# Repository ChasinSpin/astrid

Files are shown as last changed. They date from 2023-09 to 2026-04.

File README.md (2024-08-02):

# Astrid (ASTro Imaging Device)

## Introduction

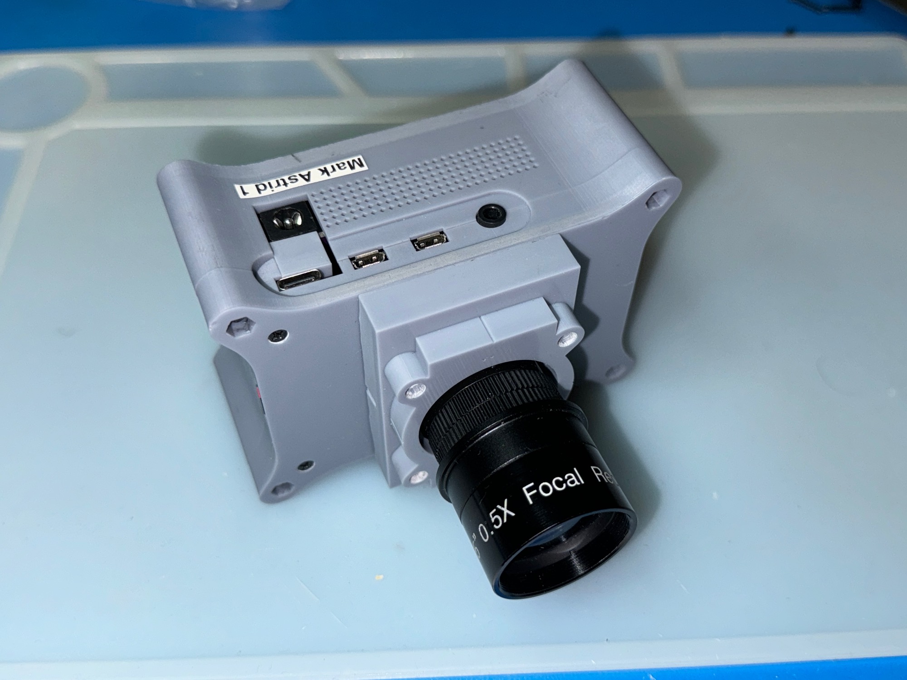
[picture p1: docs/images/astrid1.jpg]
Astrid Front View


Astrid is a device, software and hardware to record astronomical Occultations, Transits, Eclipses (OTE), and Astrophotography.  Occultations are rare, and having equipment for rare events means that the equipment is unused at other times.  The concept of Astrid is that the device can be used as a general astrophotography camera when occultation work is not being done.  

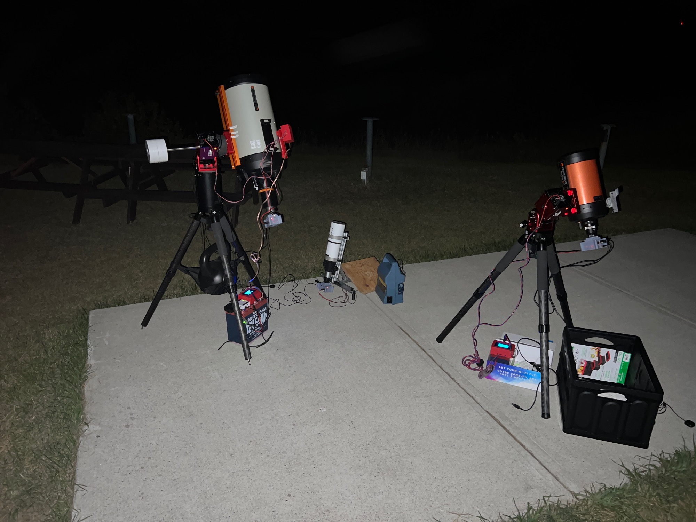
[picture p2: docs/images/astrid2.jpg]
Astrid Front View


Astrid compromises of:

* Raspberry Pi 4 Model B - 8GB (4GB untested)[](https://www.inno-maker.com/product/cam-mipi296raw-trigger/)
* IMX296 Mono Camera [CAM-MIPI296RAW-Trigger](https://www.inno-maker.com/product/cam-mipi296raw-trigger/)
* [OTEStamper](OTEStamper) Timing board
* Software and Firmware

Astrid has the following features:

* Highly accurate frame timestamping for occultations using GPS
* Global Shutter (Sony IMX296 Sensor Mono)
* Controlled over VNC from Tablet/Computer/Phone (one can control many Astrids)
* Can be paired with a telescope or camera lens
* Audit trail for video
* GPS Position/Altitude
* Plate Solving
* Mount support: [IndiLib](https://indilib.org)
* Focuser support: [IndiLib](https://indilib.org) - Coming Soon
* Goto
* Star Detection
* Stretch
* Uncompressed raw data/video
* .fits file (photos)
* [Raw Astro Video Format (RAVF)](https://github.com/ChasinSpin/ravf) files for video (occultations)
* [PyMovie Support](https://github.com/ChasinSpin/pymovie)
* Dithering
* Multiple Subs
* Occelmnt support
* Occultation metrics
* Unattended Pre-Pointing

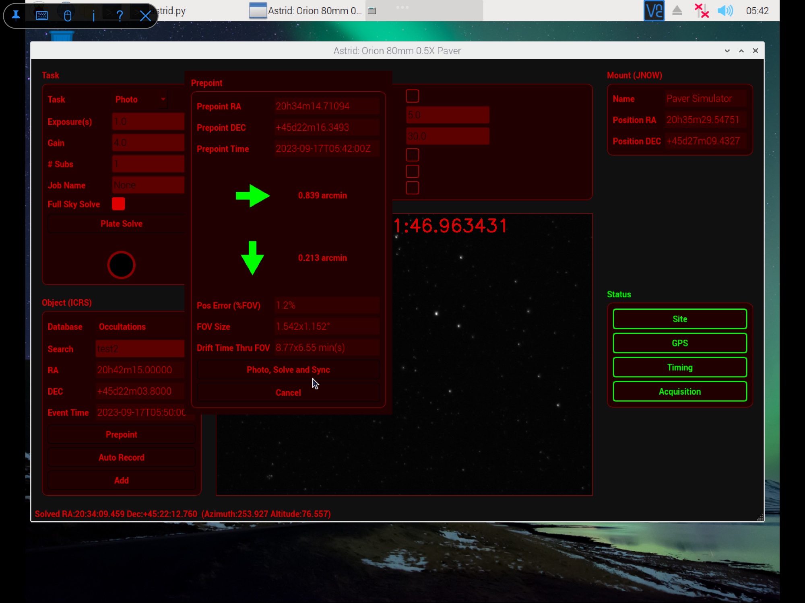
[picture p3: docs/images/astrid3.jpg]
Astrid Front View


## PyMovie

Astrid [Raw Astro Video Format (RAVF)](https://github.com/ChasinSpin/ravf) can be loaded in PyMovie for analysis, using [RAVF PyMovie](https://github.com/ChasinSpin/pymovie).

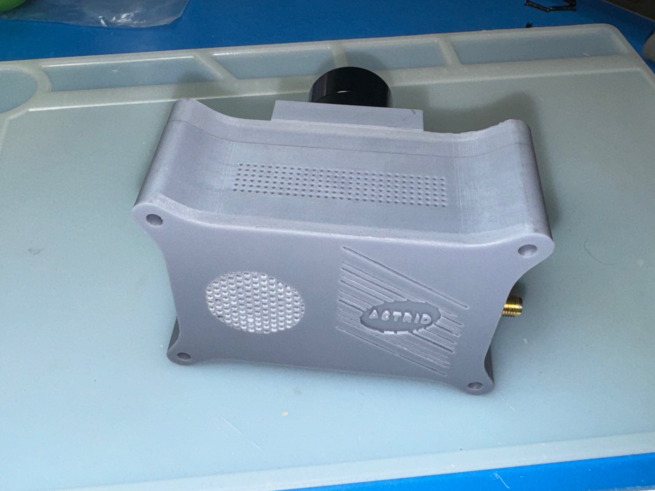
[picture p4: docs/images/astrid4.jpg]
Astrid Front View


## Documentation

[Documentation](docs/README.md)

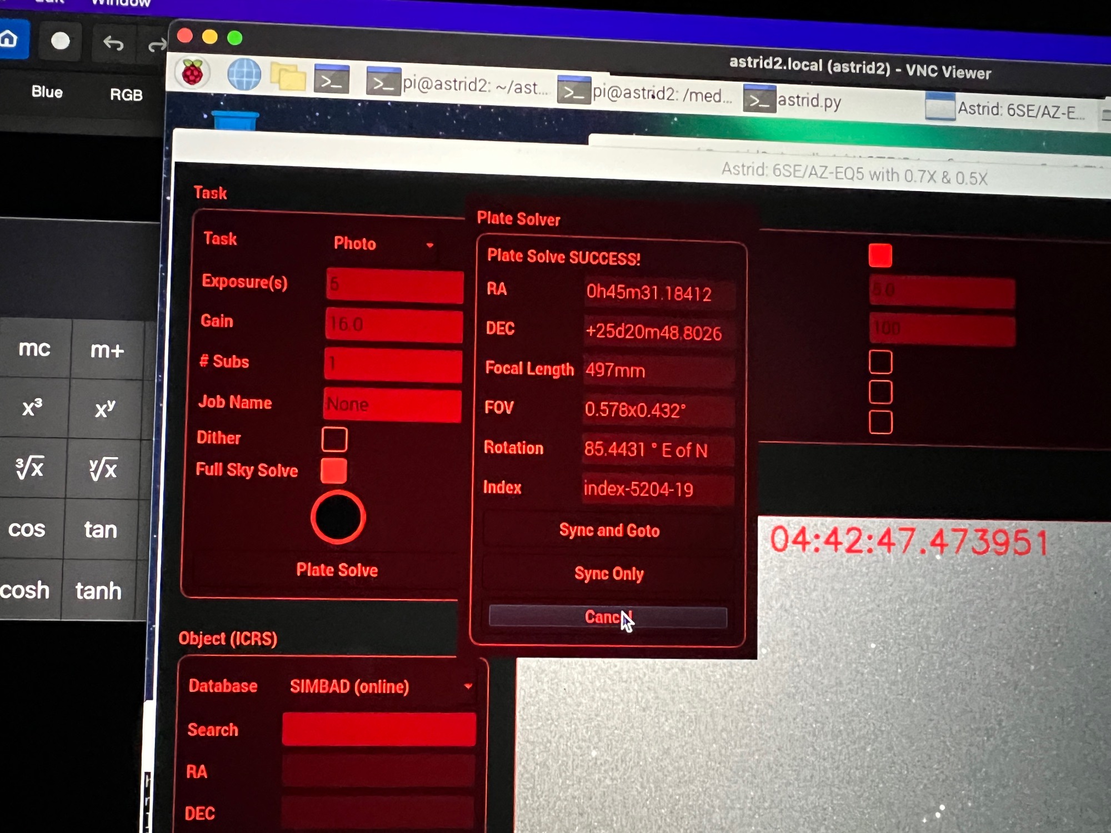
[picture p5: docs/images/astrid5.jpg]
Astrid Front View


## Obtaining Astrid

Astrid is now being supplied fully built and ready to go from IOTA.  Please see:
[https://occultations.org/astrid-details-and-ordering-page/
](https://occultations.org/astrid-details-and-ordering-page/)

Please note that although Open Source software is free, it is also generally considered good practice to support the time / resources that are donated by authors by purchasing through approved channels like IOTA where available.  That way the software/hardware can continue to be developed. Limited support is also available if one of the approved boards is purchased. 

If you build the board yourself, or it was obtained from another, we are unable to provide support. There has been instances of people making boards, selling them to others for profit and then expecting assistance for free.  We do not have the resources to support these types of ventures.

## Credits

* Steve Preston of IOTA for his invaluable assistance
* Bill Yeung for testing
* Bob Anderson for PyMovie
* Dave Herald - Star Catalogs and Occelmnt
* Hristo Pavlov for OWCloud

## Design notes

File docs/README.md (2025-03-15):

# Astrid Documentation

## Video Series

Often, it's easier just to see it being done. There maybe minor differences between the video and the latest version of Astrid however.

Please remember to Thumbs Up and Subscribe.

* [Introduction to Astrid](https://youtu.be/g-tgf88GhiY)
* [Adding Occultations to Astrid](https://www.youtube.com/watch?v=qj_bfFR_L3A)
* [3 Minute Prepoint with Astrid](https://www.youtube.com/watch?v=myGppMeeMI0)
* [Astrid Assembly Guide](https://www.youtube.com/watch?v=mhg2wGE4-7w)
* [Polar Alignment in Astrid](https://www.youtube.com/watch?v=wpIIMchew8s)
* [OTEStamper Pick and Place](https://www.youtube.com/watch?v=rZjZhLjhxiA)
* [Autofill IOTA North American Occultation Report Form](https://www.youtube.com/watch?v=3y9rYOpHG34)
* [Astrid Sync With OWCloud](https://www.youtube.com/watch?v=qNmyeQEwPEQ)
* [Exposure Analysis in Astrid](https://www.youtube.com/watch?v=ftPvObwbZk0)
* [Astrid Player](https://www.youtube.com/watch?v=zWZk-ul2I8g)
* [Events Search](https://www.youtube.com/watch?v=RSV0QjDoSMw)
* [Build SD Card, USB Drive, VNC and First Light](https://www.youtube.com/watch?v=FWFcrbeaBLk)
* [Astrid Customer Camera Sensor Assembly Preparation](https://www.youtube.com/watch?v=KGnb8kZ5_lM&t=92s)

Ted Blank has also created an excellent video demonstrating using Astrid to Prepoint and Record an Occultation:

* [Ted Blank - Using Astrid to Prepoint and Record An Occultation](https://www.youtube.com/watch?v=A8jkwf8NDow)

## Getting Started

1. [Usage Guide](UsageGuide.md)
2. [Power Supply](PowerSupply.md)
3. [Astrid Mini Display](MiniDisplay.md)
4. [Troubleshooting](Troubleshooting.md)
5. [Wi-Fi](Wi-Fi.md)
6. [FAQ](FAQ.md)
7. [USB Drive Requirements](USBDriveRequirements.md)
8. [USB Flash Drive Layout](FlashDriveLayout.md)
9. [Plate Solver](Platesolver.md)
10. [Mounts](Mounts.md)
11. [Focusers](Focusers.md)

## Other
* [Install From Astrid Image](InstallImage.md)
* [Camera Specifications](Camera.md)
* [Raspberry Pi Complete Installation Instructions](InstallComplete.md)
* [Configuration](Configuration.md)
* [OTEStamper Timing Board](OTEStamper.md)
* [Assembly Guide](AssemblyGuide.md)
* [Prime Focus Case](AstridPrimeFocus.md)
* [TODO](TODO.md)

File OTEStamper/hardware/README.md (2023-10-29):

## Version 0.9b
	
* Initial

## Version 0.9c

* No electrical changes.
* Moved label for D1 below diode and clarified orientation for the Buck Regulator to make it less likely to assemble wrong way round.

## Version 1.0.0
	
* Added HOT label around buck convertor and back protection FET
* Removed 4 pin flat flex to camera board
* Moved JP2 right to allow clearance of U2
* Moved buzzer to bottom of the board and rotated 45 to make room for 150uF capacitor
* Added 150uF capacitor to limit surge current to regulator
* Moved Fan header so header pins easily clear GPS
* Added JST 2 Pin Connector For Different 12V Source
* Changed Q1/Q2 to MMBT2222A-TP for increased fan current upto 500mA

## Version 1.0.0 (no board revision)

Extended monostable duration from 1.2us to 1ms to account for
different versions of the camera module with varying XVS pulse lengths, which
can cause multiple pulses for each XVS signal:

 * Changed R18 from 1K to 10K
 * Changes C12 from 1nF to 0.1uF

## Future Ideas

1. Maybe look at switching out back protection FET to one with lower RDS as the voltage drop across is large at high currents (buck can keep up fine).

## PSU Characterisation

1. Voltage range is 7.5 - 18V, specified range to the user is 12V-15V @ 4A

2. Voltage dropout occurs at 7.5V

3. Buck starts to current limit (switch the PSU on and off) at 4.1A

4. Max temperature ofr the bucks convert (4A @ 18V) is 130C

5. Damage to the buck convertor will occur at 20V

6. Fuse never gets triggered during normal use.  Would only get trigger if there was failure on the board itself.

| PSU Output | Supply Input | Temperature |
| --- | --- | --- |
| 0.2A @ 5.04V | 0.062A @ 18V | Room |
| 1A @ 5.02V | 0.304A @ 18V | 42C |
| 2A @ 4.97V | 0.604A @ 18V | 57C |
| 3A @ 4.89V | 0.920A @ 18V | 85C |
| 4A @ 4.79V | 1.243A @ 18V | 125C |

## Testing

1. Power at 12V at current limit 40mA, power usage should be approx 25-30mA, GPS LED should be on
2. Test voltage TP1 = Just above 5V
3. Test voltage TP2 = 5V
4. Test in Software with Raspberry Pi and Camera Connected:

	a) Install firmware
	
		make reset
		make writefuses
		make install

	b) Test Buzzer and Fan:
 	
		cd ~/astrid/OTEStamper/test
		./spitest.py
		
	c) Test GPS (and check voltage monitoring)
	
		./spitest_gps.py
	
	d) Record video and check all status buttons are green and video is recorded

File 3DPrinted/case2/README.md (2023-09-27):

# AstridCase
3D printed case for the Astrid project.

## Filament Color

Black filaments in particular often contain considerable carbon black which can interfere with Radio Frequency (RF) reception/transmission.  This may attenuate or even block Wifi, GPS, or Bluetooth.  Testing is advised when using filaments containing carbon black.

## Requirements

The following modules are required and are provided in this project.  The original projects can be found here:

* polyround.scad from [Round-Anything](https://github.com/Irev-Dev/Round-Anything) (MIT License)
* [Font: JuneGull - 1001freefonts.com](https://www.1001freefonts.com/junegull.font)
* [Font: Poetsen One - 1001freefonts.com](https://www.1001freefonts.com/poetsen-one.font)

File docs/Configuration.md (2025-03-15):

# Configuration

##### Note: It's strongly recommended to use the "Settings" button when Astrid is launched to change settings.  This remains for reference and documentation for the effect of each setting.

## Introduction

Config files are stored in /media/pi/ASTRID/configs and organized as follows:
	
	* /media/pi/ASTRID/configs/observer.json
	* /media/pi/ASTRID/configs/occultations.json
	* /media/pi/ASTRID/configs/objects.json
	* /media/pi/ASTRID/configs/configs.json
	* /media/pi/ASTRID/configs/config1/
		* camera.json
		* focus.json
		* mount.json
		* platesolver.json
		* site.json	[Optional] 
		* ...
	* /media/pi/ASTRID/configs/config2/
		* camera.json
		* mount.json
		* platesolver.json
		* site.json	[Optional] 
		* ...

File formats:

* [configs.json](#configs)
* [astrometry.cfg](#astrometry)
* [camera.json](#camera)
* [general.json](#general)
* [focus.json](#focus)
* [mount.json](#mount)
* [objects.json](#objects)
* [observer.json](#observer)
* [occultations.json](#occultations)
* [platesolver.json](#platesolver)
* [site.json](#site)
* [telescope.json](#telescope)

Note: You may find it easier to validate any JSON with an online validator in case of errors in entry.

## configs

This config.json file is used to present the selection of configs when Astrid is launched.

	{
    	"configs": [
        	{
            	"configFolder": "nexstar_6se_0.7X_eq5",
            	"summary": "6SE/AZ-EQ5 with 0.7X",
            	"mount": "Sky-Watcher AZ-EQ5",
            	"telescope": "Celestron NexStar 6SE",
            	"focalreducers": "Celestron 0.7X"
        	},
        	{
            	"configFolder": "edgehd_0.7X_0.5X_am5",
            	"summary": "EdgeHD/AM5 with 0.7X Celestron and 0.5X IOTA",
            	"mount": "ZWO AM5",
            	"telescope": "Celestron EdgeHD 9.25\"",
            	"focalreducers": "0.7X Celestron and IOTA 0.5X"
        	},
        	{
            	"configFolder": "simulator",
            	"summary": "Simulator",
            	"mount": "Simulator",
            	"telescope": "Simulator",
	            "focalreducers": "None"
        	}
    	],
    	"selectedIndex": 1
    }

| Variable | Description |
| --- | --- |
| configFolder | Sub folder of the configs folder.  This must match exactly the folder name the rest of the settings are stored wihin. |
| summary | Short unique summary describing the scope to the user to enable a config to be selected. |	
| mount |	Longer description of the mount. |
| telescope | 	Longer description of the telescope. |
| focalreducers | Longer description of the focal reducer(s). |
| selectedIndex | Index of the currently selected configuration. 0 based (first config entry is index 0, next is 1 etc.) |

## camera

The camera.json file stores configuration related to the camera:

	{
		"mode_selected": 1,
		"hflip": false,
		"vflip": false,
		"gain": 4.0,
		"accelerated_preview": false,
		"photo_format": "fit",
		"radec_format": "hmsdms",
		"polar_align_test": false,
		"polar_align_rotation": 90.0,
		"default_photo_exposure": 5.0,
		"prompt_dark_after_acquisition2": false,
		"dither_ra": 0.0010,
		"dither_dec": 0.0100,
		"photosFolder": "/media/pi/ASTRID/Photo",
		"videoFolder": "/media/pi/ASTRID/OTEVideo",
		"buzzer_enable": true
	}
	
| Variable | Description |
| --- | --- |
| mode_selected | Cameras have multiple modes with different attributes (size, binning etc.). Suggested modes: IMX296 Mono/Pi GSC: 1, Pi HQ: 3 |
| hflip | Set to true to horizontally flip the image, otherwise false. |
| vflip | Set to true to vertically flip the image, otherwise false. |
| gain | Gain should be optimized to the sensor for read noise as some cameras have dual gain circuits.  Suggested: IMX296 Mono/Pi GSC: 4.0, Pi HQ: 16.0 |
| accelerated_preview | Set to true to use the graphics chip to accelerate the preview image in Astrid, otherwise false. It is suggested to set to false to avoid issues with VNC viewers. |
| photo_format | Unused, must be set to "fit" |
| radec_format | This is the format for the way RA/DEC are presented visually to the user. "hmsdms" = Hours Minutes Seconds(RA) and Degrees Minutes Seconds (DEC). "hour" = 24 Hour RA and "deg" = 360 degree RA |
| polar\_align\_test | If set to "true", test files for the Polar Alignment routine are used from so that it can be tested during daylight hours. Ordinarily set to false unless testing.|
| polar\_align\_rotation | The number of degrees to rotate the scope during polar alignment.  This should be no more than 90.0 degrees and should not be less than 60.0 degrees. 90.0 degrees is the suggested value for accurate polar alignment. |
| default\_photo\_exposure | This is the default exposure in seconds provided in the exposure box in Astrid.  It suggested that this should be set to the exposure that is needed to get a consistant plate solve, e.g. 1.0 - 5.0 seconds. |
| prompt\_dark\_after\_acquisition2 | If set to true, a message box prompts the use to record 100 frames of dark video after an acquisition |
| dither_ra / dither_dec) | When the box is checked and "# Subs" is greater than 1, this value is used to randomly dither in RA/DEC to prevent walking noise when stacking.  The values are in degrees and represent the maximum the position can be dithered |
| photosFolder | Location to store fits files taken in Task = Photo Mode, set to "/media/pi/ASTRID/Photo" |
| videoFolder | Location to store RAVF files (video files) taken in Task = OTE Video "/media/pi/ASTRID/OTEVideo" |
| buzzer_enable | Buzzer beeps in the prior 6 seconds to auto record if true |

## general

The general.json file stores configuration related general settings:

	{
		"fan_mode": "on",
		"center_marker": "small cross",    
		"voltage_warning": 11.5,
    	"voltage_shutdown": 0.0,
    	"location_in_fits": true,
    	"fuzz_gps": false,
    	"annotation_mag": 14.0
	}
	
| Variable | Description |
| --- | --- |
| fan_mode | on = fan always on; idle = fan on when not recording; off = fan off. If you're experiencing vibration effects with long focal lengths, or you are imaging in extreme cold and want to retain heat, this setting can be used.  Note: Although the Raspberry Pi should reduce speed if it gets too hot, there's a slim possibility of damage.  If you live in a hot climate, or it's inside, you probably want the fan on all the time. It is suggested that if considering switching the fan off, then the Raspberry Pi should have the heat sinks installed. |
| center_marker | When "Center Marker" is checked the displayed marked can be one of: crosshairs; rectangle or "small cross" |
| voltage_warning | Specifies the voltage at which a popup warning is issued for Low Voltage. Set to 0 to disable. The warning (if enabled) only occurs once per session. |
| voltage_shutdown | Specifies the voltage at which a auto shutdown occurs for Low Voltage. Set to 0 to disable. Note: Astrid will still consume 250mA @ 12V and more at lower voltages when it is shutdown as the Raspberry Pi is still on, i.e. it will still drain your battery but not as fast, however it does protect the SD Card and USB Drive from damage due to low voltage. If shutdown is cancelled. The shutdown (if enabled) only occurs once per session, if it cancelled it won't auto shutdown again until the next session. |
| location\_in\_fits | When true, the latitude and longitude from the GPS (current site) are written to the fits file as tags SITELAT and SITELONG. |
| fuzz_gps | When true, a random amount of 5 degrees is added/subtracted from the GPS Latitude/Longitude and 500m from altitude.  This is used primarily for demo purposes to prevent personal information being leaked. On no account should this be enabled when real data for occultations is being acquired. |
| annotation_mag | When annotating magnitudes of stars on photos, and when analyzing for exposure, stars dimmer than this magnitude are excluded. |

## focus

The focus.json file stores configuration related to the electronic focuser:

	{
    	"indi_module": "indi_simulator_focuser",
    	"indi_focuser_device_id": "Focuser Simulator",
   	 	"indi_custom_properties": "ASI EAF.FOCUS_REVERSE_MOTION.INDI_ENABLED=On"
    	"coarse_step": 150,
    	"fine_step": 10,
    	"has_temperature": true,
	    "debug": false,
	}

| Variable | Description |
| --- | --- |
| indi_module | The IndiLib dirver executable needed for the mount. The required executable can be determined with [IndiLib Focusers](https://indilib.org/devices/focusers.html) under "Listing Details" and "Driver Executable". Most focusers have been added to Astrid, and the presence of a driver executable can be found by looking in /usr/bin.  e.g. "indi_asi_focuser". |
| indi\_focuser\_device\_id | This is the device is that shown when indi\_getprop is run.  For example for an indi_getprop output of: "ASI EAF.CONNECTION.CONNECT=Off", then this should be set to "ASI EAF" |
| indi\_custom\_properties | List of custom properties (semicolon separated) that are sent as indi_setprop commands after the driver is started, e.g. ASI EAF.FOCUS\_REVERSE\_MOTION.INDI\_ENABLED=On |
| coarse\_step | The number of steps when up/down are pressed when Coarse Speed is selected |
| fine\_step | The number of steps when up/down are pressed when Fine Speed is selected |
| has\_temperature | Set to true if the focuser has a temperature sensor, otherwise false |
| debug | If set to true, debugging information (commands sent to the mount, and information received from the mount) is output which can be useful when setting up new mounts. Ordinarily, this should be set to false. |

## mount

The mount.json file stores configuration related to the mount:

	{
		"name": "ZWO AM5",
		"indi_module": "indi_lx200am5",
		"indi_telescope_device_id": "ZWO AM5",
		"indi_custom_properties": "",
		"indi_usb_tty": "/dev/ttyACM0",
		"baud": 9600,
		"align_axis": "eq",
		"goto_capable": true,
		"tracking_capable": true,
		"mount_is_j2000": false,
		"set_site": true,
		"set_time": true,
		"local_offset": "0.00",
		"parkmethod": "home",
		"debug": false
	}
	
| Variable | Description |
| --- | --- |
| name | How the mount appears in the Mount Panel in Astrid under "Name".  Choose something short so that the name doesn't wrap in the panel. e.g. "ZWO AM5" |
| indi_module | The IndiLib dirver executable needed for the mount. The required executable can be determined with [IndiLib Telescopes](https://www.indilib.org/devices/telescopes.html) under "Listing Details" and "Driver Executable". Most mounts have been added to Astrid, and the presence of a driver executable can be found by looking in /usr/bin.  e.g. "indi_lx200am5". |
| indi\_telescope\_device\_id | This is the device is that shown when indi\_getprop is run.  For example for an indi_getprop output of: "ZWO AM5.CONNECTION.CONNECT=Off", then this should be set to "ZWO AM5" |
| indi\_custom\_properties | List of custom properties (semicolon separated) that are sent as indi_setprop commands after the driver is started, e.g. Skywatcher Alt-Az.USEJOYSTICK.ENABLE=On |
| indi\_connection\_method | "serial" or "ip address"; configures the connection method to the mount |
| baud | The baud rate the USB (serial port) communicates at.  Common values are 9600 and 115200. |
| ip\_addr | The ip address of the device |
| ip\_port | The port of the device |
| align\_axis | "eq" for Equatorially mounted telescopes and "altaz" for Alt-Azimuth mounted telescopes. |
| goto\_capable | true if the mount is capable of goto in 2 axis, or false if not. |
| tracking\_capable | true if the mount is capable of following a target with the earth's location|
| mount\_is\_j2000 | Set to true if this mount expects j2000 coordinates for syncs and gotos.  Ordinally most mounts are JNOW, and this should be set to false. |
| set\_time | Set to true to automatically set the time from the GPS.  It is not advised to disable this setting |
| set\_site | Set to true to automatically set the site from the GPS. It is not advised to disable this setting |
| local\_offset | This is the timezone offset between UTC and local time (negative numbers are West of Greenwich, London, UK).  It is recommended to set this value to "0.00" for most mounts and is just provided as a convenience if your mount is broken in its implementation and requires the offset to be specified too. The symptom of a broken mount would be if the RA on goto's was off by the number of hours for your local timezone. Ordinarily, Sidereal time is calculated based on your Longitude (Site information), not timezone offset. |
| parkmethod | "park" or "home". The method used to park the scope. Most mounts use the telescope property "TELESCOPE\_PARK" in IndiLib (which can be verified with indi\_getprop) and this setting should be set to "park". An exception would be something like the "ZWO AM5" which uses "GO_HOME" and this should be set to  "home". |
| debug | If set to true, debugging information (commands sent to the mount, and information received from the mount) is output which can be useful when setting up new mounts. Ordinarily, this should be set to false. |

## objects

The objects.json file stores custom objects (targets). These objects can also be used when not connected to the internet. It is strongly suggested that these are not manually entered in this json and are entered via Astrid's Object (ICRS) panel.  All RA/DECs are in 360 degree ICRS/J2000:

	{
    	"custom_objects": [
        	{
            	"name": "Vega",
            	"ra": 279.234734787,
            	"dec": 38.783688956
        	},
        	{
            	"name": "Arcturus",
            	"ra": 213.915300295,
            	"dec": 19.182409162
        	}
    	]
	}
	
| Variable | Description |
| --- | --- |
| name | The name of the object |
| ra | The 360 deg RA of the object|
| dec | The DEC of the object |

## observer

The observer.json file stores information about the observer, this information is used to provide observer information in the RAVF (video files):

	{
		"observer_name": "John Doe",
		"observer_id": "johndoe@example.com",
		"owcloud_login": "johndoe@example.com",
		"owcloud_password": "password",
		"owcloud_sitefilter": "",
		"station_number": 0,
		"create_na_report": true
	}
	
| Variable | Description |
| --- | --- |
| observer\_name | Set to the name of the observer (generally you). |
| observer\_id | Set to the observer id. This could be email address, a number etc. |
| owcloud\_login | Set to the owcloud login, usually email address |
| owcloud\_password | Set to the owcloud password |
| owcloud\_sitefilter | Applies a filter to all site names specified in OWCloud which starts at the beginning of the site name and is case sensitive.  I.E. \"Astrid 5\" will match the site name \"Astrid 5 - ChasinSpin\". Leave empty (no characters at all) if you wish to download all sites you've registered in OWCloud |
| station_number | Station number of the astrid, e.g. hostname: astrid1 would be station number 1.  Note the station number is stored on the USB Flash Drive, so will move around with the USB Flash Drive.  Range 1..10000 |
| create\_na\_report | If true, creates a filled in North American Occultation Report Form after the video has finished recording for occultations |  

## occultations

The occultations.json file stores occultations (targets). These objects can also be used when not connected to the internet. It is strongly suggested that these are not manually entered in this json and are entered via Astrid's Object (ICRS) panel.  All RA/DECs are in 360 degree ICRS/J2000.  Occelmnt data is also stored when provided:

	{
    	"occultations": [
        	{
            	"name": "Petrina",
            	"ra": 334.3794887916667,
            	"dec": 0.6233059000000001,
            	"event_time": "2023-08-16T08:42:24",
            	"occelmnt": {
                	"Occultations": {
                    	"Event": {
                        	"Elements": "JPL#81:2023-07-30@2023-08-16[OWC],3.90,2023,8,16,8.706836,-0.330947,0.439776,-5.300154,-3.988511,-0.000865,-0.001414,0.000001,0.000000",
                        	"Earth": "-120.4068,0.7422,50.50,13.77,False",
                        	"Star": "TYC 559-01642-1,22.29196592,0.6233059,11.73,11.47,11.05,0.0,0,,22.31233020,0.7421805,1.82,1.80,0,0,0",
                        	"Object": "482,Petrina,13.07,45.8,1.8647,0,0,-1.667,-18.81,,2.4,0",
                        	"Orbit": "0,53.9673,2023,8,16,87.9178,179.3705,14.4736,0.09643,2.99829,2.70917,8.97,5.0,0.15",
                        	"Errors": "1.152,0.0107,0.0003,82,0.0052,Known errors,0.85,0,-1,-1",
                        	"ID": "20230816_1642-1,60157.39"
                    	}
                	}
            	}
        	}
    	]
	}

| Variable | Description |
| --- | --- |
| name | Name of the event (this is the name that can be searched for in Astrid's Object (ICRS) panel. |
| ra | 360 degree RA of the target |
| dec | DEC of the target |
| event\_time | Event time.  This can be center time of the event, or the time the event will happen locally. |
| occelmnt | This is the occelmnt data for the event and is best entered via Astrid / Object (ICRS)/ Database: Occultations / Add to populate.  The Occelmnt data input via that method, can be cut and poasted from "OW Cloud", "Steve Prestons Predictions", or any other method that can output occelmnt data. |

## platesolver

The platesolver.json file stores configuration related to platesolving:

	{
		"focal_length": 732.0,
		"search_radius_deg": 5.0,
		"limit_objs": 1000,
		"downsample": 2,
		"source_extractor": true,
		"scale_low_factor": 0.1,
		"scale_high_factor": 1.25,
		"direction_indicator_polar_align": 2,
		"direction_indicator_platesolve": 1
	}
	
| Variable | Description |
| --- | --- |
| focal\_length | The focal length of the telescope with all the focal reducers and optics in millimeters (floating point number).  When first setting up a scope, this can be estimated provided the actual scope focal length falls between scale\_low\_factor x focal\_length and scale\_high\_factor x focal\_length. Once a platesolve has been achieved, the actual focal length will be reported and this value should be updated to match the platesolve focal length for faster solves. Plate solves outside this focal length range will never solve.|
| search\_radius\_deg | The search radius in degrees for plate solves from the position the scope thinks it is currently at, or the RA/DEC stored in a fits file loaded. This setting is only used when "Full Sky Solve" is not checked.  This allows for faster solves when the scope knows it's position.  A suggested value is 5.0 |
| limit\_objs | The --objs number provided to [solve-field](https://manpages.debian.org/testing/astrometry.net/solve-field.1.en.html) and cuts the source list down to at least this many source. Suggested value is 1000. |
| downsample | Images can be downsampled by a factor to speed up platesolving and increase signal to noise. See [Downsample](https://manpages.debian.org/testing/astrometry.net/solve-field.1.en.html). No downsampling: 1, 2X downsampling: 2. Suggested value is 2 |
| source\_extractor | If set to true, it uses Source Extractor rather than image2xy to detect stars. Set to false otherwise. Source Extractor is slower, but seems to perform better. See [Extractor](https://manpages.debian.org/testing/astrometry.net/solve-field.1.en.html).  Suggested value is true. |
| scale\_low\_factor | This value multiplied by the focal length is the lowest focal length to consider when platesolving.  Suggested value is 0.1 |
| scale\_high\_factor | This value multiplied by the focal length is the highest focal length to consider when platesolving.  Suggested value is 1.25 |
| direction\_indicator\_polar\_align | During polar alignment, arrows can be displayed to indicate the direction to adjust the mount. "None", "1 Arrow", "2 Arrows" |
| direction\_indicator\_platesolve | When the "Plate Solve" button is hit, and an Object is selected, arrows can be displayed to indicate the direction to adjust the pointing of the scope to reach the target.  This is particularly useful when using a scope without goto. "None", "1 Arrow", "2 Arrows" |

## site

The site.json file stores information related to the current site. This file is optional, and is updated when the "Site" and "Update Site and Mount" buttons are pressed.  If this JSON file does not exist, Astrid will default it to a 0.0, 0.0 location and the "Site" button will be Red until the user selects "Update Site and Mount".  This file can be safely deleted for privacy when backing up or transferring config files:

	{
    	"name": "Local",
    	"latitude": 58.3489123,
    	"longitude": -82.3829384,
    	"altitude": 1102.1
	}
	
| Variable | Description |
| --- | --- |
| name | The name of the site.  This is for future use and currently should be set to "Local". |
| latitude | Latitude of the site. |
| longitude | Longitude of the site. (negative numbers are west of Greenwich, London, UK).|
| altitude | Altitude of the site in meters (floating point number). |

## telescope

The telescope.json file stores information related to the telescope and is used to provide information for the North American Occultation Report Form:

	{
    	"aperture": 0,
    	"optical_type": "Refractor"
	}
	
| Variable | Description |
| --- | --- |
| aperture | The aperture of the telescope in millimeters. Range 0..10000 |
| optical_type | The optical type of the telescope. "SCT including Cass and Mak", "Newtonian", "Refractor" or "Dobsonian" |

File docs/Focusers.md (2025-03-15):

# Focusers (Electronic)

* [Introduction](#introduction)
* [Focusers and Connections Supported](#focusers-and-connections-supported)
* [Support](#support)
* [Focuser Settings](#focsuer-settings)
* [Focuser Testing And Verification](#focuser-testing-and-verification)

## Introduction

Connecting your Focuser to Astrid may take some effort, especially if no one has set up the same or similar focuser before. Many different focuser manufacturers and focuser models exist, and they lack consistency in operation, features, and requirements between them.

Astrid also does not require a Focuser and works perfectly fine with a manual Focuser. Astrid defaults to a simulated focuser unless you change it.

## Focuser and Connections Supported

Astrid includes [IndiLib](indilib.org) for focuser support, and any focuser that is supported by [IndiLib](indilib.org) will also likely work with Astrid when configured correctly. The focsuer must support a USB connection to work with Astrid.  Wifi/Bluetooth connections to focusers are not supported with Astrid.

Check the list below and use it as a starting point for focuser configuration.  The list contains focusers that have been tested by others and are known to work.  

**If you've got your focuser working and it's not listed below, please send the settings/configuration that you found to work so it can be added to the list and others can benefit.**

You should make sure that your focuser firmware is updated to the latest version.  Before configuring any new focuser, it is advisable to ascertain the exact make and model of the focuser and find out specific information about cables or configuration details you may need from [IndiLib - Telescopes](https://indilib.org/devices/focusers.html). Clicking on on the image for the mount will take you to a page with further details.  Information you will need, for example, are the Driver Executable, Connectivity, and Issues.

The focuser functionality can be tested during daylight.

## Support

Limited support is available over Zoom if you have purchased an Astrid through approved channels, such as IOTA (North America), IOTA/ES, or directly from the Author.

Any requests for support need to have the exact make, model of the focuser and a link to the operation manual.

Prior to requesting support, please ensure:

1. You have checked the list below for your focuser, the documentation here, and tried setting it up
2. On your desktop computer you have:
	
	* Zoom Installed
	* RealVNC installed and talking to Astrid
	* Mount connected to Astrid with the correct cable and powered on
3. It's then possible to setup a zoom session with screen sharing to assist you.

## Focuser Settings

Settings for focusers can be accessed via Astrid's settings "Focus" panel.  

| Focuser/Model | Tested | Indi Module | Indi Telescope Id | Indi Custom Properties | Cable | Notes |
| --- | --- | --- | --- | --- | ----- | ----- |
| Simulated Focuser | Yes | indi\_simulator\_focuser | <code>Focuser Simulator</code> | | <code>This is a simulated focuser and the default.</code> |
| ZWO EAF | Yes | indi\_asi\_focuser | <code>ASI EAF</code> | <code>ASI EAF.FOCUS\_REVERSE\_MOTION.INDI\_DISABLED=On or ASI EAF.FOCUS\_REVERSE\_MOTION.INDI\_ENABLED=On</code>

*Author only: OPTION-SPACE for non-breaking space above*

### Reversing The Direction Of the Focuser

Try adding the following in "Indi Custom Properties":

> ASI EAF.FOCUS\_REVERSE\_MOTION.INDI\_DISABLED=On

OR

> ASI EAF.FOCUS\_REVERSE\_MOTION.INDI\_DISABLED=Off

Where ASI EAF is the Indi Focuser Device Id.

## Focuser Testing and Verification

Focusers that haven't been encountered before with Astrid (i.e., there are no settings listed above) need to be verified to work on Astrid.  This process details how to do that:

* Indi Module must be set to the correct module.  A list of modules can be determined from the command line by <code>ls /usr/bin/indi*</code>  Also use [IndiLib - Telescopes](https://indilib.org/devices/focusers.html) to determine the correct module for your focuser.  Save settings, quit astrid and restart Astrid
* Type <code>indi\_getprop</code> in the command line to determine the value for <code>DRIVER\_INFO.DRIVER_NAME</code> and enter that into "Indi Focuser Device Id" and restart Astrid. Note if you see "connect: Connection refused", then you didn't start Astrid and didn't click on "Start Astrid"
* If you have connection issues, use indi\_getprop to check that CONNECTION.CONNECT is On and indi\_setprop to set it, you may need to change some of the settings to get a connection.
* Does Set Position work?
* Does Set Current Position Work?
* Do the Up/Down arrows work
* Does Stop Movement Work

**If you've got your focuser working and it's not listed below, please send the settings/configuration that you found to work so it can be added to the list and others can benefit.**

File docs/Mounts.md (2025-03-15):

# Mounts

* [Introduction](#introduction)
* [Mounts and Connections Supported](#mounts-and-connections-supported)
* [Support](#support)
* [Mount Settings](#mount-settings)
* [Mount Testing And Verification](#mount-testing-and-verification)

## Introduction

Connecting your Goto Mount to Astrid may take some effort, especially if no one has set up the same or similar mount before. Many different mount manufacturers and mount models exist, and they lack consistency in operation, features, and requirements between them.

Astrid also does not require a Goto Mount and works perfectly fine with a manual mount that does not have Goto, or even with a Goto Mount where you have other means to move the mount (e.g. handset, manual slewing).  If you have a mount that isn't listed below or are just starting with Astrid, it may be best to get familiar with Astrid slewing your mount manually prior to setting up Goto.

Manual mounts in Astrid use a simulated mount to maintain the internal pointing model for Astrid.  Astrid installed example simulated mounts when it was built and a few other common mounts.

## Mounts and Connections Supported

Astrid includes [IndiLib](indilib.org) for mount support, and any mount that is supported by [IndiLib](indilib.org) will also likely work with Astrid when configured correctly. The mount must support a Serial connection over USB to work with Astrid.  Wifi/Bluetooth connections to mounts are not supported with Astrid due to the Wifi already being used for Astrid's Hotspot and connection to your Home network and then the general unreliability of connections to mounts over Wifi and Bluetooth.

Often, there are multiple methods for connecting to a mount from USB to serial, and which is the best depends on your mount.  Generally, a direct serial connection is simpler and often doesn't require star alignment on a handset prior to use (as Astrid can tell the mount where it is in the sky).  A mount that has a handset (e.g. Synscan) often has the ability for a direct-to-mount connection (Synscan removed), and also a connection via a handset (pass-thru) and also a connection via a handset (synscan protocol).

Often, you may need to purchase a cable for the serial connection. Information on which cable you need can often be found from the manufacturer (maybe in your mount manual), [Cloudy Nights](https://www.cloudynights.com) or the [IndiLib Forum](https://indilib.org/forum.html) typically.

Check the list below and use it as a starting point for mount configuration.  The list contains mounts that have been tested by others and are known to work.  

**If you've got your mount working and it's not listed below, please send the settings/configuration that you found to work so it can be added to the list and others can benefit.**

If you have a common commercial mount, it's more likely to be supported than a unique or rare large observatory mount or a boutique expensive mount that few others have.  However, occasionally, you can be lucky and have unique mounts that support, say, the LX200 protocol or EQMOD/EQDIR and are likely to work.

Most commercial mounts work in JNOW coordinates, and Astrid should be configured as such. Occasionally, though, a mount may be J2000.

Alt-Az mounts, in particular, contain an internal pointing model that must be set up on mount startup. Often, handsets have a 1, 2, or 3-star alignment process to do this and require the time, date, and location to be entered before they will talk over serial. If you can connect directly to the mount without the handset, you can often skip this lengthy process, and Astrid will set up the mount alignment for you.

You should make sure that your mount (and handset's) firmware is updated to the latest version.  Before configuring any new mount, it is advisable to ascertain the exact make and model of the mount and find out specific information about cables or configuration details you may need from [IndiLib - Telescopes](https://indilib.org/devices/mounts.html). Clicking on on the image for the mount will take you to a page with further details.  Information you will need, for example, are the Driver Executable, Connectivity, and Issues.

Some mounts (and handsets) will look like they are working when they are powered over USB. Always make sure the main power is connected to the mount.

Most mounts should have their Time and Site set and Set Time and Set Site should be checked, however some mounts may not work well in some instances, in which case you can disable and set manually. If you disable this setting, it's critical that you set the site and time manually for your location for Astrid to work correctly.  ONLY DISABLE IF YOU ARE SURE WHAT YOU ARE DOING.

Most of the mount functionality can be tested during daylight if you line up the mount with North and treat alignment stars as they would be in their correct locations for the time of day.  A final test can then be left till a clear night.

## Support

Limited support is available over Zoom if you have purchased an Astrid through approved channels, such as IOTA (North America), IOTA/ES, or directly from the Author.

Any requests for support need to have the exact make, model and configuration (Alt/Az or Eq) of the mount and a link to the operation manual.

Prior to requesting support, please ensure:

1. You have checked the list below for your mount, the documentation here, and tried setting it up
2. On your desktop computer you have:
	
	* Zoom Installed
	* RealVNC installed and talking to Astrid
	* Mount connected to Astrid with the correct cable and powered on
3. 

	It's then possible to setup a zoom session with screen sharing to assist you.

## Mount Settings

Settings for mounts can be accessed via Astrid's settings "Mount" panel.  Display Name can be anything, but please keep it short so it fits on the display.  Local Timezone Offset should always be 0.00.

| Mount/Model | Tested | Indi Module | Indi Telescope Id | Indi Custom Properties | Indi USB tty | Baud Rate | Mount Alignment Type | Goto Capability | Tracking Capability | Mount is J2000 | Parking Method | Cable | Notes |
| --- | --- | --- | --- | --- | --- | --- | --- | --- | --- | --- | --- | ----- | ----- |
Fixed Manual Mounts or Incompatible Goto Mounts (uses Astrid Prepoint) | Yes | indi\_simulator\_telescope | <code>Telescope Simulator</code> | | /dev/ttyUSB0 | 9600 | altaz | unchecked | unchecked | unchecked | park | None | <code>This is a simulated mount and the default for prepoint, manual mounts, scopes without Goto or Goto mounts where communication isn't supported.</code> |
| Celestron Nexstar 6SE/8SE | Yes | indi\_celestron\_aux | <code>Celestron AUX</code> | <code>Celestron AUX.PORT_TYPE.PORT\_HC\_USB=On;Celestron AUX.CORDWRAP.INDI\_ENABLED=On</code> | /dev/ttyUSB0 | 19200 | altaz | checked | checked | unchecked | park | | <code>IMPORTANT: Power to the mount must be on.  The handset will show text even when not powered as it can get power via the USB, but the mount won't connect. LCD will have red backlight when power to the mount is on.  Mount must be powered on horizontal pointing North. Occasionally when started, mount may need "Try Again" on startup. Nexstar tracking is terrible, it's suggested to use the SE6/SE8 for prepoint goto.  Do not do any star alignment prior to (or after) connecting the mount, it's not required as this bypasses the regular mount firmware.</code> |
| EQMod Mounts (Other) | No | indi\_eqmod\_telescope | <code>EQMod Mount</code> | | /dev/ttyUSB0 | 115200 | eq | checked | checked | unchecked | park | USB Cable | <code>Unplug Synscan</code> |
| Losmandy Gemini 2 | Yes | indi\_lx200gemini | <code>Losmady Gemini</code> | | /dev/ttyACM0 | 9600 | eq | checked | checked | unchecked | park | | Regular A/B USB  <code>See Steve Preston</code> |
| LX200 Classic | Yes | indi\_lx200classic | <code>LX200 Classic</code> | | /dev/ttyUSB0 | 9600 | altaz (should work in eq too) | checked | checked | unchecked | park | [Clearline](https://www.clearline-tech.com/repair-parts/lx200/lx200-usb-adapter.html) | <code>Tracking is permanently on with this mount.</code> |
| OnstepX | Yes | indi\_lx200\_OnStep | <code>LX200 OnStep</code> | | /dev/ttyACM0 | 9600 | eq | checked | checked | unchecked | park | USB Cable | <code>MaxPCB4 Tested, should work with others</code> |
| Skywatcher AZ EQ5, Skywatcher AZ EQM-35 Pro| Yes | indi\_eqmod\_telescope | <code>EQMod Mount</code> | | /dev/ttyUSB0 | 115200 | eq | checked | checked | unchecked | park | USB Cable | <code>Unplug Synscan</code> |
| Skywatcher AZ (example: Skywatcher Virtuoso GTI 150p (tested), FlexTube 200P(tested), FlexTube 300P(tested), FlexTube 350p, FlexTube 400P) | Yes | indi\_skywatcherAltAzMount | <code>Skywatcher Alt–Az</code> | Skywatcher Alt-Az.USEJOYSTICK.ENABLE=On | /dev/ttyUSB0 | 9600 | altaz | checked | checked | unchecked | park | <code>[RJ12 Control Cable for Skywatcher Az-GTI and AZ-GTE](https://www.amazon.com/gp/product/B08DG7KKNV) / [Sky-Watcher/SynScan USB Adapter for Computer Telescope Control](https://www.amazon.com/Sky-Watcher-S30107-SynScan-USB-Adapter/dp/B09PQR5BHY) - see next column</code> | <code>Power mount on with tube horizontal and pointing north (the park position).  Use EqMod Cable. The EqMod cable must be plugged into the same place the handset plugs into (i.e. instead of the handset) on the mount.  On startup, Astrid will likely say "Failed to connect to mount", just click "Try Again" (this is due to a bug Skywatcher have in their firmware where it won't connect on the first try). These mounts are notoriously inaccurate with the smaller mounts being worse than the larger one, it's recommended to turn the "Tracking" checkbox off in the Mount settings in Astrid, you can still use Goto and Prepoint, but tracking won't be enabled when auto recording starts, preventing the mount from hunting for the first 30 seconds of the recording, or being pushed out of frame.  You may still need to manually enable Tracking (Tracking button in Astrid), to get a plate solve.  Ted says that the RJ12 connection suggested didn't work for him (points to wrong location and doesn't stop slewing) and to use Sky-Watcher SynScan USB Adadpter instead, however Bill and Mark find the Washington RJ12 to work fine, if you have problems, with one, try the other.</code> |
| Vixen Starbook Ten | Yes | indi\_starbook\_ten | <code>Starbook Ten</code> | | /dev/null | 9600 | eq | checked | checked | unchecked | park | ethernet | <code>Connect to ethernet port on Pi. Point Dec West at startup (home position), accept warning about sun, then connect Astrid. Note Park on Starbook Ten often means RA is rotated, it is okay to start a polar alignment from this position.</code> |
| ZWO AM5 (likely AM3/AM5N too) | Yes | indi\_lx200am5 | <code>ZWO AM5</code> | | /dev/tty/ACM0 | 9600 | eq | checked | checked | unchecked | home | Regular A/B USB | |

*Author only: OPTION-SPACE for non-breaking space above*

### Mount SLEW Joystick Not Working In Astrid

Try adding the following in "Indi Custom Properties":

> Skywatcher Alt-Az.USEJOYSTICK.ENABLE=On

## Mount Testing and Verification

Mounts that haven't been encountered before with Astrid (i.e., there are no settings listed above) need to be verified to work on Astrid.  This process details how to do that:

* Indi Module must be set to the correct module.  A list of modules can be determined from the command line by <code>ls /usr/bin/indi*</code>  Also use [IndiLib - Telescopes](https://indilib.org/devices/mounts.html) to determine the correct module for your mount.  Save settings, quit astrid and restart Astrid
* Type <code>indi\_getprop</code> in the command line to determine the value for <code>DRIVER\_INFO.DRIVER_NAME</code> and enter that into "Indi Telescope Id" and restart Astrid. Note if you see "connect: Connection refused", then you didn't start Astrid and didn't click on "Start Astrid"
* If you have connection issues, use indi\_getprop to check that CONNECTION.CONNECT is On and indi\_setprop to set it, you may need to change some of the settings to get a connection.
* Check UTC is set correctly on the mount (using indi\_getprop) to the time you started Astrid (note it generally doesn't update whilst it's running)
* Check Latitude and Longitude for the site are correct (using indi\_getprop) after Update Site has been clicked in Astrid
* Does Goto work?
* Does Home/Park work?
* Does Tracking stop and start when the Tracking button is toggled?
* Does Tracking come back on automatically after a Goto?
* Does the mount update it's position correctly after a Sync is done after a plate solve?
* Does the STOP button (in the mount panel), stop the mount motion during Park/Homing and a Goto?
* Does the Tracking Rate (sidereal, lunar etc.) remain after Gotos?
* Do the Slew Joystick buttons and slew rate work?
* Does Meridian Flip work? (find star close to meridian (South), goto, wait for Meridian timing to drop to -1m, goto again and check mount flips.
* Does the Polar Align routine work (test this at night and german equatorial mounts only).

**If you've got your mount working and it's not listed below, please send the settings/configuration that you found to work so it can be added to the list and others can benefit.**

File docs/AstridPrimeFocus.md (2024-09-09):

# Astrid - Prime Focus

## Introduction

The Astrid - Prime Focus case is a version of Astrid that separates the camera from the processing unit to reduce the footprint for prime focus setups.  A prime focus setup is where the camera is located at the front of the telescope instead of the rear.  i.e. HyperStar SCTs, Suitcase Mounts (Broughton), Rasa, Prime Focus Newtonians, etc.  It can also be used for smaller Dobsonians, which are typically intolerant of extra wait at the eyepiece.

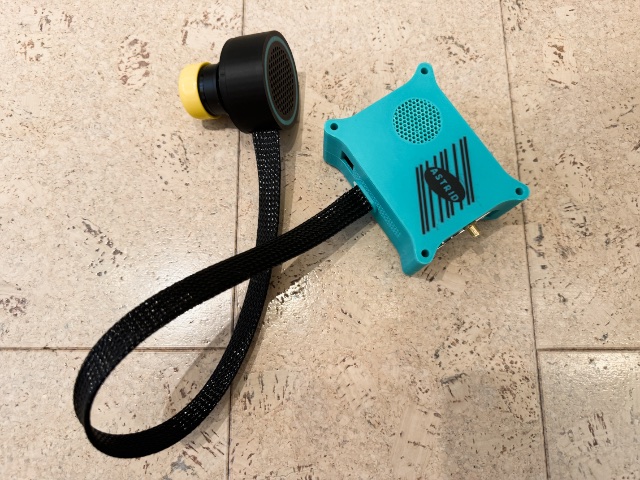
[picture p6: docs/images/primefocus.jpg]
Prime Focus Astrid Case


Astrid—Refractor (the all-in-one unit) is still the recommended solution for SCTs that are not Hyperstars, Newtonians that still have their eyepiece holders and Refractors.

Astrid - Prime Focus Case consists of 2 parts joined by a cable:

* Camera
* Astrid

The cable between these 2 parts is 19 inches +/—1 inch. As the camera will be mounted in the middle, it can accommodate scopes up to 30 inches in diameter.  If you have a larger telescope than this, please contact us for a longer custom cable.

This camera case is 3D printed in black (with a turquoise highlight on the nonvisible side), has no lights, and has the Flat Flex cable and a single thin wire coming out of the vertical slot. If you have a spider vane, the cables can be taped to that, with or without the wire sleeve.

The remainder of Astrid is a separate unit you can place somewhere outside of the mirror capture area e.g. on the side of the scope. Adhesive Velcro is the suggested way to do this.

This approach has a few advantages:

* The obstruction of this camera is only 59mm (the diameter of the case):
	* This is smaller than ZWO’s smallest cameras for example (62mm).
	* For HyperStar, this means that for 8” scopes and up, it’s smaller than the secondary mirror obstruction and, therefore, doesn’t block light, and for 6” (56mm obstruction) scopes, it only overspills by 3mm.
	* For RASA, the central obstruction is 93mm and far larger than the Astrid camera
* Maximizes photons coming in by not creating a big obstruction
* Only 2 thin cables to route (flat flex (1mm x 16mm) and a 1mm single wire), i.e. no large thick power cables
* Heat generation in front of the mirror is limited to the small heat generation of the camera
* No fans to disturb airflow in front of the mirror
* No LEDs to worry about
* These cables can be routed over your existing support structure (for Hyperstar / Rasa it can be anchored at the side using a radius curve)
* This approach won’t create any noticeable diffraction spikes if a radius curve is maintained (if your support structure or other items generate spikes, those will remain the same of course)

If you’re rough with equipment, the cable assembly is considered a consumable, and you can replace it easily.  **DO NOT FOLD THE FLAT FLEX**

## BOM (Bill Of Materials)

*(For IOTA Construction or User Repair Only)*

| Quantity | Part | Description | Manufacturer | Supplier | Supplier Part # |
| --- | ---- | --- | --- | --- | --- |
|1|Raspberry Pi Camera Cable 610mm|Adafruit 15-pin 610mm 1731|Adafruit|DigiKey|1528-1791-ND|
|2|Crimp|0.1" Connector 28awg Crimp Gold|Harwin Inc.|DigiKey|M20-1160042|
|51cm|PET Expandable Sleeving 5/8"|Expandable Sleeving 5/8" X 100' Black PTN0.63BK100|Techflex|DigiKey|1030-PTN0.63BK100-ND|
|70cm|Silicone Wire|28awg Silicone Wire multistranded|Anjukee Store|Amazon|[Amazon Link](https://www.amazon.com/dp/B0D6V75XDW)|
|18mm|Heatshrink Tubing|Heatshrink Tubing 3:1 shrinkage, 3mm internal diameter|Any|Digikey|2786-B2(3X)3/1BLACKSPL-DS-ND (untested, but should fit)|

## Assembly Instructions

*(For IOTA Construction or User Repair Only)*

* Cut 51cm long piece of PET Expandable Sleeving
* Cut 70cm long piece of silicone wire
* Weld ends with clamps, allowing about 1cm overflow of the sleeving at each end
* After construction, clamp to clamp should measure approximately 48cm.
* Insert cables, ensure camera end had 6.5cm of Flat Flex past the clamp and 10cm of the silicone wire.

See [YouTube Video](https://youtu.be/KbivtE_ajuM)

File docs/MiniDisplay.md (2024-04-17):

# Astrid Mini Display

## Introduction

The Astrid Mini Display is a small device with a display that displays Astrid's current network settings.

It connects over USB (USB2 or USB3), and its buttons can be used to switch between Hotspot and WiFi router mode.

In the future, it will be used to provide additional functionality.

Only 1 Astrid Mini Display is required for all your Astrids, it doesn't have to be connected for Astrid to start, and can be removed and plugged into another Astrid whilst both are running.

## Requirements

USB-B to USB-C cable with both power **AND DATA** is required.

Astrid Mini Display can use either:
	
* [Adafruit ESP32-S2 Reverse TFT Feather](https://www.adafruit.com/product/5345)
* [Adafruit ESP32-S3 Reverse TFT Feather](https://www.adafruit.com/product/5691)

## Initial Installation / Upgrading

Plug in the Astrid Mini Display to Astrid, and in "Astrid Tools", double click/tap on "Install Mini Display" and follow the instructions.

## Usage

The Mini Display contains 4 buttons: 3 user buttons and 1 reset button (which resets the Mini Display only).

Currently, to switch between Astrid Hotspot and Regular Wifi modes, you press anyone of the group of 3 buttons.  The press has to be deliberate, a fast tap will be ignored to avoid accidental triggering.

When switching modes, you should press the button and wait; soon, a gray message will be displayed indicating that it is switching; please wait as it switches.  Switching networks is quite involved and takes time; be patient; Astrid will update you as it makes connections to the network. First, it will connect to the Wi-Fi network, and then it will be allocated an IP address. You can connect after you see the IP address allocated, if you try to make a connection with VNC before that, the connection will fail.  If the Wifi is not connected to or an IP address is not allocated then there is a problem with the WiFi router you are using that you should investigate.

If you fail to connect to your WiFi network (for example, wrong password), then you can always press the button again to return to Astrid Hotspot mode to fix it.

## Troubleshooting

Q. Display lights, but you can't install the software

A. Be sure that the USB cable you are using provides both power AND DATA (try another cable)

## Bitmap (Developer only)

* Export to png and open in Photoshop
* Resize to 240x135
* Image / Mode / Indexed Color
	* Palette: Local (Selective)
	* Colors: 256
	* Forced: None
* File / Save As Copy / BMP
	* Windows
	* 8 bit
	* (nothing checked)

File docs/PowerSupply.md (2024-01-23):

# Power Supply

Astrid with the OTEStamper board should be powered via the 12-15 Volt 2.1x5.5mm DC Input Jack on the OTEStamper board, which is common on astronomy equipment. This input jack is "center positive" and has a self-resettable 2A polyfuse.  Power to the input jack is reverse polarity protected. 

Supply voltages outside of this range will likely damage the board and the Raspberry Pi and may corrupt the SD Card.  We recommend against using 12V Cigarette lighter-type connectors, as they often disconnect easily and can lead to SD Card corruption when that happens.

5.1-5.2VDC is generated internally by the OTEStamper board for the Raspberry Pi to run.  Please make sure that any wiring and the connector you use to supply Astrid can handle at least 2A. For reasonable run length, this means 16AWG or thicker for the wire, and likely 14AWG if you're supplying a larger mount too.  18AWG is really the least that should be considered and only for short runs and for only powering Astrid.

# Power Banks / Power Packs

__Power Banks / Power Packs are NOT Batteries__

__IMPORTANT:__ It's strongly suggested to avoid Power Banks or Power Packs for powering Astrid.  Power Banks / Power Packs (e.g. TalentCell) are most often made from cheap batteries with substandard electronics that are incapable of supplying regulated power to Astrid. This also applies to powering Astronomy Equipment in general (Mini PCs, Astro Cameras, Mounts, etc.).

Common problems with Power Banks/Power Packs are:

* Misrepresented Battery Capacity (specified at 3.7V not 12V)
* Power outputs auto switch off with low power drain, removing power from Astrid
* Low and/or varying voltage due to current limiting, poor boost conversion
* Fire risk/explosion risk
* Insufficient size

__Any Power Bank/Power Pack that contains Lithium Ion or Lithium Polymer batteries can also cause fires and can explode.  Lithium fires often can't be put out with water or chemical fire extinguishers.__

Examples:

* [https://www.youtube.com/watch?v=8nz5ijXcckI
](https://www.youtube.com/watch?v=8nz5ijXcckI)
* [https://m.youtube.com/watch?v=jq_0X1lStbo](https://m.youtube.com/watch?v=2hGfCwPwCPQ)
* [https://m.youtube.com/watch?v=2hGfCwPwCPQ](https://m.youtube.com/watch?v=2hGfCwPwCPQ)

There is no support/assistance available for Astrid setups using Power Banks / Power Banks if the problem is suggestive of being related to power issues.

Also, any larger power bank/power packs that have a 120V inverter are often square wave and not the correct sine wave output.  This can permanently damage any device plugged into it (such as a laptop power supply, or 12V DC power adapter).

Using LiFePO4 (Lithium Phosphate) 12V batteries instead is safer, significantly cheaper, and works (see below).

_There is one exception to this recommendation, and that is the Celestron Lithium and Lithium Pro LiFePO4 power banks(only), which are designed for astronomy applications.  However, as of now, only the Lithium Pro has been tested with Astrid and they are significantly more expensive than an equivalent battery._

# Household Power

Astrid can be powered at home with a 4A or greater 12V DC regulated center positive good quality power supply, for example:

* [https://agenaastro.com/zwo-12v-dc-adapter-for-cooled-camera-us.html](https://agenaastro.com/zwo-12v-dc-adapter-for-cooled-camera-us.html)
* [https://www.amazon.com/ALITOVE-Adapter-Converter-100-240V-5-5x2-1mm/dp/B01GEA8PQA](https://www.amazon.com/ALITOVE-Adapter-Converter-100-240V-5-5x2-1mm/dp/B01GEA8PQA)

# Batteries

Field deployments will typically need a battery, here are our suggestions. We use a 10Ah Dakota LiFePO4 12V battery.

Be sure to use the correct charger for the battery recommended by the manufacturer to avoid damage and fuse with a 5A fuse.  Ensure the wiring used is large enough to handle the current required to avoid overheating, insulation melting, and voltage drops.  The fuse is a safety measure and is to prevent the situation where the output jack may touch the positive terminal accidentally and short the battery.

LiFePO4 (Lithium Phosphate) battery chemistry is recommended for safety, cold weather performance, and battery longevity.  You should also verify that the battery has a BMC (Battery Management Controller) on board.  Lithium Ion and Lithium Polymer batteries should be avoided due to safety concerns, fire risk/explosion.

We particularly like the batteries made by Dakota, and we own a few due to their exceptional cold-weather performance and warranty. The same batteries that are ideal for Astrid are also used for Fish Finders/Sonars and can be found in Outdoors Stores and on Amazon.

If traveling by air with lithium batteries, be aware that there are regulations depending on the size of the battery, and you should verify with your airline before traveling.

For example, the [TSA guidelines](https://www.tsa.gov/travel/security-screening/whatcanibring/all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,in%20carry%2Don%20baggage%20only)

Do not attempt to use Alkaline batteries (or Zinc-Carbon/Zinc-Chloride) to run Astrid, the internal resistance of these batteries (AA's for example), mean that they are unable to supply the peak current required.  It may be possible to run good quality NiMH AA batteries like the Eneloop Pro, but only for around 2 hrs when configured as 10 batteries in series in a battery holder with solder lugs and 16 gauge wiring... at which point an LiFePO4 is cheaper anyway, runs longer and is less prone to problems.

**Runtimes are approximate.  "Runtime" means Astrid alone (typically tripod mount).  "Runtime with Mount" assumes a mid-sized mount (EQ5/AM5) with a current draw of ~1Amp.**

| Battery | Capacity | Tested | Runtime (hrs) | Runtime With Mount (hrs) | Meets FAA Carry On Regulations | Comments |
| --- | --- | --- | --- | --- | --- | --- |
| [Dakota 12V 7Ah](https://dakotalithium.com/product/dakota-lithium-12v-7ah-battery-69/) | 84Wh | No | 12-14 | 3.5-4.5 | Yes | |
| [Dakota 12V 10Ah](https://dakotalithium.com/product/dakota-lithium-12v-10ah-battery/) | 120Wh | Yes | 17-20 | 5-6.5 | Yes | |
| [Dakota 12V 18Ah](https://dakotalithium.com/product/dakota-lithium-12v-12ah-18-amp-hour-lifepo4-iron-phosphate-battery/) | 216Wh | Yes | 32-36 | 10-12 | No | |
| [Dakota 12V 54Ah](https://dakotalithium.com/product/dakota-lithium-12v-12ah-18-amp-hour-lifepo4-iron-phosphate-battery/) | 691Wh | Yes |90-100 | 30-34 | No | Expensive |
| Sealed Lead Acid Gel Battery | 120Wh | No | 14-17 | 4.5-5.5 | No | Heavy |
| [Celestron PowerTank Lithium (18771)](https://www.celestron.com/products/powertank-lithium) | 84Wh | No | 12-14 | 3.5-4.5 | Yes | Expensive (untested) |
| [Celestron PowerTank Lithium Pro (18768)](https://www.celestron.com/products/powertank-lithium-pro) | 158Wh | Yes | 23-26 | 7-8.5 | Yes | Expensive.  Tested by Steve Conard and Brian Heimes.  The telescope port requires 250mA draw minimum to stay on and the cigarette lighter port requires 420mA minimum. Suggest powering Astrid from the telescope port.  If the power tank is cutting power to Astrid, then a dew heater can be added to increase current.  Also the 5.5 x 2.1mm connector does not have enough length for proper engagement, you should add an extension chord with a longer jack.  Capacity indicators on the Celestron Power Tank are not accurate, otherwise runs fine.  |
| [8 Energizer L91 Lithium AA](https://data.energizer.com/pdfs/l91.pdf) | 36Wh | No | 5-6 | Not feasable | Yes | Buy  at destination. Good to -15C, lower with less runtime. Batteries are expensive and require a solder lug battery holder as most battery holders have small gauge wiring. A small lithium battery you can carry on a plane (e.g., the 10Ah Dakota listed above) is often the most cost-effective option if used more than once. |

# Power Connectors

The recommended way to connect a smaller LiFePO4 battery to Astrid is via a 5A Fuse and DC 5.5mm x 2.1mm male barrel plug with 16 Gauge (or thicker wiring).  The fuse is there to protect the battery from accidental touching of the barrel plug to a battery terminal.  

Often people will make their own power connectors or have connectors already available to them.  Here are some suggestions if you prefer to purchase an a mostly assembled connector without soldering / heat shrinking (you'll still need to crimp 2 terminals):

## Parts

* [Fused 5.5 x 2.1mm Jack](https://www.amazon.com/GELRHONR-Extension-Adapter-Security-Pedal-50cm/dp/B0BWRKRR6V)
* [2.1mm Extension](https://www.amazon.com/SIOCEN-Security-Extension-Surveillance-Standalone/dp/B07Y7XTBF7) 
* [5A Fuses](https://www.amazon.com/Fuses-Blade-Style-Circuit-Protection/dp/B07X313Q4T)
* [Quick Disconnect Terminal 0.25"](https://www.amazon.com/AIRIC-Insulated-Connector-Disconnect-Terminal/dp/B06XCWHY1B)

## Cable Construction

* Cut off the barrel socket close to the end of the socket (leaving just the 2.1mm plug that goes into Astrid.  Split wire and crimp on 2 x 0.25" quick disconnect terminals to connect to the battery (do not connect to battery yet)
* Plug in 2.1mm extension lead
* Replace fuse in the lead with the 5 Amp Fuse

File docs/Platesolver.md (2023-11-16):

# Platesolver

## Introduction

Good fast plate solving is a benefit to astrophotography and occultations.  

Sometimes getting that first plate solve can be difficult due to the number of unknowns with a new setup.  Astrid uses "Offline" plate solving using selected star catalogs stored locally and is tuned to plate solve faster for a specified configuration.  If you are unable to plate solve, we suggest using the saved image and uploading it to Astrometry.net's online solver to determine the focal length and index files used, so that you can use these as a starting point, [see Astrometry Online Solving](#astrometry-online-solving)

Generally, Plate Solving requires the following and any of these can prevent
a plate solve:

* [Good Focus](#good-focus)
* [Clear Sky](#clear-sky)
* [Correct Exposure](#correct-exposure)
* [Correct Astrometry Indexes](#correct-astrometry-indexes)
* [Telescope Within Search Radius](#telescope-within-search-radius)
* [Correct Focal Length](#correct-focal-length)
* [Good Optics](#good-optics)

A full sky plate solve will take longer than one within a 5-degree radius of an expected position.  A plate solve will work from the widest field of views to the smallest (yes even Dobsonians and larger SCTs) provided the correct index files are used.

##### If you have plate solving configured correctly you should expect it to take from between 3-5 seconds for a non-full sky solve, and 5-10 seconds for a full sky solve.  If plate solving is taking 30s or more, the chances of getting a solve are unlikely, and you should look into the requirements above.

## Good Focus

Blurred stars distribute the energy of the star over more pixels and reduce the Signal To Noise, this means that the plate solver may not detect the blurred star as a star, and the best case requires longer exposure times.

A Tri-Bahtinov mask provides the best focus, but it is also possible to hand-adjust the focus to a minimum star diameter or use auto-focus.

## Clear Sky

Thin clouds and clouds will prevent plate solving. Sometimes (in the case of thin clouds), it may be possible to expose longer and still get a plate solve.  Also, cloud tends to be variable, you might get a plate solve, and then not later because more cloud has moved in.

Sometimes the brighter background of the cloud can make it more difficult to plate solve due to decreased contrast with the stars.

Thin forest fire smoke (even smoke you can't see through with your own eyes), is transparent to Infrared provided there are no clouds behind it.  The cameras are sensitive to infrared, so you can often get a plate solve in these circumstances.  However, the brighter background can also reduce contrast too with the stars.

## Correct Exposure

The correct exposure has to be selected for plate solving.  Too short an exposure results in too few stars being detected above the background.  If you don't have perfect polar alignment (German Equatorial Mount, Fork Mount on a Wedge, etc.) or are AltAz mounted, then there may be drift on longer exposures, resulting in stars being distorted into short lines and the plate solver failing.

Light pollution or anything that brightens the background in comparison to the stars may also need a longer exposure time.

Generally, we've found that exposures in the 1-5 second range are best.

## Correct Astrometry Indexes

##### Note: Astrometry index files are now automatically downloaded if needed, this section is for reference if you wish to use alternative index files.

Astrometry needs star catalogs to solve for patterns of stars in your images.  These catalogs are called Index Files, and they need to be selected based on the focal length of your configuration to achieve a plate solve.

Index files are selected based on the focal length of the configuration.  Smaller focal lengths (say 100mm) use fewer and smaller index files than say 2500mm as fewer stars are required for a solve.

Typically astrometry.net suggest using a field of diameter of 0.3X to 0.5X your actual field of view (width in this case as it's the largest dimension).

This information is summarized in the table below, lookup your Field Of View Width (convert to arc minutes if necessary) on the left.

| Your Field of View Width (arcmin) | Suggested Index Field Of View Diameter (arcmin) | Index Scale | Index Series | 
| --- | --- | ----- | --- |
| 0.0...6.25 | 2.0...2.8 | 0 | index\-5200\-\*.fits |
| 6.25...10.0 | 2.8...4.0 | 1 | index\-5201\-\*.fits |
| 10.0...14.0 | 4.0...5.6 | 2 | index\-5202\-\*.fits |
| 14.0...20.0 | 5.6...8.0 | 3 | index\-5203\-\*.fits |
| 20.0...27.5 | 8...11 | 4 | index\-5204\-\*.fits |
| 27.5...40.0 | 11...16 | 5 | index\-5205\-\*.fits |
| 40.0...55.0 | 16...22 | 6 | index\-5206\-\*.fits |
| 55.0...5000.0| 22...2000 | 7-19 | 4100 series |

Series can be downloaded here:
	
* 4100 series: [http://data.astrometry.net/4100/](http://data.astrometry.net/4100/)
	* Download index\-4107.fits to index\-4119.fits and place them in folder /media/pi/ASTRID/astrometry/4100
* 5200 series: [https://portal.nersc.gov/project/cosmo/temp/dstn/index-5200/LITE/](https://portal.nersc.gov/project/cosmo/temp/dstn/index-5200/LITE/)
	* Download the index files as detailed, e.g. index\-5204\-\*.fits, and place them in folder /media/pi/ASTRID/astrometry/5204 for example

Other index files if needed can be obtained here: [http://data.astrometry.net](http://data.astrometry.net)

##### Note: Astrometry index files are now automatically downloaded if needed, this section is for reference if you wish to use alternative index files.

If you are having problems plate solving, or plate solving sometimes when there are few stars (typically at higher focal lengths), then you may wish to download an index on either side too.  For example, if index-5202 is your suggested index, you may wish to download index-5203 and then possibly 5201 (larger) so that the solver can look at all 3 index series.  As these files for lower-scale indexes are large, and take a long time to search, we recommend you don't do this unless necessary.

References:

* [http://astrometry.net/doc/readme.html](http://astrometry.net/doc/readme.html)
* [https://portal.nersc.gov/project/cosmo/temp/dstn/index-5200/](https://portal.nersc.gov/project/cosmo/temp/dstn/index-5200/)
* [https://pypi.org/project/astrometry/](https://pypi.org/project/astrometry/)

## Telescope Within Search Radius

There are two types of plate solve that can be requested, "Full Sky Solve" where it tries to solve for a location anywhere in the sky, and a "Search Radius", where the plate solve is only considered within say 5 deg of the current location of the search.  This is controlled by the "Full Sky Solve" checkbox in Astrid.

If you are unable to get a solve with "Full Sky Solve" unchecked, then your telescope pointing may be off, in which case try a "Full Sky Solve" 

Scope pointing within the search radius from expected RA/DEC (Full Sky Solve will solve for the whole sky)

Search radius can be configured with the "search\_radius\_deg" setting in  [platesolver.json](Configuration.md#platesolver)

## Correct Focal Length

For a plate solve to be achieved, the plate solver needs a search space for the focal lengths it will consider.  Until you achieve a first plate solver, you won't know the exact focal length of your scope.  We suggest that you roughly calculate the focal length in mm's based on your optics and place that value for the "focal\_length" setting in [platesolver.json
](Configuration.md#platesolver) or within the "Choose Config" prompt provided when Astrid launches.

Once you have achieved a plate solve and the exact focal length is known, then the "focal\_length" setting should be updated to match.

Limits for focal length can be configured with the "scale\_low\_factor" and "scale\_high\_factor" settings in  [platesolver.json](Configuration.md#platesolver), although it's recommended these are left at the defaults of 0.1 and 1.25 respectively and "focal\_length" is amended instead.

Focal length is searched by the plate solver between:

* scale\_low\_factor x focal_length *and*
* scale\_high\_factor x focal_length

## Good Optics

Poor optics can prevent plate solving.  This would be typically lens configurations that significantly change the distance between the stars in differing amounts across the field of view or that distort stars such that they are no longer round.

Generally, it has to be quite severe for it to prevent plate solving, but if you can see distorted stars or the field of view is essentially curved, that would be something to look into.

## Astrometry Online Solving

Astrometry.net provides an online service where you can upload an image plate solve it.  If you are having issues determining plate solving focal length and the best index files to use, we suggest uploading your fits file to:

[https://nova.astrometry.net](https://nova.astrometry.net)

Expand Advanced settings, and check "Source Extractor".  If you have a high focal length (Large SCT, Dobsonian etc.), you may also want to try "Scale" set to "tiny" or "custom" to restrict the search range.

When you have a plate solve (which may take some time), look for the line which says "Field 1: solved with index index-4111.fits" and note the index file used for the solve, in this case "index-4111.fits".

To determine focal length, click on "Go to the results page" and look for the "Pixel Scale" (this should be in arcsec/pixel, if not, convert to arcsec/pixel).

* camera\_pixel\_Size (um): 3.45
	* IMX296 Mono/GSC = 3.45

* pixel_scale (arcsec): 8.63
	* Obtained from astrometry.net plate solve

Focal Length Formula:

	focal_length = 206.265 *  camera_pixel_size / pixel_scale
	focal_length = 206.265 * 3.45 / 8.63
	focal_length = 82.5mm

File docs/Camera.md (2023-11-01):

# Cameras

## Introduction

* [Global Shutter Camera](https://www.raspberrypi.com/documentation/accessories/camera.html)

	| Name | Value | 
	| ---- | ----- |
	| Sensor | Sony IMX296LLR-C(Mono) / IMX296LQR-C (Color) Pregius Gen 2 |
	| Architecture | Front Illuminated |
	| Mono/Color | Color |
	| Shutter | Global |
	| Pixel size | 3.45um x 3.45um |
	| Bits | RAW10 |
	| Sensor resolution | 1456 x 1088 (1.58 Megapixels) |
	| Sensor image area | 5.023mm x 3.754mm|`
	| Sensor diagonal | 6.3mm | 
	| Optical size | 1/2.9" |
	| Binning | 1x |
	| Dynamic range | TBD|
	| Read noise | [2.2e](https://scientificimaging.com/knowledge-base/qe-curves-for-cmos-imagers/) |
	| Dark current @ 25C| [3.2e/p/s](https://scientificimaging.com/knowledge-base/qe-curves-for-cmos-imagers/) |
	| Full well capacity| [10.6Ke](https://scientificimaging.com/knowledge-base/qe-curves-for-cmos-imagers/) |
	| Quantum efficiency | [Peak QR: 68% @ 550nm](https://scientificimaging.com/knowledge-base/qe-curves-for-cmos-imagers/) |
   	| Gain | 1-16 |
	| Maximum exposure time | 15.534385s |
	| Minimum exposure time | 29uS |
	| IR cut filter | Yes - [Removable, see "Filter Removal"](https://www.raspberrypi.com/documentation/accessories/camera.html) Filter type unknown, but maybe [Hoya CM500](http://unihedron.com/projects/darksky/hcm500.htm) i.e. same as HQ camera  |
	| Mode: 0 | Size:(1456,1088) Bin:1 Bits:10 FOV:(100%,100%) MaxFPS:60.38 Exp:29us->15.534385s |
	| Camera Datasheet | [Raspberry Pi Global Shutter Camera](https://datasheets.raspberrypi.com/gs-camera/gs-camera-product-brief.pdf)|
	| Sensor Datasheet | [Full Datasheet](https://en.sunnywale.com/uploadfile/2023/0327/IMX296LQR-C_Fulldatasheet_Awin.pdf); [Summary Datasheet IMX296LQR](https://scientificimaging.com/wp-content/uploads/2021/01/FSM-IMX296_V1A-V1B_Datasheet_v1.1b_Full.pdf) |
	| Raspberry Pi Documentation | [Cameras](https://www.raspberrypi.com/documentation/accessories/camera.html) |

* [Raspberry Pi HQ](https://www.raspberrypi.com/documentation/accessories/camera.html)

	| Name | Value | 
	| ---- | ----- |
	| Sensor model | Sony IMX477R Exmor RS CMOS |
	| Architecture | Back-Illuminated(R), Stacked(S) |
	| Mono/Color | Color |
	| Shutter | Rolling |
	| Pixel size | 1.55um x 1.55um |
	| Bits | RAW12/10/8, COMP8 |
	| Sensor resolution | 4056 x 3040 (12.3 Megapixels) |
	| Sensor image area | 6.287mm x 4.712mm|
	| Sensor diagonal | 7.9mm | 
	| Optical size | 1/2.3" |
	| Binning | 1x or 2x |
	| Dynamic range | [11.15 stops](https://www.strollswithmydog.com/tag/imx477/) |
	| Read noise | [3e(gain 1), 1.5e(gain 16)](https://www.strollswithmydog.com/tag/imx477/) |
	| Quantum efficiency | TBD |
	| Gain | 1-22.25 |
	| Maximum exposure time | 667-694s |
	| Minimum exposure time | 31-114us |
	| IR cut filter | [Hoya CM500](http://unihedron.com/projects/darksky/hcm500.htm) - [Removable, see "Filter Removal"](https://www.raspberrypi.com/documentation/accessories/camera.html) |
	| Mode: 0| Size:(1332,990) Bin:2 Bits:10 FOV:(65.7%,65.1%) MaxFPS:120.05 Exp:31us->667s |
	| Mode: 1 | Size:(2028,1080) Bin:2 Bits:12 FOV:(100.0%,71.1%) MaxFPS:50.03 Exp:60us->674s |
	| Mode: 2 | Size:(2028,1520) Bin:2 Bits:12 FOV:(100.0%,100.0%) MaxFPS:40.01 Exp:60us->674s |
	| Mode: 3 | Size:(4056,3040) Bin:1 Bits:12 FOV:(100.0%,100.0%) MaxFPS:10.00 Exp:114us->694s |
	| Camera Datasheet | [Raspberry Pi High Quality Camera](https://static.raspberrypi.org/files/product-briefs/Raspberry_Pi_HQ_Camera_Product_Brief.pdf)|
	| Sensor Datasheet | [IMX477-AACK-C](https://www.uctronics.com/download/Image_Sensor/IMX477-DS.pdf) (IMX477R is a Raspberry Pi version, this is the closest sensor datasheet)|
	| Raspberry Pi Documentation | [Cameras](https://www.raspberrypi.com/documentation/accessories/camera.html) |

## Camera Notes

### 	Raspberry Pi HQ:

#### XVS Trigger Mode

Sony IMX477 Sensor, by default XVS (active low) are disabled - ** 1.8V ** when a frame starts to be read out.  XVS is for the start of the frame (vertical).  Frame being read out is at the end of the exposure, so subtract exposure length to get frame starting time.  To enable, add to /boot/cmdline.txt:

	 imx477.trigger_mode=1  
	 
However for old camera model (not picamera2), use this: [Old Camera Mode Configuration](https://forums.raspberrypi.com/viewtopic.php?t=281913)
[Readout example (not this sensor)](https://www.sunnywale.com/uploadfile/2021/1227/IMX174LLJ-C-Awin.pdf)
[Configuring Registers](https://forums.raspberrypi.com/viewtopic.php?t=319373)

#### Star Eater (Defective Pixel Control - DPC)

Sony IMX477 Sensor, by default Star Eater is enabled which will reduce noise but has the side effect of eating stars which has been well documented in some Sony Cameras.  To disable, add to /boot/cmdline.txt:

	imx477.dpc_enable=0
	
[Defective Pixel Control](https://forums.raspberrypi.com/viewtopic.php?t=341862)

### 	Raspberry Pi Global Shutter:

Sony IMX296 Sensor, by default XVS and XHS output triggers (active low) are enabled - ** 1.8V ** when a frame starts to be read out.  XVS is for the start of the frame (vertical) and XHS is for the start of a horizontal scan line (row readout).  Frame being read out is at the end of the exposure, so subtract exposure length to get frame starting time.

[Closest Datasheet](https://www.leopardimaging.com/uploads/LI-IMX296-MIPI-CS_datasheet.pdf)

# Links

LibCamera

* [Picamera2 Library](https://datasheets.raspberrypi.com/camera/picamera2-manual.pdf)
* [Picamera2 Examples](https://github.com/raspberrypi/picamera2/tree/main/examples)
* [Picamera2 Overview](https://raspberrytips.com/picamera2-raspberry-pi/)

Camera

* [Hubble Pi - HQ Camera and Code to Read It](https://magpi.raspberrypi.com/articles/hubble-pi)
* [Adding Timestamps to libcamera-vid](https://forums.raspberrypi.com/viewtopic.php?t=326796)
* [libcamera](https://www.raspberrypi.com/documentation/computers/camera_software.html)
* [Global Shutter Camera](https://hackaday.com/2023/03/09/new-raspberry-pi-camera-with-global-shutter/)
* [QE Curves - CMOS Images Sony](https://scientificimaging.com/knowledge-base/qe-curves-for-cmos-imagers/)
* [Sony IMX296 Sensor](https://www.phase1vision.com/sensors/sony-sensors/pregius/imx296llr)
* [Global Shutter Camera Datasheet (Raspberry Pi)](https://datasheets.raspberrypi.com/gs-camera/gs-camera-product-brief.pdf)
* [ArduCam libcamera](https://docs.arducam.com/Raspberry-Pi-Camera/Native-camera/Libcamera-User-Guide/)
* [Raspberry Pi Camera Software](https://www.raspberrypi.com/documentation/computers/camera_software.html)

Star Eater

[New Driver need to edit in cmdline.txt](https://forums.raspberrypi.com/viewtopic.php?t=341862)
[Overview 1](https://forums.raspberrypi.com/viewtopic.php?t=278439)
[Overview 2](https://forums.raspberrypi.com/viewtopic.php?t=277768)
[Overview 3](https://www.strollswithmydog.com/pi-hq-cam-sensor-performance/)

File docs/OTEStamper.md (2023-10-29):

# OTEStamper

## Introduction

[OTEStamper](https://github.com/ChasinSpin/OTEStamper) is hardware and firmware to provide a highly accurate GPS-based timing source for [Astrid](../README.md) to record astronomical Occultations, Transits, and Eclipses (OTE) on a Raspberry Pi as a video file.  Using the [OTEStamper](https://github.com/ChasinSpin/OTEStamper), these events are timestamped accurately so that they can be used for scientific purposes using commonly available Raspberry Pi hardware when paired with a telescope or zoom lens.  It can be used with the Raspberry Pi HQ or Global Shutter cameras currently.

Accurate timing with [OTEStamper](https://github.com/ChasinSpin/OTEStamper) is provided by using a GPS receiver with PPS capability ([GT-U7](https://www.amazon.com/Navigation-Satellite-Compatible-Microcontroller-Geekstory/dp/B07PRGBLX7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)) to update the clock on the Raspberry Pi to within 1uS accuracy and concurrently updates time in a microcontroller.  The board contains a real-time ATmega328pb microcontroller to monitor the 1PPS signal and flash an LED which is inserted into the light path of the sensor.  This LED is precisely controlled to flash at custom intervals and duration to determine exact timing within the video for both rolling and global shutters and quantify any delay. Overall accuracy better than 1.25uS is provided for frame timing.

## Accuracy and Delays

* GPS: Average of 2.35ns over 6 hours, with a sampling deviation of 6.7ns
* Delay from XVS Trigger (Camera) to MCU External Interrupt input seeing voltage high: 40.3ns
* Firmware timing accuracy over 5mins: Min-Max 1.25uS, Standard Dev: 0.26uS

## Programming

The ATmega328pb can be programmed directly from the Raspberry Pi, no additional hardware is required.

To view debugging serial print's from the firmware, uncomment DEBUG in config.h and ensure /boot/config.txt contains:
 
	[pi4]
	# Run as fast as firmware / board allows
	arm_boost=1
	
	dtoverlay=uart5

## Schematic/Board
[Schematic - PDF](hardware/OTEStamper.pdf)

[Eagle files](hardware)

## BOM (Bill Of Materials)

| Quantity | Part | Value | Tolerance | Package | Description | Manufacturer | Supplier | Supplier Part # |
| --- | ---- | ----- | --- | --- | --- | --- | --- | --- |
|4|R10,R11,R14,R15|200|5%|0603|Resistor|DigiKey|-|
|1|R21|430|5%|0603|Resistor|DigiKey|-|
|10|R1,R2,R3,R4,R7,R9,R12,R13,R17,R20|1K|5%|0603|Resistor|DigiKey|-|
|3|R8,R18,R19|10K|1%|0603|Resistor|DigiKey|-|
|1|R6|33K|1%|0402|Resistor|DigiKey|-|
|1|R16|47K|1%|0603|Resistor|DigiKey|-|
|1|R23|100K|1%|0603|Resistor|DigiKey|-|
|1|R5|249K|1%|0402|Resistor|DigiKey|-|
|1|R22|470K|1%|0603|Resistor|DigiKey|-|
|2|C2,C5|12pF C0G/NP0|20%|0603|Capacitor|DigiKey|-|
|5|C10,C11,C12,C13,C14|0.1uF X5R/X7R|20%|0603|Capacitor|DigiKey|-|
|1|C3|0.1uF X5R/X7R|20%|0402|Capacitor|DigiKey|-|
|1|C4|1uF X5R/X7R|20%|0402|Capacitor|DigiKey|-|
|3|C6,C7,C8|22 uF 10V X5R/X7R|20%|0603|Capacitor|DigiKey|-|
|1|C1|22uF 25V X5R Low ESR|20%|0805|Capacitor|DigiKey|-|
|1|C15|150uF 25V Top Tier|20%|6.3x7.7x8mm|Capacitor|DigiKey|-|
|1|C9|DNP|DNP|DNP|Capacitor|DigiKey|-|
|1|L1|2.2uH - EXL1V0605-2R2-R|Eaton Electronics|7.2x6.9mm|Inductor|DigiKey|-|
|1|F1|0ZCG0200AF2B|Bel Fuse Inc.|1812|Fuse|DigiKey|-|
|1|D1|1N4148WX|-|SOD-323|Diode|DigiKey|-|
|2|Q1,Q2|MMBT2222A-TP|-|SOT23-BEC|General Purpose NPN Transistor 600mA|-|Digi-Key|-|
|1|Q3|Si4825DDY|-|SOIC-8|P-Channel Mosfet 30V(D-S) 14.9A|DigiKey|-|
|1|Q4|DMG2305UX|-|SOT23|P-Channel 20V 4.2A 1.4W Mosfet|DigiKey|-|
|1|Q5|DMMT5401|-|SOT26/SC74R|Dual PNP Small Signal Transistors(matched)|DigiKey|-|
|1|XT1|RH100-8.000-10-1010-EXT-TR|-|4-SMD 3.2 x 2.5 x 0.8mm 4 pin|8 Mhz Crystal 10ppm 10pF Load|Raltron Electronics|Digi-Key|2151-RH100-8.000-10-1010-EXT-TRCT-ND|
|1|SP1|PS1240P02BT|-|PS12 12.2mm Dia|3V Piezo Buzzer Transducer (no internal oscillator)|TDK|Digi-Key|445-2525-1-ND|
|1|U1|AP62500SJ-7|-|QFN|Buck Regulator Adjustable|DigiKey|-|
|1|U2|SN74AUP1T57DBV|-|SOT23-6|Single Supply Level Translator|Texas Instrument|Digi-Key|296-17524-1-ND|
|1|U3|ATMEGA328PB-AN|-|32-TQFP|ATmega328pb Microcontroller|Microchip Technology|Digi-Key|ATMEGA328PB-AN-ND|
|1|U4|SN74LVC1G123DCT|-|SSOP-8|Monostable|Texas Instruments|Digi-Key|296-18758-1-ND‎|
|1|X1|PJ-063AH|-|PJ-063AH|2.1x5.5mm 8A DC Power Jack PJ-063AH|DigiKey|-|
|1|X3|S2B-PH-SM4-TB|-|S2B-PH-SM4-TB|Connector Header Surface Mount, Right Angle 2 position 0.079" (2.00mm)|DigiKey|455-S2B-PH-SM4-TBCT-ND|
|1|X2|Adafruit 2222|-|0.1" Header|0.1" Female Header 2x20|[Adafruit](http://adafru.it/2222)|Digi-Key|1528-1785-ND|
|2|JP2,JP3|PRPC002SBAN-M71RC|-|0.1" Header|0.1" Right Angled Male Header 1x2|Sullins Connector Solutions|Digi-Key|S1111EC-02-ND|
|1|-|920-0096-50|-|920-0096-5|0.1" Jumper Wire Female to Female 8.00" (203.20mm) 28 AWG, only need 1 wire here, maybe more cost effective option. These are daisy chained and need to be clipped.|SchmartBoard Inc|Digi-Key|1988-1038-ND|
|1|Fan|3368|-|30x30x8mm|5VDC 30x30x7.7mm Fan for Cooling|Adafruit or CanaKit Raspberry Pi Fan|Digi-Key|1528-1904-ND|
|4|-|24332|-|-|24332 Hex Standoff M2.5 x 0.45 Alumnimum 12mm or 11mm|Keystone Electronics|Digi-Key|36-24332-ND|
|4|-|4707|-|-|Hex Nut 0.197" Steel M2.5 x 0.45 (to go with standoffs)|Keystone Electronics|Digi-Key|36-4707-ND|
|1|MODULE1|GT-U7|-|Module|NEO-6M Based GPS Module with PPS|Goouuu Tech|Amazon|[GT-U7 GPS board](https://www.amazon.com/Navigation-Satellite-Compatible-Microcontroller-Geekstory/dp/B07PRGBLX7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)||
|2|-|Zip Tie|-|Zip-Tie|Zip-Tie (max width 3mm)|DigiKey|-|
|1|*** PCB||-||PCB|OSHPark|OSHPark|[OSHPark](http://www.oshpark.com/)|
|1|*** Stencil|-|-|-|(Optional) |OSHStencil|OSHStencil|[OSHStencil](http://www.oshstencil.com/)| 
|1|*** Enclosure|-|-|-|3D Printed Enclosure|3D Printer|3D Printer||

Notes: DNP = Do Not Populate, SMD sizes are imperial

## Adaptors
* C/CS to 1.25 adapter
* C/CS to 48mm dapater

## Next Design Revision

Nothing

## Future Wish List
* Lipo Battery (not sure about this one)
* Adafruit sell an 18650 3 cell 10Ah battery pack
* Maybe Peltier support

## ATmega328PB Programming

Read Fuses:

	raspi-gpio set 22 op
	raspi-gpio set 22 dl	# Reset - put in programming mode
	sudo avrdude -p m328pb -P /dev/spidev0.0 -c linuxspi -b 10000
	raspi-gpio set 22 dh
	
Makefile:

	(NEEDS UPDATING FOR 328pb)
	MCU=atmega328p
	AVRDUDEMCU=m328p
	FUSES=-U lfuse:w:0xFF:m -U hfuse:w:0xDA:m -U efuse:w:0x06:m
	#FUSES=-U lfuse:w:0x62:m -U hfuse:w:0xD9:m -U efuse:w:0x07:m    # DEFAULT ATmega328p shipping fuses
	CC=/usr/bin/avr-gcc
	CFLAGS=-g -Os -Wall -mcall-prologues -mmcu=$(MCU)
	OBJ2HEX=/usr/bin/avr-objcopy
	AVRDUDE=/usr/local/bin/avrdude
	TARGET=blinky
	
	all:
		$(CC) $(CFLAGS) $(TARGET).c -o $(TARGET)
		$(OBJ2HEX) -R .eeprom -O ihex $(TARGET) $(TARGET).hex
		rm -f $(TARGET)
	
	install: all
		raspi-gpio set 22 op
		raspi-gpio set 22 dl	# Reset - put in programming mode
		sudo $(AVRDUDE) -p $(AVRDUDEMCU) -P /dev/spidev0.0 -c linuxspi -b 10000 -U flash:w:$(TARGET).hex
		raspi-gpio set 22 dh
	
	noreset: all
		sudo $(AVRDUDE) -p $(AVRDUDEMCU) -P /dev/spidev0.0 -c linuxspi -b 10000 -U flash:w:$(TARGET).hex

	readfuses:
		raspi-gpio set 22 op
		raspi-gpio set 22 dl
		sudo $(AVRDUDE) -p $(AVRDUDEMCU) -P /dev/spidev0.0 -c linuxspi -b 10000		raspi-gpio set 22 dh
	
	writefuses:
		raspi-gpio set 22 op
		raspi-gpio set 22 dl
		sudo $(AVRDUDE) -p $(AVRDUDEMCU) -P /dev/spidev0.0 -c linuxspi -b 10000 $(FUSES)		raspi-gpio set 22 dh
	
	clean :
		rm -f *.hex *.obj *.o	
		
Blinky:

	#define F_CPU 8000000L

	#include <avr/io.h>
	#include <util/delay.h>

	int main (void)
	{
   	     DDRD |= (1 << PD5);
   	     for (;;)
   	     {
   	             PORTD ^= (1 << PD5);
   	             _delay_ms(500);
   	     }
   	     return 0;
	}

## OTEStamper SPI Protocol

The command protocol uses an SPI bus with a master (the Raspberry Pi) and a slave (the ATmega328pb).

The Atmega328p does not have double buffering when sending data as a slave, therefore either polling has to be implemented to minimize delay
or interrupts are used which take longer and require slower SPI transmission rates as SPDR can't be loaded with a new value until the last value has transmitted.  To solve this:

Transactions are completed as a one-byte concurrent read/write, i.e. CS is taken low, one byte is sent by the master at the same time
the slave is sending a byte.  Conceptually the slave doesn't respond to a command from the master until the next command is sent by the master.
Data is therefore preemptively preloaded by the slave based on what the slave thinks the master will need for the next command and the delay to
allow userspace processing happens during the idle period between spi transmissions.  This approach differs from conventional SPI register-based access.

Implemented on top of this level are higher-level transactions that are aware of this 1-byte delay:

| Device | SPI Transaction | SPI Transaction | SPI Transaction | SPI Transaction| SPI Transaction |
| --- | --- | --- | ---- | ---- | --- |
| Master TX:  | Cmd | 0xFF | 0xFF | 0xFF | 0x00 |
| Slave TX: | XX  | Data 1 | Data .. | Data N | CRC |

**Note: CS goes low then high for each byte transmission**

The master expects a certain length response for a particular command.  Also, it can only send commands 1 byte in length and no
data.

Due to the received data from the master by the slave being Cmd, 0xFF or 0x00 and commands can not be 0x00 or 0xFF, it's
possible for the slave to know what stage in the transmission from the master it is and can reset
the higher level transaction state if master/slave become out of sync.

Any multibyte values (Unsigned Int 32 for example), are sent little-endian (LSB first),

### CRC Calculation

The CRC is calculated using \_crc8\_ccit\_update() with a 0x00 initial value using the calculation here:
[avr-libc CRC Computatations](https://www.nongnu.org/avr-libc/user-manual/group__util__crc.html) 

The CRC calculation is calculated from: Cmd, Data1, Data.., DataN and does not include the CRC bytes.

Because the CRC also includes the Cmd sent by the Master at the start, it serves to confirm that the command sent to the slave from the master was not corrupted.

### Commands

| Command | Type | Description | Response Length (bytes) | Response (Data bytes) |
| --- | ---- | --- | --- | --- |
| 0x60 | Get | Get Status | 0x01 | See "Get Status" below |
| 0x70 | Get | ID Magic Number | 0x04 | 0x1C 0x2A 0x03 0xFD |
| 0x71 | Get | Firmware Version | 0x02 | Unsigned Int 16 bit |
| 0x72 | Set | LED On | 0x00 | - |
| 0x73 | Set | LED Off | 0x00 | - |
| 0x74 | Set | FAN On | 0x00 | - |
| 0x75 | Set | FAN Off | 0x00 | - |
| 0x76 | Set | Timing Test On | 0x00 | - |
| 0x77 | Set | Timing Test Off | 0x00 | - |
| 0x78 | Set | Cold Restart GPS | 0x00 | - |
| 0x79 | Set | Frame Timing Info Interrupt On | 0x00 | - |
| 0x7A | Set | Frame Timing Info Interrupt Off | 0x00 | - | 
| 0x7B | Set | Buzzer On | 0x00 | - | 
| 0x7C | Set | Buzzer Off | 0x00 | - | 
| 0x90 | Get | GPS Info | 0x1C | See "GPS Info" below |
| 0x91 | Get | Frame Timing Info | 0x10 | See "Frame Timing Info" below |
| 0x92 | Set | Confirmed Frame Received | 0x00 | See "Frame Timing Info" below |
| 0x93 | Get | Test Frame For Validation | 0x10 | 16 values sequentially starting 0x55, 0x56 etc. |

Commands are stateless apart from 0x91/0x92, where a queue is being used to prevent
lost transmissions.  After data has been successfully received via an 0x91, a 0x92 should be issued to confirm reception and delete that item from the queue.  If an 0x91 fails the CRC, then another 0x91 can be issued to try again.  Sequence numbers should
always be checked in the frames to ensure they are sequential, if the same frame number is seen again, then it means the 0x92 was not received, 0x92 should be sent again and the frame silently dropped as a duplicate.

Slave: Commands are not CRC'd on transmission from the master, therefore it is possible for the slave
to receive a corrupt command.  However, the master will also receive an invalid CRC on the response due to the CRC including the command.  At this point, the master can request a Get Status command to see if there was any unintended change to the slave due to the transmission error.  The only exception to this is if the command is corrupted to 0x92 (confirmed frame received). In this unlikely scenario, expected frame sequence numbers will jump and can be detected by the master.

Master: Commands are actioned by the slave when the command byte is received. Therefore reception of a correct CRC is confirmation that the command has been executed, even if the last 0x00 from the master is not received by the slave.

#### Get Status

1 byte status containing bit flags indicating items that are on.

| Bit | Description |
| --- | --- |
| 0 | LED On |
| 1 | FAN On |
| 2 | Buzzer On |
| 3 | Timing Test On |
| 4 | Frame Timing Info Interrupt On |

#### Frame Timing Info Interrupt

When the "Frame Timing Info Interrupt" is switched on (Cmd = 0x79), the following happens:

1. Frame sequence number is reset to 0
2. The Frame Info Queue on the OTEStamper is cleared
3. New XVS triggers cause Frame Info to be stored in the Frame Info Queue
4. Interrupts are generated on each addition to the Frame Info Queue

When the "Frame Timing Info Interrupt" is switched off (Cmd = 0x7A), interrupts
are no longer generated.

#### GPS Info

| Offset | Length (bytes) | Description | Type | 
| --- | --- | --- | ---- |
| 0x00 | 4 | Latitude in decimal degrees * 10000000 | Int 32bit |
| 0x04 | 4 | Longitude in decimal degrees * 10000000 | Int 32bit | 
| 0x08 | 4 | Altitude in decimal degrees * 10 | Int 32bit | 
| 0x0C | 1 | The number of satellites used in the fix | Unsigned Int 8bit | 
| 0x0D | 1 | Fix: 0 = No gps packets receiver yet, 1 = Fix not available, 2 = 2D Fix, 3 = 3D Fix | Unsigned Int 8bit | 
| 0x0E | 2 | Position dilution of precision * 100 | Unsigned Int 16bit | 
| 0x10 | 2 | Horizontal dilution of precision * 100 | Unsigned Int 16bit | 
| 0x12 | 2 | Vertical dilution of precision * 100 | Unsigned Int 16bit | 
| 0x14 | 4 | Unix Epoch | Unsigned Int 32bit |
| 0x18 | 1 | Leap Seconds | Int 8bit |
| 0x19 | 1 | Clock Status | See below |
| 0x1A | 2 | Power Supply Voltage | Unsigned 16bit. V = (reading * 3.3) / (1023.0 * 0.1754385) |

#### Frame Timing Info

| Offset | Length (bytes) | Description | Type | 
| --- | --- | --- | ---- |
| 0x00 | 1 | Remaining frame info's in queue. 0x01 = current entry (normal), 0x00 = empty queue, 0x02 = 2 items | Unsigned Int 8bit |
| 0x01 | 1 | Leap Seconds | Int 8bit |
| 0x02 | 1 | Clock Status | See below |
| 0x03 | 1 | Frame sequence # | Unsigned Int 8bit |
| 0x04 | 4 | Last PPS Duration 1sec (ticks) | Unsigned Int 32bit |
| 0x08 | 4 | Frame ticks since last PPS | Unsigned Int 32bit |
| 0x0C | 4 | Frame Unix Epoch | Unsigned Int 32bit |

If the frame timing queue is empty, only 0x00 will be returned, and the rest of the data for that frame will be zero.

### Clock Status

| Bit | Value | Notes |
| --- | ---  | --- |
| 0 | PPS\_SEEN | Set if pulse has been seen since startup |
| 1 | PPS\_RECENT  | Set if we've had 2 pulses in the last 2 seconds |
| 2 | LEAP\_SECONDS\_SOURCE_GPS  | Leap seconds from the GPS (normal) |
| 3 | LEAP\_SECONDS\_SOURCE\_EEPROM  | Leap seconds from the eeprom (normal) |
| 4 | LEAP\_SECONDS\_SOURCE\_SOFTWARE  | Leap seconds from the software (maybe degraded) |
| 5 | TIME\_JUMPED  | The time jumped, this bit is cleared on read |

## Frame Trigger (XVS) Timing

Reference: [IMX 296 Full Datasheet](https://en.sunnywale.com/uploadfile/2023/0327/IMX296LQR-C_Fulldatasheet_Awin.pdf)

The XVS pulse is the vertical sync pulse and it is emitted once for every frame (active low), it is emitted towards the end of the exposure of the frame.  When the pulse occurs, the pulse is timestamped by the OTEStamper board using timely Input Capture Registers on the ATmega328pb.

### XVS Acquisition Delay OTEStamper

The delay between XVS being generated and recorded on OTEStamper is:

| Reason | Delay |
| --- | ----- |
| Pulseshaping, conversion to 3.3V logic | 40.3ns |
| Input Capture Time Delay on ATmega328pb for XVS | 1/8Mhz = 125ns (quantization) |
| Input Capture Time Delay on ATmega328pb for GPS PPS | 1/8Mhz = 125ns (quantization) |

Taking 1/2 the Input Capture Time Delay for the GPS PPS as being an average = 62.5ns,this means that on average all our timestamps are 62.5ns late.  Additionally, the Input Capture for the XVS pulse also has an average of 62.5ns.

Combined, the XVS timestamp is reported later than it actually occurred by 40.3 + 62.5 + 62.25ns = 165.3ns and this value should be subtracted from the time reported by OTEStamper (this is not corrected for in OTEStamper due to processing time constraints.  Note that the input capture time delay variability (PPS and XVS) due to level change possibly not lining up with CPU clock frequency (quantization) creates 125ns x 2 = 250ns worse case timing error by OTEStamper.  So timing accuracy is +/- 250ns.

### Calculating Frame Start Time

[IMX 296 Full Datasheet](https://en.sunnywale.com/uploadfile/2023/0327/IMX296LQR-C_Fulldatasheet_Awin.pdf) *(Pulse Output Function - Image Drawing of Pulse Output Function in Global Shutter (Normal Mode))* denotes that "Normal Mode" for the IMX296 has XVS occurring towards the end of the exposure of the sensor.  The end of the exposure of the frame occurs 4 XHS pulses (the communication period) after the XVS pulse.

The XHS pulses (also called the 1H Period) is 14.81uS, there for the end time of the frame is XVS + 4 x 14.81uS = XVS + 59.24uS.

This means that to arrive at the start time of the frame, the exposure duration needs to be subtracted from XVS + 59.24uS.

### Putting It Together

Frame End Time = ((OTEStamper XVS Time - 165.3ns) + 59.24us) = OTEStamper XVS Time + 0.0000590747s

Frame Start Time = Frame End Time - Exposure Duration

Absolute Accuracy = 250ns + 2.35ns(GPS) + 6.7ns(GPS) = +/-259.02ns

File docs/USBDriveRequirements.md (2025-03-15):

# USB Drive Requirements

## Astrid Requirements

Astrid writes frames that are 2MB in size.  This means that at 30fps, Astrid will write data to the USB Drive at 60MB/s.

Astrid contains a cache that is 160 frames in size, but if the USB Drive is poorly implemented or not up to the requirements, then eventually frames will be dropped.

## USB Drive

To keep up with the large raw video files and high frame rates Astrid uses, an appropriate USB Drive must be selected.  The requirements are as follows:

* USB 3.0, ideally 3.1 or 3.2
* More than 120MB/s write speed continuously (random and sequential).  These need to be in real-life situations, not just advertised, they must also persist when there's no more caching available.
* UASP support (up to 50% speed increase)
* Sufficient size to store the files
* Plugged into the Blue USB ports on the Raspberry Pi
* Always formatted in Astrid

## pSLC Cache

Most drives have pSLC cache. This can exhibit some unusual effects. For example, a drive can be writing at, say, 100-1000MB/s and then, after a certain amount has been transferred, drop down to 10-40MB/s (which no longer meets Astrid's requirements). The drive may not be back up to full speed for even as long as 30 minutes or write a smaller amount faster and then slow down again.

References:

[pSLC Cache Design for Enhanced Performance and Lifetime](https://www.flashmemorysummit.com/Proceedings2019/08-06-Tuesday/20190806_EMBD-101A-1_McCormick.pdf)
[Fastest USB flash drive benchmark test 2024](https://ssd-tester.com/usb_flash_drive_test.php)

## USB Thumb Drive Testing

### Recommended Drives:

| Drive |  WT pSLC | WT No pSLC | pSLC | UASP | Recommended |
| ----- | --- | --- | ---- | ---- | --- |
| [Reletch Elite7 Pro USB 3.2 Solid State Drive Read 480MB/s 256GB](https://www.aliexpress.us/item/1005006081674212.html) | 87.78MB/s | 87.78MB/s | - | No | Likely best choice, only 1 sampled.
| [Corsair Flash Voyager GTX 128GB USB 3.1 Flash Drive](https://www.amazon.com/Corsair-Flash-Voyager-128GB-Premium/dp/B079NVJPKV) (also 256GB version of this drive) | ~100MB/s | ~46MB/s | ~4.2GB | Yes | Yes (but only upto 4GB videos) |
| [TOPESEL 256GB USB 3.1 Gen 2 Flash Drive Super Speed 400Mb/s](https://www.aliexpress.us/item/1005003422090205.html) | 83.9MB/s | 83.9MB/s | None | No | Some other TOPESEL drives have been inconsistent, and they don't give refunds, only one of this model has been sampled. |
| [Patroit Supersonic Rage Prime USB 3.2 Gen 2 Flash Drive - 500GB PEF500GRPMW32U](https://www.amazon.com/Patriot-Supersonic-Prime-Flash-Drive/dp/B095HXK1D1) | 98.77MB/s | 87.49MB/s | Unknown but >10GB | - | Yes |

### Avoid:

| Drive | WT pSLC | WT No pSLC | pSLC | UASP | Recommended |
| ----- | --- | --- | ---- | ---- | --- |
| Lexar 128GB JumpDrive P30 USB 3.2 Gen 1 Flash Drive (LJDP030128G-RNQNG) | ~90MB/s | ~50MB/s | ~12GB | Yes | Avoid (unpredictable) speeds, start off around 8MB/s) |
| Arcanite 256GB USB 3.1 Flash Drive AK58256G | - | - | ~3GB | Yes | Avoid (slow, cache burnt through fast) |
| Sandisk Extreme Pro 3.2 | - | - | ~ >100GB | No | Avoid (unpredictable speed/features/faulty drives) |
| [TOPESEL 256GB USB 3.1 Gen 2 High Speed Thumb Drive](https://www.aliexpress.us/item/1005005393760142.html) | 55MB/s | 55MB/s | - | No | Avoid, doesn't meet specs, TOPESEL won't refund |
| [TOPESEL 128GB USB 3.1 Flash Drive, Up to 380MB/s](https://www.amazon.ca/dp/B08QTXBG9H) | ~98MB/s | ~70MB/s | ~3GB | No | Meets 30fps just on some sample, others fail dramatically.  Avoid. |

Reference: [Fastest USB flash drive benchmark test 2024](https://ssd-tester.com/usb_flash_drive_test.php)

## Fragmentation

Deleting files from a USB Drive may fragment the drive and, depending on its quality, slow down the speed at which data can be written.  This effect can vary depending on the drive and how it's designed.

## Speed Testing 

Use the Diagnostics icon on the desktop in "Astrid Tools" to run a speed test.  The results are placed in diagnostics.txt on the Astrid drive.

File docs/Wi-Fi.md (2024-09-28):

# Wi-Fi

**Per person support for WiFi networks is not provided. Common problems are misconfigured networks, routers and misunderstanding of how networking works. Compounding the issue is that network settings can't be changed over a zoom session without killing the zoom session, making it difficult or impossible for someone remote to assist.**

**If you are having issues connecting to your home network, it is recommended that you find someone local who understands networking technology and can assist you.**

The following is a list of things we have encountered and should be worked through systematically if you are having difficulty connecting Astrid to the Internet.
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

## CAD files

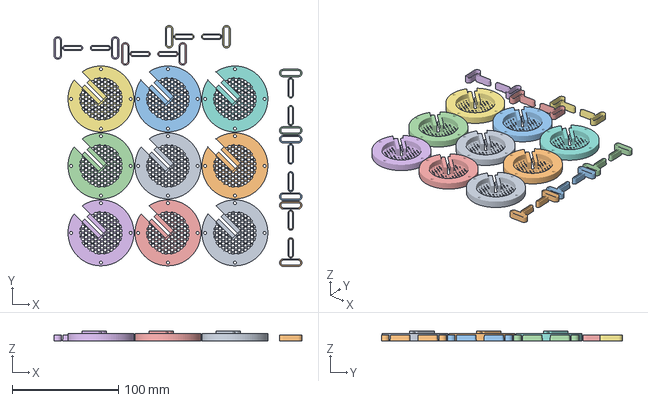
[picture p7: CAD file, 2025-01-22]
3DPrinted/stl/cameraDob/cameraDobCover.3mf
233.3 x 226.8 x 9.71 mm
EricDobsonianAstridCover.stl x 9
cameraPrimeFocusCollars.stl x 6

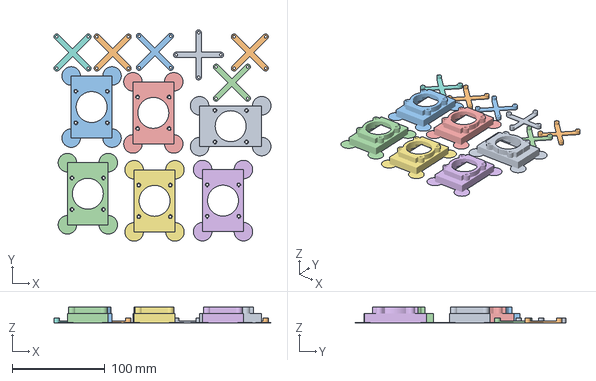
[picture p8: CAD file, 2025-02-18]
3DPrinted/stl/cameraIntegrated/cameraIntegrated.3mf
234.0 x 227.9 x 17.1 mm
AstridCase2.stl_9 x 6
AstridCase2.stl_10 x 6

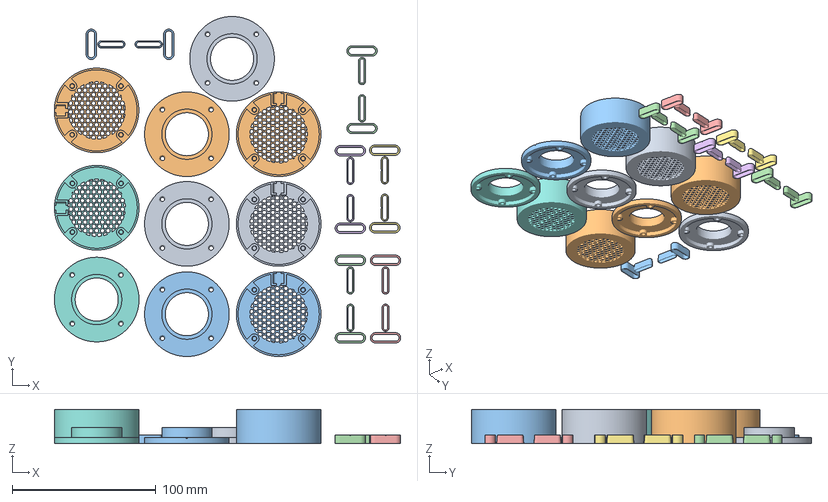
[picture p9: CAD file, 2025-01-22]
3DPrinted/stl/cameraPrimeFocus/cameraPrimeFocus.3mf
241.5 x 236.9 x 23.7 mm
AstridCase2Camera.stl x 4
AstridCase2CameraCollars.stl x 6
AstridCase2Camera.stl_1
AstridCase2Camera.stl_2

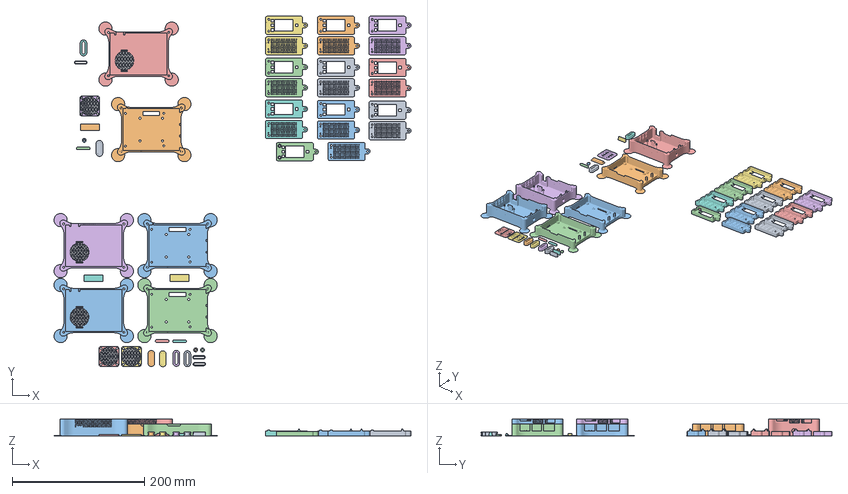
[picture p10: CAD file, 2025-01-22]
3DPrinted/stl/case2/AstridCase2.3mf
538.9 x 529.3 x 25.6 mm
miniDisplayCase.stl x 9
AstridCase2.stl_1 x 3
AstridCase2.stl_2 x 3
AstridCase2.stl_3 x 3
AstridCase2.stl_4 x 3
AstridCase2.stl_5 x 3
AstridCase2.stl_6 x 3
AstridCase2.stl_7 x 3
AstridCase2.stl_8 x 3
AstridCase2.stl_11 x 3
miniDisplayCase.stl_1
miniDisplayCase.stl_2
miniDisplayCase.stl_3
miniDisplayCase.stl_4

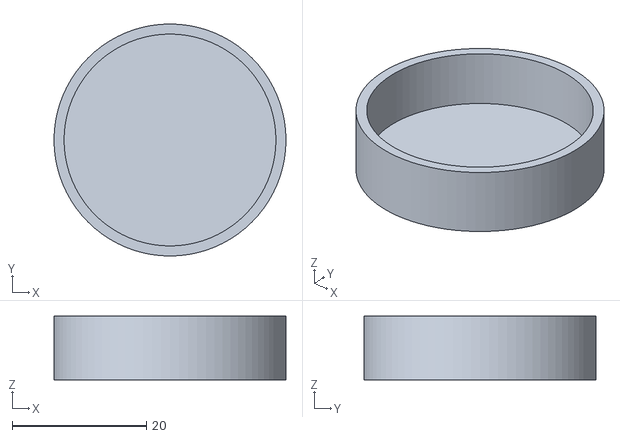
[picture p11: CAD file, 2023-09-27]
3DPrinted/stl/lenscap/LensCap1_25inch.stl
34.6 x 34.6 x 9.50

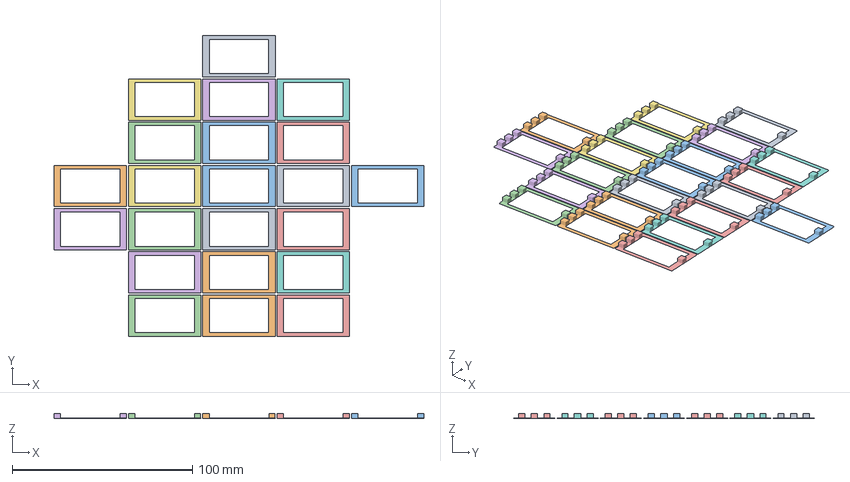
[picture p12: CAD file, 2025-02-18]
3DPrinted/stl/miniDisplayCaseButtons.3mf
205.5 x 167.0 x 2.80 mm
miniDisplayCaseButtons.stl x 22

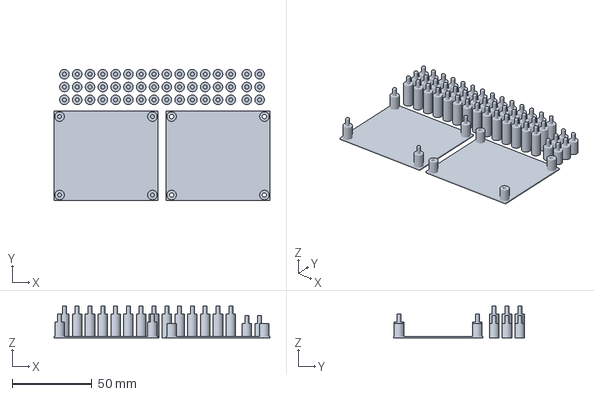
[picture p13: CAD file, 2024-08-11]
3DPrinted/stl/oteStamperCarrier/oteStamperCarrier.3mf
135.0 x 82.0 x 20.0 mm

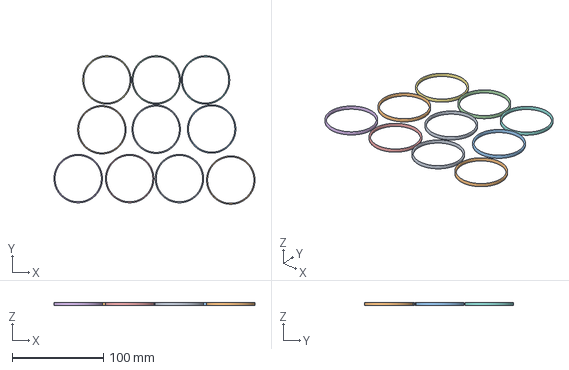
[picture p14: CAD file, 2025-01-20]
3DPrinted/stl/cameraDob/cameraDobRingGromit.3mf
219.9 x 162.6 x 3.00 mm
DobCameraRingGromit.stl x 10

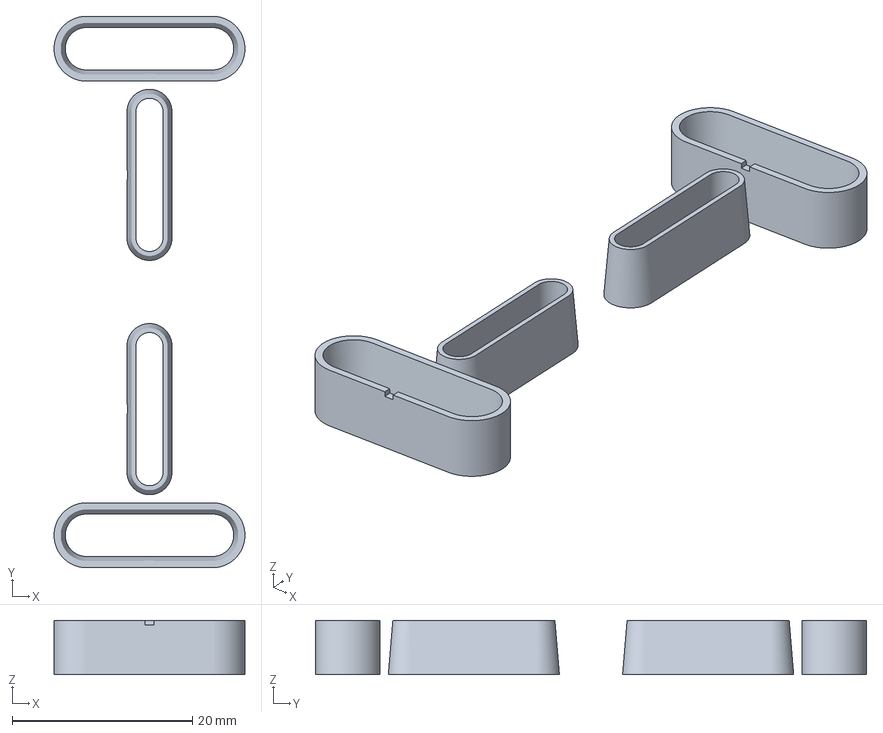
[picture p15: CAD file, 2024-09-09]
3DPrinted/stl/cameraPrimeFocus/cameraPrimeFocusCollars.3mf
21.2 x 61.2 x 6.00 mm

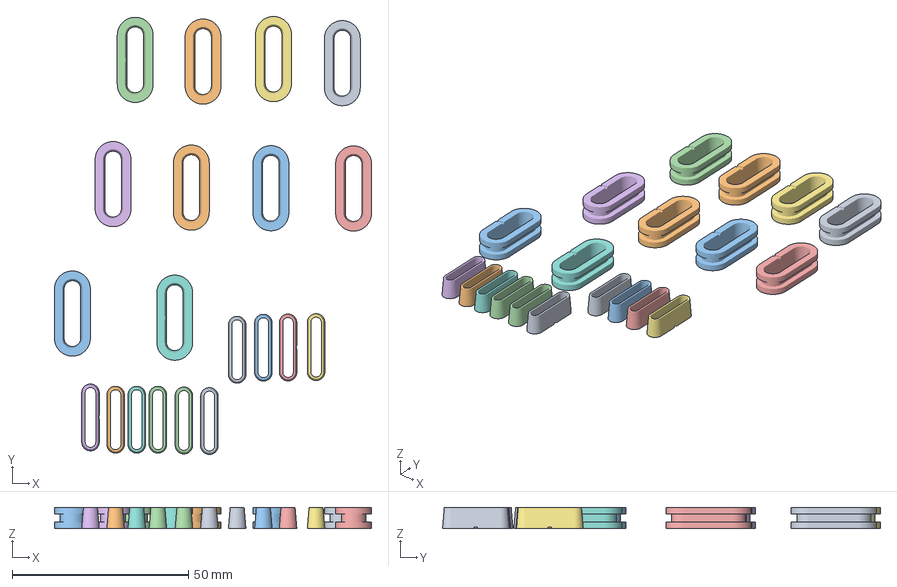
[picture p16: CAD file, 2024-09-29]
3DPrinted/stl/case2/AstridCase2Collars.3mf
90.1 x 124.4 x 6.00 mm
AstridCase2.stl_6 x 10
AstridCase2.stl_7 x 10

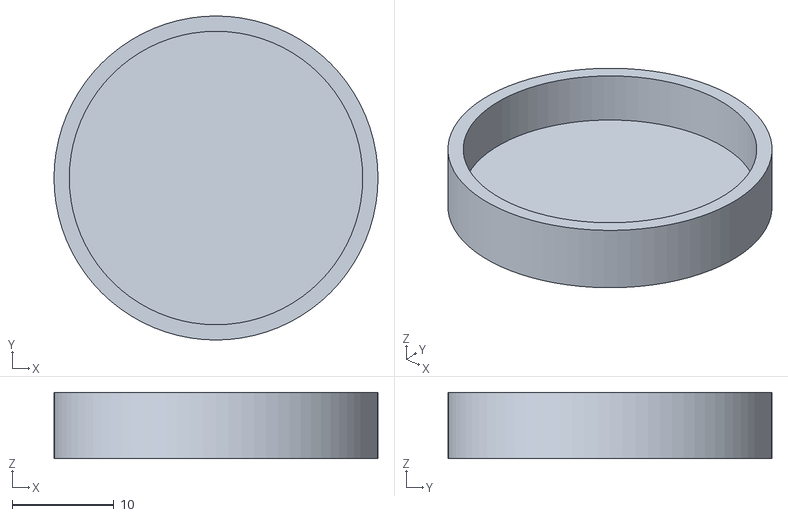
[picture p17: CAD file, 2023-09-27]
3DPrinted/stl/lenscap/LensCapCSMount.stl
31.8 x 31.8 x 6.50

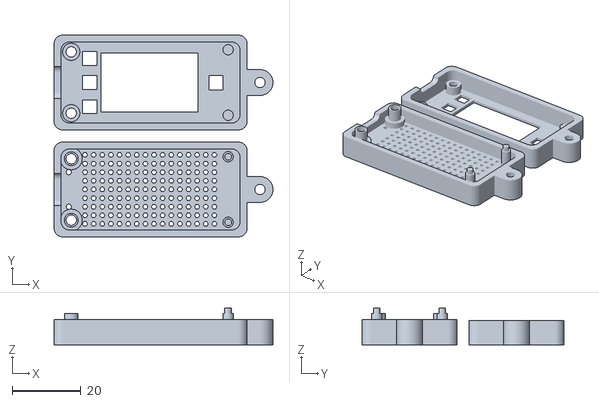
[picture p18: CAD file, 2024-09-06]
3DPrinted/stl/miniDisplayCase.stl
63.5 x 58.5 x 10.6

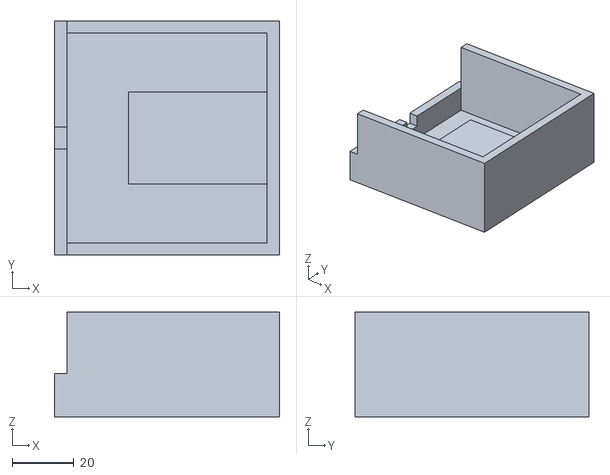
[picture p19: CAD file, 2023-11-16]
3DPrinted/stl/BatteryCover.stl
73.0 x 76.0 x 34.0

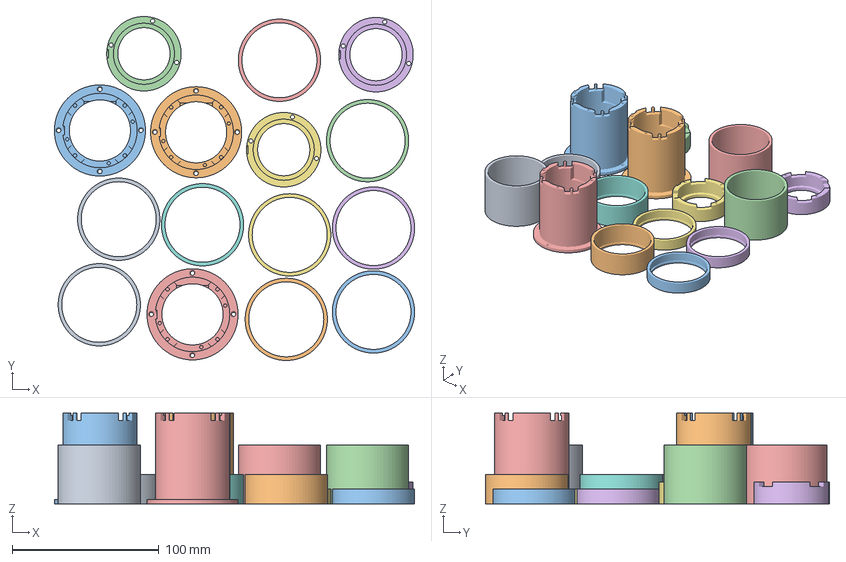
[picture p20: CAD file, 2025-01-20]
3DPrinted/stl/cameraDob/cameraDobHolder.3mf
245.1 x 234.0 x 61.6 mm
DobCameraRings.stl_1 x 3
DobCameraRings.stl_2 x 3
DobCameraRings.stl_3 x 3
DobCameraHolder.stl_1 x 3
DobCameraHolder.stl_2 x 3

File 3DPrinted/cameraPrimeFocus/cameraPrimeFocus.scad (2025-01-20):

// Black ASA Filament
//  Bambu Labs:
//      Print partNum 4 (Plate)
//      
//      Filament Color:  Main: ASA Black, Highlight Only: ASA Green (closer to Turquoise)
//      Drying:          ASA will need drying before use, it comes from Bambu Labs too wet to print well.  
//                         12hrs should be enough at 70C (ASA setting on Creality)
//      AMS Compatible:  Yes (need to make sure descicant is dry in AMS)
//      Plate:           Smooth PEI Plate
//      Bed Temperature: 110C (yes, 10C over)
//      Bed Adhesion:    Bambu Liquid Glue
//      Support:         Yes
//      Infill:          25%
//      Bambu Studio:    After import, change highlight color for ring to Green

//      Print partNum 3 (Flex Collars)
//      
//      Filament Color:  Main: ASA Black
//      Drying:          ASA will need drying before use, it comes from Bambu Labs too wet to print well.  
//                         12hrs should be enough at 70C (ASA setting on Creality)
//      AMS Compatible:  Yes (need to make sure descicant is dry in AMS)
//      Plate:           Smooth PEI Plate
//      Bed Temperature: 110C (yes, 10C over)
//      Bed Adhesion:    Bambu Liquid Glue
//      Support:         No
//      Infill:          100%

// Post Processing:
//      - Remove support
//      - Wash adhesive off parts
//      - Dry parts
//      - Insert 4 heat inserts in bottom case, with drill press / soldering iron/ supplied heat tool, just below surface
//        (Uses 4 x   M2.5x3.5x4 Hanglife Inserts HLTI-M2.5-SET01)
//      - Remove white haze on cases where there was plate contact with heat gun


partNum                             = 2;        // 0 = All, 1 = Bottom, 2 = Top, 3 = Flex Collars, 4 = Plate


caseThickness                       = 1.2;

caseInnerDiameter                   = 56.57;
caseOuterDiameter                   = caseInnerDiameter + caseThickness*2;

pcbDimensions                       = [39.1, 39.1, 1.60];

cableWidth                          = 17.0;
cableThickness                      = 3.0;
pcbConnectorHeight                  = 3.4;
caseMiddleHeight                    = pcbDimensions[2] + pcbConnectorHeight + cableWidth + 0.5;

pcbSupportWidth                     = 6.4;
pcbSupportWidthRadius               = 24.0;

insertHoleDiameter                  = 3.2 + 0.2;
insertHoleDepth                     = 5.0;
boltHoleDiameter                    = 2.6 + 0.3;
boltHeadDiameter                    = 4.5 + 0.2;
boltHeadHeight                      = 1.6;

cameraFlangeInnerDiameter           = 30.0;
cameraFlangeHeight                  = 11.0;
cameraInternalDiameter              = 51.0;
cameraVoidHeight                    = 3.0;

markerDepth                         = 0.8;
markerWidth                         = 1.2;
markerLength                        = 5.0;

fanVentDiameter                     = 40.0;

highlightRingOuterDiameter          = caseOuterDiameter - 7.0;
highlightRingInnerDiameter          = highlightRingOuterDiameter - 5.0;
highlightRingThickness              = 0.8;

flexCollarDepth                     = 6.0;
flexCollarSurroundThickness         = 1.0;

flexThickness                       = 0.7;  // The overall thickness of the tube as it ships (both sides)

flexOuterLength                     = cableWidth + flexCollarSurroundThickness * 2;
flexOuterWidth1                     = cableThickness + flexCollarSurroundThickness * 2;
flexOuterWidth2                     = flexOuterWidth1 - 1.0;

flexOuterClampWidth1                = flexOuterWidth1 + flexThickness;
flexOuterClampWidth2                 = flexOuterWidth2 + flexThickness;

flexOuterClampOuterBorder           = 1.5;
flexOuterClampInnerLength           = flexOuterLength + flexThickness;
flexOuterClampOuterWidth            = flexOuterClampWidth1 + flexOuterClampOuterBorder;
flexOuterClampOuterLength           = flexOuterLength + flexThickness + flexOuterClampOuterBorder;

flexCollarVoidLength                = flexOuterClampOuterLength + 1.8;
flexCollarVoidWidth                 = flexOuterClampOuterWidth + 0.5;
flexCollarVoidThickness             = flexCollarDepth + 0.75;
flexCollarMarkerWidth               = 1.0;

collarVoidOffsetZ                   = 12.0;

flexCollarBlockDimensions           = [10.7, flexCollarVoidThickness + 1.75, caseMiddleHeight];
flexCollarBlockOffsetY              = -1.0;

manifoldCorrection                  = 0.01;
manifoldCorrection2                 = manifoldCorrection * 2;

$fn                                 = 160;



if (partNum == 0 || partNum == 1 )
{
    rotate( [0, 180, 0] )
        caseBottom();
}

if ( partNum == 0 || partNum == 2 )
{
    caseMiddle();
    caseTop();
}

if ( partNum == 0 || partNum == 3 )
{
    translate( [32, 13, 0] )
        rotate( [0, 0, 90] )
            flexCollar1();
    translate( [32, -13, 0] )
        rotate( [0, 0, 90] )
            flexCollar1();

    translate( [32, 27, 0] )
        flexCollar2();
    translate( [32, -27, 0] )
            flexCollar2();
}

if ( partNum == 4 )
{
    caseBottom();
    translate( [caseOuterDiameter + 5.0, 0, caseMiddleHeight + caseThickness] )
        rotate( [0, 180, 0] )
        {
            caseMiddle();
            caseTop();
        }
}






module flexCollar1()
{
    difference()
    {
        lozengeConical(flexOuterLength, flexOuterWidth1, flexOuterWidth2, flexCollarDepth);
        translate( [0, 0, -manifoldCorrection] )
            lozenge(cableWidth, cableThickness, flexCollarDepth + manifoldCorrection2);
            
        // Marker
        translate( [-flexCollarMarkerWidth/2, 0, -manifoldCorrection] )
            cube( [flexCollarMarkerWidth, flexOuterWidth1, flexCollarMarkerWidth/2 + manifoldCorrection] );
    }
}



module flexCollar2()
{
    translate( [0, 0, flexCollarDepth] )
        rotate( [180,0, 0] )
            difference()
            {
                lozenge(flexOuterClampOuterLength, flexOuterClampOuterWidth, flexCollarDepth);
                translate( [0, 0, -manifoldCorrection] )
                    lozengeConical(flexOuterClampInnerLength, flexOuterClampWidth1 + manifoldCorrection, flexOuterClampWidth2, flexCollarDepth + manifoldCorrection2);
                
                // Marker
                translate( [-flexCollarMarkerWidth/2, 0, -manifoldCorrection] )
                    cube( [flexCollarMarkerWidth, flexOuterClampOuterWidth + manifoldCorrection, flexCollarMarkerWidth/2 + manifoldCorrection] );
            }
}



module caseBottom()
{
    difference()
    {
        union()
        {
            donut(caseOuterDiameter, cameraInternalDiameter, cameraVoidHeight);
            translate( [0, 0, cameraVoidHeight] )
                donut(caseOuterDiameter, cameraFlangeInnerDiameter, caseThickness);

            translate( [0, 0, cameraVoidHeight] )
                donut( cameraFlangeInnerDiameter + 5.0, cameraFlangeInnerDiameter, cameraFlangeHeight - cameraVoidHeight);
        
            // PCB Supports
            for ( r = [45, 135, 225, 315] )
                rotate( [0, 0, r] )
                    translate( [0, pcbSupportWidthRadius, 0] )
                    {
                        difference()
                        {
                            union()
                            {
                                // The support
                                cylinder(d = pcbSupportWidth, h = cameraVoidHeight);
                                translate( [-pcbSupportWidth/2, 0, 0] )
                                    cube( [pcbSupportWidth, caseInnerDiameter/2 - pcbSupportWidthRadius, cameraVoidHeight] );
                            }
                       }
                    }
        }
            
        // Bolt Holes
        for ( r = [45, 135, 225, 315] )
            rotate( [0, 0, r] )
                translate( [0, pcbSupportWidthRadius, 0] )
                {
                    // Bolt hole
                    translate( [0, 0, -manifoldCorrection] )
                        cylinder(d = boltHoleDiameter, h = cameraVoidHeight + caseThickness + manifoldCorrection2); 
                        
                    // Bolt head hole
                    translate( [0, 0, cameraVoidHeight + caseThickness - boltHeadHeight] )
                        cylinder(d2=boltHeadDiameter, d1=boltHoleDiameter, h=boltHeadHeight + manifoldCorrection);
                }
                
         // Marker
         rotate( [0, 0, 180] )
            translate( [-markerWidth/2, caseOuterDiameter/2 - markerLength + manifoldCorrection, cameraVoidHeight + caseThickness - markerDepth] )
                cube( [markerWidth, markerLength, markerDepth + manifoldCorrection] );
     }
}
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

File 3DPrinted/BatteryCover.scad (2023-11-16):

// Copyright: ChasinSpin, 2023
// License: MIT License

// Print 15% Fill No Support


plateBorderThickness            = 4;
plateBorderHeightShort          = plateBorderThickness + 10;
plateBorderHeightTall           = plateBorderHeightShort + 20;
plateBorderHeightExtra          = 20;
batteryCoverPlateDimensions     = [65, 68, 3];

velcroBlock                     = [45, 30, plateBorderHeightShort];

manifoldCorrection              = 0.01;

cableChannel                    = [plateBorderThickness + manifoldCorrection * 2, 7, 5];



batteryCover();



module batteryCover()
{
    difference()
    {
        batteryCover2();
        
        translate( [-batteryCoverPlateDimensions[0]/2 - plateBorderThickness/2, 0, plateBorderHeightShort - cableChannel[2]/2 + manifoldCorrection] )
            cube( cableChannel, center = true);
    }
}



module batteryCover2()
{
    translate( [0, 0, batteryCoverPlateDimensions[2] / 2] )
        cube(batteryCoverPlateDimensions, center = true);
    
        sideX(1.0, batteryCoverPlateDimensions[1] + plateBorderThickness*2, plateBorderHeightTall);
        sideX(-1.0, batteryCoverPlateDimensions[1] + plateBorderThickness*2, plateBorderHeightShort);
        sideY(1.0, batteryCoverPlateDimensions[0], plateBorderHeightTall);
        sideY(-1.0, batteryCoverPlateDimensions[0], plateBorderHeightTall);
   
   translate( [batteryCoverPlateDimensions[0] / 2 - velcroBlock[0]/2, 0, velcroBlock[2]/2] )
        cube( velcroBlock, center = true ); 
}


module sideY(plusMinus, length, height)
{
    translate( [0, 0, height/2] )
        translate( [0, plusMinus * ((plateBorderThickness + batteryCoverPlateDimensions[1])/2), 0] )
            cube([length, plateBorderThickness, height], center = true);
}


module sideX(plusMinus, length, height)
{
    translate( [0, 0, height/2] )
        translate( [plusMinus * ((plateBorderThickness + batteryCoverPlateDimensions[0])/2), 0, 0] )
            cube([plateBorderThickness, length, height], center = true);
}

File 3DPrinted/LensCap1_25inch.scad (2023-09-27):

innerDiameter       = 31.6;
height              = 8;
thickness           = 1.5;
manifoldCorrection  = 0.01;


$fn = 80;

rotate( [0, 180, 0] )
    difference()
    {
        cylinder(d=innerDiameter + thickness * 2, h = height + thickness);
        translate( [0, 0, -manifoldCorrection] )
            cylinder(d=innerDiameter, h = height);
    }

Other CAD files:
3DPrinted/stl/cameraDob/cameraDobRings.stl
3DPrinted/LensCapCSMount.scad
3DPrinted/cameraDob/cameraDob.scad
3DPrinted/case2/AstridCase2.scad
3DPrinted/case2/AstridCase2Camera.scad
3DPrinted/case2/polyround.scad
3DPrinted/miniDisplay/miniDisplayCase.scad
3DPrinted/oteStamperCarrier/oteStamperCarrier.scad
3DPrinted/stl/cameraDob/cameraDobCover.stl
3DPrinted/stl/cameraDob/cameraDobHolder.stl
3DPrinted/stl/cameraDob/cameraDobRingGromit.stl
3DPrinted/stl/cameraPrimeFocus/cameraPrimeFocus.stl
3DPrinted/stl/cameraPrimeFocus/cameraPrimeFocusCollars.stl
3DPrinted/stl/case2/AstridCase2.stl
3DPrinted/stl/miniDisplayCaseButtons.stl
3DPrinted/stl/oteStamperCarrier/oteStamperCarrier.stl

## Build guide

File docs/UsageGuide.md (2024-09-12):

# Usage Guide

* [Power](#power)
* [Startup](#startup)
* [Windows Zeroconf](#windows-zeroconf)
* [Connectivity WiFi and Hotspot](#connectivity-wifi-and-hotspot)
* [First Light](#first-light)
* [Connect Via VNC](#connect-via-vnc)
* [Internet Access](#internet-access)
* [Upgrade](#upgrades)
* [Focal Reducers And Length](#focal-reducers-and-length)
* [Multiple Astrids](#multiple-astrids)
* [Our Setup](#our-setup)
* [SSH And SFTP](#ssh-and-sftp)
* [Prepointing](#prepointing)
* [Auto Record and OWCloud](#auto-record-and-owcloud)
* [Player](#player)
* [Light Curve Analysis](#light-curve-analysis)
* [Occult4 Searches](#occult4-searches)

## Power

Good power is critical to Astrid. Please see [Power Supply](PowerSupply.md) for more information.

## Startup

* Insert microSD Card into ASTRID.  Note the contacts on the card face towards the logo on ASTRID.  Be careful to insert it into the socket (*not beside it*).
* Insert USB Flash drive **in BLUE USB port (USB 3.1)** on ASTRID.  Note the black USB ports are slower USB 2.0.
* Connect GPS Antenna (ensure it has a clear view of the sky, see [Troubleshooting](Troubleshooting.md) for GPS Poor Reception for more information.
* Connect mount if using to any remaining USB port.
* Connect [Astrid Mini Display](MiniDisplay.md) to any remaining USB port.
* Power mount on.
* Power ASTRID on.
* **ALWAYS REMEMBER TO SHUTDOWN ASTRID AND WAIT 15 SECONDS AFTER GREEN LIGHT STOPS FLASHING ON THE SIDE BEFORE REMOVING POWER TO AVOID SD CARD AND USB FLASH DRIVE CORRUPTION.**
* Keep sensor clean.  The best way to do this is to use a camera puffer and keep the sensor covered at all times, either with a cap or a focal reducer.  If you need to clean the sensor, use a regular sensor cleaning kit.  As with regular astrophotography, a dirty sensor is indicated by sharply focused defects on the image (*less defined defects are dirt on the lens or telescope*).
* [Connect via VNC](#connect-via-vnc)

## mDns/Bonjour/Windows Zeroconf

**Note: This is important for older versions of Android/Windows Tablets and Windows Computers**

Zeroconf (also known as mDNS and Bonjour) is a way to save users from entering IP addresses (e.g. 10.0.0.5) and being able to use name.local instead: [https://en.wikipedia.org/wiki/Zero-configuration_networking
](https://en.wikipedia.org/wiki/Zero-configuration_networking)

Ordinarily, this means you can use one address to connect to Astrid despite being on different networks.  On Mac and iOS, this works fine; however, on some Windows and Android devices, zeroconf is broken, and Astrid will require an IP address.

When Astrid is advertising its own Hotspot Network (typically on mobile deployments), the IP address is likely to be 10.0.0.5 as Astrid is generating that network. When connected to your home network, it will be whatever DHCP address your home network assigned.  This information is displayed on the [Astrid Mini Display](MiniDisplay.md).

## Connectivity WiFi and Hotspot

Astrid can run as it's own Access Point WiFi Hotspot or connect to a WiFi Router (e.g. a Home WiFi Network), these are called Hotspot and WiFi respectively.

When Astrid starts up, it is always in Hotspot mode and can be accessed as:

| Setting | Value |
| --- | --- |
| Wi-Fi SSID | AstridHotspot |
| Wi-Fi Password | iotaiota |
| Hostname | astrid.local (or 10.0.0.5) |

In Hotspot mode, Astrid does not have access to the internet so is unable to be upgraded or download plate solve files, astronomy tables or search for astronomical objects that require online access.

This would be the typical scenario when observing in the field where internet access wasn't available.

Sometimes (near hotels, houses etc.), there can be many wifi networks and the AstridHotspot may not be listed as your WiFi network list maybe short, just enter the Hotspot name as "Other" etc.

To connect to the internet, you need to connect to a Wifi Router (for example a home router).  There are 2 ways to do this:

* [Astrid Mini Display](MiniDisplay.md) (connect over USB and press one of the 3 buttons)
* Connect your device to the Hotspot network, VNC in, and double tap/click "WiFi Connect" on the desktop. 

To manage Wi-Fi connections (network names/passwords), these can be configured via the "Wifi Setup" icon on Astrid's desktop under "Astrid Tools".

If you are ever having problems finding Astrid, then look on your list of networks to see if AstridHotspot is visible and connect to it.  Otherwise you'll find it on your WiFi Network if you switched to that.  Use the [Mini Display](MiniDisplay.md) to determine where your network is and the status it has.

Astrid can also handle multiple networks, however multiple networks at the same location should be avoided to prevent confusion as to which network you are connecting too.  But if you have 2 places (say your home and an astronomy club), then there's a case for entering multiple networks.

The ethernet port flashes alternate Green/Yellow when connected to a known WiFi Network and is solid Green/Yellow when Astrid is generating it's own Wifi Hotspot.

##### If you are hot-spotting through a phone to connect to Astrid, be aware that some cellular plans limit throughput through the phones hotspot and may result in very slow VNC response.

### Ethernet (wired connection)

***Note: Astrid over internet is not supported***

Astrid also has an ethernet port. Plug in your ethernet connection and [Mini Display](MiniDisplay.md) will indiciate the IP address and hostname to VNC too.

Now connect over VNC, run a terminal and type:

> sudo systemctl stop dnsmasq.service

To set back to the normal behaviour, shutdown Astrid (i.e. power off), remove the ethernet cable and power on Astrid.

## First Light

When Astrid is started for the first time, no Wi-Fi networks are configured and it will default to 

| | |
| --- | --- |
| Wi-Fi SSID | AstridHotspot |
| Wi-Fi Password | iotaiota |
| Hostname | astrid.local (or 10.0.0.5) |

To connect, you will need to connect to this Wi-Fi network and you will need to use VNC, see [Connect Via VNC](#connect-via-vnc).  Once connected, you can use the "Wi-Fi Setup" icon on your desktop to add Wi-Fi networks you require.

When using Astrid for the first time, or with a new telescope / focal reducer configuration, it's important to determine the focal length and configure the [platesolver](Platesolver.md).  See [Platesolver](Platesolver.md) for more information.  Once plate solving is working, then you can Polar Align (if an equatorial mount) and then goto a bright star and focus precisely with a Bahtinov mask.

## Connect Via VNC

Connection to the Astrid app and desktop is through a VNC Client over Wi-Fi.  You can access Astrid with the following devices:

* Laptop (macOS, Windows, Linux, Raspberry Pi)
* Tablet/iPad (iOS or Android)
* Phone (iOS or Android) *small screen size = poor user experience*

For convenience in mobility and user experience, whilst moving around the telescope, we use an iPad with a larger screen size.

The VNC Client we recommend is the free [RealVNC VNC Viewer](https://www.realvnc.com/en/connect/download/viewer/) (note you may be prompted for a free trial, but it's not necessary).  Other VNC clients may or may not work.

**IMPORTANT: There are 2 versions of RealVNC; RealVNC Viewer and RealVNC Connect. RealVNC Connect is a paid-for product, and the website and product itself are designed to pull you into purchasing the paid product by mistake. Be sure to download RealVNC Viewer using the link above.**

**After installing you'll be presented with a screen asking you to sign in and send anonymous usage data. Uncheck the send anonymous usage data checkbox, and click "Use RealVNC Viewer without signing in".  Never click the "Sign In" button.**

When setting up the client, we suggest you use "astrid.local" for the hostname instead of an IP address.  As you may access Astrid on different networks or its Access Point, using "astrid.local" instead of an IP address removes the need to have a different connection for each network. However if you have mDNS/Bonjour issues, then you may need to use the IP address.  [Astrid Mini Display](MiniDisplay.md) lists both options.

##### Please note that it may take 1-2 mins after connection for "astrid.local" to be visible on the network.
	
To add Astrid to VNC Viewer:

1. Click on the "+" button
2. Address: astrid.local  (or 10.0.0.5 on windows)
3. Name: astrid.local  (or 10.0.0.5 on windows)
4. Picture Quality: Automatic
5. Interaction: Touch Panel (Tablet) or Mouse (Computer)
6. Update desktop preview: On or Off
7. Click Done

The username / password to login to Astrid when prompted via VNC:

| | |
| --- | --- |
| Login | pi |
| Password | iota |

### Entering Text Into Astrid

Text in VNC Viewer is entered by tapping the keyboard icon.  When entering text, be aware that you must **ALWAYS** press "Return" or "Enter (some computers)"  after the text has been entered so that the text is accepted.

### Powering Off

Quitting or closing the VNC connection, does not shut down Astrid.  
**ALWAYS REMEMBER TO SHUTDOWN ASTRID AND WAIT 15 SECONDS AFTER GREEN LIGHT STOPS FLASHING ON THE SIDE BEFORE REMOVING POWER TO AVOID SD CARD AND USB FLASH DRIVE CORRUPTION.**

## Internet Access

Astrid is designed for both offline and online use.  Astrid currently does not contain star catalogs, therefore to find a target that is not already saved, it uses Simbad which requires internet access.

Target objects can either be entered via Astrid for offline use (*custom Objects or Save from Simbad*) or copied onto the corresponding objects.json(*custom objects*) or occultations.json on the USB Drive.

## Upgrades

Astrid uses the Rapid Development model and should be connected to the internet and upgraded frequently.

## Focal Reducers And Length

Focal length will depend on the focal reducers used and the distance the camera sensor is from a lens or the telescope.  The typical requirement of an accurate back focus may not be necessary with ASTRID due to the smaller field of view.
 	
If using the IOTA 0.5X Focal Reducer, be aware that you may need to insert spacer rings to get the maximum focal reduction.  Most setups you 2 or 1 5mm rings.
 	
[IOTA Focal Reducer](https://occultations.org/night-eagle-2-pro-astro-edition-ordering-page/)

## Multiple Astrids

Each Astrid should have a unique hostname to avoid confusion about which one you are connecting to.

You can change the hostname as follows:

1. Make sure only 1 Astrid is on and connect to it via VNC.
2. Double click/tap the terminal icon top left (black rectangle with >\_)
3. Type:    sudo raspi-config
4. Choose: 1. System Options	(use cursor arrows, tab and enter to navigate)
5. Choose S4 Hostname
6. Enter the hostname you require (do not add .local)
7. Select OK and then Finish
8. When prompted to reboot, select Yes

Now update your VNC Address to point to the new hostname.local

## Our Setup

We use an iPad (with brightness turned down so that it lasts the night) to access Astrid.  This gives us the ability to easily move around the scope and no requirement to bring a table to place a laptop on, or bring power for it.

For Wi-Fi we have the following configured in Astrid:

* Home Network
* AC750 Tp-Link Travel Router (for Mobile deployments)

Astrid then automatically connects to our home network, or the travel router when we're mobile.  If we need a Simbad lookup, then we just enable the hotspot on the phone, and after a few seconds, the travel router connects to the hotspot automatically and Astrid has internet for object searches.

By no means is the Travel Router required, we just find it convenient for all situations (good cellular, poor cellular), as well as multiple connections and increased Wi-Fi range.  This particular travel router is low-powered and will easily run off a small 10Ah USB power pack.

For telescope/mount (focal length 732mm):

* Celestron EdgeHD 9.25"
* 0.7X Celstron Focal Reducer
* 0.5X IOTA Reducer (Ted Blank)
* ZWO AM5 Mount
	* Dakota 12V Lithium Battery (54Ah, but overkill, 10Ah-23Ah is sufficient)

We also have some Astrids configured for standalone in the field (Hotspot and no Router).

## SSH And SFTP

To ssh or sftp to Astrid:

* ssh pi@astrid.local
* sftp pi@astrid.local

The password is: iota

## Prepointing

Astrid has the ability to automatically calculate prepointing positions without needing star charts or setup at a specific time, such that once
setup, the star drifts into view and recording starts automatically.

Prepointing is useful in certain situations, for example:

* Unattended single or multiple setups
* Setups with no Goto / Tracking (i.e. statically pointed)
* Rough polar alignment

For the best success with prepointing:

* Short focal lengths ( <500mm )
* Short occultations

To prepoint, click the Prepoint button when Occultations is selected in Object.  The process is iterative, so click Photo, Solve, Sync and then adjust the mount and repeat until the error is minimal, the following metrics reported are useful:

Pos Error(%FOV) = The positional error in percentage of the height of the FOV for the sensor.  This is another way of quantifying the position error displayed in the arrows.  I.E. I have this much error, am I close enough to the center?  It's suggested to adjust the mount until 10% or better is reached.  At 50%, it is half the field of view, and that will mean that the star is at the edge of the frame.

FOV Size = Size of the Field of View

Drift Time 75% FOV: This is the number of minutes it takes to drift across 75% of the FOV Height.  The occultation event should fit within this time.

When prepointing is adjusted, then the Auto Record button can be pushed to auto record when the event begins.

## Auto Record and OWCloud

Enter your events into OWCloud, sync to Astrid and use Auto Record.  If you do this, it removes the chances for error and will setup the ideal recording time for binary asteroid and binary star discovery without wasting space on your USB drive.

## Player

Astrid Player (available on the desktop) can be used to load an Astrid Recording, view the occultation, and also Plate Solve and mark the target.  The plate solved image can then be saved as a Fits Finder and loaded into PyOTE to assist with locating the target in PyOTE.

## Light Curve Analysis

The recommended tool for analyzing light curves from Astrid is Bob Andersons awesome [PyMovie](https://pypi.org/project/pymovie/) and [PyOTE](https://pypi.org/project/pyote/)

Starting from version 3.9.4 of PyMovie, the RAVF Video format used by Astrid is natively supported.

Other light curve analyzers currently do not support the RAVF video format.  Astrid Player can be used to convert to fits format for other analyzers.

## Occult4 Searches

Astrid supports the ability to fast search through Occult Element files generated by Occult4.  These files are .xml files in the following format:

	<Occultations>
  		<Event>
    		<Elements>JPL#47+INTG:2023-Dec-05,0.26,2024,1,4,22.964245,0.079998,0.530961,-6.425429,0.968085,-0.000416,-0.000204,0.000001,0.000000</Elements>
   			<Earth>20.9283,24.8261,-163.23,-22.69,False</Earth>
    		<Star>UCAC4 575-037911,7.27148376,24.8686687,13.38,13.14,12.75,0.0,0,,7.29621845,24.8261384,4.55,4.48,0,0,0</Star>
    		<Object>22268,1981 EJ26,17.67,3.010,1.3150,0,0,-3.156,6.47,,0.2,0</Object>
			<Orbit>0,120.9367,2024,1,5,298.2050,35.0191,1.5547,0.12887,2.13202,1.85727,15.04,5.0,0.15</Orbit>
    		<Errors>1.215,0.0190,0.0005,97,0.0190,Known errors,1.05,0,0,0</Errors>
    		<ID>20240104_037911,60308.83</ID>
  		</Event>
  		<Event>
    		<Elements>JPL#51+INTG:2023-Dec-05,0.36,2024,1,4,22.984674,0.049755,0.572965,-6.623967,0.575224,-0.000015,0.000333,0.000001,0.000000</Elements>
    		<Earth>16.2929,19.4626,-163.54,-22.69,False</Earth>
    		<Star>UCAC4 548-036348,6.98381004,19.4952800,15.09,14.74,14.24,0.0,0,,7.00767580,19.4625705,2.64,2.69,0,0,0</Star>
    		<Object>10456,Anechka,17.29,4.207,1.4969,0,0,-2.751,3.38,,0.4,0</Object>
    		<Orbit>0,165.6603,2024,1,5,85.3013,211.7375,2.0516,0.04348,2.37880,2.27538,14.26,5.0,0.15</Orbit>
    		<Errors>1.253,0.0123,0.0009,96,0.0123,Known errors,1.00,0,0,0</Errors>
    		<ID>20240104_036348,60308.83</ID>
  		</Event>
  		...
	</Occultations>

To integrate one of these files into Astrid, please do the following:

1. Rename it to something like MyName\_2024\_Asteroids\_Jan.xml or MyName\_2024\_Asteroids.xml
2. If there are a significant number of events (e.g. more than 20,000 - 40,000), it might be advisable to split the events into months.  Although Astrid will handle many more events than this, your search time will be faster
3. With internet connected, under Object, click Add and "Search Occelmnt XML Lists" and follow the prompts.  This will download and install Steve Prestons occultation predictions and create the folder required for the this feature
4. On a desktop computer, copy your xml file of events into the predictions folder on the Astrid USB Drive
5. Place USB Drive back in Astrid, and under "Object", click "Add" and "Search Occelment XML Lists" and choose your xml list which should be visible now.

The predictions folder and/or your xml file can be copied between USB Drives or to the USB Drive if you are updating.

Please note that clicking on the event to link to OWCloud will only work with IOTA-tagged events.  This is a limitation of OWCloud, and there are no plans for OWCloud to implement linking of non-IOTA tagged events at this time.

Once an event is identified, hit the "+" to add the event to Astrid.
The Occult Element format does not provide an error time in it's specification, so Astrid defaults the error to 0.001s, please determine the error via other means and update so the start/end times are calculated correctly automatically for the event.

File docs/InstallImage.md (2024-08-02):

# Install From Astrid Image
	
## Restoring Image

NOTE: These instructions were updated on August 1st 2024, please use the new image.

The image, althought available, due to costs involved in hosting, is only available to people who have Astrids.  It can be obtained by joining the IOTA forum: https://occultations.org/community/forums/ and asking, it will be sent to you privately.
		
Use [Raspberry Pi Imager](https://www.raspberrypi.com/software/) to restore image (e.g. 2024-08-01-astrid.img.xz).

* Operating System: Choose "Use Custom" and locate 2024-08-01-astrid.img.xz 

* Storage: Choose the SD Card you are writing to **IMPORTANT:** Make sure you have selected the correct SD Card (i.e. don't overwrite other drives by mistake).

* In Settings (Advanced options), uncheck:
	* Set hostname
	* Enable SSH
	* Set username and password
	* Configure wireless LAN
	* Set locale settings
* Click Write and wait for the writing and verification to finish

* Remove SD Card

Insert card into Raspberry Pi and boot - see [Startup in UsageGuide](UsageGuide.md#Startup).  Wait for 5-10mins for card to be resized.  When completed, connect via WiFi from a tablet or PC to:

| | |
| --- | --- |
| Wifi SSID | AstridHotspot |
| Wifi Password | iotaiota |
| Hostname | astrid.local (or 10.0.0.5 on windows) |

Note: It can take a few mins for astrid.local to be pushed to the device you are connecting from and may result in Hostname not found.

## Initial Configuration Of Astrid

Connect via VNC using the above connection details.

See the following sections in the [Usage Guide](UsageGuide.md):

* [First Light](UsageGuide.md#first-light)
* [Connect Via VNC](UsageGuide.md#connect-via-vnc)
* [Internet Access Optional](UsageGuide.md#internet-access-optional)

### Change Hostname

If you have multiple Astrids, or someone else has an Astrid near you, confusion about which one you are connecting to can occur, and each Astrid requires a unique network and name.

##### Wifi Hotspot Change	

1. Run WifiSetup on the desktop (under Astrid Tools), and change the access points SSID and password (option 7) to:

		SSID: AstridXHotspot  (where X is a unique number for your astrid)
		Password: iotaiota
	
2.	Then use Option 5 to add your home network.
	
##### Hostname Change

* Raspberry Pi Symbol (top left) / Preferences / Raspberry Pi Configuration
	
* Under System, click on Change Hostname and set to:
		astridX 	(where X is a unique number for your astrid)
		
* Click OK and Reboot

### Upgrade Astrid To Latest

Connect to Astrid using the **NEW** network credentials and hostname:
		
* Run Astrid Upgrade on the desktop
* Reboot when prompted

### Testing Astrid

1. Connect USB Drive

2.	Connect GPS Antenna

3. Run Astrid App and choose Simulator
	
4. Check all Status buttons are Green, if not green, then wait for GPS satellites to be found (can take 20min).
	
5. If GPS/Timing/Acquisition are Green and Site is Red or Yellow, click on Site and Update Site and Mount
	
6. Switch Task to OTE Video and press the record button for 5 seconds, and then press again to stop.  All status buttons should still be green.
If not, click on the button to discover the issue.

### IOTA Build Instructions

#### To save time:

* Batch Build: MiniDisplays (install software too and test)
* Batch Build: USB Drives (format in Astrid and copy files to drive)
* Batch Test: GPS Antennas (get good signal with reference antenna, then swap in antennas to test, wait for at least 1 satellite and mark as tested... can likely be left coiled during test)
* Batch Write: SD Cards

#### Astrid build/testing:

* Create SD Card from image using the instructions above and image: 2024-08-01-astrid-ted.img.xz (DO NOT REDISTRIBUTE THIS IMAGE)
* Plug in USB Drive, GPS Antenna and MiniDisplay (ensure MiniDisplay has software installed) into Pi
* Insert the card into Raspberry Pi and startup (wait 5-10mins for card to be resized)
* Use MiniDisplay to switch to home network
* Connect via home network to astrid.local
* Start terminal and type: ./astrid/scripts/iotaconfigure.sh  and follow instructions
* After reboot, start astrid and choose Simulator
* Check all status buttons are green, if not wait for GPS satellites to be found (can take 20min in less than ideal conditions)
* Switch task to OTE Video and press record, then 5 seconds later, press stop.  All status buttons should still be green.
* From terminal, type: ~/astrid/scripts/cleanship.sh
* Remove power after 15 seconds
* Ship Astrid

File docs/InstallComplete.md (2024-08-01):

# Raspberry Pi Complete Installation Instructions
	
Important, we use Bullseye here due to the PiCamera2 Library requirement.

## Install Raspberry Pi Image
	Install 2023-05-03-raspios-bullseye-armhf.img.xz: Raspberry Pi OS with desktop 
	(32bit Bullseye image) using  Raspberry Pi Imager with the following settings:
	
		Hostname: astrid.local
		Enable SSH: Use password authentication
		Set username and password:
			Username: pi
			Password: iota
		Configure wireless LAN:
			SSID: 
			Password:
			Wireless LAN country: US
		Set local settings:
			Time zone: America/Edmonton
			Keyboard layout: us
				
	Boot SD Card in Raspberry Pi, when booted:
		ssh pi@astrid.local
		
## Update image (DO NOT USE, for future reference)
		
		# DISABLED ON 2023-05-03 Bullseye Release DO NOT USE
		# sudo apt update			# If this gives a message about E: Release file...., re-run it
		# sudo apt -y full-upgrade 	# Note: we want to do this for all the camera changes
		# sudo apt install -y python3-picamera2
			
## Setup SPI & Localization
		
		sudo raspi-config
			Interface Options
				SPI: Enable
			Localization Options
				Timezone: None of the Above: UTC
			Update      (This updates raspi-config only)
			Finish
		sudo reboot
		
		ssh pi@astrid.local
		
## Setup ATmega328pb programming environment
		# Install environment to program ATmega328pb
		sudo apt-get -y install automake bison flex gcc-avr binutils-avr avr-libc # (maybe avr-lib instead of avr-libc)
		
		# Add ATmega328PB to avr-gcc
		# Reference: https://blog.koipond.org.uk/archives/105
		# Reference: https://stuvel.eu/post/2021-04-27-atmega328pb-on-gcc/
		# Reference: https://wellys.com/posts/avr_c_328pb/
		cd
		wget http://packs.download.atmel.com/Atmel.ATmega_DFP.2.0.401.atpack
		unzip -d microchip-avr-dfp Atmel.ATmega_DFP.2.0.401.atpack
		sudo cp microchip-avr-dfp/gcc/dev/atmega328pb/avr5/crtatmega328pb.o microchip-avr-dfp/gcc/dev/atmega328pb/avr5/libatmega328pb.a /usr/lib/avr/lib/avr5
		sudo cp  microchip-avr-dfp/include/avr/iom328pb.h /usr/lib/avr/include/avr
		sudo cp /usr/lib/avr/include/avr/io.h /usr/lib/avr/include/avr/io.h~
		sudo vi /usr/lib/avr/include/avr/io.h
			# Search 328P and add after:
				#elif defined (__AVR_ATmega328PB__)
				#  include <avr/iom328pb.h>
		rm -rf microchip-avr-dfp
		rm Atmel.ATmega_DFP.2.0.401.atpack
				
		git clone https://github.com/kcuzner/avrdude 
		cd avrdude/avrdude
		./bootstrap && ./configure && sudo make install
		cd
		sudo vi /usr/local/etc/avrdude.conf
			# Search m328p and add after:
			part parent "m328"
 			   id                  = "m328pb";
    			desc                = "ATmega328PB";
    			signature           = 0x1e 0x95 0x16;

    			ocdrev              = 1;
			;
	
## Install QT, AstroPy, Astrometry, xmltodict and photutils
		# Install QT Designer and OpenCv
		sudo apt -y install qtcreator
		sudo apt -y install python3-opencv
				
		# Install AstroPy
		pip3 install astropy
	
		# Install Astrometry.net
		# Reference: https://g5555.neocities.org/astrometry
		sudo apt-get -y install astrometry.net
		#sudo apt-get -y install astrometry-data-tycho2
		sudo vi /usr/lib/python3/dist-packages/astrometry/util/fits.py
			# Change all np.bool to np.bool_
			
		# Install xmltodict
		pip3 install xmltodict
		
		pip3 install photutils
				    		
## Install Indilib
    	# Install INDI from source:
    	# https://github.com/indilib/indi
    		# Pre-requisites
    		sudo apt-get install -y \
			  git \
			  cdbs \
			  dkms \
			  cmake \
			  fxload \
			  libev-dev \
			  libgps-dev \
			  libgsl-dev \
			  libraw-dev \
			  libusb-dev \
			  zlib1g-dev \
			  libftdi-dev \
			  libgsl0-dev \
			  libjpeg-dev \
			  libkrb5-dev \
			  libnova-dev \
			  libtiff-dev \
			  libfftw3-dev \
			  librtlsdr-dev \
			  libcfitsio-dev \
			  libgphoto2-dev \
			  build-essential \
			  libusb-1.0-0-dev \
			  libdc1394-dev \
			  libboost-regex-dev \
			  libcurl4-gnutls-dev \
			  libtheora-dev
			
			# Get the code
			cd
			mkdir -p ~/Projects
			cd ~/Projects
			git clone --depth 1 https://github.com/indilib/indi.git
			
			# Build indi-core (cmake)
			mkdir -p ~/Projects/build/indi-core
			cd ~/Projects/build/indi-core
			cmake -DCMAKE_INSTALL_PREFIX=/usr -DCMAKE_BUILD_TYPE=Debug ~/Projects/indi
			make -j4
			sudo make install
			make clean
			
		# Install pyindi-client
		# Dependancies
		sudo apt-get -y install python-setuptools python-dev swig libcfitsio-dev libnova-dev
		
		#DO NOT INSTALL THIS AS WE'RE COMPILING INDI FROM SOURCE AND THEN pyindi-client won't install
			# sudo apt-get -y libindi-dev 
			
		# Install from source
		cd
		wget https://github.com/indilib/pyindi-client/archive/refs/heads/master.zip
		unzip master.zip
		rm master.zip
		cd pyindi-client-master
		sudo python3 setup.py install
		
## Enable serial debug for OTEStamper
		# Enabling debugging serial print's from the ATmega328p firmware and 
		# enabling Turbo mode so Pi doesn't go into energy saving mode and slow down SPI
		sudo vi /boot/config.txt		# Add at the end
			#dtoverlay=uart5	# We use this for an interrupt now!
			force_turbo=1	

## Configuring GPS & PPS on Raspberry Pi for system time
[Reference](https://austinsnerdythings.com/2021/04/19/microsecond-accurate-ntp-with-a-raspberry-pi-and-pps-gps/)

Statum 1 Time

	sudo apt install pps-tools gpsd gpsd-clients chrony
	sudo vi /boot/config.txt
		Add:
			dtoverlay=pps-gpio,gpiopin=4
			enable_uart=1
			init_uart_baud=9600	
			
	sudo vi /etc/modules
		Add:
			pps-gpio
			
	sudo vi /etc/default/gpsd
		Change:
			USBAUTO="true"
		To:
			USBAUTO="false"
		(This prevents indilib mounts being stolen by the GPS, e.g. SkyWatcher)
			
	sudo raspi-config
		Interface Options/Serial Port:
			Would you like a login shell to be accessible over serial?:  No
			Would you like the serial port hardware to be enabled?: Yes
			Finish / Reboot now: No
	sudo systemctl disable serial-getty@ttyS0.service
	sudo systemctl stop serial-getty@ttyS0.service
	sudo systemctl disable serial-getty@ttyAMA0.service
	sudo systemctl stop serial-getty@ttyAMA0.service
	sudo systemctl disable hciuart
	sudo systemctl stop hciuart
	sudo reboot
	
	ssh pi@astrid.local
	
	cat /dev/ttyS0
	Check GPS messages are coming in.  Note "unknown msg" is due to
	the tty echoing every command back to the GPS, to fix:
	
	sudo vi /etc/systemd/system/no-serial-echo.service

		[Unit]
		Description=Disable serial echo
		DefaultDependencies=no
		Before=basic.target
		After=sysinit.target
		
		[Service]
		Type=oneshot
		ExecStart=/bin/stty -F /dev/ttyS0 -echo
		
		[Install]
		WantedBy=basic.target
	
	sudo systemctl enable no-serial-echo
	sudo reboot

	ssh pi@astrid.local
	cat /dev/ttyS0    (and check the GPS messages are now clean with no unknowns)
	sudo vi /etc/default/gpsd
	
		Change to:
			DEVICES="/dev/ttyS0 /dev/pps0"
			GPSD_OPTIONS="-n"
			
	sudo cp /lib/systemd/system/gpsd.service /etc/systemd/system/gpsd.service
	sudo systemctl unmask gpsd
	sudo systemctl daemon-reload
	sudo systemctl enable gpsd
	sudo systemctl start gpsd
	
	sudo vi /boot/config.txt
		# This fixes a bug causing the pps_gpio driver to timeout
		# Reference: https://github.com/raspberrypi/linux/issues/5430
		Add: 
			arm_64bit=0
	sudo reboot
	
	ssh pi@astrid.local
	ps -ef | grep gpsd  # Check gpsd process exists
	Use gpsmon to confirm data is being used, and fix is obtained and PPS is working etc.
	lsmod | grep pps
		Results: pps_gpio               16384  3
	sudo ppstest /dev/pps0 
		(this should spit out a PPS signal every second provided arm_64bit=0, otherwise there will be a timeout after the first pulse)
	sudo vi /etc/chrony/chrony.conf
		Add:
			refclock SHM 0 refid NMEA precision 1e-1 offset 0.13115 noselect
			refclock PPS /dev/pps0 refid PPS lock NMEA precision 1e-9 offset 0.0 prefer
			
		Change to:
			makestep 1 -1
	sudo reboot
	
## Check GPS & PPS are working
	ssh pi@astrid.local
		chronyc sources -v
		
		After a while, PPS should have * by it confirming its the source being used.
		* = active source
		+ = good source and will be used if active source not available
		x = false ticker, which means source isn't being used, NMEA will always be this as we used PPS
		# = Locally connected source
		? = Haven't determined the status of the source yet
		
		[] = how far chrony is from the source
		Last column (after +/- includes latency to the NTP source as well as how far out of sync chrony thinks it is)
		chronyc sourcestats
		
		To sync the system time immediately to the chronyc:
			chronyc makestep
		
		References:
		https://jfearn.fedorapeople.org/fdocs/en-US/Fedora_Draft_Documentation/0.1/html/System_Administrators_Guide/sect-Checking_if_chrony_is_synchronized.html
		https://access.redhat.com/documentation/en-us/red_hat_enterprise_linux/7/html/system_administrators_guide/ch-configuring_ntp_using_the_chrony_suite
		https://robrobinette.com/pi_GPS_PPS_Time_Server.htm#GPS_With_PPS_Testing_&_Troubleshooting
		https://chrony-project.org/doc/3.4/chrony.conf.html

## Install VNC
		# Install Regular VNC		
 		sudo raspi-config
			Display Options/VNC Resolution/1280x1024
			Interface Options/VNC/Yes/OK
			Finish/Reboot Now
		Login to the desktop via RealVNC on the mac: astrid.local
		
		# Test connection to VNC
		Use RealVNC's VNC Viewer
	
		# May need this, but disabled for now
		# Click VNC icon at the top of the desktop, click the pull down menu (top right)
		# Choose Options/Troubshooting and check "Enable direct capture mode", click OK
		# VNC will hang	
		
## Setup Camera Sensor

	sudo vi /boot/cmdline.txt
	Add:
			cma=128M

## IMX296 Global Shutter Mono/Color
	 	sudo vi /boot/config.txt
		Add:
			dtoverlay=imx296
		sudo reboot

## IMX477 Raspberry Pi HQ (DO NOT USE)
    	# Enable IMX477 Sensor XVS Trigger output
    	sudo vi /boot/cmdline.txt
    		imx477.trigger_mode=1  	# Add this
	 
	 	# Disable Star Eater for IMX477 Sensor
	 	sudo vi /boot/cmdline.txt:
			imx477.dpc_enable=0		# Add this
		sudo reboot
			
## OV9281 (DO NOT USE)
	 	sudo vi /boot/config.txt
		Add:
			dtoverlay=ov9281
		sudo reboot
			
## Test Camera		
			
		# Test camera
		Launch Astrid, check can see camera over VNC
		sudo poweroff

## Change Desktop Background
		# Change background
		Raspberry Pi Icon / Preferences / Appearance Settings / Change Picture to aurora.jpg 
		
## Prevent Desktop from Prompting To Execute
			
		# To prevent it asking to execute in terminal
		Open up the file manager (double yellow folders)
		Edit/Preferences/General
		Check "Don't ask options on launch executable file"
		Click Close

## Install AutoHotspot
		
	Reference: https://www.raspberryconnect.com/projects/65-raspberrypi-hotspot-accesspoints/183-raspberry-pi-automatic-hotspot-and-static-hotspot-installer

	curl "https://www.raspberryconnect.com/images/hsinstaller/Autohotspot-Setup.tar.xz" -o AutoHotspot-Setup.tar.xz
	tar -xvJf AutoHotspot-Setup.tar.xz
	sudo raspi-config
		Localization / Set WLAN Country to US
	cd Autohotspot
	sudo ./autohotspot-setup.sh
	Option 2
		
	Wifi hotspot: RpiHotspot
	Wifi password is 1234567890
	IP: 10.0.0.5
		
	Option 7. Change to:
		Access Point SSID: AstridHotspot
		Password: iotaiota
			
	crontab -e 
	Add:
		* * * * * sudo /usr/bin/autohotspot >/dev/null 2>&1

## Install Astrid			
			
		# Install the astrid software
		cd
		See 1Password for configuring git account
		#git config --global user.name "XXXXXXXXX"
		#git config --global user.email "XXXXX@XXXXXXX"
		#git config --global credential.helper 'cache --timeout=10000000'
		git clone https://github.com/ChasinSpin/astrid.git
		cd astrid
		./install.sh
			
## Install Indi 3rd Party Focusers and Mounts
		cd ~/astrid/scripts
		./install_indi_3rdparty.sh
		
## Run Astrid and download astropy needed downloads for offline use

With simulator mount:

	* Do a custom search for vega, then a goto
		which downloads:
			* https://hpiers.obspm.fr/iers/bul/bulc/Leap_Second.dat
			* https://datacenter.iers.org/data/9/finals2000A.all
	* Do a prepoint to force AltAz conversion (this forces a download)

## Run Chromium once

Start and exit chromium (so we can change settings in the upgrade later)

## Run Astrid Upgrade

Run Astrid Upgrade

## Remove networks and history

		cd
		rm .bash_history
		
		Remove any networks used during this build:
		sudo vi /etc/wpa_supplicant/wpa_supplicant.conf;sync;sync;sync;sudo poweroff
		
## Create Image
	# Create image on Mac using PiLess https://github.com/ChasinSpin/PiLess 
	sudo ./PiLess.sh imagename	
	e.g. sudo ./PiLess.sh ../2023-08-02-astrid

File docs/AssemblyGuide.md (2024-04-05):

# Assembly Guide - Partial Kit (Skill Level Beginner)

### Note: The partial kit is no longer being sold as it's replaced by the IOTA Fully Assembled Astrid.  

###This remains for reference purposes only.

Astrid can be purchased with some parts pre-assembled, this is known as the "Partial Kit". The kit also requires some additional parts that you will need to purchase separately. These instructions detail how to assemble the partial kit and the parts you need to purchase to build a working Astrid.

[Assembly Video](https://www.youtube.com/watch?v=mhg2wGE4-7w) also demonstrates the assembly process and should be used in combination with the information here.

If you do not wish to purchase the Partial Kit, then you will need to [Make Your Own Kit](BuildKit.md) first prior to following these instructions.

Assembly time is approximately 15mins for the hardware, maybe a little longer if it's your first time.

## Partial Kit

The partial kit includes:

* OTE Stamper Board (timing board)
* Sony IMX296 Global Shutter Mono Camera (Modded)
* GPS and Active 30dB External Antenna
* Resin 3D Printed Case
* Required Hardware (screws, cables etc.) to complete assembly

## What You Need To Purchase

| Quantity | Description |
| --- | --- |
| 1 | [Raspberry Pi 4B - 8GB](https://www.amazon.com/Raspberry-Quad-core-Cortex-A72-Wireless-Bluetooth/dp/B0B6ZJGF4Q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) |
| 1 | [Sandisk 64GB Extreme Pro SD Card SDSQXCU-064G-GN6MA](https://www.amazon.com/SanDisk-Extreme-microSDTM-Adapter-SDSQXCU-064G-GN6MA/dp/B09X7BYSFG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) |
| 1 | [Recommended USB Thumb Drive](USBDriveRequirements.md) |
| 1 | [Battery/Power](PowerSupply.md) |
| 1 | [12V Power Lead](PowerSupply.md) |
| 1 | [0.5X IOTA 1.25" Focal Reducer (CS Mount) and 3 Extension Rings](UsageGuide.md#focal-reducers-and-length) - usually required [Purchase Link](https://occultations.org/night-eagle-2-pro-astro-edition-ordering-page/)| 

## Tools Required

* Small Pliers
* Phillips Screw Driver (long shaft, thin, shaft diameter max 4mm)

## Astrid Assembly

The case in the Partial Kit is supplied-semi assembled to show how everything fits together, you will need to dissemble the case first.
	
* Remove the 4 screws holding the case together, be careful not to lose the nuts.

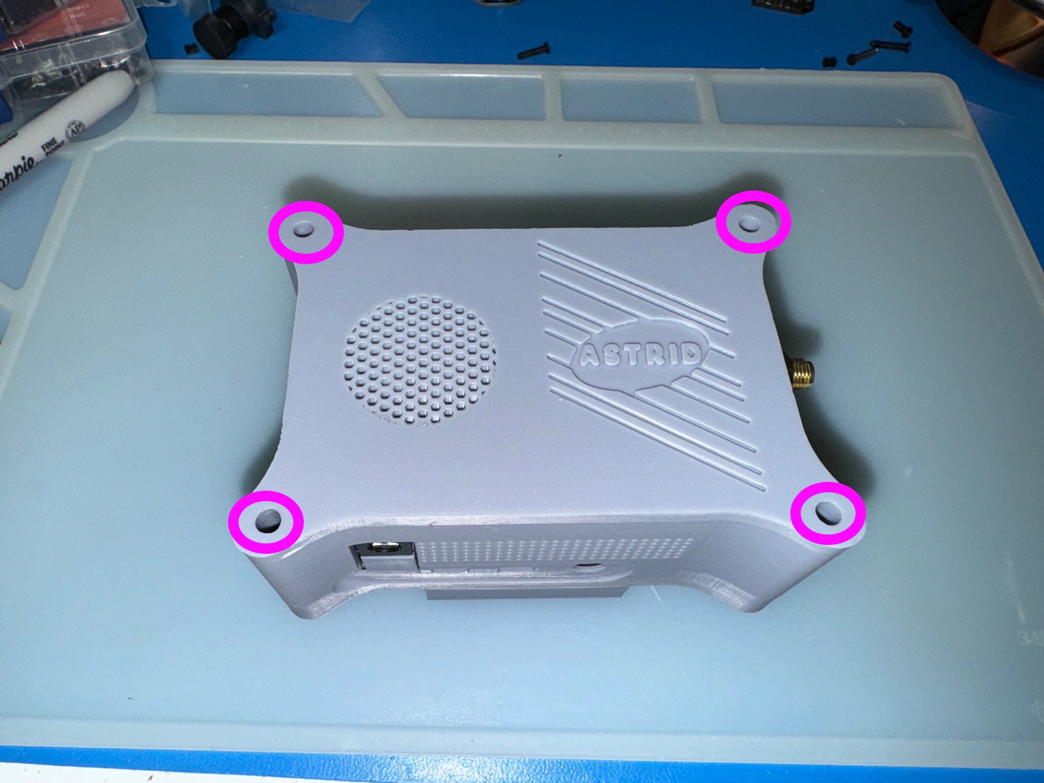
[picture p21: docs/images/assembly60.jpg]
Unscrew Case
	
	
* Remove the nut and lock washer from the "gold" colored GPS pig-tail and remove the pig-tail from the case to make it easier to work on.

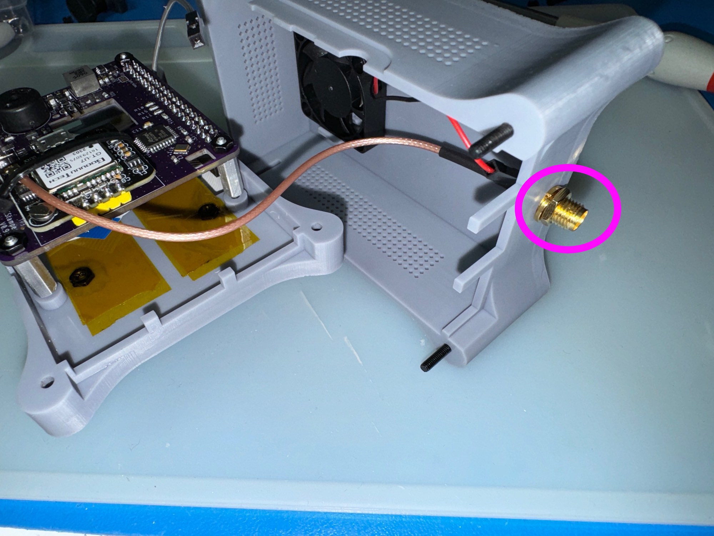
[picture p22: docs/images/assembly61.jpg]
Remove Pig-Tail
	

* Remove the 4 screws holding the camera cover to the case and remove the camera cover.

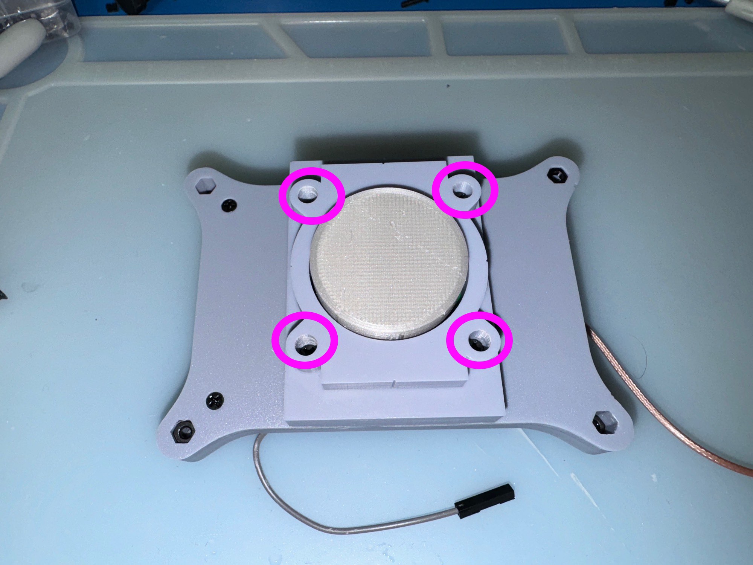
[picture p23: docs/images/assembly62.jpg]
Remove Camera Cover
	
	
* Remove the 4 screws holding the OTEStamper board to the case.

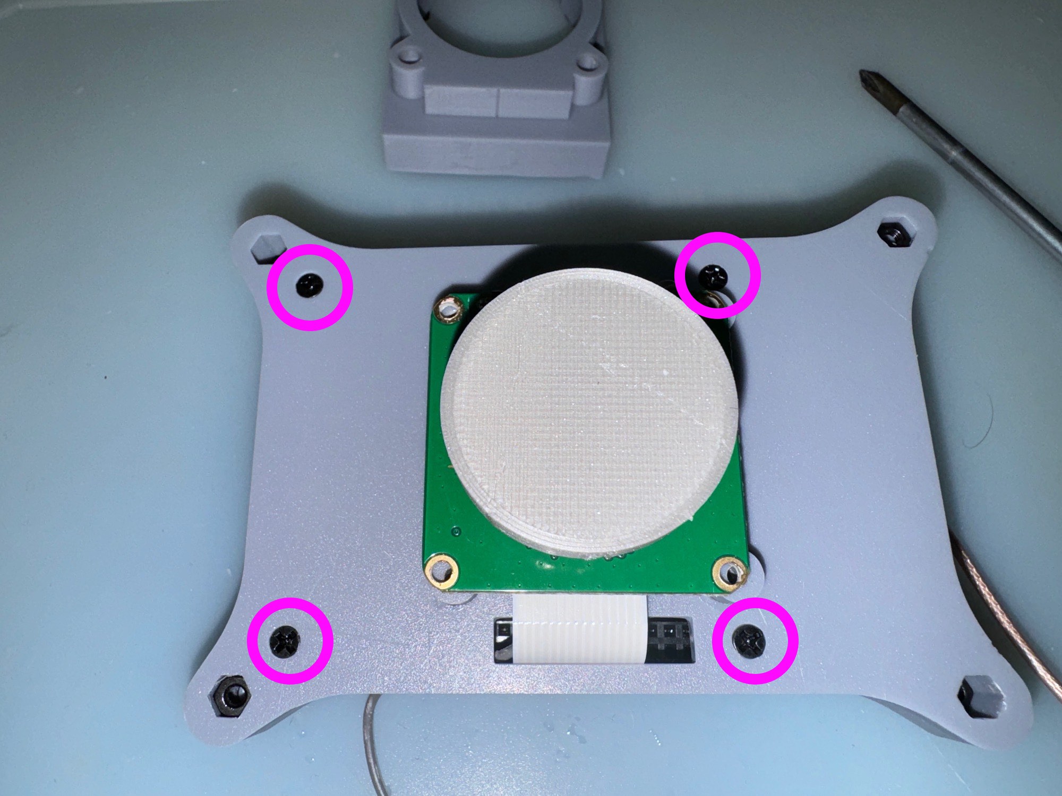
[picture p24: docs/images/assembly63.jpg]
	
	
* Find the following parts.

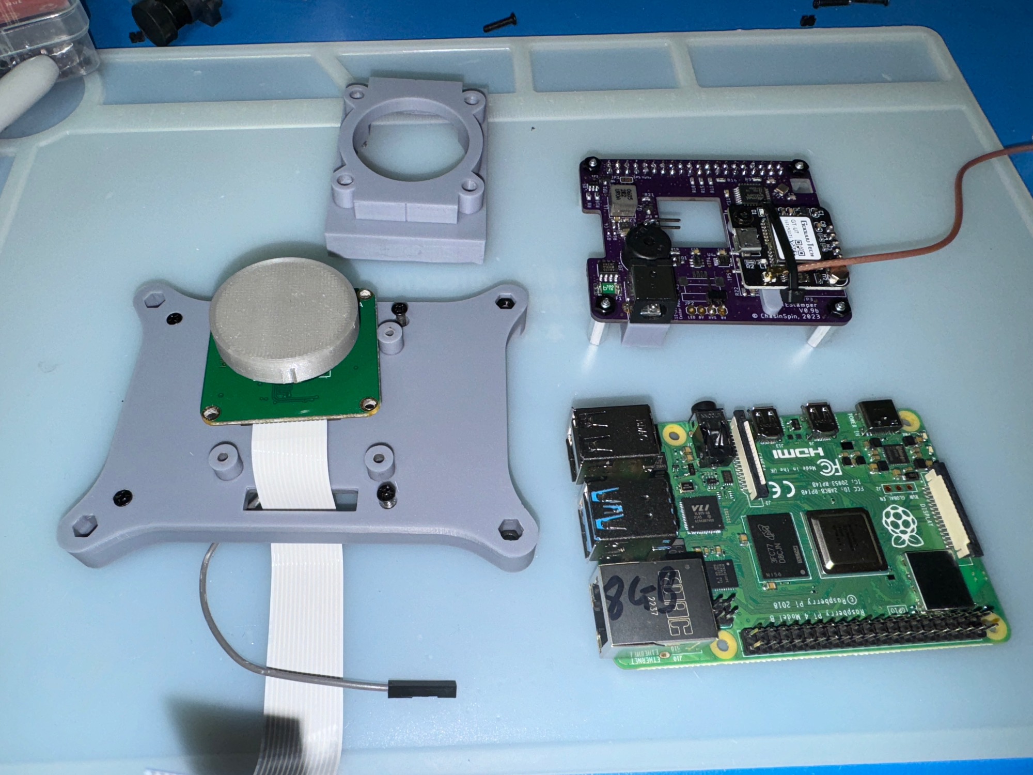
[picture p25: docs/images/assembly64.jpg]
	
	
* Orient the camera on the case bottom and put the Flat-Flex and 0.1\" header cables through the slot.

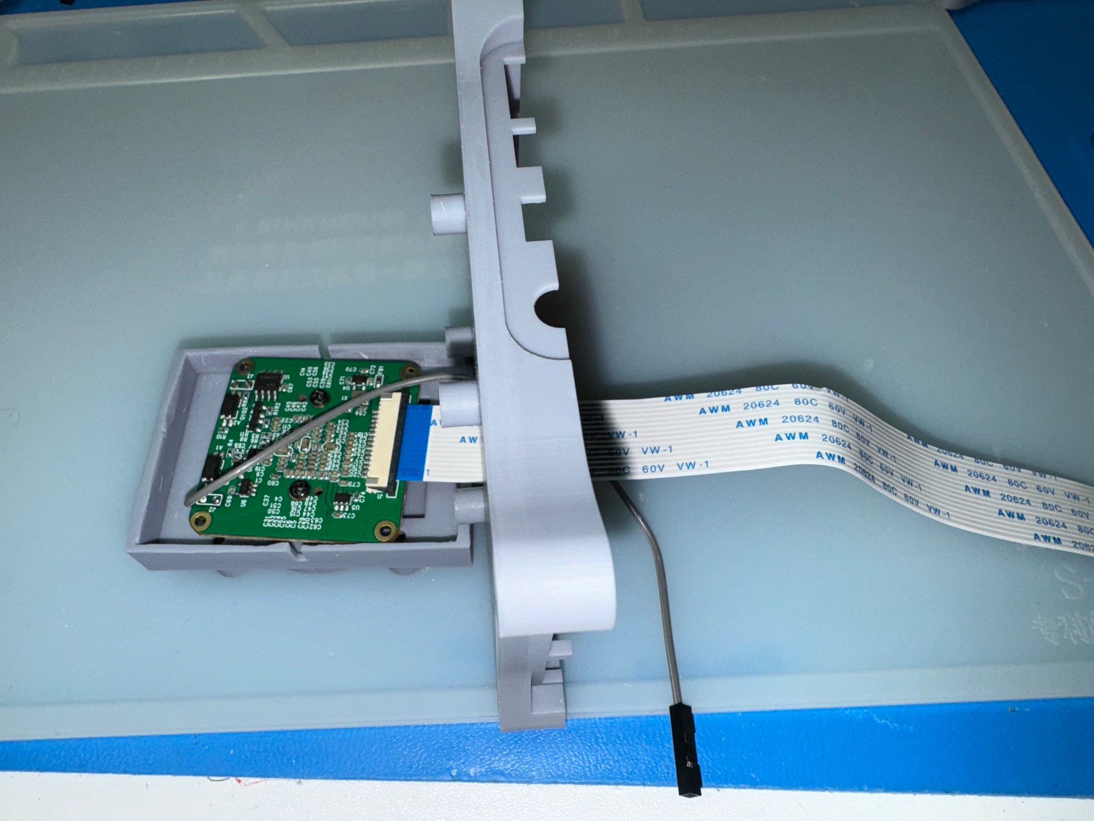
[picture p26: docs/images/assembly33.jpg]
	
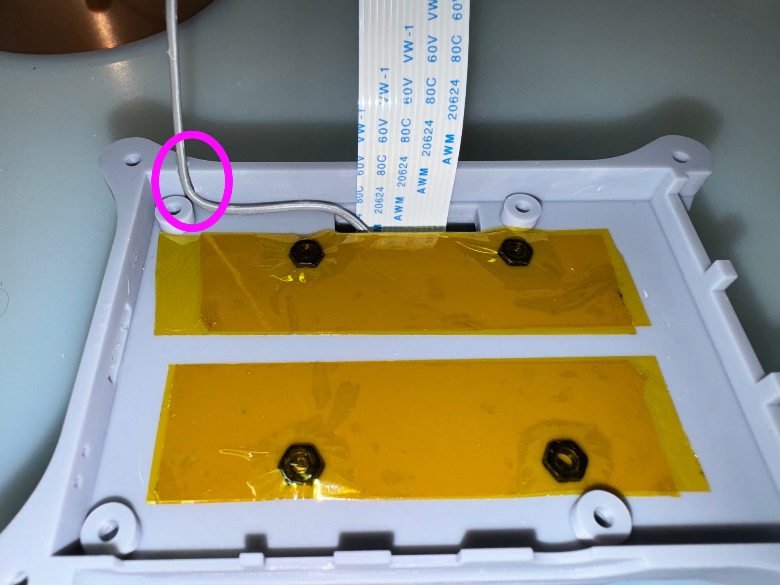
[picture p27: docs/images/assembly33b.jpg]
	
	
* Place the Raspberry Pi 4B - 8GB on the other side of the board.  Be sure to locate the 0.1\" header cable in the notch on the left-hand side as shown.

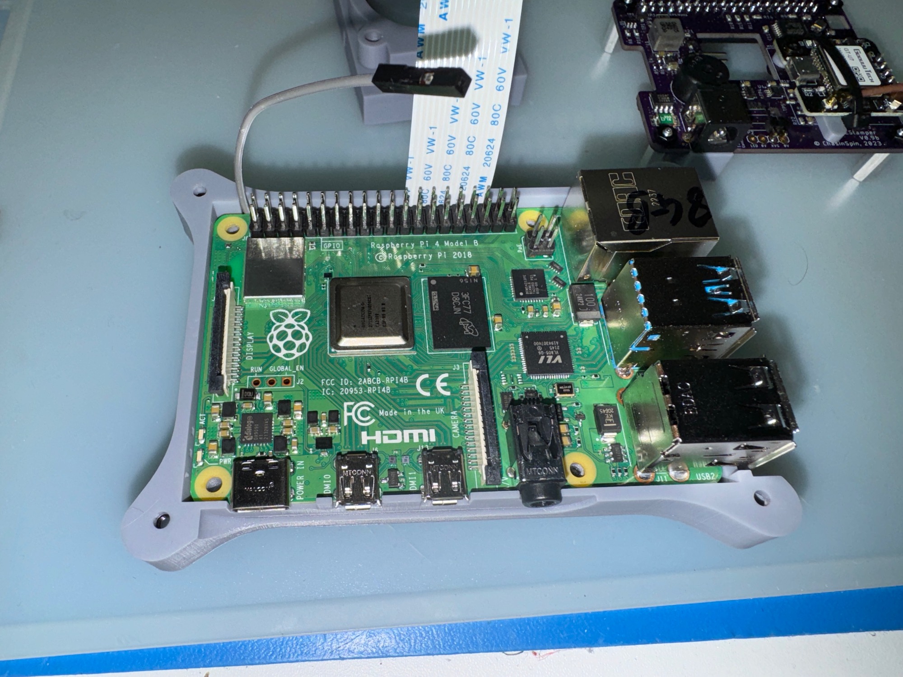
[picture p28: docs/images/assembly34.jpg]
Raspberry Pi Placed
	

* Attach Raspberry Heatsinks to the board as shown.

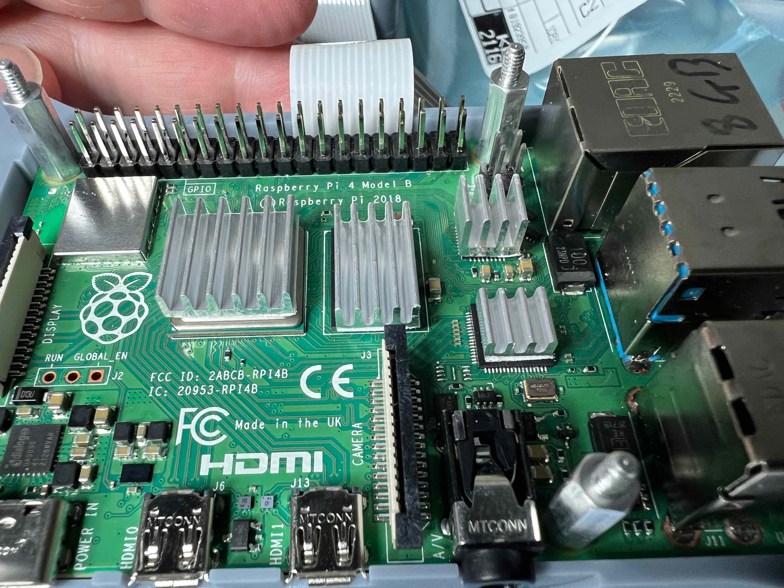
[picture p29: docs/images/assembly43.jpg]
Raspberry Pi 4 Heatsink placement
	
	
* Pull up the black lever on the Raspberry Pi connector for the camera.

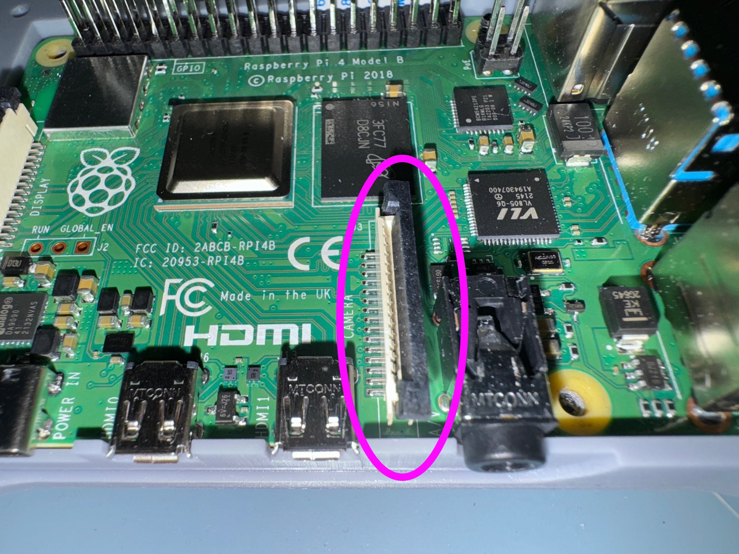
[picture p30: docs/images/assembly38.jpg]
Pull Up Black Lever
 	

* Insert the Camera Flat-Flex into Raspberry Pi, note the orientation of the Flat-Flex (blue reinforcement) and the twist.

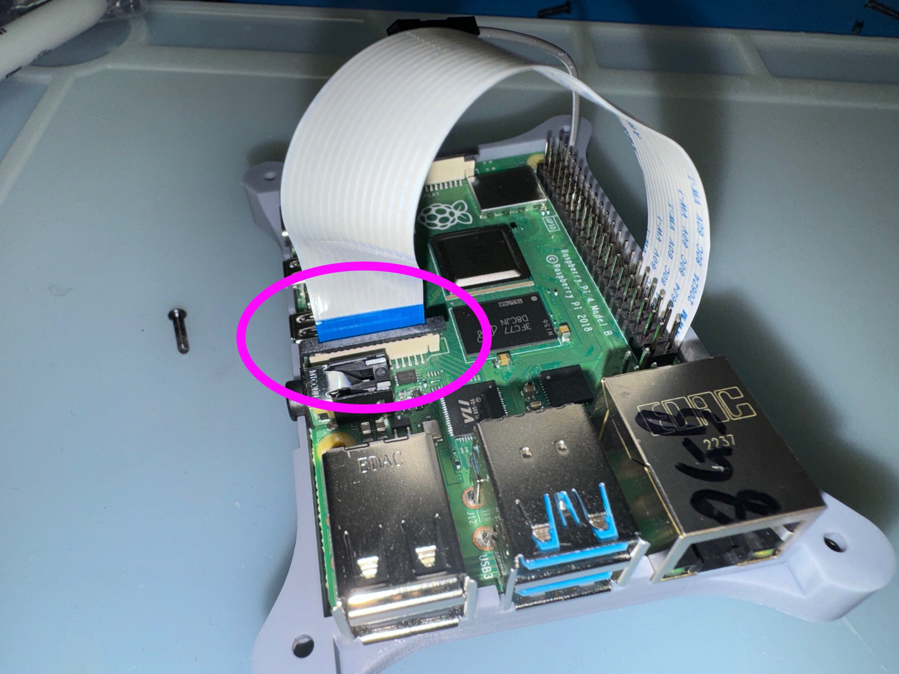
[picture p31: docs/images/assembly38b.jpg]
Insert Flat-Flex to Raspberry Pi
 	

* Push down the black lever on the connector until back in the original position on both sides.

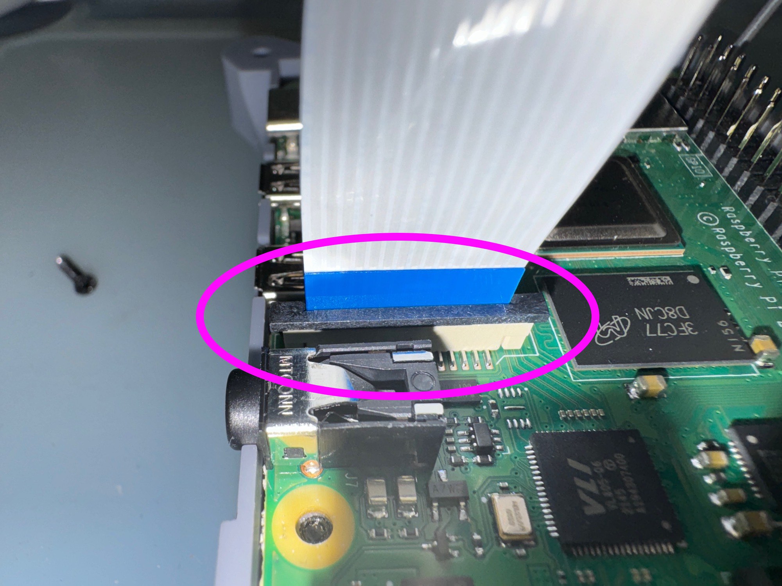
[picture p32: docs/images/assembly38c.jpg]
Push Level Down
 	
	
* Place the OTEStamper board on top of the Raspberry pi as shown with the flat flex cable coming out to the side.

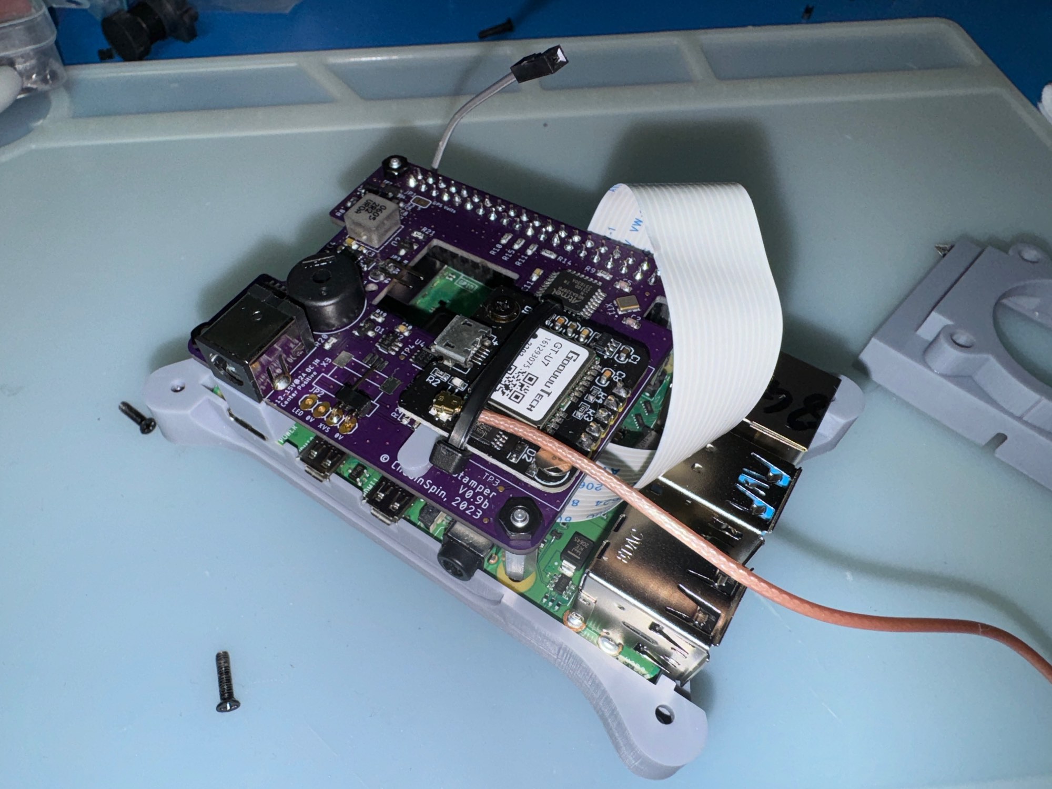
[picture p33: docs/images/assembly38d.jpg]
Adding OTEStamper
	
	
Be sure that the camera Flat-Flex is not being clamped between the Hex Standoff and the OTEStamper board.  This cable routing makes it less likely that a cable can be fouled by the Fan.

* Put the 4 - 2.5mm x 10mm bolts in from the bottom of the case into the hex standoffs and screw the Raspberry Pi and OTEStamper board to the case.
 
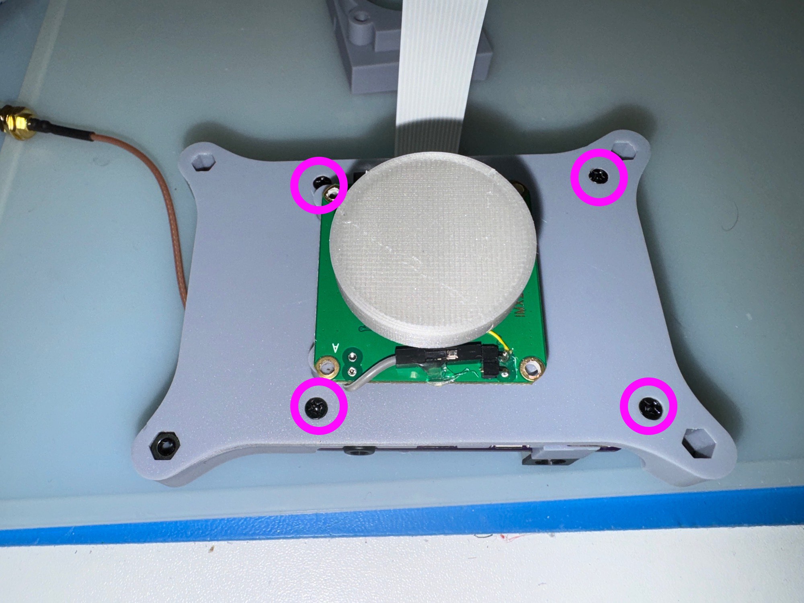
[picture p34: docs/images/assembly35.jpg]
Raspberry Pi Placed Bottom
	
	
* Attach the Camera Cover over the Camera board and use the 4 - 2.5mm x 14mm bolts to screw it down.  The Camera Cover should sit flush.

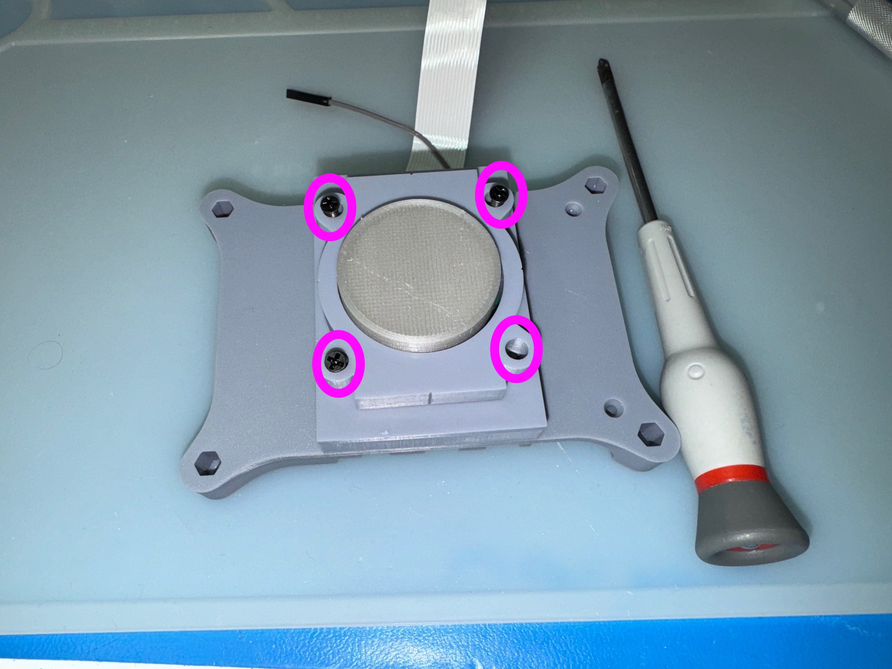
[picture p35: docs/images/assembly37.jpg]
 	
 	
* Route the 0.1\" header cable as shown and connect to the XVS pin.

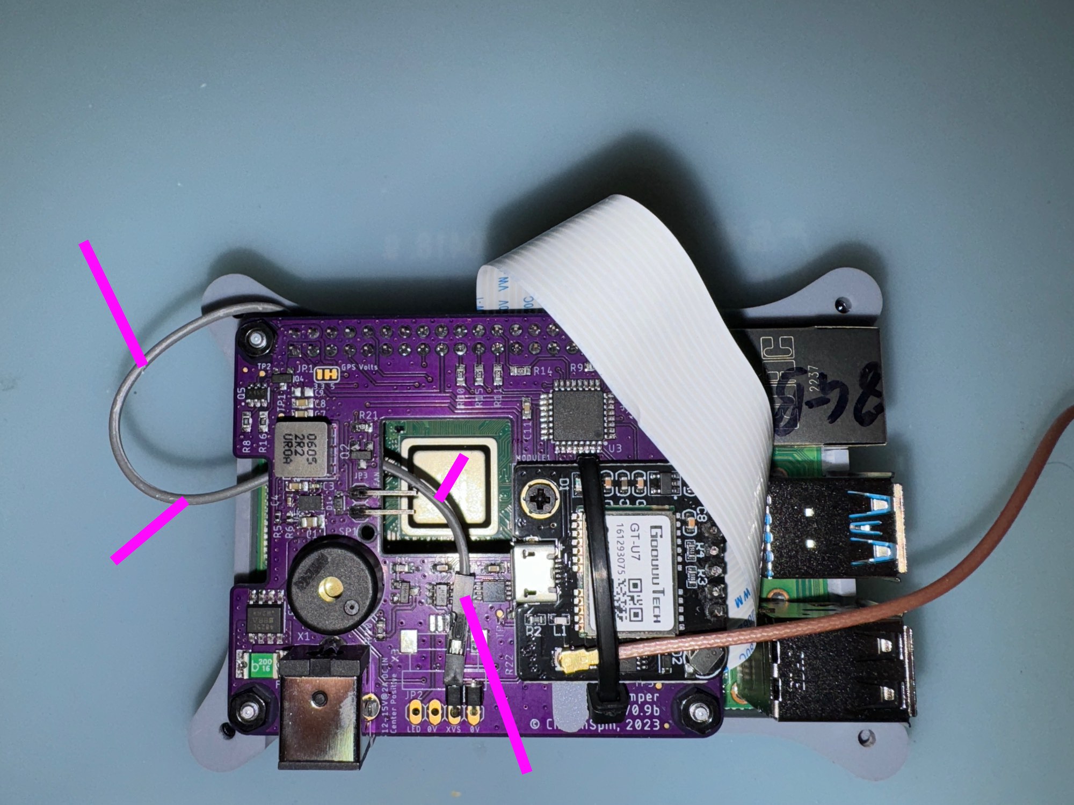
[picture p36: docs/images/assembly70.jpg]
 	
 	
* Attach the GPS pig-tail to the case with the retaining washer inside the case and the lock washer and nut on the outside.  Tighten carefully with pliers so the connector does not rotate in the case.

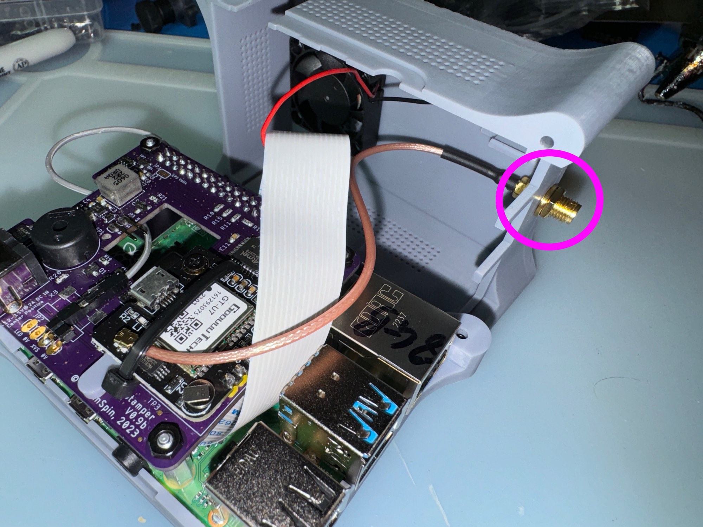
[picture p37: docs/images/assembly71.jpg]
 	

* Attach the fan jumpers to the OTEStamper board.  Note that the negative lead is closest to the 12V DC input jack.

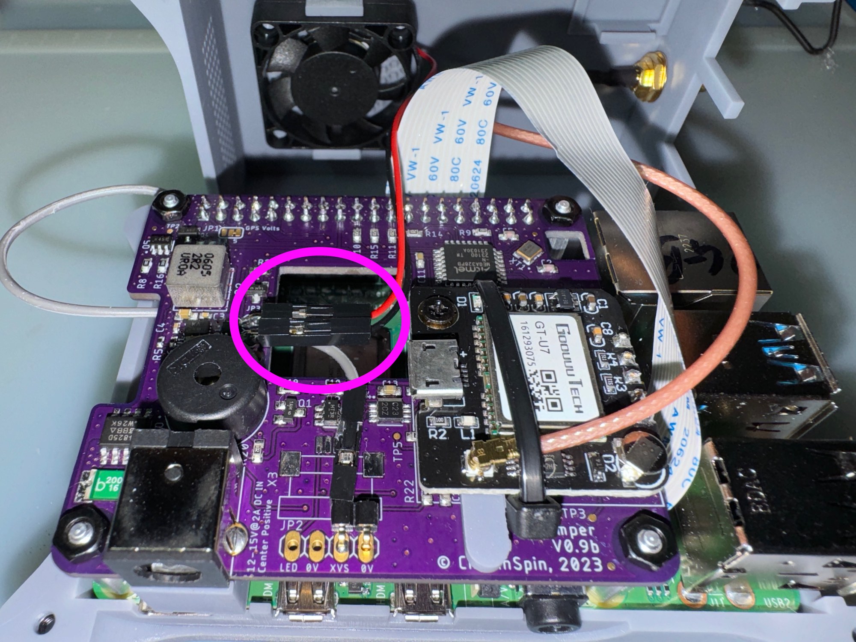
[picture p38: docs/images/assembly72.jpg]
Fan and Pigtail attached
 	
 	
* Carefully close the case making sure nothing is fouling the fan and the flat-flex and cables are not caught in the case.  Using 4 - 2.5mm x 14mm bolts and 4 - 2.5mm nuts, bolt the case together.

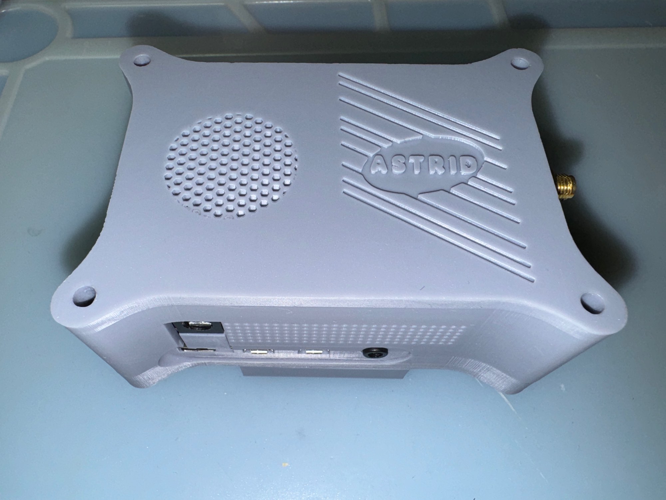
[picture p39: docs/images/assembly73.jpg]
Case Closed
 	
 	
 * [Build the SD CARD](InstallImage.md)

 * Insert the SD Card in the orientation shown and push in till level with the case.

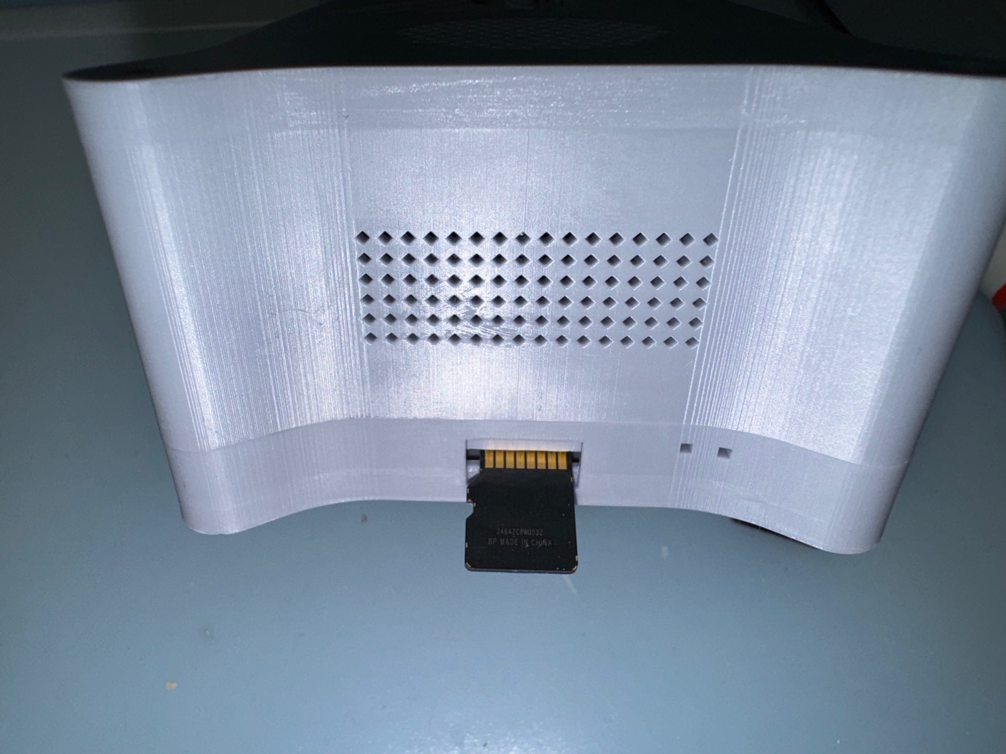
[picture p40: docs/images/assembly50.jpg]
SD Card Orientation
 	
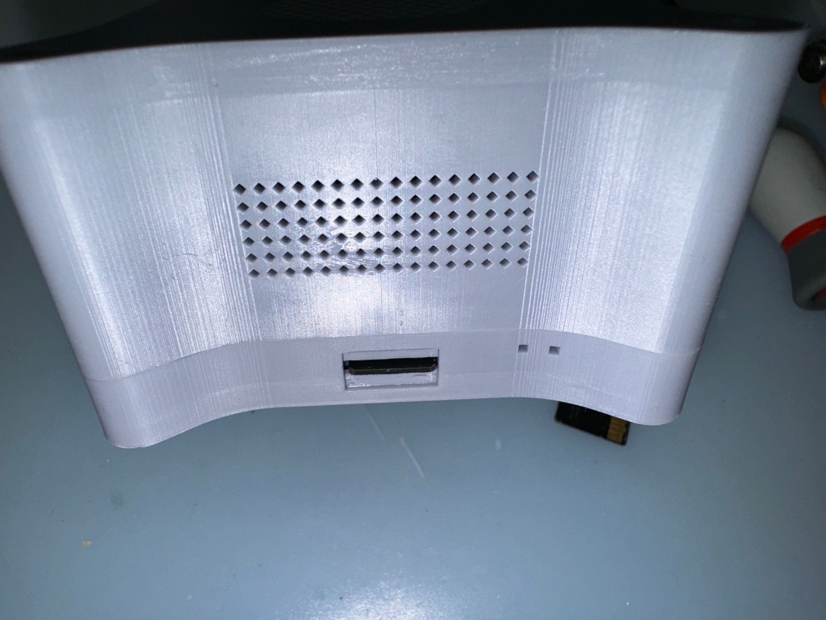
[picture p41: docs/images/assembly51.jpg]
 	
 	
 * Remove the cap from the sensor, visually check there's no dust on the sensor (use a camera puffer if there is), and screw 2 extension rings, the CS to 1.25\" adapter and the 0.5X Focal Reducer on and cap with the yellow cover.
 
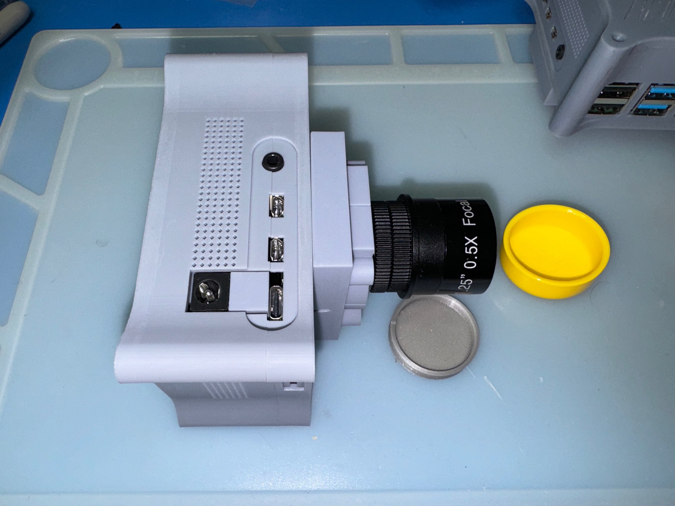
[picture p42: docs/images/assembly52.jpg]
 	
 	
* [Build The USB Flash Drive](FlashDriveLayout.md)

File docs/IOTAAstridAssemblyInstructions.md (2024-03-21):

# IOTA Astrid Assembly Instructions

## First Batch

* 7 x OTEStamper (including 1 testing for Steve)
* 7 x Astrid Cases

(Steve: 1 unit for testing)

## Required Parts (per Astrid)

| Quantity | Description |
| --- | --- |
| 1 | [OTEStamper Board - Mark]() |
| 1 | [Astrd Case - Mark]() |
| 1 | [0.1" Header Lead for Frame Trigger - Mark]() |
| 1 | [Raspberry Pi 4B - 8GB](https://www.digikey.com/en/products/detail/raspberry-pi/SC0195-9/12159401) |
| 1 | [Sandisk 64GB Extreme Pro SD Card SDSQXCU-064G-GN6MA](https://www.amazon.com/Sandisk-Extreme-Pro-MicroSD-V30/dp/B09X7BYSFG) |
| 1 | [Recommended USB Thumb Drive](USBDriveRequirements.md) |
| 1 | [Consider adding power lead and 5A fuse]() |
| 1 | [Consider adding battery (shipping concerns though)]() |
| 1 | [0.5X IOTA 1.25" Focal Reducer (CS Mount), 3 Extension Rings and Yellow Cap]()| 
| 1 | [IOTA Custom Innomaker IMX296 Mono Camera Board, gasket, CS mount, white flat flex]() | 
| 1 | [Bingfu Waterproof Active GPS Navigation Antenna Adhesive Mount SMA Male GPS Antenna with 15cm 6 inch U.FL IPX IPEX to SMA Female RG178 Coxial Pigtail Cable for GPS Module Receiver Tracking](https://bingfushop.com/products/bingfu-waterproof-active-gps-navigation-antenna-adhesive-mount-sma-male-gps-antenna-with-15cm-6-inch-u-fl-ipx-ipex-to-sma-female-rg17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) or [Amazon](https://www.amazon.com/dp/B083D59N55?th=1) |
| 1 (0.001 of pack) | [Small Zip Tie - pack of 1000](https://www.amazon.com/Monday-HS-Plastic-Self-Locking-Electronics-Electrical/dp/B078NT5F2B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) |
| 4 heat sinks, 1 fan (0.25 of pack) | [GeeekPi Fan for Raspberry Pi, Pi Cooling Fan 30x30x7mm DC 5V Brushless CPU Cooling Fan with 7PCS Heatsink for Raspberry Pi 4 Model B,3B+,Pi 3 & Retroflag NESPI CASE Plus (4-Pack)](https://www.amazon.com/GeeekPi-Raspberry-30x30x7mm-Brushless-Retroflag/dp/B07PHGTJKK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) Fan must be 30x30x7 and 0.1A max, raspberry Pi uses the 4 silver aluminum heatsinks |
| 4 (0.1666 of pack) | [M2.5 Hex Standoffs Male/Female 0.45x11mm](https://www.amazon.com/MMOBIEL-Cylinders-Minicomputer-Electronic-Screwdriver/dp/B08M3PN7BT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) Use Nut and Standoff (screw not used) |
| 8 (0.04 of pack) | [M2.5mm Nut](HELIFOUNER 200 Pieces M2.5 Hex Nuts, Stainless Steel (304) 18-8 Nuts for Screws Bolts) |
| 4 (0.008 of pack) | [2.5mm x 10mm Bolts](https://www.amazon.com/uxcell-Phillips-Fasteners-Laptop-Switch/dp/B08J41P7DH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) |
| 8 (0.02286 of pack) | [2.5mm x 14mm Bolts](https://www.amazon.com/uxcell-Phillips-Fasteners-Laptop-Switch/dp/B08J3L4J1K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) (case(4) and camera holder(4)) |

## Additional Items Required For Assembly

* Flex Superglue Liquid (Flex Seal) _Do not use the gel_. This bonds to plastic/resin.  Many hardware stores, e.g. HomeDepot, can also be bought online.
* [Loctite 242](https://www.amazon.com/Henkel-Loctite-Threadlocker-Medium-Strength/dp/B01GWFHAM2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)
* [Kapton Tape 3/4"](https://www.amazon.com/TekLine-Gold-Kapton-Polyimide-36yds/dp/B0049KS03Q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)

## Tools Required For Assembly

* Small pliers
* Scissors
* Small tweezers
* Phillips Screw Driver (long shaft, thin, shaft diameter max 4mm)
* Hobby Knife
* Camera Puffer Blower

## Sub-Assembly Instructions

### Case Sub-Assembly

* Superglue posts
* Superglue 4 captive nuts
* Cover captive nuts with Kaptop after glue dry
* Insert fan, and place fan guard on top (fan guard is fragile)

### Camera Sub-Assembly

* Clip 0V pin (leave XVS pin untouched)
* Place adhesive gasket for CS Mount
* Place Loctite on screws, and screw CS Mount to board
* Use tweezers to remove sensor cover, being careful to avoid damaging sensor
* Hold board upside down and puffer blow off any dust
* Screw in 2 extension rings, IOTA CS to 1.25" converter and IOTA 0.5X Focal Reducer to protect sensor from dust
* Add Yellow Cap to Focal Reducer

_Note: There is one extension ring spare for some setups that might benefit from it if they can handle the increased focal reduction and still focus.  Ordinarily 2 rings are optimal for the 0.5X focal reducer._

## Assembly

Coming soon...

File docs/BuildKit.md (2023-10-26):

# Build Kit (Skill Level Advanced)

If you are not using the Partial Kit and you are building entirely from scratch, you will need to follow these instructions and then follow the [Assembly Guide](AssemblyGuide.md)

## Tools Required

* Hobby Knife
* Scissors
* Small Pliers
* Phillips Screw Driver (long shaft, thin, shaft diameter max 4mm)
* 2.5mm drill
* Small Soldering Iron and Solder
* Tweezers
* Hot-Glue
* Super-Glue
* Electrical Tape
* Loctite 242

## Parts Required

* [CAM-MIPI296RAW-Trigger](https://www.inno-maker.com/product/cam-mipi296raw-trigger/)
* Flat-Flex Camera Cable (comes with the camera)
* CS Lens Seat (comes with the camera)
* GPS External Antenna and PigTail [Active GPS Antenna with RG178 Pigtail](https://www.amazon.com/Bingfu-Waterproof-Navigation-Adhesive-Receiver/dp/B083D59N55)
* OTEStamper Board
* Small Wire-Wrapping Wire
* Trigger Board Cable 0.1\" header
* GT-U7 GPS
* 5-Pin GPS Header (yellow)
* 2.5mm x 8mm bolt
* 9 x 2.5mm Nut (Black)
* 4 x 2.5mm Nuts (Black)
* 4 x 2.5mm x 10mm Bolts
* 8 x 2.5mm x 14mm Bolts
* 4 x Aluminum or Brass Hex Standoffs Posts (2.5mm x 0.45 x 11mm)
* Small Zip-Tie
* Astrid 3D-Printed:
	* Case Bottom
	* Case Top
	* Camera Cover
	* 4 x Camera Board Mounting Posts
	* GPS Lozenge
	* 2.6mm thick spacer (washer)
	* Power Socket Block
* Raspberry Pi Heatsinks
* Raspberry Pi 30mm x 30mm x 7mm Brushless 5V Fan (100mA max current)

## Camera

*Note: This process is just for now, and will be removed in future with some custom camera boards from the supplier*

* Drill out the 4 PCB mounting holes with a 2.5mm drill.	 
	 
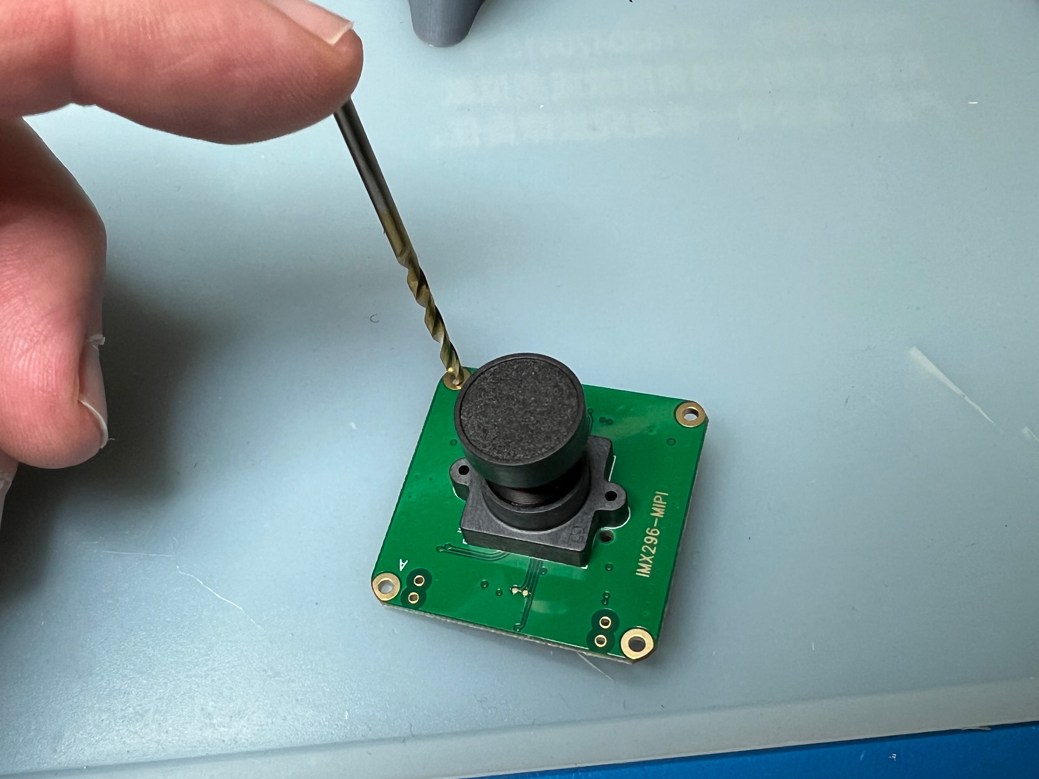
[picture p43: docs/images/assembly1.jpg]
Drilling Out PCB Mounting Holes
	
	 
* Remove any burrs created by the drill with a hobby knife, the board needs to be completely flat to fit the case.
* Clean off any dust from the drilling.
* Desolder J2 and J3 if they are present.
* Cut the tracks to J3 so that it is isolated from the rest of the circuitry.

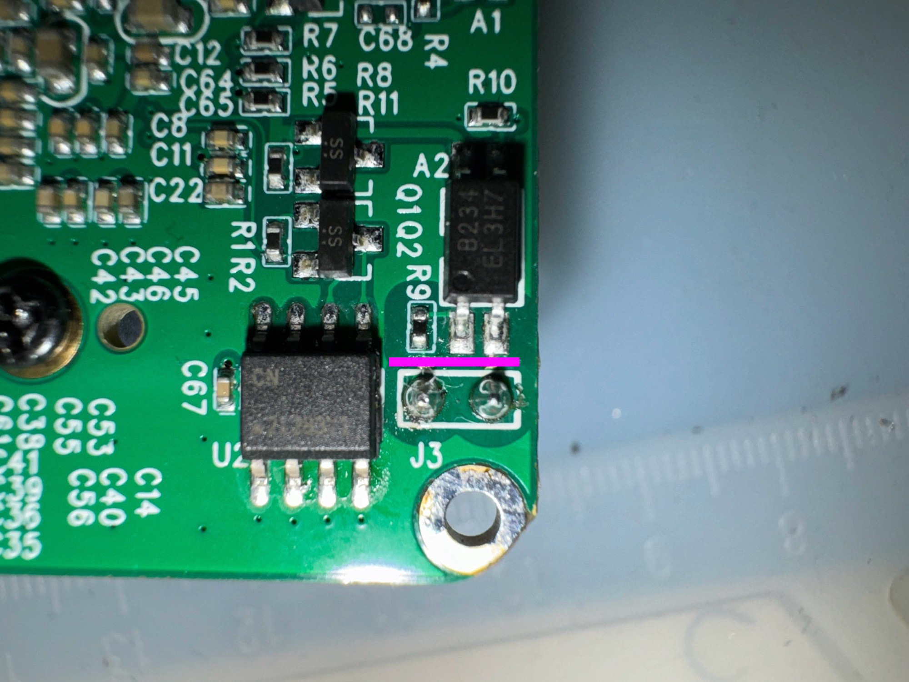
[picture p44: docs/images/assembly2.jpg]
Cut the tracks to J3
	

* Solder a right angled 0.1\" header where J3 was

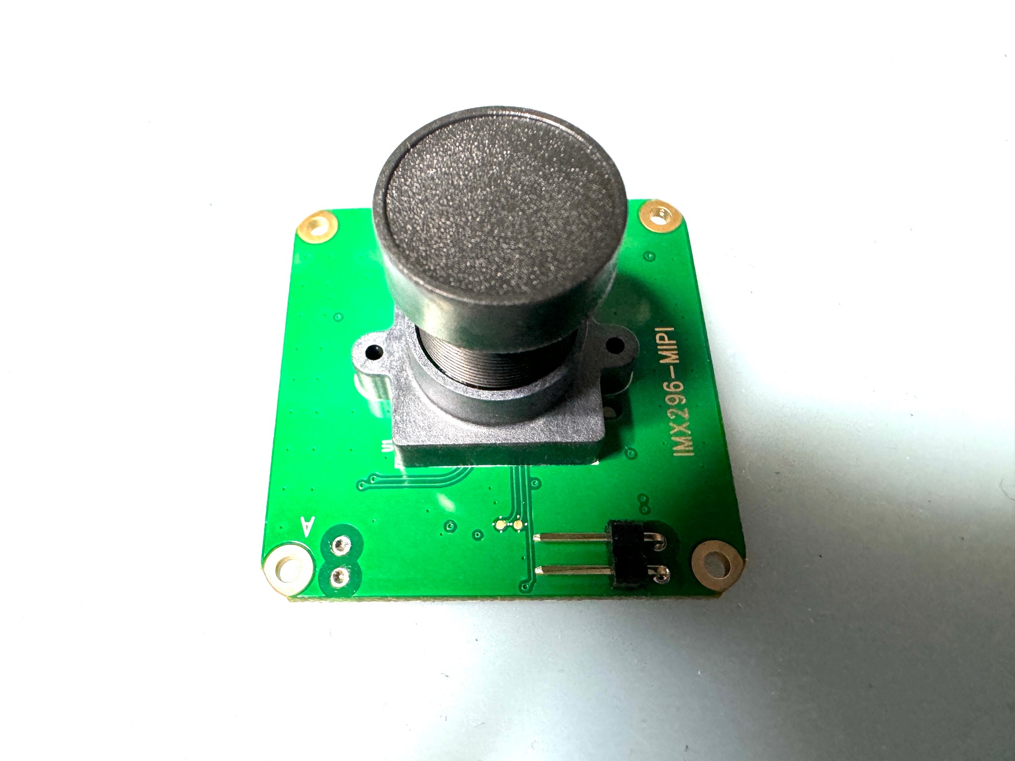
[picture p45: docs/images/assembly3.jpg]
Solder Right Angled Header
	
	
* Clip the unused pin on the header and shown and pre-tin (blob of solder) on the right test pad on the camera PCB and connect a wire from this pad to the header pin as shown.

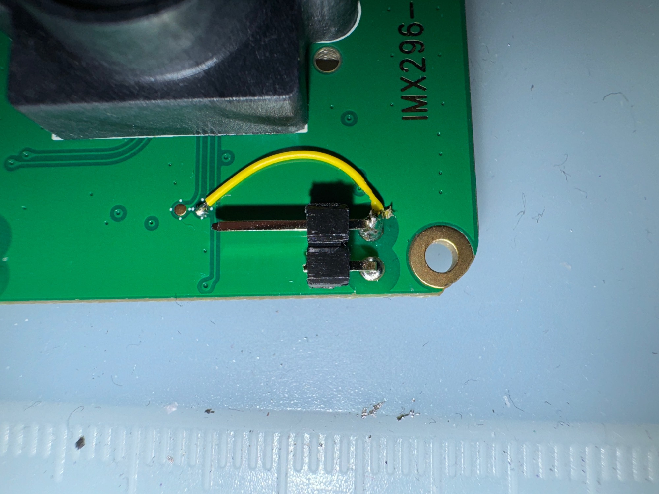
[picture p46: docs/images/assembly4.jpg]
Solder Wire
	

* Connect 0.1\" header wire and use hot glue too prevent becoming loose.	
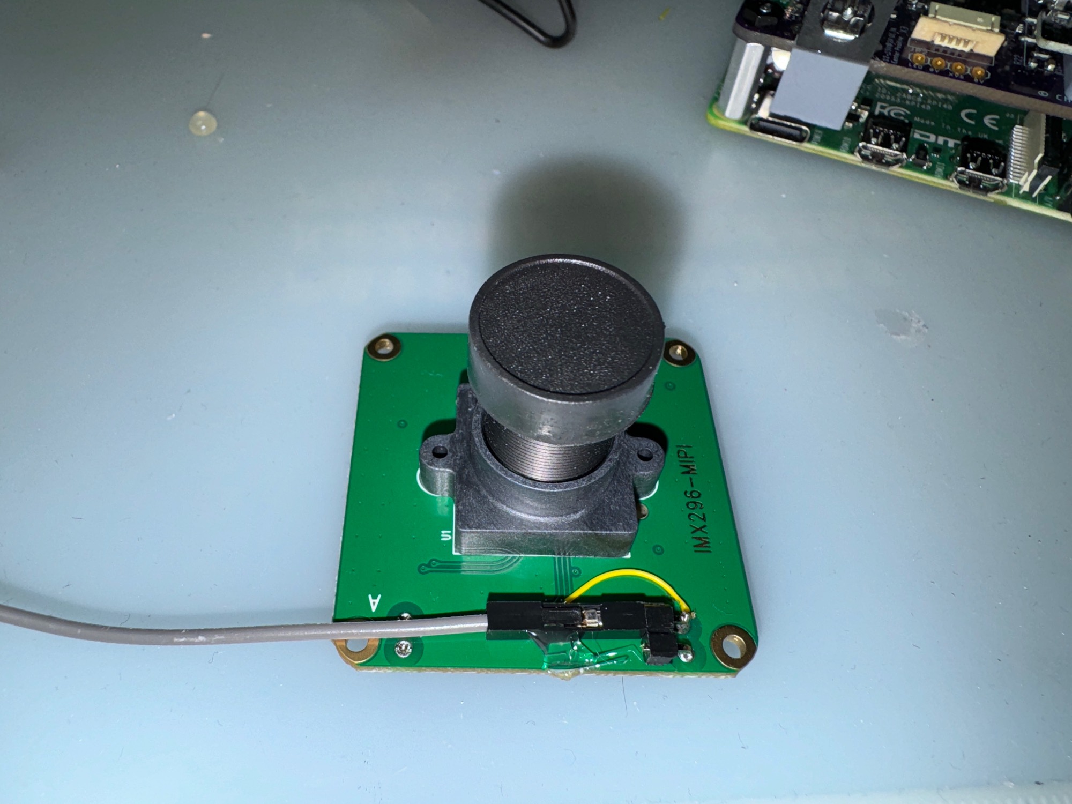
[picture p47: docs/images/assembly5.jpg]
Connect Header
	

* Unscrew the 2 screws on the back of the camera, and screw on the supplied CS Lens Seat, put some Loctite on the screws (not excessive) and do not overtighten.  Cap the CS Lens Seat to protect the sensor.

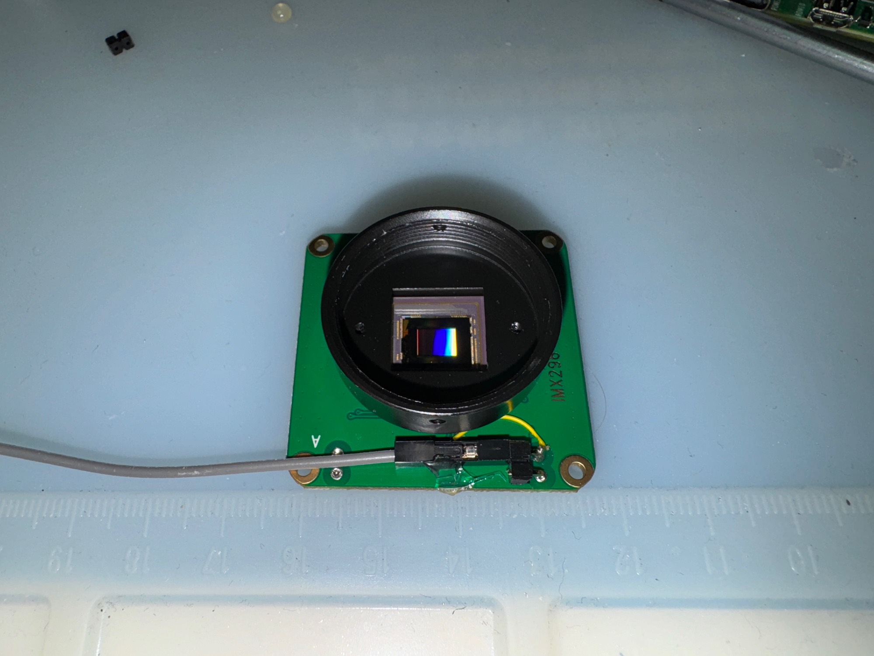
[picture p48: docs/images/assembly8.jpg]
CS Lens Seat Installed
	
	
* Install Flat-Flex Cable, contacts should be orientated toward the PCB.

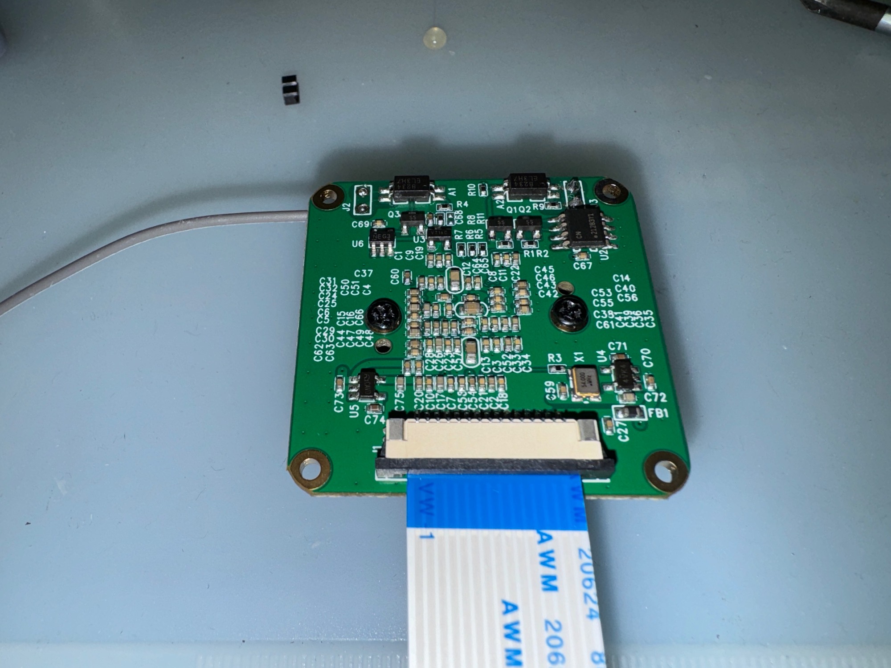
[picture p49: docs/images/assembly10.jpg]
Flat-Flex Bottom
	
	
## OTEStamper Board

* Place the 3D-Printed Lozenge on the long slot in the PCB (to provide support for the GPS board) and using the 5-pin yellow header supplied with the GPS, solder the GPS board to the OTEStamper board.  Clip the excess header.
	
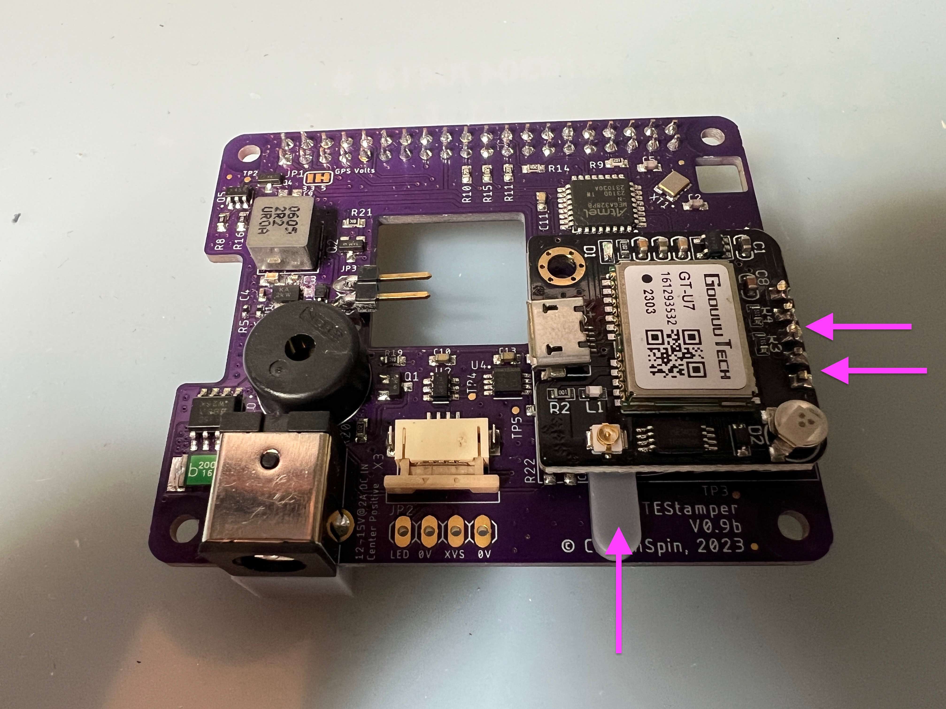
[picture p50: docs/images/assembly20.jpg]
GPS Board Soldered
	
	
* Using the 2.6mm spacer, 2.5mm x 8mm bolt, and 2.5mm Nut, the GPS board through the mounting hole to the OTEStamper Board.

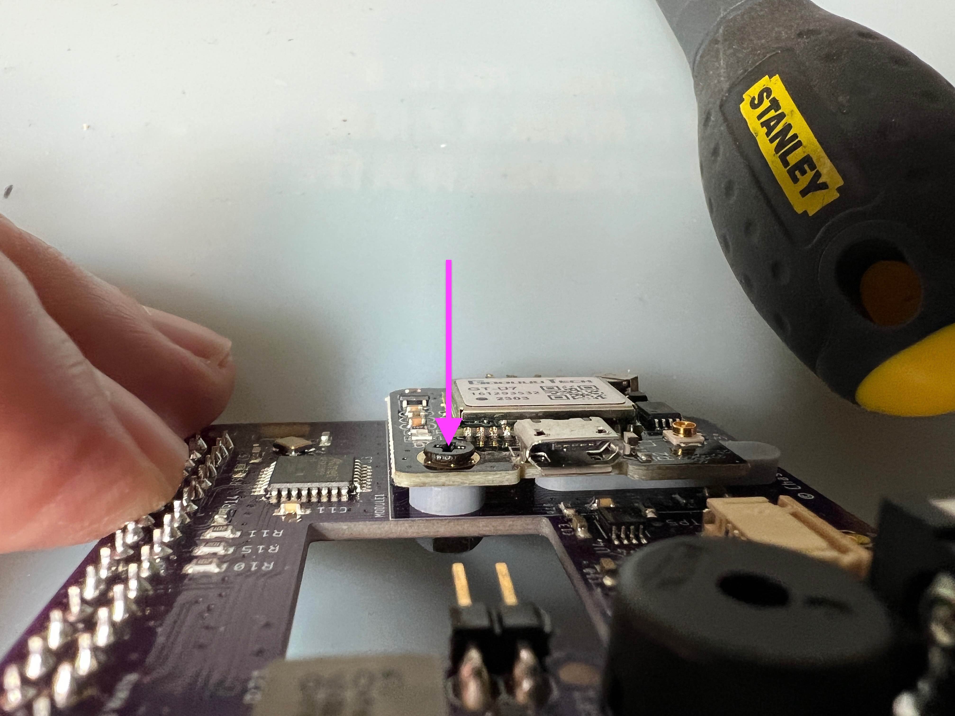
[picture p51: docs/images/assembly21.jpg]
GPS Mounting Hole
	

* Hot-Glue the 3D-Printed Power Socket Block underneath the OTEStamper Board.

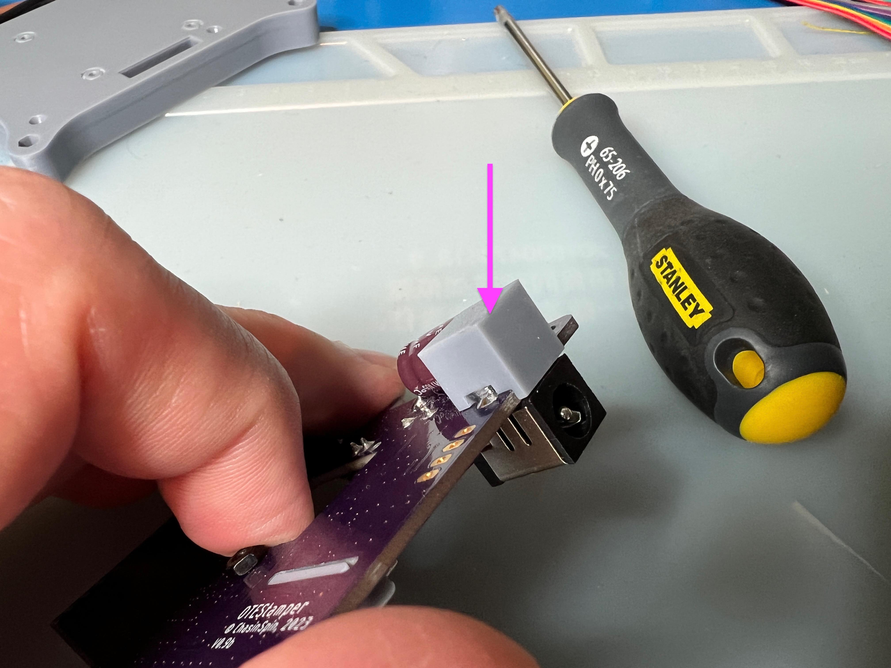
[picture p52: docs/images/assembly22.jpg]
3D-Printer Power Socket Block
	
	
* Attach GPS Pigtail, being careful to push the connector on squarely to avoid damage.  Zip-tie the cable as shown to avoid accidental disconnection.  Trim the free end of the zip-tie.

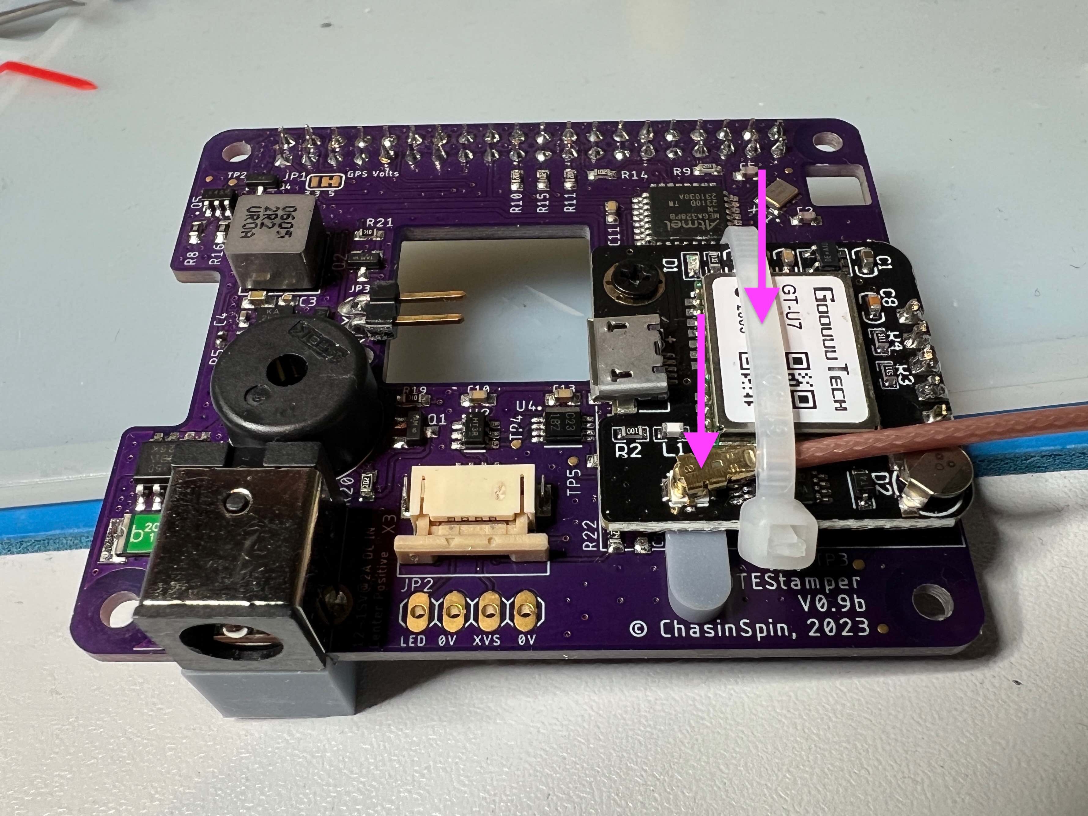
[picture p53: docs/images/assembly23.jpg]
GPS Pig-Tail Attached
	
	
* Attach Hex Standoff and bolts as shown.

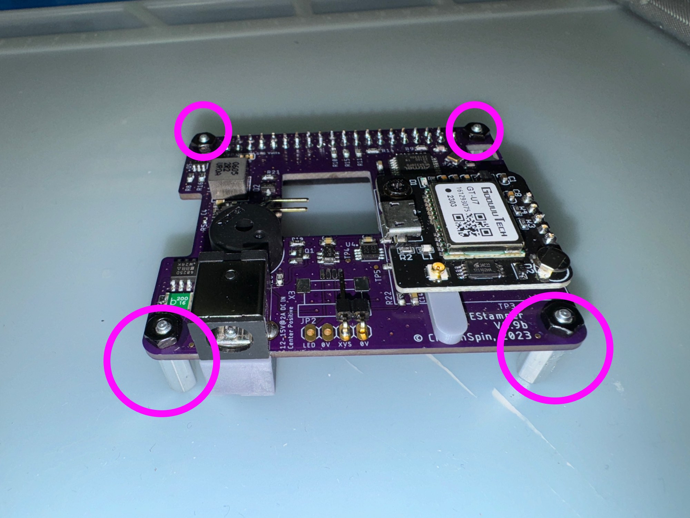
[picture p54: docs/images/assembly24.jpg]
	
	
* Clip the 0V pin on the 0.1\" right angled header.

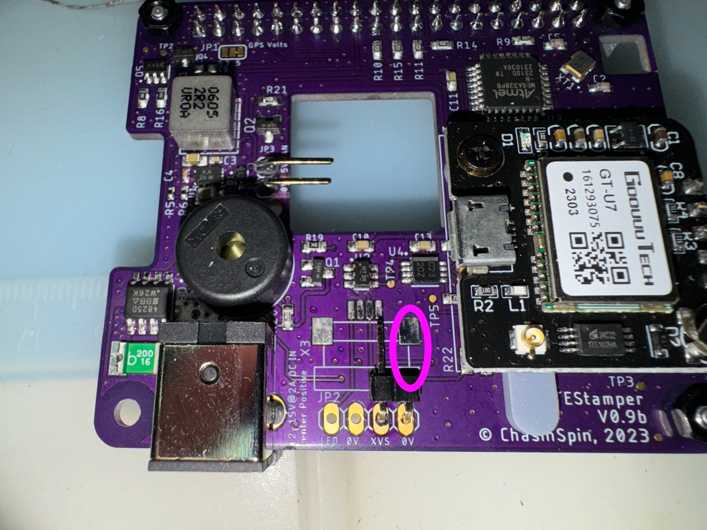
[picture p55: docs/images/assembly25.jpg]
	
	
## Case Preparation

* Super-Glue the 4 Camera Mounting Posts to the case bottom in the indents provided.  Ensure the indents are cleared out sufficiently so that the posts will sit flush within the groove, as clearance has been designed to be a minimum for the camera board.

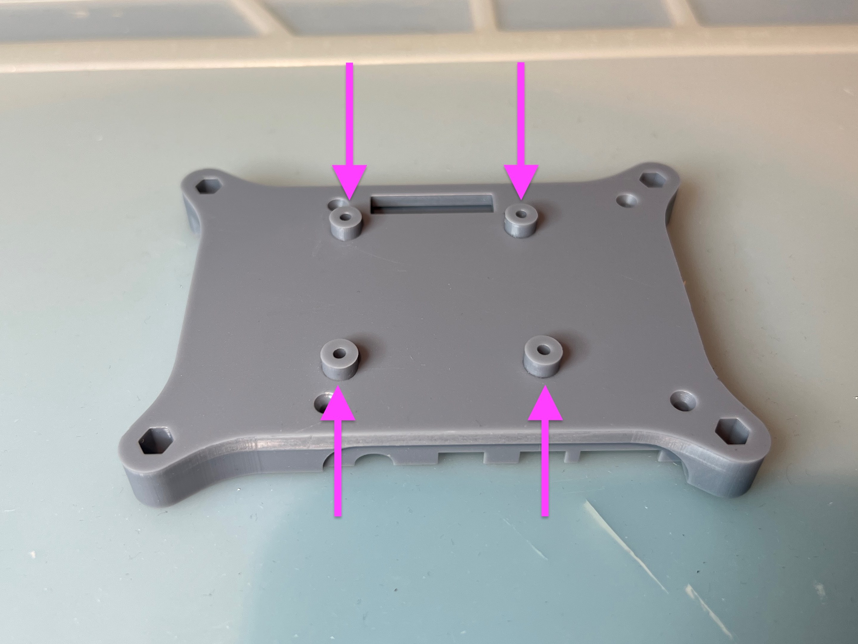
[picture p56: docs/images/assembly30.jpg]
	
	
* Insert the 4 2.5mm nuts in the recesses in the case bottom.  Use a drop of super-glue at the edge of the nut to glue to the case such that the glue wicks into the space.  Do not foul the inside thread with super-glue.

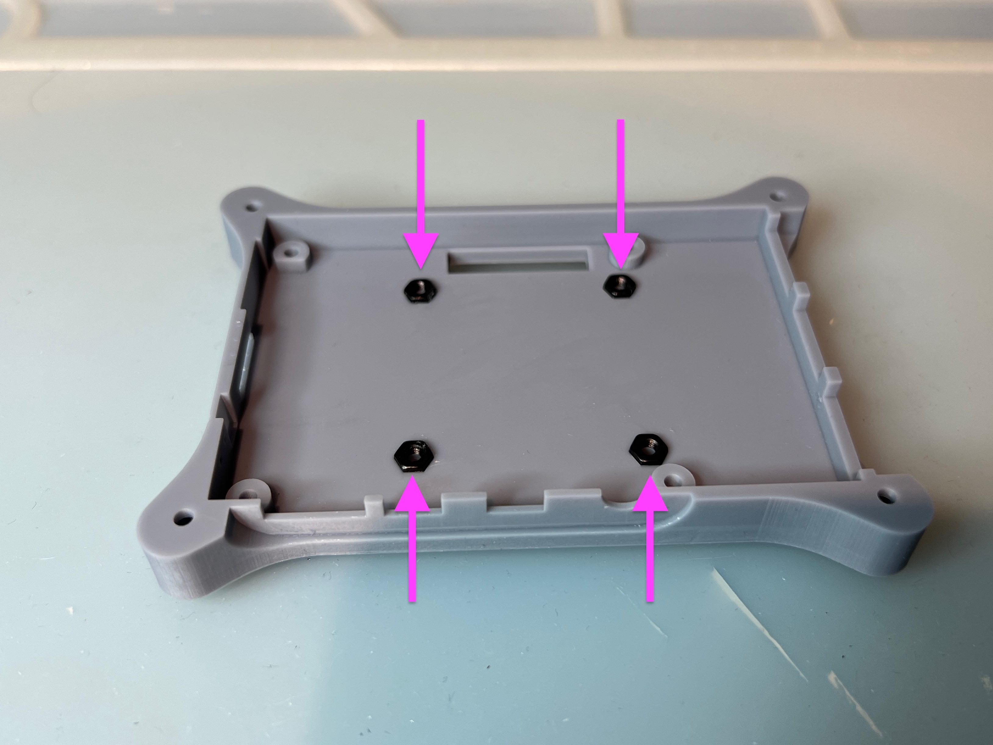
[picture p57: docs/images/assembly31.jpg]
	
	
* Cover the nuts with a layer of electrical tape to prevent any possibility of short-circuiting with the Raspberry Pi board.

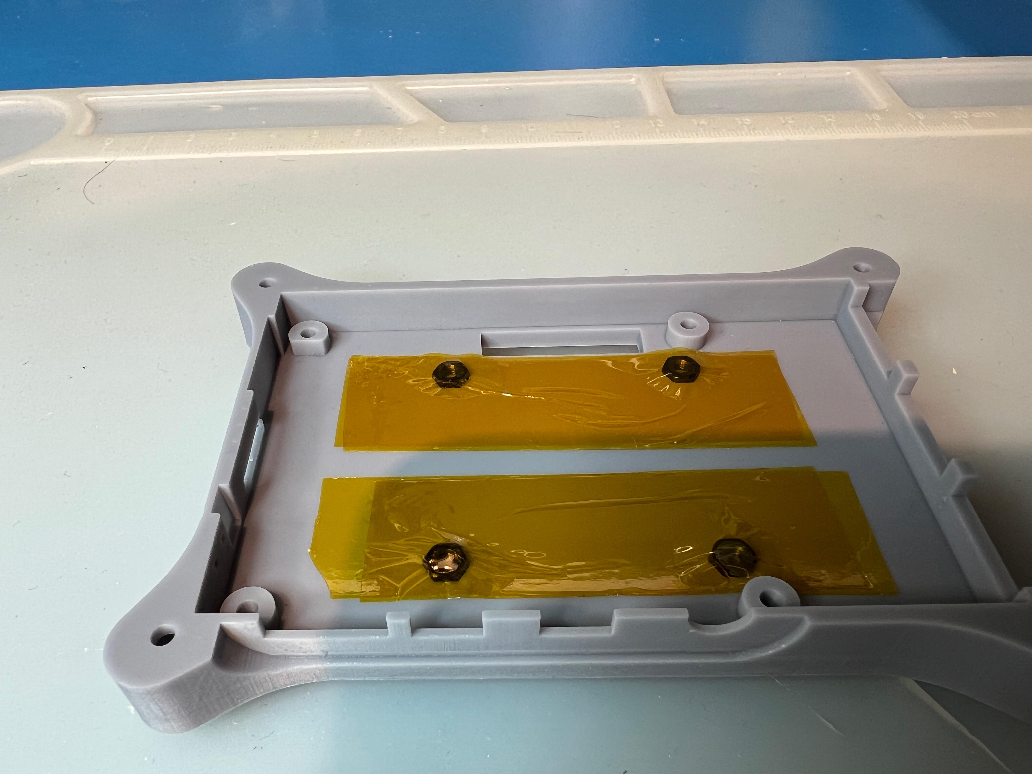
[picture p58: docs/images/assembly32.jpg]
Nuts Covered
	
	
* Attach the fan to the case, note the fan is oriented such that the label is towards the top of the case. The fan clips are very delicate and can snap, snap in place carefully, and do not force.  If a clip breaks, super-glue can be used to fix.

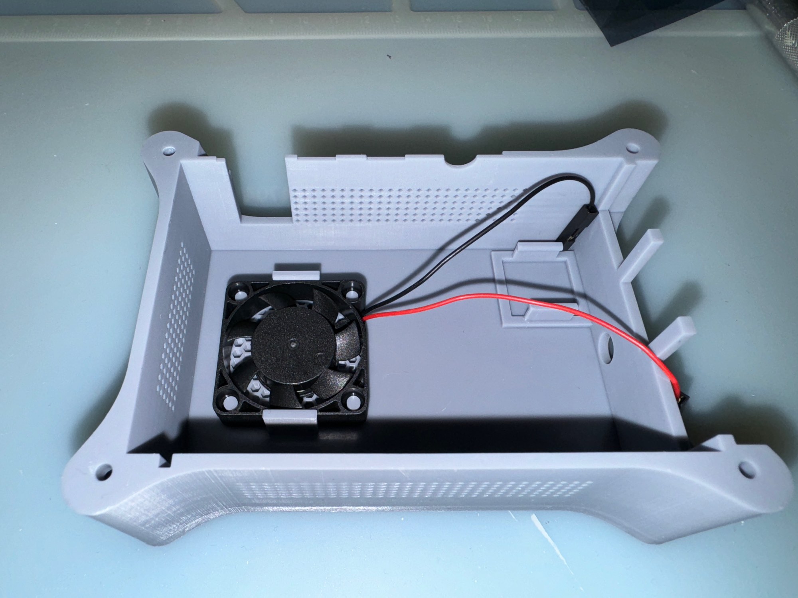
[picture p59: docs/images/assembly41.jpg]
Fan and Pigtail attached


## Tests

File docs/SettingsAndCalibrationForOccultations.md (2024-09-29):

# Settings and Calibration For Occultations

* [Introduction](#introduction)
* [Summary](#summary)
* [FPS](#fps)
* [Gain](#gain)
* [SNR/DNR](#snr/dnr)
* [Darks](#darks)
* [Flats](#flats)
* [Bias](#bias)
* [Binning](#binning)

## Introduction

One of the most common queries among amateur astronomers and astrophotographers is: what settings do I need to record an occultation?   This is a crucial and intricate topic, as it involves a multitude of noise sources and signal-processing techniques. It's important to note that the techniques used for Astrophotography (Pretty Pictures) and Occultations are distinct. When it comes to occultations, our primary focus is on the data and the end result rather than aesthetic appeal.

An OTE tool does the heavy lifting for occultation analysis. My experience is with PyMovie and Pyote, and I haven't verified other tools in terms of the information here.

Also, this information is primarily for recent Digital CMOS sensors, like Astrid. Other sensor types or very old sensors, including analog sensors, may have different considerations.

This is my opinion, and the opinions of some others in the occultation community differ; where I have seen debate in the past, I back up the following with real-life examples and rationale. If you disagree, I encourage you to repeat the experiments and verify for yourself.

It also may not apply to every scenario. For example, an occultation campaign may specify the lowest SNR value, or they may be measuring something different than when a star disappears and reappears.  I.E. They may have other considerations for requesting certain requirements.

Signal-to-noise ratio(SNR) can often mean different things, depends on the source of the noise and the signal. Also, Pyote now has DNR (Drop-To-Noise Ratio).  SNR always refers to the context in which it's being used.

Finally, this guidance is for Occultations only. Astrid is capable of regular astrophotography, and you should use regular techniques (darks, flats, bias) when doing so.

## Summary

In short, record as follows Astrid:

### Gain = 16

...unless the star is so bright it's above the orange line in Exposure Analysis, in which case reduce gain to avoid saturation of the star due to scintillation.

### FPS as fast as you can

For the magnitude of the target, you need the purple line above the cyan background line in Exposure Analysis (where it starts to curve upwards).

Faster frame rates maximize your chances of discovering a Binary Asteroid or Binary Star.  However, you need to balance this with being able to detect the star in the analysis.

In practice, one easy test for this is to see if you can see a star of similar magnitude in video mode when stretched. If you can, it will work; if you can't, decrease the fps until you can.

### Don't sweat DNR/SNR

You're good if your green bar in Pyote is to the right of all 3 red bars.  Maximizing DNR/SNR by increasing exposure is a zero-sum approach and not needed.

However, you should add 6 or 12 static apertures on the target in Pymovie of varying radiuses, and then select the one that gives you the highest DNR/SNR for the event in Pymovie instead.

### You don't need calibration frames

There's no need for Darks, Flats or Bias frames.

### Keep your optics clean

Enough said!

## FPS

**EXAMPLE GOES HERE**

## Gain

Quantization error.
**EXAMPLE GOES HERE (divide pixels by 10 to demonstrate impact on results, reduce color indexes number to show color pixelated image)**

## SNR/DNR

DNR (Drop To Noise), commonly referred to (and historically) as SNR (Signal To Noise), refers to the signal level of the occultation compared to the noise level when the star is not occulted.  It's a measure of the quality of the observation. This should not be confused with the SNR of the star (i.e. the image).

A better DNR does not equate to more accurate timing.  The disappearance and reappearance times and the +/- error bars associated with them, as well as the magnitude drop, remain the same regardless of the DNR.  This is because DNR improves with the square root of exposure, and timing accuracy varies with the square root of exposure. They cancel each other out, so therefore despite seeing a better DNR with a longer exposure, there is no gain to timing accuracy. This makes sense when you consider that the total information from the camera being input into the analysis software is the same regardless of the exposure time.

It's pointless to try to maximize DNR by increasing exposure, nothing is gained.  Provided you have enough DNR to statistically recognize an event and the green bar in Pyote is past the 3 red bars, then you have enough DNR.

**EXAMPLE GOES HERE**

## Darks

It is not necessary to take dark frames to calibrate occultations, here's why:

The Astrid sensor and most modern CMOS sensors have low dark current.  For Astrid, this is 3.2 electrons per pixel per second @ 25C.  In comparison, the readout noise for the sensor is 2.2 electrons.  Both of these are far below the typical [shot noise](https://skyandtelescope.org/astronomy-blogs/astrophotography-signals-noise/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,in%20otherwise%20smooth%2Dtoned%20areas.) you see in the sky.

Dark current is proportional to the exposure time. At 10 frames per second, dark current noise is 3.2/10 = 0.32 electrons, which is minuscule in relation to the readout noise (which is already minuscule) and the shot noise. Also, darks add processing time during the analysis.

For Occultations, we just don't need darks.

## Flats

Flat frames measure the variable transmittance of the optical system across the field of view.  This can vary due to lenses, mirrors, vignetting etc.

There are a few reasons why taking flat frames is not needed:

* The sensor in Astrid is small and covers a small central area of the telescope's field of view.  This is the area over which there is little vignetting anyway, which is the main reason for flat fielding.
* The scale of any flat correction needed is far below the mag drop you see on the majority of occultations.
* Unless your mount is not tracking, the star remains in the same place in the frame, i.e. it's not varying due to different transmittance as it moves across the FOV.
* Flat Field variations typically are just not that much.  They tend to show up on pretty picture stacking due to the algorithms used, stretching, and the low signal-to-noise ratio of Deep Space Objects(DSO).  However, with occultations, this is less of a consideration.

Reasons why they may **sometimes** be needed are:

* Comparing magnitudes to other stars in the field, however, the flat field would need to be particular bad and the detection requirements high.  This would be more likely to apply to exoplanet transits than occultations.
* The cleanliness of your optics is very poor.

*If you can't see it on the image, you don't need to correct for it.*

Suggestion: Use some of the time it would have taken to acquire flat frames to keep your sensors and optics clean.  Defined dark spots on the image are generally dust on the sensor, clean it and keep it clean by capping or leaving the IOTA focal reducer on.  Less defined dark spots (i.e. defocused) are generally heavy dirt on the telescope optics/lenses and cause less of an issue.

## Bias

Bias Frames can be thought of as the default value of each frame that's read out from a camera when it's dark at the shortest exposure possible.  It represents the offset of a particular pixel (the pedestal).  An ideal camera sensor would have the same offset for each pixel, but in reality, there are manufacturing variances between each individual pixel leading to typically 1 or 2 count variances, plus or minus the average value.

Bias correction is not necessary; the signal of the star is above the bias anyway. Otherwise, you couldn't analyze it, and accounting for the variance is handled by PyMovie in the analysis automatically by the statistical processes involved.  Also, bias varies from frame to frame for video.

Some poor sensors may benefit from a bias frame, but most modern sensors do not need it where the signal is strong, as it is for occultations.

## Binning

Binning is the process of averaging pixels, and it has different impacts depending on whether you are using a CCD or CMOS (Astrid) sensor.

A CCD sensor creates a superpixel when binned.  So, for example, a 2x2 binned CCD will combine 4 pixels into a superpixel.  This superpixel accumulates charge quicker (at the expense of resolution) and only has one readout noise as opposed to 4 readout noises with individual pixels. Hence the Signal-To-Noise Ratio (SNR) is higher binned than unbinned.  CCD cameras have higher readout noise than CMOS.

However, most sensors today are CMOS sensors (as is Astrid), they have a different architecture and don't bin at the pixel level. This means that every pixel read out from a CMOS sensor is unbinned, and binning happens in software (either in the camera itself or in external software). The read noise on CMOS sensors is considerably lower than CCD, and although a 2x2 software bin with CMOS sensor data would result in 4 x readout noises, the total of that is still considerably less than a CCD sensor due to the low readout noise of CMOS.

Binning on CMOS still improves the image's SNR as it averages pixels. So, if you compare two images, binned and unbinned, you'll be able to see stars in the binned that weren't visible in the unbinned. However, due to the math employed in the OTE analysis and the radius around the star, it doesn't change the timing or accuracy of the result.

There may be some outside considerations where the size of the star on the camera and the telescope are mismatched, so you can get better performance/analysis with binning...

However, ordinarily, binning does not provide any advantage to timing or it's accuracy.

**EXAMPLE GOES HERE**

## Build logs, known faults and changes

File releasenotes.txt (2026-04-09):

Version 1.0.057
================

	* Mini Display can now poweroff Astrid, note that if the Astrid app is recording, it may lead to corruption, to power off:
		a) Press the bottom button on the left on the Mini Display
	* Mini Display has changed version to 1.3.0, you will need to upgrade your Mini Display, to do this:
		a) Disconnect your mount from Astrid and connect the Mini Display
		b) Close the Astrid application if you're already running it
		c) Open the Astrid Tools Folder on the Desktop
		d) Run "Install Mini Display" and follow the instructions to update
		e) Restart you Astrid via the Astrid application
	* Crosshairs setting removed from General, Crosshairs was removed a while back and the setting still remained, cleaned up
	* Events with / in the name were causing failed recordings, now fixed 

Version 1.0.056
================

	* ** IMPORTANT ** OWCloud now requires an API Key for Syncing from Events Astrid to OWC
		1. Obtain your API Key on OWCloud:
			a) Login to OWCloud with a web browser
			b) Click "Welcome, YOUR NAME" and choose "User Profile"
			c) Click "User Permissions"
			d) Verify your email
			e) Click Get API Key
		2. In Astrid:
			a) Copy the API Key from OWCloud above
			b) Put API Key into Settings/Observer/OWC API Key in Astrid
			c) Sync to OWCloud as usual
	* Fixed error handling on connecting to OWCloud when internet is not available, it now produces an appropriate error

Version 1.0.055
================

	* Changed manual entry of occelmnt to default to Add Start / End Secs of a minimum of 30 seconds. Recommended way to add events is via OWC Syncing, 
	  manual entry like this is discouraged. If you enter events manually, you should also check very carefully all the details before adding the event.

Version 1.0.054
================

	* Fixed issue where ravf wasn't being upgraded on Astrid Upgrade causing ravf integrated files not to load in Player

Version 1.0.053
================

	* Fixed issue with Custom Objects not being found

Version 1.0.052
================

	* Fixed issue when a Mount has an integrated Focuser, an external focuser can't be added.  Now, the Focuser Device Name is used as a hint to determine the correct device to use.
	* Added satellite positioning capability with TLE download via space-track.org.  See Space-Track settings and new satellite database.

Version 1.0.051:
================

	* Fixed bug introduced in version 1.0.050 which caused focus settings not to be created

Version 1.0.050:
================

	* Added Electronic Focuser Support
	* Settings are now more robust to config files corrupted during write, e.g. when a USB Drive is Full. Zero length files are reported, and backed up prior to writing with an auto recovery facility

Version 1.0.049:
================

	* Added the capability to wirelessly connect to mounts.  Wifi/ethernet capability added. Note: Network connections to mounts maybe unreliable and are unsupported. See mount settings
	* Reworked prepoint dialog, now has ability to retry failed solves without cancellation
	* Fixed issue with cancel during Prepoint, not cancelling the Plate Solver as per Ted Blank

Version 1.0.048:
================

	* Added site filter to OWCloud downloads in settings/observer as per Vince Sempronio
	* Added Set Time and Set Site checkboxes to settings/mounts for mounts that don't play nice when having the time/site set
	* Added indi_connection_method, ip_addr, ip_port to settings for mount in preparation for support for connections to the mount over wifi
	* Fixed issue introduced in 1.0.047, where Player failed during platesolving due to logging changes

Version 1.0.047:
================

	* Changed plate solver to output to astrid.log and trapped rare error where it's unable to split to investigate further

Version 1.0.046:
================

	* Added exposure to "Other Detector related info" field in the North American Report Form as per request from Steve Conard

Version 1.0.045:
================

	* Fixed issue with Polar Align exception at end of polar align routine introduced in V 1.0.044

	* Added magnitude range and marker on exposure chart

	* Added USB Thumb Drive near full detection with "Min Free Drive Space" setting in Settings / general. Astrid now alerts on startup when below this threshold

Version 1.0.044:
================

	* Added new warning message for Auto Record, when video frame rate is slower than 1/2 the maximum event duration

	* Added automatic removal of bad ASTRID drive mount point caused by power removal without shutdown

	* Now logs the power voltage every 5 minutes for 2 purposes, provide an audit trail for faulty/inadequate power and to show Astrid is alive when it's idle

	* Now logs more user interaction for Auto Record and recording in Photo and OTE Video modes

	* Mount settings for indi module and usb tty are now constrained to a choice list.  Mismatch between indi driver name and settings driver name is now detected and prompted to auto fix

	* Added Ra/Dec as an option for "Direction Indicator for PlateSolve" in settings. Against better judgement, added the ability to indicate distance from plate solve to target as an
	  Ra and Dec delta as it's been requested a few times by users. However it comes with the caveat and a warning that it will not be completely accurate for Prepoints, because the earth
	  rotates. 

	* Prepoint now handles exposure=0s to launch file open dialog for selecting previous test images

Version 1.0.043:
================

	* Fixed bug that was reintroduced by change in 1.0.042, where if the occultation target wasn't goto'd, the RA/DEC of the target were not recorded in the .ravf metadata, preventing the target identification crosshairs in Player.

Version 1.0.042:
================

	* Fixed frame rate and exposure duration to "Switch to OTE Video" prompt when Auto Recording

Version 1.0.041:
================

	* Fixed bug where the "Object Found, Goto?" always results in a Goto, even if No is selected

	* Added frame rate and exposure duration to "Switch to OTE Video" prompt when Auto Recording

	* Prepoint window is now further to the left of the video window

	* When syncing events from OWCloud, the default start/end times are "at least" 30 seconds prior to the start and 30 seconds after the end of the event.

	* On the Auto Record panel (and other panels where date/time editing is disabled), the up/down arrows have been removed for clarity

	* Cleanship script (for Ted) now reactivates the privacy notice

Version 1.0.040:
================

	* Added Lights Out Capability to Astrid Tools

Version 1.0.039:
================

	* Added scripts to make installing image and cleaning for shipping easier for Ted

Version 1.0.038:
================

	* Fixed issue with qt5 where negative declinations between 0 and -1 degrees were made positive if manually entered (including via cut and pasted occultation elements) instead of events via OWCloud

Version 1.0.037:
================

	* Changed behavior where if an occultation is selected, and not "go-to'd" on a goto scope, the RA/DEC of the target are not recorded
	  to the .ravf file.  They are now recorded to the .ravf file.

	* Fixed bug in player where ravf_integrated videos didn't load in player (also requires new ravf version)

Version 1.0.036:
================

	* Fixed bug where a Prepoint (or platesolve when a target is selected), if the telescope is pointing near the North Celestial Pole, caused
	  Astrid to quit as it was unable to paint the target. This is due to the NCP being a singularity, so it's impossible for the Astrometry system
	  to paint a bullseye indicating the position of the target. The target is no longer painted in this situation until the user has moved away
	  from the NCP either via a Goto or Prepoint.

Version 1.0.035:
================

	* Selecting an occultation is now disabled unless status buttons are green (so that site location/predicted time difference can be calculated)
	
	* Added OCCULTATION-PREDICTED-CENTER-TIME-FULL to ravf metadata that includes microseconds for the predicted center time

Version 1.0.034:
================

	* Changed camera tuning settings to uncalibrated, to improve linear response (handled by PyOTE)
	
	* Fixed a bug, where having internet and then not having internet when an IERS update is rerequired can cause astrid to stop
	
	* Fixed a bug that caused astrid to stop when a configuration with a goto mount was being used, but no mount was connected

	* Player now uses the focal length for plate solving stored in the video if it's available

	* Photo acquisition now maintains contrast when display options are changed
	
	* Image flipping is now maintained when display options are changed

	* Screen response to the camera is now linear (gamma removed) so that switching from photo/video maintains contrast/brightness
	
	* Lower end stretch set to 15 which is the dark offset of the camera

	* Added auto stretches (Histogram Equalization, CLAHE and MinMax Presets/Custom)
	
	* Fixed a bug where version was displayed as None when not connected to the internet
	
	* Added the software version number to the ravf metadata

Version 1.0.033:
================

	* Added "Export OWCloud Locations" to Occultations List to speed up multi-chord deployments

	* Added check for the usb drive being inserted into the USB3 socket

Version 1.0.032:
================

	* Eeprom is now saved (Fuse EESAVE) across Astrid Upgrades, which speeds up time to record after upgrade if Leap Seconds is stored in eeprom

	* Warning now appears when switching off Full Sky Solve to prevent accidental switching off

Version 1.0.031:
================

	* diagnostics.sh now no longer picks up the Mini Display
	
	* Format USB now no longer picks up the Mini Display

	* Made instructions more visible for USB Drive reinsertion when formatting USB key

	* Added Qualify Drive
	
	* Drive Qualification now required

Version 1.0.030:
================

	* Improved usb drive indentification code

Version 1.0.029:
================

	* Preventing > 10fps warning happening in auto record when recording starts

	* Adding support for Adafruit ESP32-S3 Reverse TFT Feather for the Mini Display

Version 1.0.028:
================

	* Fixing bug with Mini Display drive being picked up on the drive speed check at start instead of the Astrid Drive

Version 1.0.027:
================

	* Updating Mini Display to implement Link Quality as a percentage and adding Signal dBm
	
	* Mini Display top line turns Red if WiFi signal is not adequate

	* WiFi Power Management REALLY disabled
	
	* WiFi connect maintained if astrid-monitor dies or is killed 

Version 1.0.026:
================

	* Updated Mini Display to display switching on button press

	* Auto Network Switching Removed
		- Astrid now boots up in Hotspot Mode
		- Use Mini Display to change to Wifi Mode OR
		- Login via VNC to Hotspot and click "WiFi Connect"

Version 1.0.025:
================

	* Amended CameraModel for /dev/tty/ACM* mounts to exclude Mini Display

	* Renamed Kill Astrid to Terminate Astrid Threads on desktop

	* Added Shutdown icon on desktop
	
	* Adding astrid-monitor service and Mini Display support/installation

	* WiFi Power Management Disabled
	
Version 1.0.024:
================

	* Added autorepair to corrupt .ravf's in Player

	(no changes to Astrid App)

Version 1.0.023:
================
	
	* Reorganized lesser used icons on the Desktop into "Astrid Tools"

	* Added "Upgraded to" version notice in the install script.
	
	* Improved Player icon

	(no changes to Astrid App)

Version 1.0.022:
================

	* Adding ravf_integrate.py (no changes to Astrid App)

Version 1.0.021:
================

	* Adding writetest (no changes to Astrid App)

Version 1.0.020:
================

	* Added checks and warnings for USB drives that are not UASP and/or USB3 compliant on Astrid Startup and also when using manual recording

	* Added diagnostics primarily to test USB Drives

Version 1.0.019:
================

	* Removed some redundant code in CameraModel

	* Reduced suggested maximum frame rate to 20fps for now because of Sandisk USB Drive Non Compliance

Version 1.0.018:
================

	* Fixed ability to manually record and auto record concurrently, also disables fields in Task and Object during manual record.

Version 1.0.017:
================

	* Addded additional logging to framewriter for dropped frames diagnosis

Version 1.0.016:
================

	* Reduced maximum frame rate suggested to 25fps, as 30fps is very close to 100% cpu

	* Added error reporting to acquisition for dropped shared memory frames due to all the frame buffers being used

	* Fixed bug where errors during recording prevent recording being stopped

Version 1.0.015:
================

	* Added MagRP and MagBP to last checkin to give some estimation of spectral type for comparison	

Version 1.0.014:
================

	* Added annotation tool to Player that identifies stars and magnitudes via a csv file created in the occultation video folder.

Version 1.0.013:
================

	* North American Report AutoFill has some fields as text that should be numbers for auto processing by IOTA, fixed

	* Fixed so that return/enter now works on fields (validators).  Qt validators are poorly designed, there shouldn't need to be so many special cases like this.

Version 1.0.012:
================

	* Adding asteroid number search to search occelmnt xml

Version 1.0.011:
================

	* Fixed bug where occasionally on startup with new unixEpoch generator, datetime would crash and status boxes turn purple

	* Increased allowable system time / gps time delta from 2 to 30 seconds

	* Added INSTRUMENT-FRAMES-PER-SECOND to metadata

	* Added "This report was pre-populated by Astrid" the north american report form

Version 1.0.010:
================

	* All goto prepoints now switch tracking on after the prepoint and then immediately off so slew complete can be detected

	* Testing on obejct target crosshairs on prepoint showed and issue with prepoints where the target was displayed instead, fixed (not completely tested due to cloud coming in)

	* Derated GPS/Timing/Acquition to permit recording when yellow too

Version 1.0.009:
================
	
	* Object target crosshairs are now displayed when a target or prepoint location is selected

	* Changing target was causing a crash with the new UIValidator, fixed

Version 1.0.008:
================

	* Goto button is now disabled on Goto Prepoints whilst the scope is moving

Version 1.0.007:
================

	* Added Remove wifi network and Disable Local DNS to Wifi Setup

	* Reduced startup time with no internet by 5 seconds
	
	* Timing Status Button is now red when system time differs from GPS time by more than 2 second
	
	* GPS Time/System Time difference split out to Delta Chrony and Delta Timestamp

	* Video recording, prepointing and auto record prevented if GPS/Timing/Acquisition are not Green and/or Site is Red

Version 1.0.006:
================

	* Auto-Fill of North American report form now handles star catalogs: UCAC2, UCAC3, 1B, 1N, URAT1 and G

	* Fixed floating point and integer validators in fields to process incomplete entries better

Version 1.0.005:
================

	* Fixed bug where Astrid quits when fits file does not contain FOCALLEN value

	* Upped max frame rate to 5000 fps for daylight focusing

Version 1.0.004:
================

	* Added "Save Fits Finder" to Player, which can be used after a plate solver to identify the target.  This can be loaded as a finder image into pymovie to make it easy to place targets - Suggestion Brian Heimes

	* Improved constrast of target maker in Player by using 2 contrasting colors

Version 1.0.003:
================

	* Fixed autohotspot upgrade installer

Version 1.0.002:
================

	* Added privacy policy

Version 1.0.001:
================

	* Added Astrid version number to Config Dialog on startup - Suggestion Ted Blank

	* North American Report Form AutoFill now fills out corrected values as per Jerry B.  Also IOTA had version 5.6.12 labelled 5.6.11 internally.
	IMPORTANT: Please delete previous template form from the USB Drive after software upgrade, and launch Astrid to download the new one.

	* Moved Time from Display 1 Panel to Status Panel - Suggestion Ted Blank

	* Site "Yellow" status increased from a 10m difference to 15m difference to reduce triggering.
	
	* Auto record will now start if the recoding start time is after the event start time, but before the event end time
	
	* Added frame timestamp to Player

Version 1.0.0:
==============

	* Added wifi network connectivity indicator on ethernet port:
		Flashing alternate green/yellow = connected to a known wifi network (typically with internet)
		Solid green/yellow = advertising astrid hotspot wifi (no internet connection)

	* Added version identfication and upgrade prompt when online

Version 0.9.30:
===============

	* Initial version

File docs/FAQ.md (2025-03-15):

# FAQ

* [Power Jack Is Intermittent](#power-jack-is-intermittent)
* [Cleaning the Astrid 3D printed case](#cleaning-the-astrid-3D-printed-case)
* [I have multiple Astrids, do I need a computer for each one?](#i-have-multiple-astrids-do-i-need-a-computer-for-each-one)
* [What's the best device to control Astrid?](#whats-the-best-device-to-control-astrid)
* [Unattended setups, do I need to leave my tablet/computer/phone?](#unattended-setups-do-i-need-to-leave-my-tabletcomputerphone)
* [Is Astrid for Prepoint only?](#is-astrid-for-prepoint-only)
* [Which video analysis software is supported?](#which-video-analysis-software-is-supported)
* [Which light curve analysis software is supported?](#which-light-curve-analysis-software-is-supported)
* [Astrid, Hot Climates, Cold Weather, and moisture](#astrid-hot-climates-cold-weather-and-moisture)
* [Stealth Mode - removing lights for unattended operation](#stealth-mode-\--removing-lights-for-unattended-operation)
* [Stretching (display)](#stretching-display)
* [Plate Solving Arrows On Manual Equatorial Mounts](#plate-solving-arrows-on-manual-equatorial-mounts)
* [Star/Planet/Moon Saturates At Highest Video Frame Rate](#starplanetmoon-saturates-at-highest-video-frame-rate)
* [Optical Train Dimensions and BackFocus Distance](#optical-train-dimensions-and-backfocus-distance)
* [Does Astrid Require Internet](#does-astrid-require-internet)
* [Which Version is Astrid](#which-version-is-astrid)
* [Failed Upgrades](#failed-upgrades)
* [Copying the USB Drive](#copying-the-usb-drive)

### Power Jack Is Intermittent

If the power jack is intermittent, then please push the plug fully into the jack.  Astrid's power jacks are high-power, high-grade power jacks designed for long life (unlike many astro devices).  To enagage the jack fully, it needs to be fully pushed in which may take some pressure, especially when new.

### Cleaning the Astrid 3D printed case

There are 2 types of cases that ship with Astrid, the older Resin Case, and the newer FDM printed ASA case.
	
For the Resin case ONLY, use Acetone to remove marks the case, be careful to to touch anything with the acetone which is not the resin case as it will melt plastics.
	
For the FDM printed case, clean it damp cloth or a bit of Isopropyl Alcohol.
	
The case should only be cleaned with power off, being careful not to use access solution that will get into the device.

### I have multiple Astrids, do I need a computer for each one?

Only one computer/tablet or phone is needed to control all Astrids

### Do I need an Astrid Mini Display for every Astrid?

No, you only need one for all the Astrids you own, it can be unplugged and moved to another Astrid
	
### What's the best device to control Astrid?
	
A tablet that can run VNC (e.g. iPad) is the most convenient to control Astrid as it's very portable and a reasonably large screen.  However a phone could be used (smaller screen) or computer (larger screen but more bulky)
	
### Unattended setups, do I need to leave my tablet/computer/phone?

No, Astrid will keep runing despite you not being connected to it, take your tablet/computer/phone with you.
	
### Is Astrid for Prepoint only?

Astrid can be used with Goto scopes too, any scope supported by Indilib is supported by Astrid
	
### Which video analysis software is supported?
	
Currently, only Bob Anderson's PyMovie has support to read the RAVF video files that Astrid generates. Astrid does not generate ADV format files due to the lack of 10-bit RAW support. Astrid player can convert to FITs files, but you will lose audit information that Astrid generates and that conversion would take a long time. Limovie and Tangra do not support RAVF at this time, if you wish to see Astrid run with these applications, please contact their authors to request. Once the light curve has been extracted by PyMovie, it can be read in PyOTE, AOTA, ROTE or Occular.
	
### Which light curve analysis software is supported?

Once the light curve has been generated in PyMovie, it can be analyzed in PyOTE, AOTA, ROTE or Occular.

### Astrid, Hot Climates, Cold Weather, and moisture

Astrid normally runs above ambient temperature, so generally inside the case little moisture or ice will accumulate.  However if the temperature outside is substantially below freezing, to the point that condensation would form on the case when brought inside, then it is advisable to place in a container until warmed to room temperature and then open the container to remove any remaining moisture.  This would be the same treatment you would apply to a telescope.

Astrid is not waterproof and shouldn't be subjected to rain or snow. Also, it's not weatherproof, so don't leave it outside permanently, as is the same with most astronomical equipment.

One user loosely covers Astrid on top with a plastic bag leaving space for venting if they have concerns about rain overnight.  Astrid does generate heat, and it's advisable not to completely enclose it to avoid overheating.

Also, Astrid is subjected to Canadian weather and so far has been tested to -30C with no issues encountered to date.
	
In hot climates, make sure you have adequate venting around Astrid.
	
### Stealth Mode - removing lights for unattended operation

Astrid has a number of leds on it that may blink or glow, they are made available so that the status of the device can be seen:
	
* GPS LED (red flashing once per second with GPS fix)
* Raspberry Pi: Red LED (power) and Green LED (activity)
* Network Status LEDs (Green and Yellow, flashing or static)

To use Astrid stealthily, just cover these LEDs with electrical tape on the case. (the GPS LED can be accessed by unbolting the case where the Astrid Logo is, and covering the LED on the GPS board with electrical tape).  Scotch Super 33+ is a suggested electrical tape.
	
Additionally, the Raspberry Pi Red/Green LEDs and Network Status LEDs can be switched off from software via the "Light Out" tool in Astrid Tools on the desktop.
	
### Stretching (display)

Astrid has built-in stretching with 3 different methods. Astrid never stretches the data it saves, which is always saved in raw format.  Stretching is only to make stars easier to see on the display.

*CLAHE (Contrast Limited Adaptive Histogram Equalization* - This can be thought of as an auto-stretch and is Astrid's default. It will automatically adjust and can handle thin clouds, light pollution, smoke, different exposure settings, and glow due to the sun near sunrise and sunset. High values of CLAHE can look soft sometimes, so experiment with the varies settings provided.
	
*Histogram Equalization* - This is a method that adjusts the contrast using histogram equalization so the image is more uniformly distributed across the entire range of values. We have found it to perform a little less well than CLAHE, but your mileage may vary.
	
*Min Max* - This manual method evenly distributes the image between Min and Max.  Values below Min will be black, and values over Max with be White, with everything between distributed evenly as levels of gray.  Min and Max are between 0 and 255 with Min being less than Max.  Some Min/Max values are predefined for your convenience, but adjusting them using "Custom" is often required.  Although Min/Max gives you superior control over stretch, if conditions change (clouds, smoke, light pollution, sun, exposure), you will likely need to change your Min/Max values.
	
### Plate Solving Arrows On Manual Equatorial Mounts	
When Astrid Plate solves, it provides arrows telling the user where to move the telescope. If the scope has Goto, the scope can then move automatically to the location of the target, but if it's a manual scope, the user needs to slew the scope.  Depending on the users' preference, The plate solver can print 2 direction arrows (Altitude and Azimuth) or 1 arrow (overall direction).
	
With Alt/Az mounts, it's simple: Move the mount in the direction of the arrows using the scope's Altitude and Azimuth adjustments.

For Equatorial mounts, the user needs to think in terms of where the scope is visually pointing and make RA/Dec adjustments to slew the scope to the desired location.  Another way to think about this is that it's the same process you would use with an Equatorial mount if you were star hopping from a chart.  You would look at the chart and say I need to go from this star to that star and I need to go up and right and make the RA/Dec adjustments and combine them were necessary to get there.
	
### Star/Planet/Moon Saturates At Highest Video Frame Rate

Occasionally, if the telescope is very large, or stars are bright, the Astrid sensor may saturate at the highest frame rate.  The first method to reduce the brightness is to reduce the gain.  If it is still saturating after that and you need to reduce the brightness further, then use a Neutral Density (ND) filter. ND filters for 1.25" are cost-effective and screw into the barrel of the IOTA 0.5X reducer.

### Optical Train Dimensions and BackFocus Distance

For the optical train dimensions for calculating backfocus, or for ordering the correct adapter to work with a Hyperstar, see the following:

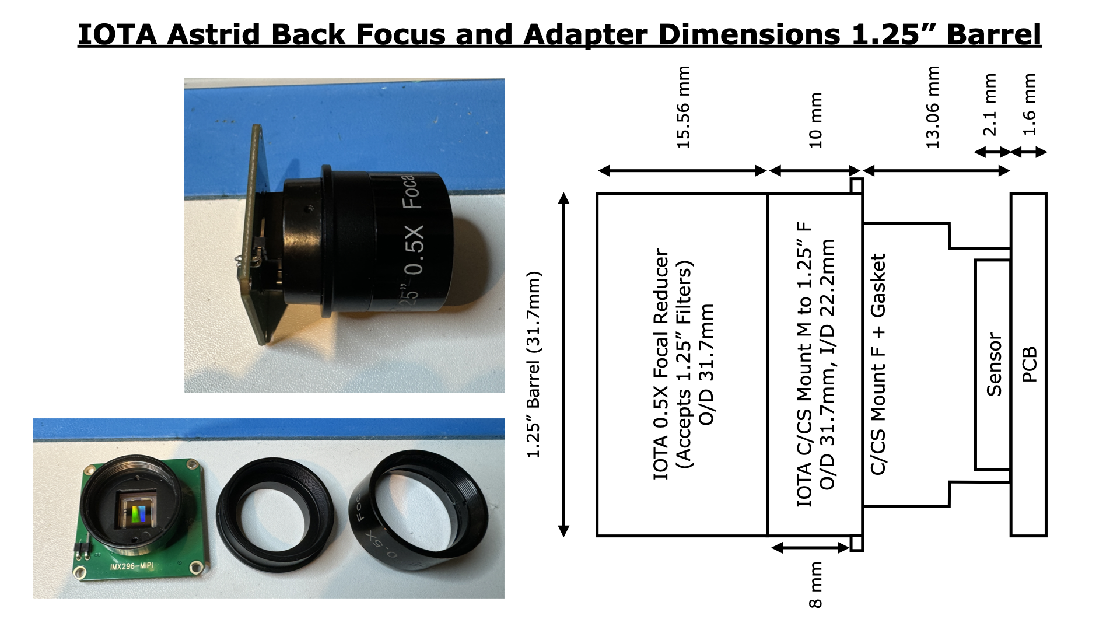
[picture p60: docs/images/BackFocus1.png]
IOTA Astrid Back Focus and Adapter Dimensions 1.25" Barrel


Note: To reduce the focal length further, spacer rings (e.g. 5mm) can be added between the focal reducer and the IOTA C/CS Mount to 1.25" F adapter. A typical SCT can benefit from 3 x 5mm spacer rings and still have focusing range.

An alternative, if you don't require the focal reducer is a straight C/CS Mount to 1.25" Barrel Connector [SVBONY C Mount to 1.25" Video Camera Barrel Adapter](https://www.amazon.com/gp/product/B07R4SSBKC) 

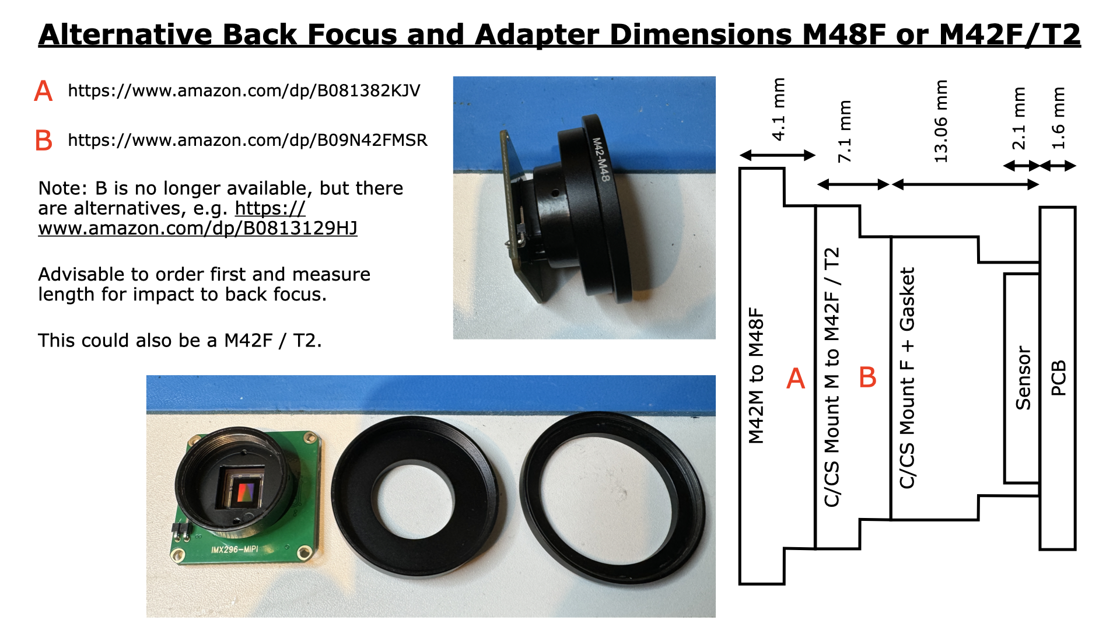
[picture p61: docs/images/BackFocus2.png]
Alternative Back Focus and Adapter Dimensions M48F or M42F/T2


* A: [Metal M42 to M48 Male to Female Step-Up Coupling Ring Adapter](www.amazon.com/dp/B081382KJV)
* B: [C Mount(25mm 0.75mm Pitch) to T T2 (42mm 0.75mm Pitch) Coupling Ring Adapter](www.amazon.com/dp/B0813129HJ)

### Does Astrid Require Internet

Astrid requires the internet for a few features, but it is designed for fully autonomous mobile use without internet.  It can be used where there is no cellular or wifi signal.

Internet is not required for:

* Plate Solving:
    Ted ships the majority if not all of the Plate Solve catalogs on the USB drive, so an internet connection is not required, all plate solves occur with local data from the USB drive and are offline.  If you are setting up a new scope and have deleted unused plate solve files, Astrid will prompt and download for the missing files when starting up when connected to the internet if the correct focal length has been entered in the settings. Plan to roughly configure any new scopes where you have internet.
* Objects (except SIMBAD)
* Occultation Events
* Prepoints

Internet is required for:

* Occasionally once every 3 months to download the latest IERs data for earths' rotation (this happens automatically when connected to the internet)
* Syncing events with OWCloud
* Looking up SIMBAD objects (but you can then save those to the Custom database that is offline)
* Software Upgrades

General advice is to connect to the internet before you leave home and:

1. Do a software upgrade if necessary
2. Sync your stations from OWCloud
3. Download any astro targets you may want to do photography of via SIMBAD and save to Custom (doesn't apply to occultation events)
4. Shutdown
5. Setup at your deployment location (with or without internet)

### Which Version Is Astrid

Astrid's version is displayed on startup on the splash screen.  If you wish to find the version when Astrid is running, or without running Astrid, you can start a Terminal and type:   cat ~/astrid/version.txt

To find the number of the latest version: [Github Astrid Version](https://github.com/ChasinSpin/astrid/blob/main/version.txt)

Astrid will check when started *when internet is connected* to see if it needs an upgrade and prompts you.

### Failed Upgrades

If an upgrade fails (often due to internet connectivity), then just repeat the upgrade.

IMPORTANT: If an upgrade fails and you afe unable to fix by repeating, it's is strongly recommended that you don't reformat the USB Thumb Drive and reimage the SD Card, it will likely make matters worse.  Please reach out for support instead.

### Copying the USB Drive

To copy the USB Drive (for example to backup or as a spare):

* Run the "Format USB Flash Drive" utility in the Tools folder on the Astrid Desktop to format the new drive
* Insert the original USB Drive into your Windows or Mac desktop/laptop and copy the files onto your desktop
* Eject the original USB Drive
* Insert the new USB Drive into your Windows or Mac desktop/laptop and copy the files you previously copied from your desktop onto your new USB Drive, overwriting the files the format created
* Eject the original USB Drive

ALWAYS format your new USB Drive using the Astrid utility otherwise Astrid will not recognize the drive.

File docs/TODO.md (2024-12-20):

# TODO

* Bug with RA being negative on arrows due to wrap around
* Stop storing plate solve files (or maybe prompt to clear)
* Cancel button on OWCloud Download when internet not connected
* Ted: Player, Star Analysis Bomb
* Double chord spacing and kml
* Vizier light curve submission
* https://datasheets.raspberrypi.com/camera/raspberry-pi-camera-guide.pdf - INFO for libcamera future upgrade
* Any chance you could allow a dynamic (local) change of the limiting magnitude during Exposure Analysis, rather than forcing us to stop and restart Astrid to get to the settings for Simulator? - Ted
* Magnitudes Cluttered on Display Analysis
* Significant red errors when recording with Software Leap Seconds
* Add YYYYMMDD_ to folder name (check that's correct on IOTA Report format
* Repeat prepoint when failed 
* Mention heat sinks in the kit
* Astrid saves fits files as .fit, change to fits (maybe)
* GPS Antenna must be attached when recording video, no GPS popup msg or prevent recording as it currently hangs
* Add mag drop calculator to Astrid
* Multiple deletes on events
* Generate KMZ for multi station videos
* Order occultations by the next one first, can more be automated?  Can frame rate be pre entered?
* Quotes in Wifi names = bad Ted's Wifi, update doc
* astropy download
* For Occultation Info Screen, calc Error In Time, Shadow Width, Path Uncertainty in km's
* Any value to updating duration of event via path computation?
* Experiment with AELocked (looks like a converence thing)
* Check into FITs, is it really storing 0-255 or 0-1023?
Metadata: {'SensorTimestamp': 22567493602000, 'ScalerCrop': (3, 0, 1450, 1088), 'DigitalGain': 1.0002992153167725, 'SensorBlackLevels': (3840, 3840, 3840, 3840), 'AeLocked': False, 'Lux': 400.0, 'FrameDuration': 200014, 'AnalogueGain': 1.0, 'ExposureTime': 199940}
* Frame rates: At speeds above 25fps, one of the python processes pegs out at close to 95-100% cpu on "top".  Figure out cause to increase frame rate.  Also, look at modding picamera to be able to skip frames that are more than 10fps for display.  Accelerated Rendering is likely faster and won't drop frames?   * See /usr/lib/python3/dist-packages/picamera2/previews/q_picamera2.py for display rendering
* Confusion over Object Panel.  Maybe change Object to Target.  But what happens if I say "no".  Is this object now selected as the object to use with Plate Solve comparisons?  How do I know what object is currently the "target"
* Install PyMovie/PyOTE on the Pi

* Complete:
	* Focus Support
	* Histogram 
* Bug: Test this again: If framewriter process raises an exception, it isn't logged, force the raising of exceptions on framewriter, processotestamper and processlogger both during recording video and in regular operation
* Manual reset of OTEStamper
* Make mount panel user configurable for J2000 or JNOW (Steve)
* Update image in response to check boxes without requiring image to be retaken
* Refactor "evolved" CameraModel.py into a command based system and decouple everything so everything runs as a command, updating the UI as appropriate.  This will also get ready for command based operation/scripting. (similar approach to Siril)
* Change to Indi Neutral https://www.indilib.org/api/classINDI_1_1Telescope.html
* Put target on screen to show the star.
* http://www.lunar-occultations.com/occult4/gaia16_edr3.zip
* Use astrometry.net to annotate image and place marker for target on. Add star locations for target confirmation. Too slow to generate images: try using sirils catalogues to annotate or the catalogues above
* Ability to display ravf and fits on pi

* PyMovie:
	* pip3 install adv2
	* pip2 install --no-deps "git+https://github.com/ChasinSpin/pymovie.git"
	* Fails due to adv2 library not being compiled for raspberry pi

# Notes

* NEO's are typically 1/10s occultation (100fps)
* Trans Neptunians = 1 to 0.5fps

## Raspberry Pi GPIO

* raspi-gpio get		# Displays current configuration of the pins
* raspi-gpio funcs	# Displays what all the pins are capable of
* pinout				# Displays Raspberry Pi Pinout

## Links - GPS

* [GPS Raspberry Pi Setup](https://www.youtube.com/watch?v=YfgX7qPeiqQ)
* [GPS Raspberry Pi Setup - Chrony](https://n4bfr.com/2020/04/raspberry-pi-with-chrony/2/)
* [GT-U7](https://x2robotics.ca/gt-u7-gps-module-compatible-neo-6m-stm32-with-eeprom-antenna-for-arduino)
* [Getting GPS to work on your Pi](https://area-51.blog/2012/06/18/getting-gps-to-work-on-a-raspberry-pi/)
* [GPSd accuracy](https://gpsd.gitlab.io/gpsd/gpsd-time-service-howto.html)
* [PPS-Client v1.5.2](https://github.com/rascol/Raspberry-Pi-PPS-Client)
* [GT-U7 Chip Datasheet](https://images-na.ssl-images-amazon.com/images/I/91tuvtrO2jL.pdf)
* [GPS Dimensions](https://www.aliexpress.com/item/32828958211.html)

# Links - General

* [Astro Digital Video](http://www.hristopavlov.net/adv/index.html)
* [AstroDigitalVideo GitHub](https://github.com/AstroDigitalVideo)
* [Bob Anderson GitHub](https://github.com/bob-anderson-ok)
* [PiJuice](https://github.com/PiSupply/PiJuice)
* [PS Series 3V Buzzer](https://www.jp.tdk.com/tefe02/ef532_ps.pdf)
* [QHY174GPS Design and Timing](https://www.qhyccd.com/wp-content/uploads/20210628792.pdf)
* [Raspberry Pi 4 Pinout](https://linuxhint.com/gpio-pinout-raspberry-pi/)

# Github Branches

* List Branches: git branch# asterisk branch is the active one
* git pull
* git push
* New Branch: On Github, click branches and New Branch 
* Update local github: git pull   
* Checkout Branch: git checkout mybranch
* Commit as normal
* Switching back to main branch:  git checkout main
* Merging:  git checkout main;  git merge mybranch; git push    # then:
* Delete mybranch:  On Github, click branches and Delete the Branch 
* git pull

# Accelerated Graphics

Currently, camera doesn't work when doing accelerated graphics, try out V4L2 instead: [https://www.arducam.com/faq/opencv-v4l2-python-rpi/](https://www.arducam.com/faq/opencv-v4l2-python-rpi/)

Enable Acceleration:

	pi@astrid5:/boot $ diff config.txt config.txt~
	62,63c62
	< #dtoverlay=vc4-kms-v3d
	< dtoverlay=vc4-fkms-v3d-pi4
	---
	> dtoverlay=vc4-kms-v3d
	89,95d87
	< hdmi_force_hotplug=1
	< #hdmi_ignore_edid=0xa5000080
	< hdmi_group=2
	< hdmi_mode=23
	< #framebuffer_width=1280
	< #framebuffer_height=720
	< #gpu_mem=256
	
	root@astrid5:~/.vnc/config.d# pwd
	/root/.vnc/config.d
	root@astrid5:~/.vnc/config.d# diff vncserver-x11 vncserver-x11~
	4,6d3
	< CaptureTech=raspi
	< ExperimentalRaspiCapture=1
	< ServerPreferredEncoding=JPEG
	
	pi@astrid5:~/astrid/app $ git diff
	diff --git a/app/CameraModel.py b/app/CameraModel.py
	index 4d528a0..cedf6e5 100644
	--- a/app/CameraModel.py
	+++ b/app/CameraModel.py
	@@ -242,7 +242,8 @@ class CameraModel:
                vflip     = self.settings['vflip']
                transform = Transform(hflip=hflip, vflip=vflip)
 
	-               if self.settings['accelerated_preview']:
	+               #if self.settings['accelerated_preview']:
	+               if True:
                        print("Configuring Accelerated Preview")
                        self.qt_picamera = QGlPicamera2(self.picam2, width=self.previewWidth, height=self.previewHeight, keep_ar=True, transform=transform)
                else:

	sudo reboot

# Next Gen Camera

	pi@astrid5:~ $ libcamera-vid --list-cameras
	Available cameras
	-----------------
	0 : imx296 [1456x1088] (/base/soc/i2c0mux/i2c@1/imx296@1a)
   		 Modes: 'R10_CSI2P' : 728x544 [117.61 fps - (0, 0)/1456x1088 crop]
                		      1456x1088 [60.38 fps - (0, 0)/1456x1088 crop]

[https://www.waveshare.com/wiki/Template:RPi_Camera_Libcamera_Guide](https://www.waveshare.com/wiki/Template:RPi_Camera_Libcamera_Guide)

	libcamera-vid -t 10000 --framerate 117.61 -o test.h264
	ffprobe -v error -select_streams v:0 -count_packets -show_entries stream=nb_read_packets -of csv=p=0 test.h264 
	1167   (number of frames)
	
[https://forum.arducam.com/t/64mp-what-is-the-quickest-way-to-grab-an-image-in-python/3486](https://forum.arducam.com/t/64mp-what-is-the-quickest-way-to-grab-an-image-in-python/3486)

[https://pypi.org/project/rpi-libcamera/#description](https://pypi.org/project/rpi-libcamera/#description)

[https://libcamera.org/docs.html](https://libcamera.org/docs.html)

[https://github.com/raspberrypi/picamera2/blob/main/picamera2/picamera2.py](https://github.com/raspberrypi/picamera2/blob/main/picamera2/picamera2.py)

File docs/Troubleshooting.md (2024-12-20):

# Troubleshooting

## Support

Astrid is supported on a **best-effort** basis as time permits, you should not expect support for Astrid. It is an open-source project and the code is available for you to add new features or fix issues.

**Please check the documentation first.**

**The aim is to document everything to reduce support requirements from a real person. The scope of this project is large and we ask for your assistance, by adhering to the following:**

Any request for support assistance has the following requirements:

* You are running the latest version of Astrid
* Astrid is being used within it's specifications
* Design/new feature requests are suggestions only
* No support for WiFi routers

### That is:

* Requests for help or bug fixes on older versions will be asked to upgrade first and try again
* Problems with videos frame rates > 30fps, will be referred back to the specifications and the alert that was received when you recorded
* If you purchased a battery power pack and are having power issues, then you'll be pointed to the documentation for Power Supplies
* Problems with GPS reception will be pointed to the documentation
* If you can't connect to WiFi, then find someone local for help

### You can help:

You can help reduce the support load by taking the time to check the documentation first and keeping the software up to date.

Astrid follows a Rapid Development model, and all bug fixes are by new versions, not by going backwards.  There is no regression path or change control, GitHub stores the code changes, and the path is always forging forward.

### Zoom

Often it is necessary to share the users screen to fix an issue.  Therefore, please have Zoom installed on the same machine you have RealVNC and can connect to Astrid from, prior to asking for support. 

Support resources are limited, and screen sharing is often the most efficient way to provide that support.

## Common Issues and Solutions

* [Host Not Found](#host-not-found)
* [Site Button Is Orange Or Red](#site-button-is-orange-or-red])
* [GPS Poor Reception](#gps-poor-reception)
* [Mouse Problems On Tablet](#mouse-problems-on-table)
* [Android Host Not Found](#android-host-not-found)
* [Indi Testing](#indi-testing)
* [Tuning GPS PPS Offset](#tuning-gps-pps-offset)
* [GPS Accuracy](#gps-accuracy)
* [Intermittent Power](#intermittent-power)
* [Lines On Video](#lines-on-video)
* [Mount or Prepoint Has Wrong Position](#mount-or-prepoint-has-wrong-position)
* [Linking to OWCloud Events Fails](#linking-to-owcloud-events-fails)
* [Wrong Password Entered For WiFi and Unable To Connect](#wrong-password-entered-for-wifi-and-unable-to-connect)
* [RealVNC Wants A Subscription](#realvnc-wants-a-subscription)
* [Wifi Astrid Hotspot Not Listed](#wifi-astrid-hotspot-not-listed)

## Host Not Found

It can take a few minutes for astrid.local to be pushed to the device you are 
connecting from's DNS.

Make sure you are on the correct WiFi network, the ethernet port flashes alternate Green/Yellow when connected to a known WiFi Network and is solid Green/Yellow when Astrid is generating it's own Wifi Hotspot (Adhoc Network).

The hostname astrid.local is mapped via a process called mDns/Bonjour which may not work on older computers or poorly designed Wifi Routers. Use the IP address instead to connect if this is an issue with your hardware

Mini Display can be used to see your current network configuration and to switch to your Home WiFi.

## Site Button Is Orange Or Red

To change the Site Button from Orange/Red to Green, click on the button and click "Update Site and Mount".  The Orange/Red is due to a mismatch between the last time the "Update Site and Mount" button was clicked and position the GPS is reporting now.  

It is natural for GPS to change position over time by a small amount, so Orange is not an issue for acquisitions that don't need super precision (like NEOs).  Everytime you move to a new site, you will need to click the "Update Site and Mount" button.

## GPS Poor Reception

A good solid GPS signal is required for both timing and positioning.  If the Timing/GPS buttons are not constantly Green in Astrid, then you should look into the positioning of the GPS antenna. It is suggested to mount the antenna facing the sky and with a clear view of it.  

Possible reasons for poor reception are:

* Antenna upside down (black part not pointing to the sky)
* Antenna substituted for another. Only the recommended antenna should be used, other antennas may look the same but are inferior
* Usage inside (the top floor of a house may work depending on construction, but outside is better)
* Obstructed view of the sky (trees, buildings, etc.), GPS requires a clear 360-degree view of the sky
* Placed on metal. Although the antennas are magnetic, the metal often creates a ground plane and can make reception unpredictable; avoid metal other than a nail or a bolt
* Placed on the ground. Ground is an unpredictable ground plane; often, grass/dirt interferes with the signal, and a concrete slab may not, experience varies, avoid
* Attached to a telescope. Telescopes move and are often metal or carbon fiber, all of which will interfere with signal reception
* Poor cable connection. Ensure the antenna cable is fully screwed in and the antenna hasn't disconnected from the GPS receiver
* Broken antenna. GPS cables can be damaged, Antenna drops, and pins damaged/corroded.  There is also a Pigtail inside Astrid they may become loose or damaged.

**It's not recommended to record an occultation unless Site, GPS, Timing and Acquisition buttons are Green (with the exception of an Orange Site Button).  A GPS/Timing button that changes to Red during a recording can produce incorrect timing.**
	
## Mouse Problems On Tablet

If you have to move the mouse on a tablet to be able to select a button, enter text into a field etc., then change "Interactive" to "Touch Panel" in your VNC settings.

## Android Host Not Found

Newer Androids support the mDNS/Bonjour protocol, such that hostnames with .local in can be resolved.  However older androids do not support this, so please upgrade your OS to the latest version.

## Some spots on VNC are blurred

This is due to the compression being used when automatic compression is set for the connection in VNC. You can choose to use less compression at the expense of a slower connection / responsiveness. Don't worry astrid always records the raw data from the camera.

## Brightness Of Image Changes when Selecting "Display" Options

This is a limitation of the display pipeline and GPU.  This does not affect saved data in an way.
	
## Indi Testing
### (Developer use only)
		#indiserver -v -m 100 indi_lx200am5     # All drivers are in /usr/bin
		#indi_setprop "ZWO kjjAM5.CONNECTION_MODE.CONNECTION_SERIAL=On"
		#indi_setprop "ZWO AM5.DEVICE_PORT.PORT=/dev/ttyACM0"
		#indi_setprop "ZWO AM5.CONNECTION.CONNECT=On"
		#indi_getprop
		#indi_setprop "ZWO AM5.GO_HOME.GO=On"
				
## Tuning GPS PPS Offset
### (Developer use only)

	Important: GPS and PPS signals must be within 200ms of each other (use offset to adjust), otherwise the PPS signal will be ignored, so we start with an offset of 0.1s
	
	Tuning GPS(NMEA) Offset:
		sudo vi /etc/chrony/chrony.conf
			# Disable reflock lines and use these
			refclock SHM 0 refid NMEA precision 1e-1 offset 0.1 noselect
			refclock PPS /dev/pps0 refid PPS lock NMEA precision 1e-9 offset 0.0 prefer
		sudo systemctl restart chrony
		# Monitor for PPS to get an asterisk by it (source selected) using:
		chronyc sources -v
		# Then when the source is selected, use the following and monitor offset for NMEA until it's stabilized and has reasonable std dev (<1ms)
		chronyc sourcestats -v
		# If offset is +35ms, then add +35ms to offset 0.1 for the NMEA refclock to become 0.135
		sudo vi /etc/chrony/chrony.conf
		sudo systemctl restart chrony
		
		chronyc sourcestats -v
		# Take the offset field for NMEA (136ms in this) case and ammend line to:
		refclock SHM 0 refid NMEA precision 1e-1 offset 0.136 noselect
		sudo systemctl restart chrony
		** REPEAT ** until NMEA Offset is sub 1ms
		
		# sourcestats is the offset of the source, sources is the offset from the system clock 
		
		To turn chrony tracking log on, uncomment:
			log tracking measurements statistics
			in /etc/chrony/chrony.conf
			sudo systemctl restart chrony
			log file is stored in /var/log/chrony/tracking.log
		
### Chronyc stages in tracking	
### (Developer use only)	

	pi@otestamper:~ $ chronyc tracking
	Reference ID    : 00000000 ()
	Stratum         : 0
	Ref time (UTC)  : Thu Jan 01 00:00:00 1970
	System time     : 0.000000000 seconds fast of NTP time
	Last offset     : +0.000000000 seconds
	RMS offset      : 0.000000000 seconds
	Frequency       : 14.883 ppm fast
	Residual freq   : +0.000 ppm
	Skew            : 0.000 ppm
	Root delay      : 1.000000000 seconds
	Root dispersion : 1.000000000 seconds
	Update interval : 0.0 seconds
	Leap status     : Not synchronised

	pi@otestamper:~ $ chronyc tracking
	Reference ID    : C6A1CB24 (198.161.203.36)
	Stratum         : 3
	Ref time (UTC)  : Sat Apr 01 05:52:47 2023
	System time     : 0.000565229 seconds slow of NTP time
	Last offset     : +0.005562202 seconds
	RMS offset      : 0.005562202 seconds
	Frequency       : 14.883 ppm fast
	Residual freq   : -511.255 ppm
	Skew            : 0.119 ppm
	Root delay      : 0.052770238 seconds
	Root dispersion : 0.007293095 seconds
	Update interval : 0.7 seconds
	Leap status     : Normal

	pi@otestamper:~ $ chronyc tracking
	Reference ID    : 50505300 (PPS)
	Stratum         : 1
	Ref time (UTC)  : Sat Apr 01 05:54:36 2023
	System time     : 0.000001976 seconds fast of NTP time
	Last offset     : +0.000001735 seconds
	RMS offset      : 0.004799102 seconds
	Frequency       : 14.891 ppm fast
	Residual freq   : +0.032 ppm
	Skew            : 0.198 ppm
	Root delay      : 0.000000001 seconds
	Root dispersion : 0.000019206 seconds
	Update interval : 31.0 seconds
	Leap status     : Normal

## GPS Accuracy

### (Developer use only)
	
### PPS on GPS:
	
GT-U7 (based on Neo 6m): [GPS-based Timing - Application Note](https://content.u-blox.com/sites/default/files/products/documents/Timing_AppNote_%28GPS.G6-X-11007%29.pdf)
	With positional fix, only needs 1 satellite, without needs 4 satellites.
	Average of 2.35ns over 6 hours, with a sampling deviation of 6.7ns
	
### Chrony + PPS:
 With 1/3 of the sky blocked and from a power off cold start, this is the speed at which timing was acquired:
 
*  0m 35s: -478ms (NTP Server)
*  1m 23s: -1.12ms (NTP Server, over Wifi and Shaw internet)
*  2m 29s:  -2.71ms (NTP Server, over Wifi and Shaw internet)
*  2m 55s: 6.15ms (First PPS GPS Lock, now Stratum 1)
*  3m 27s: -2.85uS (PPS, GPS Lock)
*  3m 59s: 770nS (PPS, GPS Lock)

		===================================================================================================================================
		   Date (UTC) Time     IP Address   St   Freq ppm   Skew ppm     Offset L Co  Offset sd Rem. corr. Root delay Root disp. Max. error
		===================================================================================================================================
		2023-04-01 04:11:34 0.0.0.0          0     21.770      0.016  0.000e+00 ?  0  0.000e+00 -9.664e-14  1.000e+00  1.000e+00  1.500e+00
		2023-04-01 04:12:09 45.61.49.156     3     21.770      0.016 -4.783e+01 N  3  5.660e-03 -2.854e-10  5.462e-02  1.035e-01  1.500e+00
		2023-04-01 04:12:57 45.61.49.156     3     21.770      0.016 -1.126e-03 N  2  3.774e-03 -5.652e-12  5.692e-02  3.702e-02  4.790e+01
		2023-04-01 04:14:03 217.180.209.214  2     21.770      0.016 -2.713e-03 N  1  3.433e-03 -1.585e-07  7.181e-02  3.587e-03  7.605e-02
		2023-04-01 04:14:29 PPS              1     21.770      0.016  6.169e-03 N  1  7.607e-07  2.144e-03  1.000e-09  2.426e-05  4.320e-02
		2023-04-01 04:15:01 PPS              1     21.769      0.029 -2.845e-06 N  1  5.378e-07 -7.400e-09  1.000e-09  2.135e-05  4.086e-03
		2023-04-01 04:15:33 PPS              1     21.763      0.060 -7.701e-07 N  1  1.033e-06 -2.143e-07  1.000e-09  2.329e-05  6.024e-05
		2023-04-01 04:16:05 PPS              1     21.746      0.111  7.365e-07 N  1  1.498e-06  3.563e-07  1.000e-09  2.778e-05  6.002e-05
		2023-04-01 04:16:37 PPS              1     21.741      0.119  2.519e-06 N  1  1.962e-06 -3.162e-07  1.000e-09  2.395e-05  6.469e-05
		2023-04-01 04:17:09 PPS              1     21.755      0.111  3.361e-06 N  1  2.249e-06 -1.042e-07  1.000e-09  2.431e-05  6.266e-05
		2023-04-01 04:17:41 PPS              1     21.824      0.122  8.528e-06 N  1  9.663e-07  9.403e-08  1.000e-09  2.528e-05  6.345e-05
		2023-04-01 04:18:13 PPS              1     21.849      0.062  1.476e-06 N  1  5.909e-07  4.371e-07  1.000e-09  2.035e-05  7.006e-05
		2023-04-01 04:18:45 PPS              1     21.853      0.035  4.704e-07 N  1  5.264e-07  2.600e-08  1.000e-09  2.106e-05  5.541e-05
		2023-04-01 04:19:17 PPS              1     21.857      0.028  7.900e-07 N  1  5.730e-07 -1.946e-07  1.000e-09  2.024e-05  5.463e-05
		2023-04-01 04:19:49 PPS              1     21.863      0.032  1.399e-06 N  1  7.986e-07  1.883e-09  1.000e-09  2.157e-05  5.415e-05
		2023-04-01 04:20:21 PPS              1     21.870      0.061  3.496e-06 N  1  1.070e-06  2.844e-08  1.000e-09  2.502e-05  5.604e-05
		2023-04-01 04:20:53 PPS              1     21.905      0.103  4.365e-06 N  1  9.487e-07  1.723e-10  1.000e-09  2.243e-05  6.317e-05
		2023-04-01 04:21:25 PPS              1     21.943      0.111  3.622e-06 N  1  1.010e-06 -2.883e-11  1.000e-09  2.165e-05  6.279e-05
		2023-04-01 04:21:57 PPS              1     21.970      0.072  2.306e-06 N  1  6.458e-07  1.574e-07  1.000e-09  2.499e-05  6.112e-05
		2023-04-01 04:22:29 PPS              1     21.987      0.060  1.924e-06 N  1  5.656e-07 -1.934e-11  1.000e-09  2.192e-05  6.151e-05
		2023-04-01 04:23:01 PPS              1     22.000      0.029  1.232e-06 N  1  2.788e-07 -2.347e-10  1.000e-09  1.853e-05  5.784e-05
		2023-04-01 04:23:33 PPS              1     22.007      0.040  1.156e-06 N  1  4.270e-07  8.070e-12  1.000e-09  2.174e-05  5.271e-05
		2023-04-01 04:24:05 PPS              1     22.014      0.036  5.754e-07 N  1  3.559e-07  1.679e-08  1.000e-09  2.130e-05  5.628e-05
		2023-04-01 04:24:37 PPS              1     22.018      0.025  2.773e-07 N  1  2.463e-07  1.091e-11  1.000e-09  2.195e-05  5.507e-05
		2023-04-01 04:25:09 PPS              1     22.014      0.042 -1.401e-06 N  1  6.271e-07 -6.953e-08  1.000e-09  2.176e-05  5.504e-05
		2023-04-01 04:25:41 PPS              1     22.007      0.055 -7.043e-07 N  1  5.887e-07 -1.249e-10  1.000e-09  2.425e-05  5.663e-05
		
## Intermittent Power

Astrid has a professional type DC Jack (for a long lifespan).  Often the cause of intermittent power is that the DC Plug has only been partially inserted so that plug is only retained lightly.  Please be sure to push the plug further past the initial resistance, so that it is fully inserted.

Another cause of intermittent power is a poor power supply that cannot supply the current required by Astrid.

Please note that intermittent power is bad for Astrid and can corrupt SD Cards and USB Flash Drives.

## Lines On Video

If you encounter intermittent lines on video, investigate where the Astrid was placed.  Do not place near High Voltage power lines, which are often along roads.

Although this hasn't been definitively demonstrated yet / seen in a recording, it has been seen a couple of times over a VNC connection at a specific site which had power lines directly above an Astrid.

It may impact either Wifi to the device running VNC, or induce into the sensitive CMOS sensor on the camera.

## Mount or Prepoint Has Wrong Position

The first thing to try is to take another photo, plate solve, and go, then repeat this process one more time; the star field should remain in a similar position, indicating the position is correct.

Other things to check (for example if Prepoint is an incorrect position), is your time and event details.

A valid GPS position, Time and site location are required for accurate positioning via a goto or prepoint.  Please ensure all status buttons are Green.

## Linking to OWCloud Events Fails

Some events may fail to link back to OWCloud.  Currently, OWCloud only supports IOTA-tagged events, and many of the predictions generated by Steve Preston in 2024 are not tagged due to the limitation of OWCloud to tag large numbers of events.  This is a limitation of OWCloud, and there are no plans at this time for OWCloud to support linking to non-IOTA tagged or events that are not tagged.  If you would like to see support for this, please contact the author of OWCloud directly.

## Wrong Password Entered For WiFi and Unable To Connect

If you enter the wrong password when setting up a WiFi network in Astrid (for example your Home WiFi), then when Astrid attempts to connect to that network, it won't be able to it.

Use the Mini Display to switch back to the Hotspot, and change your network password.

If you don't have the Mini Display, you will have to power cycle to gain access.

## RealVNC Wants A Subscription

You have or are installing RealVNC Connect by mistake when you want RealVNC Viewer.  Please uninstall RealVNC Connect and follow the instructions here: [Usage Guide - Connect Via VNC](UsageGuide.md#connect-via-vnc)

## Wifi Astrid Hotspot Not Listed

Whenever astrid starts up, it's always in Hotspot mode, use the Mini Display to switch to your local network.  Sometimes you may not see the Astrid Hotspot, this is caused by so many networks in your local area that the Astrid Hotspot is past the bottom of the list of networks on your computer.  Often there is an option on your computer called "Other" where you can manually enter the network details for the Hotspot.

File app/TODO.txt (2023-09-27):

1. Center Marker
2. Polar Align
3. See if raw (uncompressed) is causing slow down
4. Raw to Seq
5. Timestamping
6. Frame syncing
7. Sensor Temperature
8. AM5 mount communication
9. Plate Solving and storing settings
10 Autostretch

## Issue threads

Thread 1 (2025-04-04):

Looking for the log that contains the text that scrolls when Astrid App is started, but then terminates

jmooreou, 2025-04-04:
Hi Mark,
Hopefully this one is simple.  On a certain R-Pi/Camera/USB drive, when testing the Stamper boards, I launch the Astrid app, go past the warning that the drive hasn't been qualified, and watch as the text scrolls.  Just before it terminates is says something about "camera not found" and something about "addressing the legacy camera.... " I never have time to read the text because the window closes almost immediately.  I don't see this text in the log file on the USB drive.

Is there some other file where this text is captured?  I'm hoping this is some easy fix as these boards all passed the test and successfully make recordings on another R-Pi/camera sertup.  The one setup

[astrid.log](https://github.com/user-attachments/files/19610147/astrid.log)

 that is failing does have the latest code installed and a new USB drive (just hasn't been qualified yet).

Thanks in advance...
John Moore

ChasinSpin, 2025-04-05:
If astrid.log isn't catching it, then you can start Astrid manually from terminal with:

cd ~/astrid/app
./astrid.py -d /media/pi/ASTRID

Then you're able to copy and paste the output.  Also, are you using the official Astrid image?  Or did you upgrade the OS or install from scratch?

jmooreou, 2025-04-05:
Thanks Mark

I'll give this a go.

I upgraded the OS image using Astrid Tools.

One of my challenges is that I have been testing with one configuration [ Pi/Camera/USB/OTEStamper.  I have some Stamper boards that pass the test and seem to record fine, but then when I try to use them in the planned camera configuration (different Pi/Camera/USB) I run into this issue.

Other minor issues I'm dealing with - not asking for help with this.  I want to spend some more time on these.  1. Some new Realelec USBs won't format.  The report is that it fails because of a bad "-F" flag.  Others format fine.  Again, this is using the Astrid tools.  I just keep swapping New USB drives until I find one that will format successfully.

2. The other is that while several boards I have made seem to work well, but I haven't been able to test any under the stars yet.  Constant storms.  The storm chasers are busy this past week..  Anyway, my fan never comes on for some reason.  It doesn't report a fail when I run the spitest.py, but the fan never actually spins.  Simple circuit, so I'll eventually figure out what is going on.  I did check the transistors and they are the correct part #s

Anyway, thanks again.  It's thundering again and we might actually get snow tomorrow.  Strange weather pattern.  Floods everywhere after an extended draught.  I'll run the suggested commands and see what happens.  I really appreciate the help!

________________________________
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

jmooreou, 2025-04-05:
Mark,
Thanks!  I got it sorted.  It wasn't finding the camera.  I swapped the ribbon cable and all is good.  Appreciate the help!

ChasinSpin, 2025-04-05:
Regarding the USB issue, I'll need a log of what's happening to look into it, please raise that as a seperate issue on github if it continues to be an issue.

Glad it was a cable issue.  Marking as closed

Closed 2025-04-05.

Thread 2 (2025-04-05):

Unable to load integrated ravf files in Player

Garrett-Tow, 2025-04-05:
After integrating (sum or average), I tried playing the video in the Astrid Player and I get an error. The unintegrated video plays fine in the Astrid player and the sum integrated video plays fine in PyMovie.

~/astrid/app/ravf_integrate.py 468861_2013LU28_-_South_Mountain_20250318_045624_1.ravf 468861_2013LU28_-_South_Mountain_20250318_045624_1_integration_sum_2.ravf 2 sum

If I then try to load the sum integrated video into the Astrid Player, I get the error message that is attached as an image.

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

Astrid version 1.0.049.

ChasinSpin, 2025-04-05:
I wasn't able to reproduce this with a video recorded on the latest version of Astrid.  The video loaded, and the metadata specified it was 2X integrated.

Please ensure:
* Your USB drive isn't full (or close to full)
* You are on the latest version of Astrid
* You are encoding a video that was taken recently

There was an issue fixed in version 1.0.037 (see release notes) that had the same symptoms.  Please connect to internet and run Astrid Upgrade, to ensure you have the latest ravf module update.

On a side note.  You probably should use "average" instead of "sum", as it maintains consistency with FITS finder image in brightness.  Average/Sum essentially produce the same result.

Closing for now, reopen if you've addressed the above and add astrid.log and the output from player, which can be copied and pasted with:

cd ~/astrid/player
./player.py -d /media/pi/ASTRID

ChasinSpin, 2025-04-28:
Please record another video, and copy paste the integration command line you used to create it.  Open in Player, screenshot the error.  Then eject the USB drive from the desktop, or power down Astrid and wait 15 seconds. Then please provide the video, as I haven't been able to reproduce in my testing and your log doesn't show any error.

Garrett-Tow, 2025-04-28:
Recorded a new video just now. Integration command+output, player log, and Astrid log are all attached in text files.

[astrid_truncated.log](https://github.com/user-attachments/files/19946425/astrid_truncated.log)
[integration_command_and_output.txt](https://github.com/user-attachments/files/19946427/integration_command_and_output.txt)
[player_test.log](https://github.com/user-attachments/files/19946426/player_test.log)

Uploading test videos is failing due to size -- 79 MB in a zip file since Github complains about .ravf files. I'll try emailing you a link for file sharing.

ChasinSpin, 2025-04-29:
Your file (the integrated one) is loading fine on mine.  (see screenshot).  Please type the pip3 command detailed in the screenshot and provide the version for ravf.

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

Garrett-Tow, 2025-04-29:
I imagine that will fix the issue. Should the ravf version be updated during the standard Astrid update procedure?

If so, perhaps I should retain the old ravf version so we can test the propagation of this fix via the standard Astrid update procedure since this fix needs to be delivered to others. Even if this doesn't fix the issue (unlikely), the ravf version update still needs to be baked into the standard Astrid update, I imagine.

ChasinSpin, 2025-04-29:
The update is baked in, but it clearly didn't work in your case.  I'll make that change to the update after you've tested and confirmed the above solves the issue.  No need to retain old version, you should be using new.

Garrett-Tow, 2025-04-29:
Yes, updating ravf worked and the integrated video now plays.

Terry is experiencing the same problem as reported in issue #5 . Once the Astrid update procedure has been mended to update the ravf versions, I suggest having Terry try the Astrid update to resolve the issue instead of manually upgrading the ravf version. This would be a good test to make sure the ravf update rolls out successfully to Astrids that have already been distributed.

ChasinSpin, 2025-04-29:
The change has been added to the update, please upgrade to latest version

Garrett-Tow, 2025-04-29:
I upgraded to the latest version and everything is as expected: ravf=1.0.1; Astrid=1.0.054; Player works with integrated video.

However, that's not worth much since I had previously upgraded manually to ravf=1.0.1. Let's see if Terry succeeds in getting ravf to update by the normal Astrid update procedure.

Closed 2025-04-29.

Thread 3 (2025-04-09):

Data recorded successfully, but no image displayed in PyMovie

tedblank, 2025-04-09:
Apparently successful prepoint recording last night, but when I opened the RAVF file in PyMovie I got a message "No target star location found in the folder".   Don't know if this is normal, but I don't remember seeing it.   However, now the screen displaying the star field is white and empty.  When I click 'play' in PyMovie, timestamps go by in the lower left but nothing is displayed in the display window, it's is just white.

PyMovie  Version: 4.1.5
Home directory: C:\Users\Ted\AppData\Roaming\Python\Python39\site-packages\pymovie
No pixel dimensions were found.
There are 2288 frames in the RAVF file.
Opened: C:\$$ Occultation Videos\160531_1996_TB49_-_T_Blank__Home_20250409_063338_1\160531_1996_TB49_-_T_Blank__Home_20250409_063338_1.ravf
Timestamp found: 2025-04-09 @ [06:33:38.794343]
image shape: width=1456  height=1088
No target star location found in the folder.

[160531_1996_TB49_-_T_Blank__Home_20250409_063338_1.log](https://github.com/user-attachments/files/19667938/160531_1996_TB49_-_T_Blank__Home_20250409_063338_1.log)

Unfortunately, GitHub will not allow me to attach the RAVF file.  I"ll send it separately.

bob-anderson-ok, 2025-04-09:
Check the contrast control setting in PyMovie.

Bob Anderson

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

tedblank, 2025-04-09:
Wow, that was strange.  Contrast was totally blown out.  I managed to find some settings on the sliders that let me see the data.   Did something change?

ChasinSpin, 2025-04-09:
Received email with no attachment with subject "RAVF file for GitHub Issue", so unable to view...

However, there have been no changes to the way Astrid handles contrast on the sensor.  It's been my experience that thin cloud can cause brightness to increase in an image dramatically.

tedblank, 2025-04-09:
Re-sending.  Cox had a glitch and did not attach the link to the file.

ChasinSpin, 2025-04-09:
Looks fine to me in PyMovie 4.0.2.  Set contrast from 3300 to 4900 and stars / contrast seem normal.  The "No target star location found in folder" I believe is always there if one isn't set from what I can see from a quick look at PyMovie's code.  Looks like WCS in PyMovie needs to be run for that to be filled out.

PaulWalkerVT, 2025-04-17:
My recollection is that this due to a PyMovie update to that added the 'Make image contrast "sticky" ' feature.  If this is the first time you have used PyMovie since this was added or you only recently updated it and/or you haven't checked the box for this feature, contrast defaults to giving you a white screen.

ChasinSpin, 2025-04-17:
Closing this issue due to it not being an issue with Astrid, but an operational change with PyMovie.  Reopen if that isn't the case.

Closed 2025-04-17.

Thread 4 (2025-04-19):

8" SkyWatcher GOTO problem

smithn00, 2025-04-19:
I have chosen a mount with GOTO but no tracking.
I move the mount to a rough position using the Motion buttons.  Then I switch to Pre-Point mode.  The calculated offsets show the mount is off target by substantial amounts.  A good place to use GOTO.  Here is where the problem starts.
The mount starts to move after pressing GOTO.  The move is complete, using the Mark 2 eyeball, after 15-20 sec. but the GOTO  button does not become active again.  There are still small distances to go to place the crosshairs right where I want them.  This also seems to null the Motion buttons.
The "workaround" is to leave Pre-Point mode, then return. The GOTO button is active again and the Motion buttons allow me to move the remaining small distances to the target.

--
Ned Smith

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

[149449_2003_CE10_-_Smith_N_Home_20250418_064518_1.log](https://github.com/user-attachments/files/19821610/149449_2003_CE10_-_Smith_N_Home_20250418_064518_1.log)
[astrid.log](https://github.com/user-attachments/files/19821609/astrid.log)

ChasinSpin, 2025-04-19:
First ensure you are on the latest version.  (there was a previous version where the goto button could be disabled).

The settings are only for mount capabilities, generally it's best to setup your mount settings to be the same, unless there's some very good reason why you shouldn't (the mount is poor quality).  In these cases, it's often better just to tighten up the RA/Dec mechanically if you having issues with tracking, to the level where you need to switch it off.

You have 2 ways to get to a target:

1. Use Goto with Tracking (Goto/Tracking enabled in settings), and then select your target, then take a photo/solve and goto when prompted.  Repeat until you have your target (crosshairs) green and in the frame, if you wish to get it better, then repeat until roughly centered.  The mount will then continue tracking until the event time.  However, if you don't have great alignment (common), then it will drift over time as your mount hasn't been aligned with multiple locations and it's pointing model isn't accurate, so if your event time is hours away, you may want to use 2.  Then, set up autorecord.

2. Use Prepoint (Goto/Tracking enabled in settings), and then select your target using Prepoint and follow the prompts, the goto button will appear every iteration and allow you to get in position.  After it's completed, tracking is automatically switched off.  This deals with the issue of a poor pointing model on your mount and will always be on target if you don't bump the scope, even many days in advance.  Then setup autorecord.

What you describe is normal behavior.  If you set tracking off in settings, then the mount won't track, and in this situation you will only get prompted for 1 goto before having to reenter the software, as you've switched tracking off and the mount has already lost it's position due to to that.

Also it's normal for any mount with any software to be off in position on the first goto.  Mounts have internal pointing models.  Equatorial mounts are generally better (if accurately polar aligned) and only require 1 position fix.  Eq mounts if not polar aligned well can be as bad as Alt-Az mounts.  Alt-Az mounts start up with no idea of where they are in the sky, and need at least 2 Plate Solves and Sync about 90 degrees apart in Az and 45 degrees apart in Alt, until the mount can calculate an accurate pointing model.

However, with Alt-Az mounts, you don't really care too much either.  Startup in the home position, goto to the target, photo/solve (repeat until on target).  It will get there eventually, just a little slower than if you'd set the pointing model well.

Closing this one as it's normal operation, you can reopen if you need further information on it.

Closed 2025-04-19.

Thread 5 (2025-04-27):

Astrid Player not plate solving

tharan0, 2025-04-27:
1. Astrid NexStart 8SE with Celestron f/6.3 Reducer and IOTA 0.5X Reducer.
2. Prepointing and plate solving worked fine with final error at about 3%.
3. Created a ravtf I recoded at 30 fps.
4. Loadred the ravf into player which shows 2165 frames.
5. Metadata shows Focal Length of 594 which matches the Plate Solving focal length during prepointing and in settings.
6. Plate solving in player always fails.

ChasinSpin, 2025-04-28:
Platesolver in the same in Astrid and Player.  Does platesolver also fail when exposing for the same duration as the video?
Normally this is because the user is exposing for longer in photo than in video and when the video is played back there are not enough stars.  Other causes can be poor focus or focus drift over time.

tharan0, 2025-04-28:
Hi Mark:
Yes, I was exposing for only 0.1 seconds while plate solving during
prepointing, before switching to 30fps while recording.
I'm going to try resampling my ravf from 30fps to 15fps and see if plate
solving works at the lower frame rate.
Thanks for your help.
--Terry

On Mon, Apr 28, 2025 at 11:44 AM @ChasinSpin ***@***.***>
wrote:

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

ChasinSpin, 2025-04-28:
So to plate solve, you need a minimum of 4 sharp round stars.  Sometimes you can get away with 3.  Other things you can try in player is a different frame and solve that.  Smaller focal length generally means more stars too.  Less than perfect focus can also cause issues.  Marking this one as closed.  Reopen if that doesn't solve your issue.

tharan0, 2025-04-28:
Hi Mark:
I ran ravf_integrate on my 30fps ravf file as you described in a previous
email.
Note that I did have to tweak your ravf_integrate instructions by inserting
/ASTRID before /OTEVideo.
Integrating the 4298707855 input ravf by 2 average resulted in a 3431349461
byte X2.ravf.
The 30fps ravf loads and plays ok in Player, but doesn't plate solve on any
of the 2165 frames.
Loading the X2.ravf file gets the same error described in the open Garret
Tow issue <https://github.com/ChasinSpin/astrid/issues/2>.
I'll simply monitor Garret's issue to see if you are able to reproduce and
resolve it before I do anything else with my issue.
Note that I was running Astrid 1.0.053 both when I created to 30fps ravf as
well as when I ran ravf_integrate and Player.
Thanks again for your help.
--Terry

On Mon, Apr 28, 2025 at 12:00 PM @ChasinSpin ***@***.***>
wrote:

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

ChasinSpin, 2025-04-29:
Please provide stretched screenshot of one of the 30fps frames in player.

ChasinSpin, 2025-04-29:
See #2

ChasinSpin, 2025-04-29:
Marking as closed for now, add the information requested to update issue.

tharan0, 2025-04-29:
Hi Mark:
>> Please provide stretched screenshot of one of the 30fps frames in player.
I've attached 3 png files from the 30fps ravf:
frame_1004 does not plate solve
frame_1005 plate solves
frame 1006 does not plate solve
All frames were created in Player using a 15-20 stretch.
After upgrading my Astrid to 1.0.054, I was able to create  15 fps, 10 fps
, and 7.5 fps ravf files.
that Player was able to load successfully. Each lower fps ravf had improved
plate solving in Player.
I think my plate solving "problem" was simply due to the small number of
stars
in the target region, particularly at 30 fps. There also could have been a
problem with focus drift since
about 30 minutes had elapsed after prepointing finished before recording
started

>> Also, please point me to the ravf_integrate instructions that are
incorrect so I can update.
Here is a section of a March 8, 2025 email you sent me explaining how to
run ravf_integrate:
>> cd astrid/app
>> ./ravf_integrate.py /media/pi/OTEVideo/obsfolder/file.ravf
 /media/pi/OTEVideo/obsfolder/fileX2.ravf 2 average
Note that /ASTRID should have been inserted before /OTEVideo, so this
should have read
>> cd astrid/app
>> ./ravf_integrate.py /media/ASTRID/pi/OTEVideo/obsfolder/file.ravf
 /media/pi/OTEVideo/obsfolder/fileX2.ravf 2 average

I think it's fine to leave Issue #5 closed, since the 1.0.054 upgrade fixed
the issue with
Player being unable to load integrated ravf files, and when integrated ravf
files are loaded into Player,
the plate solving problem is ameliorated.

Thanks yet again for your help!
--Terry

On Tue, Apr 29, 2025 at 12:45 PM @ChasinSpin ***@***.***>
wrote:

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

ChasinSpin, 2025-04-30:
The images didn't upload, but if you don't have enough stars, that will be the reason, and certainly integrating will give you more stars.  A good solution for when you can't get a plate solve is to do just that, integrate.  It's also a good solution is your SNR/DNR is too low.  You can still generate a fits finder with the crosshairs on. Provided you use "average", then the stretch in PyMovie will end up being the same for the finder.

Closed 2025-04-29.

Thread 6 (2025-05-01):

Mini-display not working, networking unstable

stevepr, 2025-05-01:
Today, I updated two of my three Astrids and the mini-display no longer works on either one.  Both Astrids are now "stuck" in hotspot mode.  And both seem to exhibit a problem where the hotspot occasionally drops out.

stevepr, 2025-05-02:
Update:
Astrid 2 is at my friend Larry's house.  Astrid 1 and Astrid-0125 are at my house.  Larry had problems after his update of Astrid 2 and I had problems after my update of Astrid 1.  Astrid-0125 has not been updated yet.

Astrid 1 is now working normally.  I'm not sure what fixed the issue.  It could have been one of two things:
1. I plugged the Astrid 1 mini-display into Astrid-0125 (to verify it wasn't an issue with the mini-display).  The mini-display worked normally with Astrid-0125.  Perhaps connecting the mini-display to Astrid-0125 somehow fixed it?  Seems unlikely.
2. I powered on Astrid 1 without the mini-display.  After waiting a bit, I plugged in the mini-display and it has worked since then.  This happened after step 1 above.

Larry has been away from home but will try the unplug/plug option with Astrid 2 when he gets back later.

ChasinSpin, 2025-05-02:
If you haven't upgraded for a while, you might need to update the mini display too, instructions on how to do that can be found in the github documentation under MiniDisplay.

Networking should always be available via the Blue Wi-Fi icon in the bottom left-hand corner of the desktop once connected to the hotspot. If the mini-display isn't working or you don't have it on you, click that, wait 30-60 seconds, and you should be able to connect to Astrid via your local network.

Hotspot should never drop out, unless there's a power issue or the Raspberry Pi has crashed (check startup time to confirm).  Things to look out for are WiFi issues, 2.4GHz wifi is not "well" shared between different devices, and also newer routers have options that move the connection around between networks and frequencies with beam forming etc.  Routers often have options to prevent this from happening as it's known to cause issues like this.

Please upgrade MiniDisplay and close if this solves your issue.

Closed 2025-05-14.

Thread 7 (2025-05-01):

Date/time lost after a few months of inactivity

stevepr, 2025-05-01:
This is just an FYI in case you want to add it to the documentation.

Between the poor weather and limited free time, tonight was my first chance to observe since January.   When I powered up Astrid and tried to do an update, the update failed with an error saying it couldn't reach github.  I then tried accessing bing.com via the browser and that failed because Astrid's Date/Time was still set to January.  I had done all of this with Astrid sitting inside.  I took Astrid outside so it could get a decent GPS reception.  After a few minutes, the Date/Time was current, and the Astrid update went forward.

ChasinSpin, 2025-05-02:
I believe SSL requires a current time.  Pi doesn't have a realtime clock, so it defaults to the last system time the FS was written on boot up, then updates the time when either it can contact NTP or it gets a GPS sync.  You shouldn't need to go outside though, just connect to the internet and after a minute or 2, the time should update over the internet and then SSL shouldn't have any issues.  Therefore I suspect maybe you didn't have a solid internet connection in this case.  Also, it's possible your router maybe blocking NTP.  Close if you consider this resolved.

stevepr, 2025-05-02:
It is closed in the sense that there was an easy fix ... taking it outside.  But I do think outside was a requirement.  Astrid did seem to have a connection to the internet.  Pings did work.  And the unit was powered on for several minutes without any change to the date/time.  I suspect the NTP connection also failed due to the time difference issue flagged by the browser.

ChasinSpin, 2025-05-02:
I've just tested myself, it's working as it should.

My Astrid has been off for 3 days.  Disconnected GPS Cable (it's inside), powered on, it advertised the hotspot.  Logged in, checked date and it was Apr 29th.   Clicked on Wifi Connect on the desktop to connect to my local network.  Reconnected to Astrid after 60 seconds.  Waited another 60 seconds for NTP to be contacted, and the date had already updated to the current date. See attached screenshot.

Please check your network and ISP are allowing all NTP ports through, or alternatively if they are, then just allow it time to obtain the correct time.  But you can also take it outside and hook up a GPS antenna too if you wish.

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

stevepr, 2025-05-02:
Your test didn't match my situation.  Three days is probably not long enough.  Try setting the date on your Astrid to Jan 15, 2025 and see what happens.   You will probably see the same behavior as I did.  My Astrid units often sit unused for weeks and I have never seen this issue before.  But this time was likely long enough (months) to create an issue.

My Windows machines all do just fine with NTP updates.  So I doubt there is an ISP or other network issue.

And I will note that it wasn't just NTP that failed.  The rpi browser would not connect to bing.com either.  If your browser works, then you haven't replicated the issue yet.

ChasinSpin, 2025-05-02:
You have 2 issues, neither of which are due to Astrid

1. Your network time isn't updating automatically when you are connecting to the internet.  See above suggestions, note that windows and linux are different OS's so will likely behave differently.  Assuming your Astrid is the same image, and your network is good and you haven't upgraded the OS, then it should behave exactly the same as mine.  I've been unable to reproduce your issue on my Astrid.  This functionality is baked into raspbian, please contact the Raspberry Pi Foundation for support if it's not working as it should for you.  I have tried setting Astrid back to Jan 15, 2025 and rebooting, and after network connection with a correctly configured router it automatically updates the date to the correct date a few mins after starting the network connection.  This is the expected behaviour with a raspberry pi.  See screenshot:

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

I suggest first repeating my test above and waiting, and contacting Pi Foundation if it doesn't behave as above.

2. You attempted to access https / SSL certs with an incorrect system time.  This is failing in certificate validation, as it should do on most OS's.SSL Certs contain valid and expiring times, and clocks are shared in the handshaking during the validation process.    As 2. doesn't occur unless 1. occurs, then it's interdepedent with 1.  I suggest fixing 1 first, but you could also try the Pi Foundation for 2. too, or maybe the people who wrote the SSL RFC.

You could also add a realtime clock if you want the correct time on startup before a network or GPS connection, although it's not needed with Astrid, it will start quicker than waiting for a time sync.  If you search for Pi and Realtime clock it should come up with a number of options.

Closing this issue, as it's not an issue with Astrid.

stevepr, 2025-05-05:
I must have been too impatient in my initial power on of Astrid.  Today I powered up Astrid for the first time in a couple of days.  The date/time updated even though the unit was outside.  My original posting was wrong!  My unit should have updated inside if I had only waited a bit longer.  My apologies.

Closed 2025-05-02.

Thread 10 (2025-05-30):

RAVF truncated to 1.4 MB

tharan0, 2025-05-30:
Using my astrid-0100 unit, I started recording a 30fps video of the Denise occultation at 2025-05-30T05:02:24 UTC and stopped recording at 05:03:51 UTC.
Checked the file size of the RAVF the next morning, and it was only 1.4 MB with a Windows Date Modified of 2025-05-29 11:03:51 PM MDT which matches the UTC stop time above. Note that the thumb drive was qualified on 2025-05-11 and requalified on 2025-05-30.
Note also that the same astrid-0100 unit successfuly recorded a 10fps video of the Schorria occultation on 2025-05-24.
I am including the astrid.log and the video log of the Denise occultation.
I tried to add the truncated RAVF, but I got "File type not allowed: .ravf".
Any idea what may have caused the Deinise RAVF to be truncated?
In the mean time, I'm going to restrict my recording of future videos to 10fps.
Thanks,
--Terry Haran

[astrid.log](https://github.com/user-attachments/files/20526346/astrid.log)

[667_Denise_-_Haran__Anne_Crouse_Park_20250530_050224_100.log](https://github.com/user-attachments/files/20526352/667_Denise_-_Haran__Anne_Crouse_Park_20250530_050224_100.log)

tharan0, 2025-06-01:
Hi Mark: I think my problem was not shutting down cleanly. I had selected "Shutsown when recording is complete", which did successfully shut down Astrid, but when I was in the process of unplugging the power cable, I think I jiggled it, which caused astrid to powr up again. I then connected to astrid agai(n, and did a manual shutdown, and then later discovered that the RAVF was truncated. So l signed up for and recorded the (3976) Lise occultation of a magnitude 13.79 at 30fps. I again selected "Shutdown when recording is complete" which it did succssfully, but this time I was careful not to jiggle the power cable, and removed it cleanly. This time the RAVF file was apparently not tgruncated, and I was able to view the entire 2227 frame video in astrid player.iso go ahead and close this ticket, and thanks again for your help, --Terry

Closed 2025-06-01.

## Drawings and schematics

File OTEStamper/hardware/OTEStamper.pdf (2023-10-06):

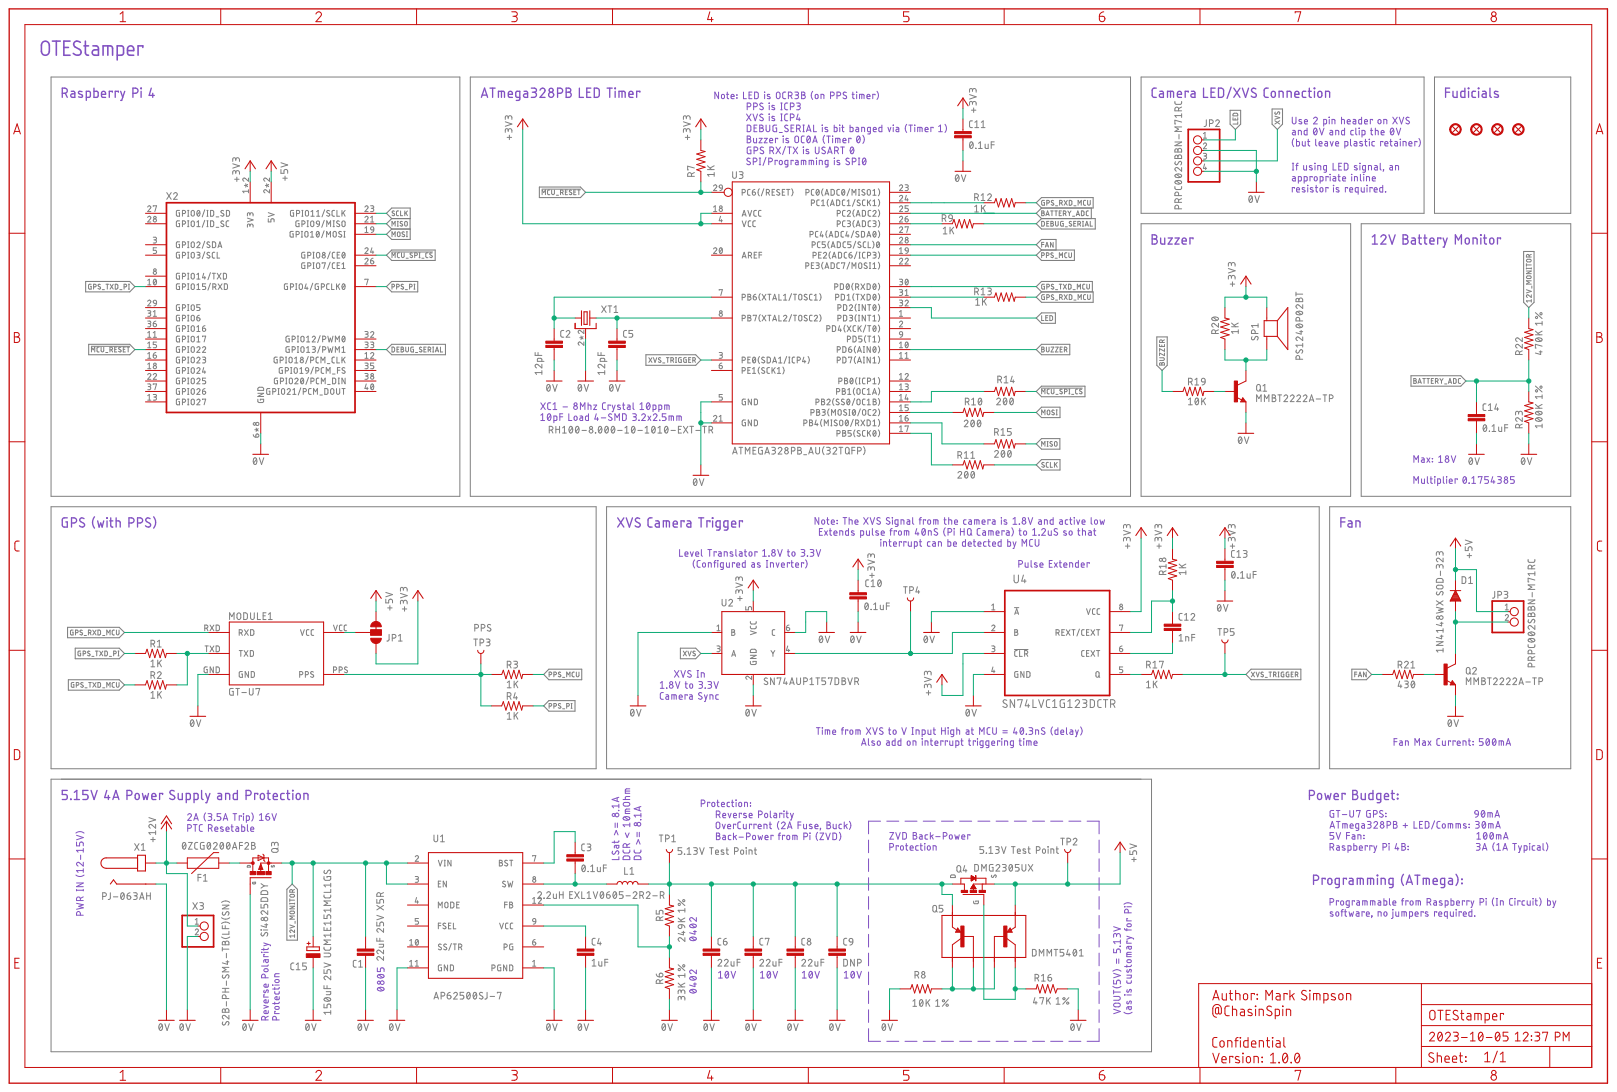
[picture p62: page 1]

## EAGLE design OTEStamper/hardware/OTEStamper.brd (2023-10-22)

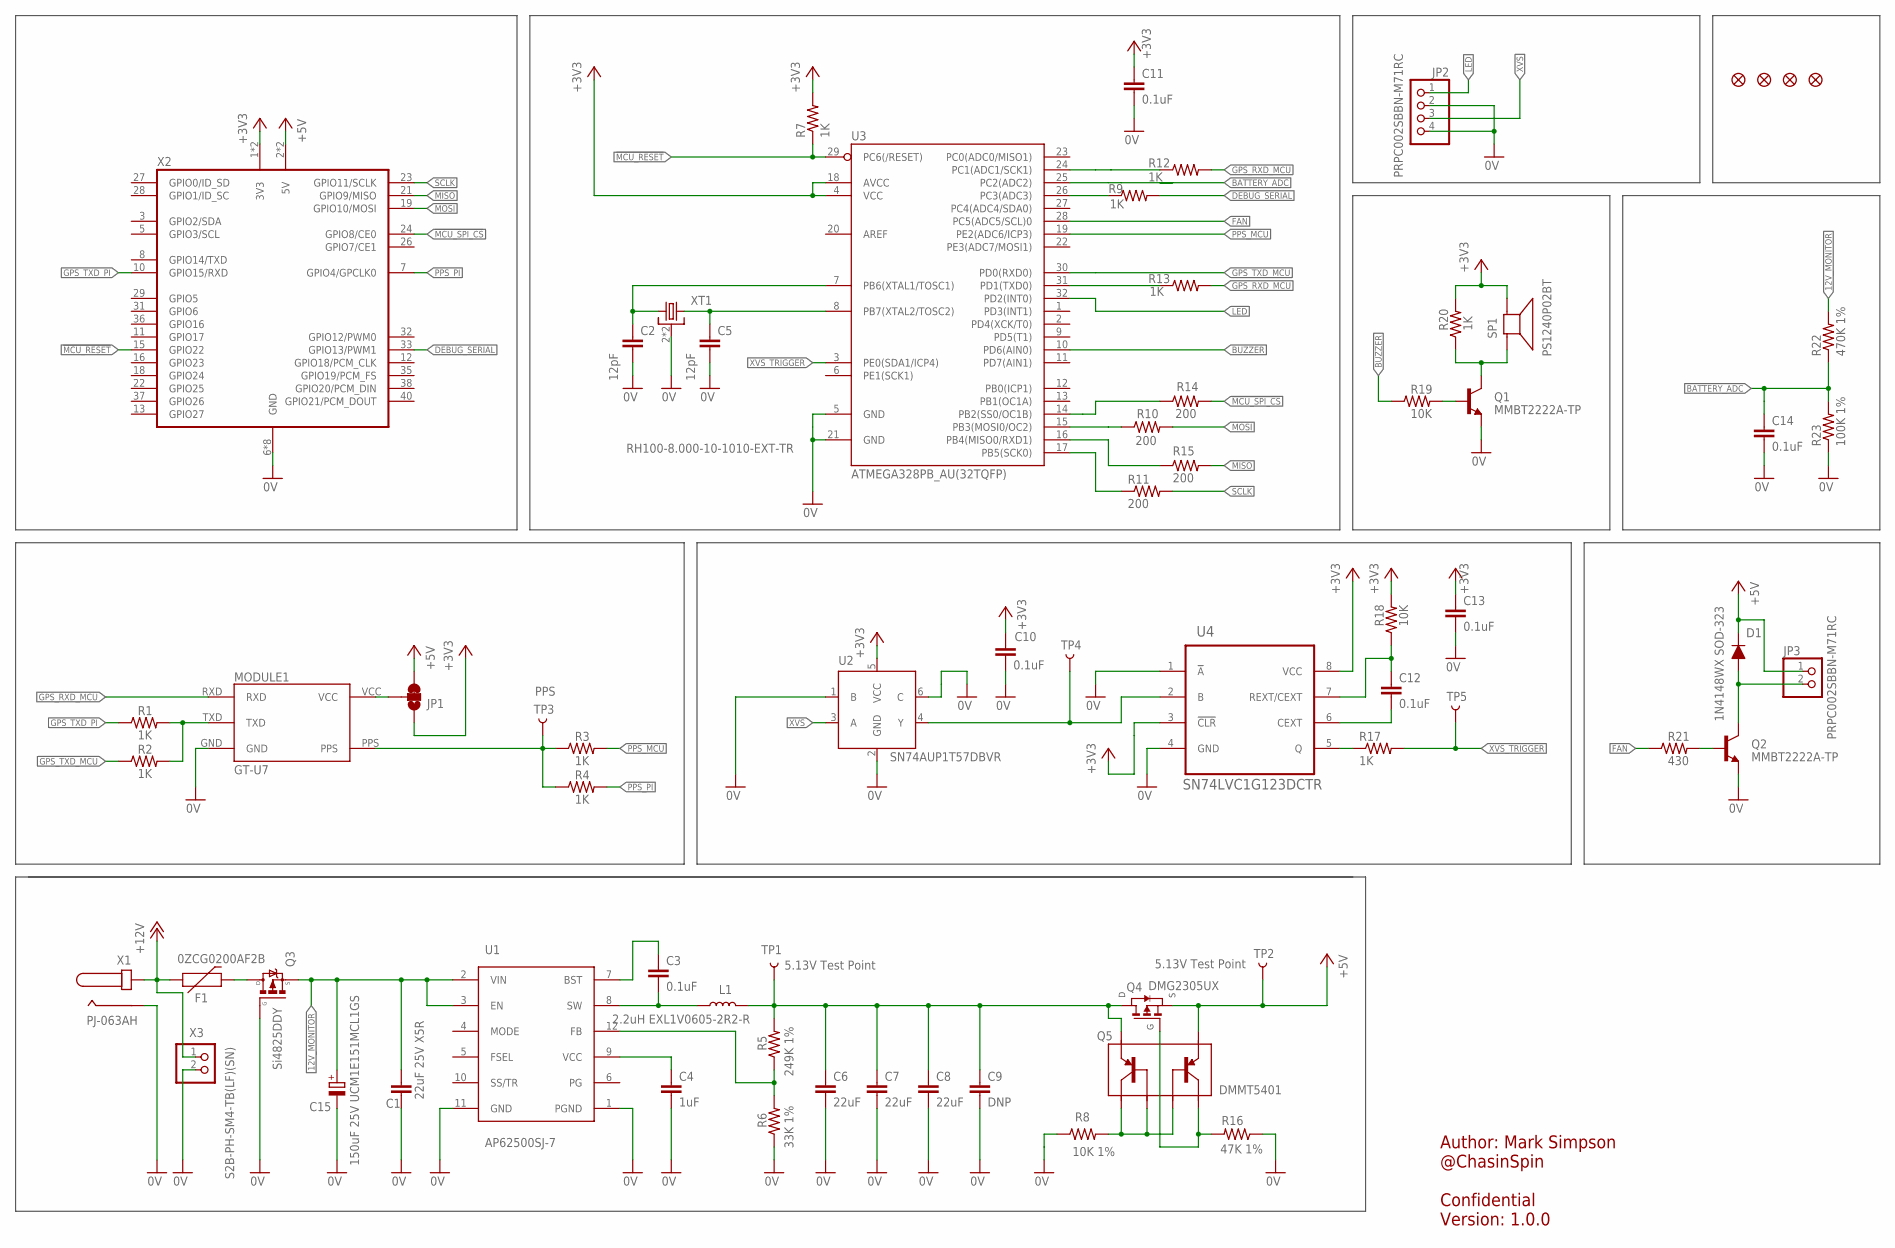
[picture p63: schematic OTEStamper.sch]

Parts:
C1: 22uF 25V X5R; C0805K
C2, C5: 12pF; C0603K
C3: 0.1uF; C0402K
C4: 1uF; C0402K
C6, C7, C8: 22uF; C0603K
C9: DNP; C0603K
C10, C11, C12, C13, C14: 0.1uF; C0603K
C15: 150uF 25V UCM1E151MCL1GS; UD-6,3X7,7_NICHICON
D1: 1N4148WX SOD-323; SOD-323
F1: 0ZCG0200AF2B; F1812
FD1, FD2, FD3, FD4: FIDUCIALUFIDUCIAL; FIDUCIAL-MICRO
JP1: JUMPER-SMT_3_1-NC_TRACE_SILK; SMT-JUMPER_3_1-NC_TRACE_SILK
JP2: PRPC002SBBN-M71RC; 1X04
JP3: PRPC002SBBN-M71RC; 1X02
L1: 2.2uH EXL1V0605-2R2-R; EXL1V0605
MODULE1: GT-U7
Q1, Q2: MMBT2222A-TP; SOT23-BEC
Q3: Si4825DDY; SOIC-8-BAR
Q4: DMG2305UX; SI2323DDS
Q5: DMMT5401; SOT26(SC74R)
R1, R2, R3, R4, R7, R9, R12, R13, R17, R20: 1K; R0603
R5: 249K 1%; R0402
R6: 33K 1%; R0402
R8: 10K 1%; R0603
R10, R11, R14, R15: 200; R0603
R16: 47K 1%; R0603
R18, R19: 10K; R0603
R21: 430; R0603
R22: 470K 1%; R0603
R23: 100K 1%; R0603
SP1: PS1240P02BT; PS12
TP1, TP2: 5.13V Test Point; PAD.03X.03
TP3: PPS; PAD.03X.03
TP4, TP5: TEST-POINT3; PAD.03X.03
U1: AP62500SJ-7; AP62500
U2: SN74AUP1T57DBVR; SOT23-6-DBV
U3: ATMEGA328PB_AU(32TQFP); TQFP32-08
U4: SN74LVC1G123DCTR; SSOP-8-DCT
X1: PJ-063AH
X2: ADAFRUIT_2222; RASPBERRY_PI_HAT
X3: S2B-PH-SM4-TB(LF)(SN); JST-PH-2-SMT-RA
XT1: RH100-8.000-10-1010-EXT-TR; ECS-ECX-32

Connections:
0V: C1.2, C2.2, C4.2, C5.2, C6.2, C7.2, C8.2, C9.2, C10.2, C11.2, C13.2, C14.2, C15.-, JP2.2, JP2.4, MODULE1.GND, Q1.E, Q2.E, Q3.4 (G), R6.1, R8.1, R16.1, R23.1, U1.1 (PGND), U1.11 (GND), U2.1 (B), U2.2 (GND), U2.6 (C), U3.5 (GND), U3.21 (GND), U4.1 (!A), U4.4 (GND), X1.2 (NEG), X1.SHIELD1 (NEG), X1.SHIELD2 (NEG), X2.6 (GND), X2.9 (GND), X2.14 (GND), X2.20 (GND), X2.25 (GND), X2.30 (GND), X2.34 (GND), X2.39 (GND), X3.2, XT1.2 (3), XT1.4 (3)
12V_MONITOR: C1.1, C15.+, Q3.1 (S), Q3.2 (S), Q3.3 (S), R22.2, U1.2 (VIN), U1.3 (EN)
!MCU_RESET: R7.1, U3.29 (PC6(/RESET)), X2.15 (GPIO22)
!MCU_SPI_CS: R14.2, X2.24 (GPIO8/CE0)
+3V3: C10.1, C11.1, C13.1, JP1.1, R7.2, R18.2, R20.2, SP1.P$1 (+), U2.5 (VCC), U3.4 (VCC), U3.18 (AVCC), U4.3 (!CLR), U4.8 (VCC), X2.1 (3V3), X2.17 (3V3)
+5V: D1.CATHODE (K), JP1.3, JP3.1, Q4.2 (S), Q5.5 (E2), TP2.P$1, X2.2 (5V), X2.4 (5V)
+12V: F1.1, X1.1 (POS), X3.1
BATTERY_ADC: C14.1, R22.1, R23.2, U3.25 (PC2(ADC2))
BUCK_SW: C3.2, L1.1, U1.8 (SW)
BUCK_VCC: C4.1, U1.9 (VCC)
BUCK_VOUT: C6.1, C7.1, C8.1, C9.1, L1.2, Q4.3 (D), Q5.6 (E1), R5.2, TP1.P$1
BUZZER: R19.1, U3.10 (PD6(AIN0))
DEBUG_SERIAL: R9.2, X2.33 (GPIO13/PWM1)
FAN: R21.1, U3.28 (PC5(ADC5/SCL)0)
FUSE_OUT: F1.2, Q3.5 (D), Q3.6 (D), Q3.7 (D), Q3.8 (D)
GPS_RXD_MCU: MODULE1.RXD, R12.2, R13.2
GPS_TXD_MCU: R2.1, U3.30 (PD0(RXD0))
GPS_TXD_PI: R1.1, X2.10 (GPIO15/RXD)
LED: JP2.1, U3.32 (PD2(INT0))
MCU_SPI_SELECT1: R14.1, U3.14 (PB2(SS0/OC1B))
MISO: R15.2, X2.21 (GPIO9/MISO)
MOSI: R10.2, X2.19 (GPIO10/MOSI)
unnamed: R9.1, U3.26 (PC3(ADC3))
unnamed: MODULE1.PPS, R3.1, R4.1, TP3.P$1
unnamed: D1.ANODE (A), JP3.2, Q2.C
unnamed: Q2.B, R21.2
unnamed: C3.1, U1.7 (BST)
unnamed: R5.1, R6.2, U1.12 (FB)
unnamed: Q1.B, R19.2
unnamed: Q1.C, R20.1, SP1.P$2 (-)
unnamed: MODULE1.TXD, R1.2, R2.2
unnamed: JP1.2, MODULE1.VCC
unnamed: R17.1, U4.5 (Q)
unnamed: TP4.P$1, U2.4 (Y), U4.2 (B)
unnamed: C12.2, U4.6 (CEXT)
unnamed: C12.1, R18.1, U4.7 (REXT/CEXT)
unnamed: C2.1, U3.7 (PB6(XTAL1/TOSC1)), XT1.1
unnamed: C5.1, U3.8 (PB7(XTAL2/TOSC2)), XT1.3 (2)
unnamed: R10.1, U3.15 (PB3(MOSI0/OC2))
unnamed: R15.1, U3.16 (PB4(MISO0/RXD1))
unnamed: R11.1, U3.17 (PB5(SCK0))
unnamed: R13.1, U3.31 (PD1(TXD0))
unnamed: R12.1, U3.24 (PC1(ADC1/SCK1))
unnamed: Q5.1 (C1), Q5.2 (B1), Q5.3 (B2), R8.2
unnamed: Q4.1 (G), Q5.4 (C2), R16.2
PPS_MCU: R3.2, U3.19 (PE2(ADC6/ICP3))
PPS_PI: R4.2, X2.7 (GPIO4/GPCLK0)
SCLK: R11.2, X2.23 (GPIO11/SCLK)
XVS: JP2.3, U2.3 (A)
XVS_TRIGGER: R17.2, TP5.P$1, U3.3 (PE0(SDA1/ICP4))

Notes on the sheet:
Author: Mark Simpson @ChasinSpin Confidential Version: 1.0.0

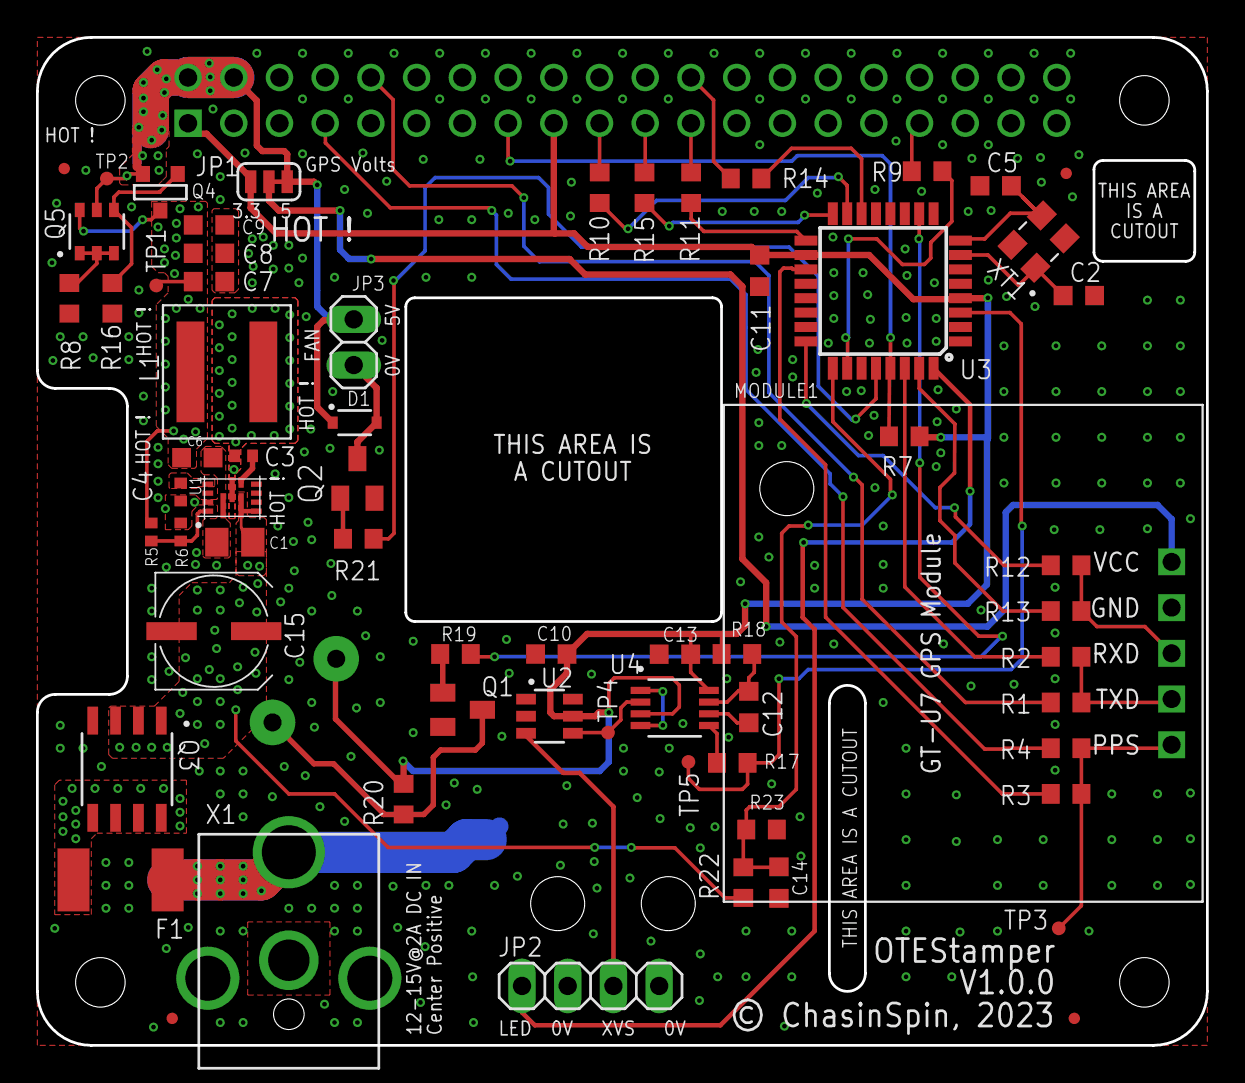
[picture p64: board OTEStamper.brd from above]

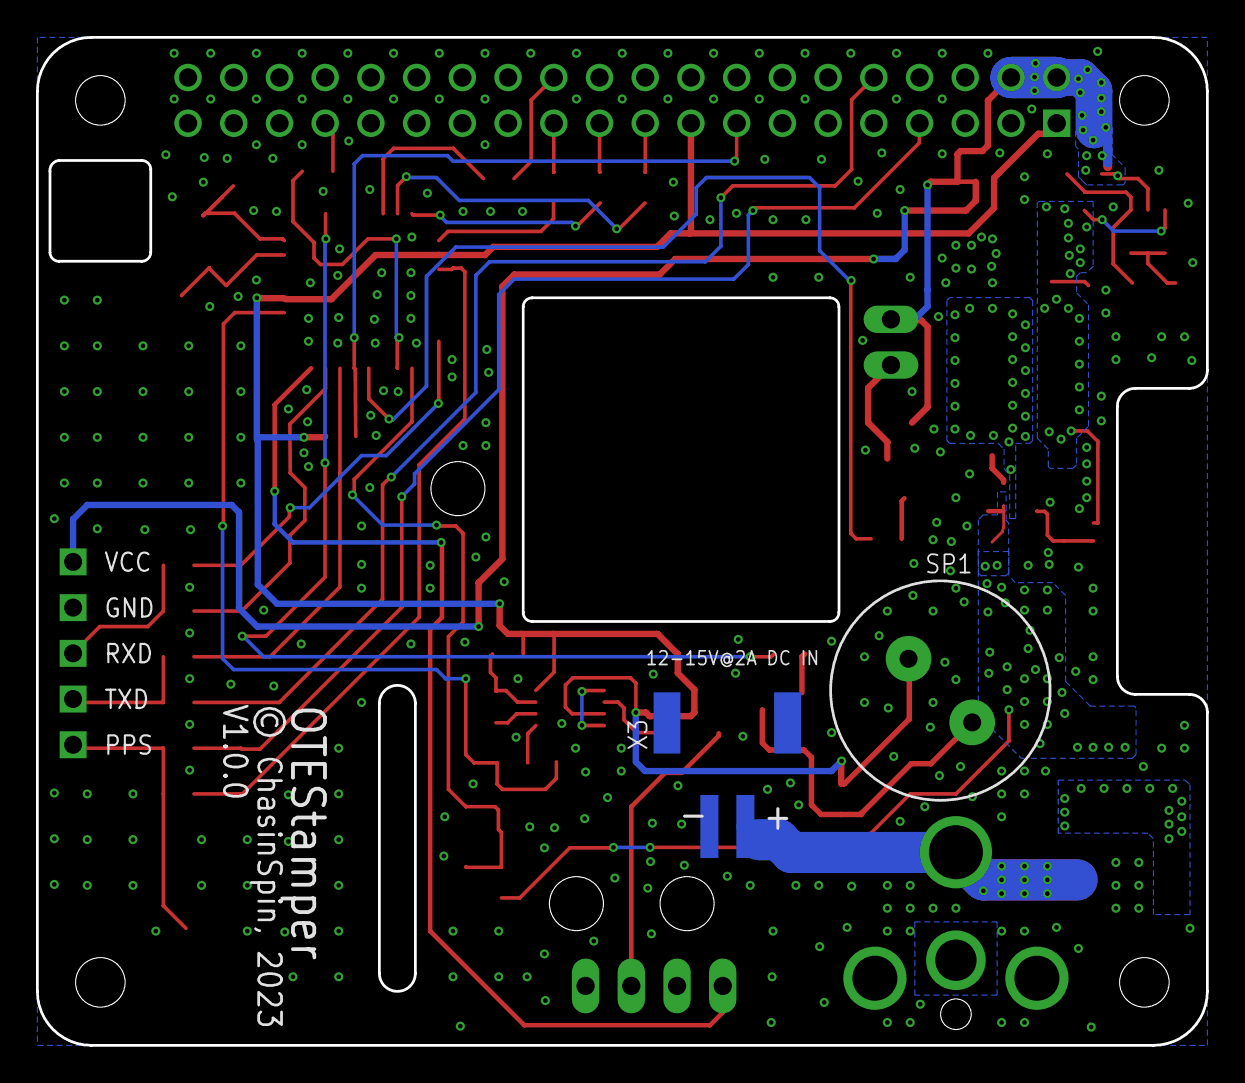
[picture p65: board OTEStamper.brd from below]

Board: 2 copper layers, 65.0 x 56.0 mm, 68 parts (2 on the bottom side), 50 nets.

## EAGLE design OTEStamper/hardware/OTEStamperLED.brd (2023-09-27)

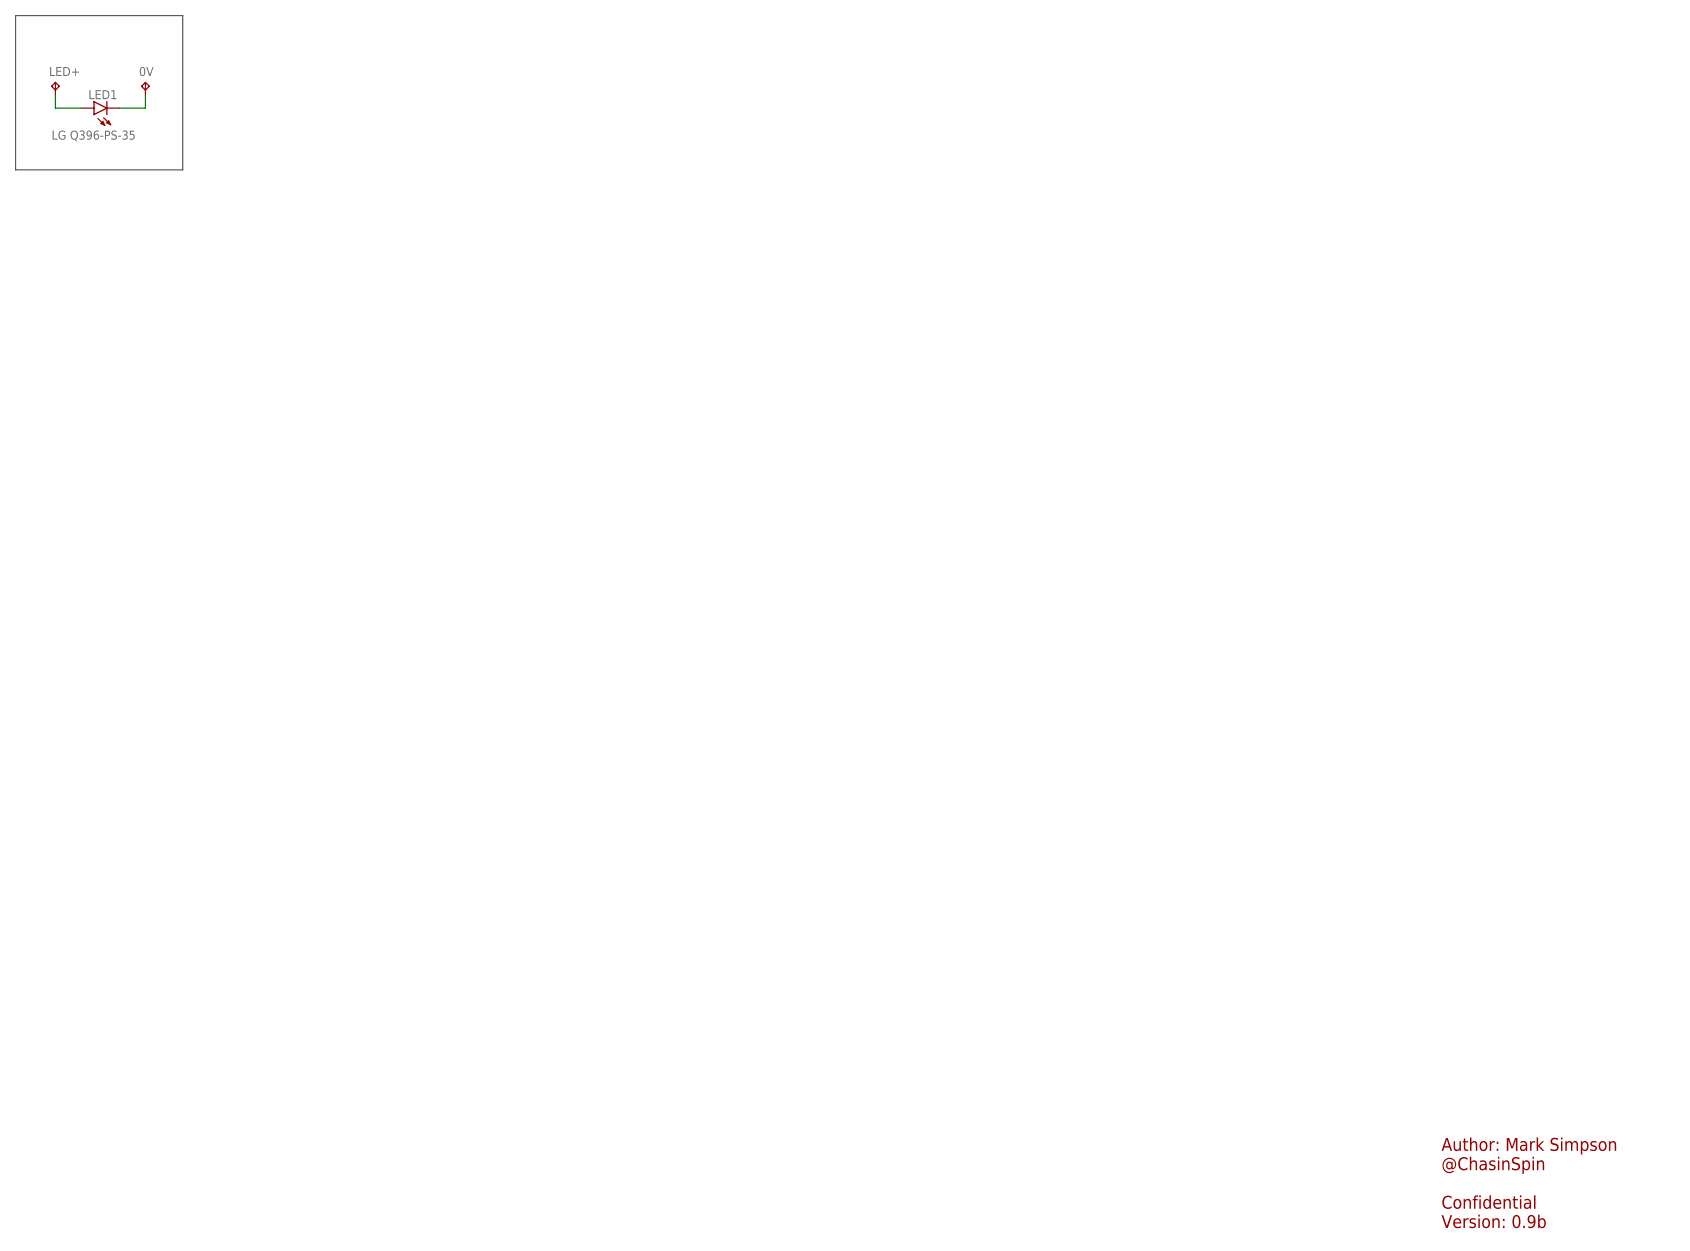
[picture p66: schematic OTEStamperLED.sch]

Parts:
0V: LED; TP16SQ
LED1: LG Q396-PS-35; CHIP-LED0603
LED+: LED; TP16SQ

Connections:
unnamed: LED1.A, LED+.TP
unnamed: 0V.TP, LED1.C

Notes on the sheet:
Author: Mark Simpson @ChasinSpin Confidential Version: 0.9b

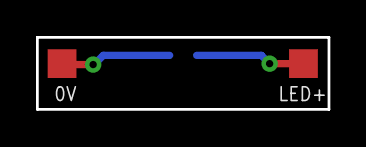
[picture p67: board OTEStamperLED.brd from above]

Board: 2 copper layers, 16.2 x 4.0 mm, 3 parts (1 on the bottom side), 2 nets.

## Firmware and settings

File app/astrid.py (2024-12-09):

#!/usr/bin/env python3

import os
import sys
import stat
import json
import atexit
import shutil
import argparse
import logging
import subprocess
from Ui import Ui
from pwd import getpwuid
from settings import Settings
from astsite import AstUtils
from UiDialogPanel import UiDialogPanel
from UiPanelConfig import UiPanelConfig
from UiPanelMessage import UiPanelMessage
from UiSplashScreen import UiSplashScreen
from PyQt5.QtWidgets import QApplication, QSplashScreen, QMessageBox
from PyQt5.QtCore import QCoreApplication, QUrl
from PyQt5.QtGui import QPixmap, QDesktopServices
from CameraModel import CameraModel, OperatingMode
from processlogger import ProcessLogger
from otestamper import OteStamper
from framewriter import FrameWriter
from datetime import datetime
import time
import urllib.request
import multiprocessing

if __name__ == '__main__':

	stylesheet		= 'stylesheets/default.qss'
	settings_folder		= None
	settings_summary	= None
	cam			= None
	otestamper		= None
	framewriter		= None
	current_version		= None
	processes		= []



	def shutdown_subprocesses():
		global cam, processes, otestamper

		if processes is not None:
			print('TERMINATE: shutting down multiprocessing subprocesses, pid: %d' % os.getpid())
			for process in processes:
				process.terminate()
			processes = None
	
		if cam is not None:
			print('TERMINATE: shutting down camera, pid: %d' % os.getpid())
			print('TERMINATE: shutting down indi server, pid: %d' % os.getpid())
			cam.indi.killIndiServer()
			cam = None
	


	# Things to do when sys.exit is called
	@atexit.register
	def sysexit_handler():
		print('TERMINATE: sysexit_handler, pid: %d **PLEASE WAIT**' % os.getpid())
		shutdown_subprocesses()


	def handle_exception(exc_type, exc_value, exc_traceback):
		if issubclass(exc_type, KeyboardInterrupt):
			sys.__excepthook__(exc_type, exc_value, exc_traceback)
			logger.critical('Keyboard interrupt')
			shutdown_subprocesses()
			sys.exit(-3)
		else:
			logger.critical("uncaught exception", exc_info=(exc_type, exc_value, exc_traceback))
			#sys.__excepthook__(exc_type, exc_value, exc_traceback)
			shutdown_subprocesses()
			sys.exit(-2)


	def settingsCallback(folder, summary):
		global settings_folder, settings_summary

		if folder is None or summary is None:
			QMessageBox.warning(None, ' ', 'Configuration changed. Relaunch Astrid to use new configuration.', QMessageBox.Ok)
			splash_screen.close()
			logger.warning('user changed config, aborting so that the user can relaunch with the new config...')
			shutdown_subprocesses()
			sys.exit(0)
		else:
			settings_folder = folder
			settings_summary = summary


	def getConfig(configs_fname):
		global current_version
		dialog = UiDialogPanel('Choose Config - Astrid v%s' % current_version, UiPanelConfig, args = {'configs_fname': configs_fname, 'astrid_drive': astrid_drive, 'settings_callback': settingsCallback, 'stylesheet_callback': setStylesheet})


	def checkAstridDrivePresent() -> bool:
		if not os.path.isdir(astrid_drive):
			dialog = UiDialogPanel('ASTRID USB thumb drive not found', UiPanelMessage, args = {'msg': 'Troubleshooting:\n    1. Insert USB Drive in blue USB port on ASTRID and try again', 'buttonText': 'Quit'})
			return False
		return True

	def checkSlowUSBDrive() -> bool:
		global astrid_drive

		cmd = "/home/pi/astrid/scripts/astrid-drive-info.sh"
		output = subprocess.check_output(cmd, shell=True)
		output = output.decode("utf-8")
		output = output.split("\n")

		usb3 = False
		diVendorId = diProductId = diSerial = ''
		for line in output:
			logger.info(line)
			if line.startswith('USB_VENDOR_ID='):
				diVendorId = line.split('=')[1]
			if line.startswith('USB_PRODUCT_ID='):
				diProductId = line.split('=')[1]
			if line.startswith('USB_SERIAL='):
				diSerial = line.split('=')[1]
			if line == 'SPEED=USB3':
				usb3 = True

		if not usb3:
			QMessageBox.critical(None, ' ', 'The USB thumb drive is not plugged into a USB 3 socket. Please Eject and plug into a BLUE usb socket. Astrid will terminate now', QMessageBox.Ok)
			logger.warning('astrid drive not in USB3 socket, aborting...')
			shutdown_subprocesses()
			sys.exit(0)

		qualcheck_fname = astrid_drive + '/qualification/qualcheck.txt'
		qcVendorId = qcProductId = qcSerial = qcStatus = qcNextVerification = ''
		if os.path.exists(qualcheck_fname):
			with open(qualcheck_fname, 'r') as fp:
				lines = fp.readlines() 

			for line in lines:
				line = line.rstrip()
				logger.info(line)
				line = line.rstrip()
				if line.startswith('VENDOR_ID='):
					qcVendorId = line.split('=')[1]
				if line.startswith('PRODUCT_ID='):
					qcProductId = line.split('=')[1]
				if line.startswith('SERIAL='):
					qcSerial = line.split('=')[1]
				if line.startswith('STATUS='):
					qcStatus = line.split('=')[1]
				if line.startswith('NEXT_VERIFICATION='):
					qcNextVerification = line.split('=')[1]

		expired = False
		if qcNextVerification != '':
			nextVerification = datetime.strptime(qcNextVerification, '%Y-%m-%dT%H:%M:%S')
			if datetime.utcnow() >= nextVerification:
				expired = True

		slowSpeed = False
		if diVendorId != qcVendorId or diProductId != qcProductId or diSerial != qcSerial or qcStatus != 'PASSED' or expired:
			slowSpeed = True
			
		hidden = Settings.getInstance().hidden
		if slowSpeed:
			hidden['slow_usb_drive'] = True
			QMessageBox.warning(None, ' ', 'The USB thumb drive is slow or unqualified.\n\nUse frame rates <= 10fps for video to avoid dropped frames or use a faster drive.\n\nYou can qualify this drive for faster speed by running Qualify Drive in Astrid Tools. Periodic qualification is required.', QMessageBox.Ok)
		else:
			hidden['slow_usb_drive'] = False
		Settings.getInstance().writeSubsetting('hidden')


	def fixAstridMultipleDrives():
		# If we have multiple drives (ASTRID and ASTRID1), then highly likely ASTRID is a folder accidentally created
		if os.path.isdir(astrid_drive):
			st = os.stat(astrid_drive)
			fowner = getpwuid(st.st_uid).pw_name
			if (not (st.st_mode & stat.S_IRGRP)) or (not (st.st_mode & stat.S_IXGRP)) or (not (st.st_mode & stat.S_IROTH)) or (not (st.st_mode & stat.S_IXOTH)):
				invalidPerms = True
			else:
				invalidPerms = False

			if os.path.isdir(astrid_drive + '1') or fowner != 'pi' or invalidPerms:
				print('Removing extra /media/pi/ASTRID folder so USB Drive can be mounted')
				os.system('sudo sh -c "/usr/bin/umount /dev/sda1;/usr/bin/rmdir /media/pi/ASTRID"')
				os.system('/usr/bin/udisksctl mount -b /dev/sda1 --no-user-interaction')


	def setStylesheet():
		""" Reads a stylesheet and using colorscheme, replaces the color macros """	
		ss = AstUtils.read_file_as_string(stylesheet)

		if os.path.exists(configs_fname):
			with open(configs_fname, 'r') as fp:
				configs = json.load(fp)

			if 'selectedColorScheme' not in configs.keys():
				configs['selectedColorScheme'] = 'Astro'
	
				jstr = json.dumps(configs, indent=4)
	
				with open(configs_fname, 'w') as fp:
					fp.write(jstr)
	
				colorSchemeName = configs['selectedColorScheme']
			else:
				colorSchemeName = configs['selectedColorScheme']
		else:
			colorSchemeName = 'Astro'
	
		with open('stylesheets/%s.colorscheme' % colorSchemeName) as f:
			cs = json.loads(f.read())
	
		# Do Macro search and replace
		for key in cs.keys():
			ss = ss.replace(key, cs[key])

		app.setStyleSheet(ss)	# Set the stylesheet


	# Returns True if this RaspberryPi is supported to run Asrtid, otherwise False
	
	def isThisASupportedRaspberryPi() -> bool:
		cmd = "/usr/bin/cat /proc/cpuinfo | /usr/bin/awk '/Revision/ {print $3}'"
		revcode = subprocess.check_output(cmd, shell=True)

		code = int(revcode, 16)
		new = (code >> 23) & 0x1
		model = (code >> 4) & 0xff
		mem = (code >> 20) & 0x7

		if new and model == 0x11 and mem >= 5 : # Note, 5 in the mem field is 8GB
			return True
		else:
			return False


	# Delete old astrometry.cfg's, we now generate one in tmp now

	def deleteAstrometryCfg():
		global configs_fname, astrid_drive
		if os.path.exists(configs_fname):
			with open(configs_fname, 'r') as fp:
				configs = json.load(fp)

			for config in configs['configs']:
				astrometryCfg = astrid_drive + '/configs/%s/astrometry.cfg' % config['configFolder']
				try:
					os.remove(astrometryCfg)
				except FileNotFoundError:
					pass


	def isUpdateNeeded():
		global splash_screen, current_version

		""" Prompts to upgrade if needed.  Also returns False if no internet and True if internet is connected. """

		with open('/home/pi/astrid/version.txt') as f:
			current_version = f.read().strip()

		try:
			urllib.request.urlcleanup()
			with urllib.request.urlopen('https://raw.githubusercontent.com/ChasinSpin/astrid/main/version.txt', timeout=5) as response:
				github_version = response.read().decode('utf-8').strip()
		except Exception as e:
			logger.info('Astrid version check failed (no internet?): %s' % str(e))
			return False

		logger.info('Version Current Astrid: %s' % current_version)
		logger.info('Version GitHub: %s' % github_version)

		if not current_version == github_version:
			qm_exit = QMessageBox.warning(None, ' ', 'A newer version of Astrid has been released.\n\nYour are using version %s and the latest version is: %s.\n\nAstrid follows the Rapid Application Development (RAD) model. You get more features and better stability with the latest version of the software and any support is conditional on the problem occuring with latest version being installed.\n\nChoose "Help" to see the release notes to find out what you\'re missing out on (wait for browser to launch).\n\nTo upgrade, first close Astrid and choose "Astrid Upgrade" on the desktop. ' % (current_version, github_version), QMessageBox.Ok | QMessageBox.Close | QMessageBox.Help)

			if   qm_exit == QMessageBox.Close:
				splash_screen.close()
				logger.warning('user closed version warning, aborting...')
				shutdown_subprocesses()
				sys.exit(0)
			elif qm_exit == QMessageBox.Help:
				QDesktopServices.openUrl(QUrl('https://raw.githubusercontent.com/ChasinSpin/astrid/main/releasenotes.txt'))

		return True


	#
	# MAIN
	#

	sys.excepthook = handle_exception

	# Parse arguments
	parser = argparse.ArgumentParser(description="astrid", formatter_class=argparse.ArgumentDefaultsHelpFormatter)
	parser.add_argument('-d', '--astrid_drive', help ='path to astrid drive', required=True)
	args = parser.parse_args()
	astrid_drive = args.astrid_drive
	configs_fname = astrid_drive + '/configs/configs.json'
	log_filename = astrid_drive + '/astrid.log'

	# Fix where ASTRID folder has been created in /media/pi/ASTRID, preventing mounting of the USB Drive in the correct place
	fixAstridMultipleDrives()

	# Setup logger
	multiprocessing.set_start_method('forkserver')
	#multiprocessing.set_start_method('spawn')

	if os.path.isdir(astrid_drive):
		processLogger = ProcessLogger(log_filename = log_filename, logging_level=logging.DEBUG)
		processes.append(processLogger)
		logger = processLogger.getLogger()
	else:
		logger = logging.getLogger()

	logger.debug('command args: %s' % sys.argv)
	logger.debug('astrid_drive: %s' % astrid_drive)

	# Run lightsout.sh
	subprocess.run(["/home/pi/astrid/scripts/lightsout.sh"])

	# Delete old astrometry.cfg's, we now generate one in tmp now
	deleteAstrometryCfg()

	# Start the QtApplication
	app = QApplication([])

	splash_screen = UiSplashScreen()

	# Read Stylesheet
	splash_screen.setMessage('Loading: Reading stylesheet...')
	setStylesheet()

	# Check the ASTRID drive is present
	if not checkAstridDrivePresent():
		logger.error('ASTRID flash drive not present, aborting...')
		shutdown_subprocesses()
		sys.exit(0)

	if not isThisASupportedRaspberryPi():
		QMessageBox.critical(None, ' ', 'The Raspberry Pi in this Astrid is not a supported!\n\nSupported models are:\n    Raspberry Pi 4B - 8GB Ram\n\nThis configuration is unsupported and likely won\'t work, please replace the Raspberry Pi with a supported one.', QMessageBox.Ok)

	# Launch OTEStamper
	otestamper = OteStamper()
	processes.append(otestamper)

	# Launch FrameWriter
	framewriter = FrameWriter()
	processes.append(framewriter)

	# Do a version check
	AstUtils.setInternetPresent(isUpdateNeeded())

	# Read settings
	splash_screen.setMessage('Loading: Reading settings...')
	getConfig(configs_fname)
	if settings_folder is None:
		splash_screen.close()
		logger.warning('user cancelled config, aborting...')
		shutdown_subprocesses()
		sys.exit(0)

	checkSlowUSBDrive()

	# Check Free Space
	actual_free_space = shutil.disk_usage(astrid_drive)[2] / (1024 * 1024 * 1024)
	min_free_space = Settings.getInstance().general['free_space']
	if actual_free_space < min_free_space:
		QMessageBox.warning(None, ' ', 'The USB Thumb Drive is nearly full.\n\nFree space left is %0.2f GB.\n\nOn a desktop, please delete some files to free up some space and then empty the recycle bin.\n\nAlternatively you can delete files from Astrid too.' % actual_free_space, QMessageBox.Ok)

	# Load the camera
	try:
		cam = CameraModel(previewWidth=640, previewHeight=480, splashScreen=splash_screen)
	except RuntimeError:
		# This never gets called as exitNow is called after this object has been created
		shutdown_subprocesses()
		sys.exit(0)

	# Save the current version to settings so we can recall it for the ravf later
	Settings.getInstance().hidden['version'] = current_version
	Settings.getInstance().writeSubsetting('hidden')

	# Start the main window
	windowTitle = 'Astrid: %s' % settings_summary
	window = Ui(cam, windowTitle)

	# Finish setup and close the splash screen
	cam.ui = window
	otestamper.setUi(window)
	splash_screen.close()
	cam.updateMountPositionDisplay()

	# Display the status
	window.showStatusMessage("Astrid started")

	exit_code = app.exec()
	shutdown_subprocesses()
	sys.exit(exit_code)

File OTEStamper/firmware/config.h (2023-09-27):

#define FIRMWARE_VERSION	0x0001
#define OTESTAMPER_ID		0xFD032A1C



//IMPORTANT: When debug is enabled, FRAME Interrupts are disabled
//#define DEBUG

#define F_CPU 8000000L

#define PIN_LED_PORT		PORTD
#define PIN_LED_PIN		PIND
#define PIN_LED_DDR		DDRD
#define PIN_LED_BIT		_BV(PD2)

#define PIN_FRAME_INT_PORT	PORTC
#define PIN_FRAME_INT_PIN	PINC
#define PIN_FRAME_INT_DDR	DDRC
#define PIN_FRAME_INT_BIT	_BV(PC3)

#define PIN_DEBUG_PORT		PIN_FRAME_INT_PORT
#define PIN_DEBUG_PIN		PIN_FRAME_INT_PIN
#define PIN_DEBUG_DDR		PIN_FRAME_INT_DDR
#define PIN_DEBUG_BIT		PIN_FRAME_INT_BIT

#define PIN_SPI_MISO_PORT	PORTB
#define PIN_SPI_MISO_PIN	PINB
#define PIN_SPI_MISO_DDR	DDRB
#define PIN_SPI_MISO_BIT	_BV(PB4)

#define PIN_SPI_MOSI_PORT	PORTB
#define PIN_SPI_MOSI_PIN	PINB
#define PIN_SPI_MOSI_DDR	DDRB
#define PIN_SPI_MOSI_BIT	_BV(PB3)

#define PIN_SPI_SCLK_PORT	PORTB
#define PIN_SPI_SCLK_PIN	PINB
#define PIN_SPI_SCLK_DDR	DDRB
#define PIN_SPI_SCLK_BIT	_BV(PB5)

#define PIN_SPI_CS_PORT		PORTB
#define PIN_SPI_CS_PIN		PINB
#define PIN_SPI_CS_DDR		DDRB
#define PIN_SPI_CS_BIT		_BV(PB2)

#define PIN_PPS_PORT		PORTD
#define PIN_PPS_PIN		PIND
#define PIN_PPS_DDR		DDRD
#define PIN_PPS_BIT		_BV(PD2)

#define PIN_XVS_PORT		PORTD
#define PIN_XVS_PIN		PIND
#define PIN_XVS_DDR		DDRD
#define PIN_XVS_BIT		_BV(PD3)

#define PIN_BUZZER_PORT		PORTD
#define PIN_BUZZER_PIN		PIND
#define PIN_BUZZER_DDR		DDRD
#define PIN_BUZZER_BIT		_BV(PD6)

#define PIN_FAN_PORT		PORTC
#define PIN_FAN_PIN		PINC
#define PIN_FAN_DDR		DDRC
#define PIN_FAN_BIT		_BV(PC5)

#define DEBUG_BAUD_RATE		9600

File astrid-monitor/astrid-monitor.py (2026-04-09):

#!/usr/bin/env python3

import sys
sys.path.append('/home/pi/.local/lib/python3.9/site-packages')

import json
import psutil
import socket
import subprocess
import time
import serial
import adafruit_board_toolkit.circuitpython_serial
from datetime import datetime



version = '1.3.0'

minidisplay_present	= True
MONITOR_REPEAT		= 5		# Seconds



def runCommand(cmd, line_starts_with = None):
	"""
		Runs a command, cmd is an array consisting of the command and parameters
		If line_starts_with is set to a str, the first line with starting with that string is returned,
		otherwise returns stdout from the command
	"""
	result = subprocess.run(cmd, capture_output = True, text = True)
	if line_starts_with is not None:
		lines = result.stdout.split('\n')
		for line in lines:
			if line.startswith(line_starts_with):
				return line
	return result.stdout


def extractIP4Address(snicaddrs):
	# Extracts the IP4 Address out of psutil net_if_addrs
	for snicaddr in snicaddrs:
		if snicaddr.family == socket.AF_INET:
			return snicaddr.address
	return None
	

def getNetworkStatus():
	""" Gets the network configuration and returns it as a dictionary """
	status = {}

	# Obtain IP addresses (only works with IP4 currently)
	wlan0_ip = None
	eth0_ip = None
	if_addrs = psutil.net_if_addrs()
	if 'wlan0' in if_addrs.keys():
		wlan0_ip = extractIP4Address(if_addrs['wlan0'])
	if 'eth0' in if_addrs.keys():
		eth0_ip = extractIP4Address(if_addrs['eth0'])

	hostname = socket.gethostname() + '.local'
	#print('hostname:', hostname)

	if eth0_ip is None:
		iwconfig_result = runCommand( ['/usr/sbin/iwconfig', 'wlan0'] )

		essid = ''
		freq = ''
		link_quality = ''
		signal_level = ''
		ip_addr = ''
		if wlan0_ip is not None:
			ip_addr = wlan0_ip

		# Scan the iwconfig output and parse what we need
		for line in iwconfig_result.split('\n'):
			if 'ESSID:"' in line:
				essid = line.split('ESSID:"')
				essid = essid[1].split('" ')[0]
			if 'Mode:' in line:
				mode = (line.split('Mode:')[1]).split(' ')[0]
			if 'Frequency:' in line:
				freq = (line.split('Frequency:')[1]).split(' ')[0]
			if 'Link Quality=' in line:
				link_quality = (line.split('Link Quality=')[1]).split(' ')[0]
			if 'Signal level=' in line:
				signal_level = (line.split('Signal level=')[1]).split(' ')[0]

		if link_quality != '':
			percent = link_quality.split('/')
			percent = (float(percent[0]) / float(percent[1])) * 100.0
			percent = '%0.0f%%' % percent
			link_quality = percent

		# If we're running Ad-hoc, then get the ESSID from the hostapd.conf file
		if mode == 'Master':
			with open('/etc/hostapd/hostapd.conf') as fp:
				lines = [line.rstrip() for line in fp]
			for line in lines:
				if line.startswith('ssid='):
					essid = line.split('ssid=')[1]
					break
			
		#print('ESSID:<%s>' % essid)
		#print('mode:<%s>' % mode)
		#print('freq:<%s>' % freq)
		#print('link_quality:<%s>' % link_quality)
		#print('signal_level:<%s>' % signal_level)
	
		if mode == 'Managed':
			status['mode'] = 'wifi managed'
			status['ssid'] = essid
			status['ip'] = ip_addr
			status['hostname'] = hostname
			status['frequency'] = freq
			status['linkquality'] = link_quality
			status['signallevel'] = signal_level
		elif mode == 'Master':
			status['mode'] = 'wifi hotspot'
			status['ssid'] = essid
			status['ip'] = ip_addr
			status['hostname'] = hostname
		else:
			status['mode'] = 'unknown'
	else:
		status['mode'] = 'ethernet'
		ip_addr = eth0_ip
		status['ip'] = ip_addr
		status['hostname'] = hostname

	return status


def getShutdownStatus(shutdownMode):
	""" Gets the shutdown status and returns it as a dictionary """
	status = {}
	status['shutdownMode'] = shutdownMode
	return status


def getAstridStatus():
	""" Gets the astrid status and returns it as a dictionary """
	status = {}
	return status


def getStatus(shutdownMode):
	""" Get the status of the system and returns it as a dictionary """
	now = datetime.now()

	status = {}
	status['version']	= version
	status['timestamp']	= now.strftime('%Y-%m-%d %H:%M:%S UTC')
	status['network']	= getNetworkStatus()
	status['astrid']	= getAstridStatus()
	status['shutdown']	= getShutdownStatus(shutdownMode)
	return status


#
# MAIN
#

serialPort = None
shutdownMode = 0

while True:
	status = getStatus(shutdownMode)

	comports = adafruit_board_toolkit.circuitpython_serial.repl_comports()
	if comports:
		if serialPort is None:
			# If we have a mini display connected, write to it
			serial_device = comports[0].device
			serialPort = serial.Serial(port = serial_device, baudrate = 115200, bytesize = 8, timeout = MONITOR_REPEAT, stopbits = serial.STOPBITS_ONE)
	else:
		if serialPort is not None:
			serialPort.close()
		serialPort = None
		#print(status)

	if shutdownMode == 2:
		shutdownMode = 3
	elif shutdownMode == 3:
		shutdownMode = 4
	elif shutdownMode == 4:
		runCommand( ['/usr/sbin/poweroff'] )

	d0Pressed = False
	d1Pressed = False
	d2Pressed = False

	if serialPort is not None:
		jstr = 'ASTRIDMONITOR:' + json.dumps(status, indent=4) + '\r'
		serialPort.write(bytes(jstr, 'ascii'))
		#print(jstr, file=sys.stderr)

		# Read button presses
		try:
			lines = serialPort.readlines()
		except:
			pass

		for line in lines:
			if line == b'MINIDISPLAY:ButtonD0\r\n':
				d0Pressed = True
			if line == b'MINIDISPLAY:ButtonD1\r\n':
				d1Pressed = True
			if line == b'MINIDISPLAY:ButtonD2\r\n':
				d2Pressed = True
	else:
		time.sleep(MONITOR_REPEAT)

	if d0Pressed:
		print('Button D0 Pressed')
	if d1Pressed:
		print('Button D1 Pressed')
	if d2Pressed:
		print('Button D2 Pressed')

	if d0Pressed or d1Pressed:
		if shutdownMode > 0:
			shutdownMode = 0
		else:
			if status['network']['mode'] == 'wifi managed':
				# Switch to Hotspot
				proc = subprocess.Popen( ['/usr/bin/autohotspot', '--force_hotspot'] )
			elif status['network']['mode'] == 'wifi hotspot':
				# Switch to Managed
				proc = subprocess.Popen( ['/usr/bin/autohotspot'] )
	elif d2Pressed:
		if shutdownMode == 0:
			shutdownMode = 1
		elif shutdownMode == 1:
			shutdownMode = 2

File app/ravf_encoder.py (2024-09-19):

""" RAVF encoder functionality """

from processlogger import ProcessLogger
from ravf import RavfImageFormat, RavfColorType, RavfImageEndianess, RavfMetadataType, RavfFrameType
from picamera2.encoders.encoder import Encoder
from datetime import datetime,timezone
#from request import _MappedBuffer
from picamera2.request import _MappedBuffer
from otestamper import OteStamper
from settings import Settings
from datetime import datetime
import time
import sys
import signal
import queue    # imported for using queue.Empty exception
import multiprocessing
from framewriter import FrameWriter
from processravfwriter import ProcessRavfWriter
from fillinnareport import FillInNAReport

class RavfEncoder(Encoder):

	MINIMUM_FRAME_DURATION_MICROS = 16563	# Maximum frame rate the camera can be set to, for the IMX296 this is just over 60fps

	def __init__(self, filename: str, metadata: dict, camera: object):
		super().__init__()

		self.processLogger = ProcessLogger.getInstance()
		self.logger = self.processLogger.getLogger()

		self.logger.info('RavfEncoder init')

		self.camera			= camera
		self.filename			= filename
		self.metadata			= metadata
		
		self.frameHalfDurationMicros	= int(self.metadata['frameDurationMicros']/2.0)
		self.lastTimestamp		= 0
		self.otestamper			= OteStamper.getInstance()
		self.lastSequence		= 0
		self.firstFrame			= True
		self.lastTimeFrame		= 0
		self.lastCameraTimestamp	= 0
		self.syncState			= 0
		self.recording			= False



	def start(self):
		self.logger.info('RavfEncoder start')

		self.recording			= True
		self.firstFrame = True
		self.otestamper.resetStatistics()
		self.otestamper.stopUpdateStatusTimer()
		self.otestamper.startRecordingVideo()
		self.syncState = 0
		self.waiting_frame_count = 14
		super().start()

		# Calculate nanoseconds since 2010 from the system for recording start time
		# Note this time is not necessarily accurate, it's just a guideline
		recording_start_utc = datetime.utcnow()
		self.start_observing_time = (recording_start_utc.hour, recording_start_utc.minute, float(recording_start_utc.second) + (recording_start_utc.microsecond/1000000.0))
		recording_start_utc = time.mktime(recording_start_utc.timetuple())    # Convert to unix epoch
		recording_start_utc -= 1262304000
		recording_start_utc *= 1000000000                                     # Convert to nanoseconds
		recording_start_utc = int(recording_start_utc)

		self.__required_metadata_entries = [
			('COLOR-TYPE',                  int(self.metadata['color_type'].value)),
			('IMAGE-ENDIANESS',             int(RavfImageEndianess.LITTLE_ENDIAN.value)),
			('IMAGE-WIDTH',                 int(self.width)),
			('IMAGE-HEIGHT',                int(self.height)),
			('IMAGE-ROW-STRIDE',            int(self.stride)),
			('IMAGE-FORMAT',                int(self.metadata['image_format'].value)),
			('IMAGE-BINNING-X',             self.metadata['binning'][0]),
			('IMAGE-BINNING-Y',             self.metadata['binning'][1]),
			('FRAME-TIMING-ACCURACY',       int(4)),
			('LATITUDE',                    self.otestamper.status['latitude']), 
			('LONGITUDE',                   self.otestamper.status['longitude']),
			('ALTITUDE',                    self.otestamper.status['altitude']),
			('OBSERVER',                    Settings.getInstance().observer['observer_name']),
			('OBSERVER-ID',                 Settings.getInstance().observer['observer_id']),
			('INSTRUMENT',                  'Astrid'),
			('INSTRUMENT-VENDOR',           'ChasinSpin'),
			('INSTRUMENT-VERSION',          Settings.getInstance().hidden['version']),
			('INSTRUMENT-SERIAL',           '00001'),
			('INSTRUMENT-FIRMWARE-VERSION', '0.9a'),
			('INSTRUMENT-GAIN',             Settings.getInstance().camera['gain']),
			('INSTRUMENT-SENSOR',           self.metadata['sensor']),
			('INSTRUMENT-GAMMA',            1.0),
			('INSTRUMENT-SHUTTER',          self.metadata['shutter_ns']),
			('INSTRUMENT-OFFSET',           0),
			('RECORDER-SOFTWARE',           'Astrid'),
			('RECORDER-SOFTWARE-VERSION',   '0.9a'),
			('RECORDER-HARDWARE',           'OTEStamper'),
			('RECORDER-HARDWARE-VERSION',   '0.9a'),
			('OBJNAME',                     self.metadata['objName']),
			('RA',                          self.metadata['ra']),
			('DEC',                         self.metadata['dec']),
			('EQUINOX',                     0),
			('COMMENT',                     'Astrid RAVF Format'), 
			('RECORDING-START-UTC',         recording_start_utc),
			('TELESCOPE',			self.metadata['telescope']),
		]

		self.logger.info(self.__required_metadata_entries)

		self.__user_metadata_entries = [
			('INSTRUMENT-SENSOR-PIXEL-SIZE-X',	RavfMetadataType.FLOAT32,	self.metadata['sensorPixelSizeX']),
			('INSTRUMENT-SENSOR-PIXEL-SIZE-Y',	RavfMetadataType.FLOAT32,	self.metadata['sensorPixelSizeY']),
			('FOCAL-LENGTH',			RavfMetadataType.FLOAT32,	self.metadata['focalLength']),
			('STATION-NUMBER',			RavfMetadataType.UINT16,	self.metadata['stationNumber']),
			('STATION-HOSTNAME',			RavfMetadataType.UTF8STRING,	self.metadata['hostname']),
			('INSTRUMENT-FRAMES-PER-SECOND',	RavfMetadataType.FLOAT32,	1.0/(self.metadata['shutter_ns']/1000000000.0)),
		]

		if 'occultationPredictedCenterTime' in self.metadata.keys():
			self.__user_metadata_entries.append( ('OCCULTATION-PREDICTED-CENTER-TIME',	RavfMetadataType.UTF8STRING,	self.metadata['occultationPredictedCenterTime']) )

		if 'occultationPredictedCenterTimeFull' in self.metadata.keys():
			self.__user_metadata_entries.append( ('OCCULTATION-PREDICTED-CENTER-TIME-FULL',	RavfMetadataType.UTF8STRING,	self.metadata['occultationPredictedCenterTimeFull']) )

		if 'occultationObjectNumber' in self.metadata.keys():
			self.__user_metadata_entries.append( ('OCCULTATION-OBJECT-NUMBER',		RavfMetadataType.UTF8STRING,	self.metadata['occultationObjectNumber']) )

		if 'occultationObjectName' in self.metadata.keys():
			self.__user_metadata_entries.append( ('OCCULTATION-OBJECT-NAME',		RavfMetadataType.UTF8STRING,	self.metadata['occultationObjectName']) )

		if 'occultationStar' in self.metadata.keys():
			self.__user_metadata_entries.append( ('OCCULTATION-STAR',			RavfMetadataType.UTF8STRING,	self.metadata['occultationStar']) )

		if 'instrumentAperture' in self.metadata.keys():
			self.__user_metadata_entries.append( ('INSTRUMENT-APERTURE',			RavfMetadataType.UINT16,	self.metadata['instrumentAperture']) )

		if 'instrumentOpticalType' in self.metadata.keys():
			self.__user_metadata_entries.append( ('INSTRUMENT-OPTICAL-TYPE',		RavfMetadataType.UTF8STRING,	self.metadata['instrumentOpticalType']) )

		self.logger.info('Width: %d' % self.width)
		self.logger.info('Height: %d' % self.height)
		self.logger.info('Stride: %d' % self.stride)

		buffer_size = self.stride * self.height

		self.framewriter = FrameWriter.getInstance()
		self.framewriter.createSharedMemory(buffer_size)
		self.framewriter.startRecordingVideo(self.filename, self.__required_metadata_entries, self.__user_metadata_entries)
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

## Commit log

2023-09-27 Initial Version
    [AstridCase1.scad, AstridCase1.stl, LensCap1_25inch.scad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]
2023-09-28 Adding support for automatic astrometry index download
    [astrometry.cfg]
2023-10-02 Renamed Auto Stretch to Stretch to avoid confusion until it's auto. Disabled Star Detection as it's not complete yet. Updated some settings to allow them to be edited
    [settings.py]
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2023-10-05 OTEStamper Board Revision 1.0.0
    [OTEStamper.brd, OTEStamper.sch, OTEStamperCamera.brd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]
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2023-10-06 For polar align test mode and platesolving, now displays the images after selection
2023-10-07 Adding colorschemes introduced bug where when USB drive isn't present it bombed instead of displayed error message. Fixed.
    [astrid.py]
2023-10-09 Fixed bug where stretch lower = upper caused division by zero, and to handle lower being > upper
    [DisplayOps.py]
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2023-10-11 Fixed bug where dithering when no object was selected caused an exception to be raised
    [CameraModel.py]
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2023-10-22 Extending XVS monostable pulse extender from 1.2uS to 1ms, to account for different camera boards with different XVS pulse lengths.
    [OTEStamper.brd, OTEStamper.sch]
2023-10-26 Updating documentation, improving case design
    [AstridCase1.scad, AstridCase1.stl, AstridCase1_CameraCover.stl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]
2023-10-28 Adding fan setting to switch off fan during acquisition for vibration reasons
    [CameraModel.py, otestamper.py, settings.py]
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2023-11-01 Add check to ensure Astrid is running on a Raspberry Pi 4B - 8GB and popup a message if it's not
2023-11-02 Adding checking for Chromium Browser running when recording starts, in which case it prompts to kill Chromium
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2023-11-02 Moving switching off chromium hardware acceleration from upgrade.sh to install.sh so it doesn't require 2 updates to run
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2023-11-03 Fixed error with voltage not set
2023-11-03 Soemtimes, voltage can be 0.0 depending on timing at startup prompting a low voltage alert. Fixed.
2023-11-04 Adding Occeltation XML search. This is an interim checkin for backup, not working yet
    [OccelmntXMLSearch.py, UiWidgetSearchXMLPredictionsControls.py, pathcomputation.py]
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2023-11-04 Changing pressure to 0, as altitudes below 5deg in AltAz conversions are numerically unstable
    [astsite.py]
2023-11-05 Added disable file manager from popping up when USB Drive is inserted
2023-11-06 Fixed thread killing. This should improve things, time will tell.
2023-11-08 Fixing thread bug in PlateSolver when cancel is pressed
2023-11-08 Fixing thread bug in platesolver
2023-11-16 Adding site location to fits file (can be switched off in settings for privacy)
2023-11-16 Adding battery cover
    [BatteryCover.scad, BatteryCover.stl]
2023-11-17 Exit for shutdown now has a timer, and instructions on properly shutting down
2023-11-18 Fixed plate solve not working on player
    [AstrometryDownload.py]
2023-11-20 OWCloud does not provide occelmnt data for Moons of planets, so added code to detect 404 error and silently ignore
    [owcloud.py]
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2023-12-03 Workaround for bug, where ASTRID folder is created forcing the USB drive to ASTRID1 and a launch failure. This fix removes it now and unmount/remounts the USB drive to the correct place.
    [astrid.py]
2023-12-03 Adding print to indicate fix to the last commit
    [astrid.py]
2023-12-04 Switched Prompt For Darks after Acquisition to off, as it has limited use
2023-12-17 Updating to replacement NA Report Form, and added ADVS/Other for autofill
    [CameraModel.py, fillinnareport.py]
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2023-12-18 Added "Save Fits Finder" to Player, which can be used after a plate solver to identify the target. This can be loaded as a finder image into pymovie to make it easy to place targets. Improved constra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
2023-12-18 Updating documentation, adding 3D printed board parts plate.
    [AstridCase1.scad]
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2023-12-23 Fixed floating point and integer validators in fields to process incomplete entries better
    [UiWidgetSearchXMLPredictionsControls.py, settings.py]
2023-12-30 Reduced startup time with no internet by 5 seconds Timing Status Button is now red when system time differs from GPS time by more than 2 second GPS Time/System Time difference split out to Delta Chro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
    [CameraModel.py, astcoord.py, astrid.py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]
2023-12-30 Goto button is now disabled on Goto Prepoints whilst the scope is moving
2023-12-31 All mounts now switch tracking on after a goto prepoint and immediately off so that slew complete can be detected
2023-12-31 Testing on obejct target crosshairs on prepoint showed and issue with prepoints where the target was displayed instead, fixed (not completely tested due to cloud coming in)
    [CameraModel.py]
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2024-02-15 Starting on miniDisplay
    [AstridCase1.scad]
2024-02-16 Added error reporting to acquisition for dropped shared memory frames due to all the frame buffers being used Fixed bug where errors during recording prevent recording being stopped
    [framewriter.py, otestamper.py]
2024-02-16 Reduced maximum frame rate suggested to 25fps, as 30fps is very close to 100% cpu
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2024-02-22 Fixed ability to manually record and auto record concurrently, also disables fields in Task and Object during manual record
    [CameraModel.py]
2024-02-23 Adding start of miniDisplay
    [miniDisplayCase.scad]
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2024-03-17 Adding mini display case
    [AstridCase1.scad, AstridCase1_Plate1.stl, miniDisplayCase.scad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]
2024-03-17 Removed some redundant code in CameraModel Reduced suggested maximum frame rate to 20fps for now because of Sandisk USB Drive Non Compliance
2024-03-17 Adding logo back to case
    [AstridCase1.scad, AstridCase1_Plate1.stl]
2024-03-20 Added checks and warnings for USB drives that are not UASP and/or USB3 compliant on Astrid Startup and also when using manual recording. Bug fix to diagnostics.sh,
    [astrid.py, settings.py]
2024-03-24 Updating USBDriveRequirements
    [miniDisplayCase.scad]
2024-04-03 Removed printing from astridmonitor in preparation for becoming a daemon. Added adafruit-board-toolkit python module to installer
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2024-04-04 Released version 1.0.025 Amended CameraModel for /dev/tty/ACM* mounts to exclude Mini Display
2024-04-04 Auto Network Switching Removed - Astrid now boots up in Hotspot Mode - Use Mini Display to change to Wifi Mode OR - Login via VNC to Hotspot and click "WiFi Connect"
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2024-04-04 Updating Mini Display to implement Link Quality as a percentage and adding Signal dBm Mini Display top line turns Red if WiFi signal is not adequate WiFi Power Management REALLY disabled WiFi connect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
2024-04-06 Adding binaries and documentation for Adafruit ESP32-S3 Reverse TFT Feather support for the MiniDisplay
2024-04-07 Adding support for Adafruit ESP32-S3 Reverse TFT Feather for the Mini Display
2024-04-10 Preventing > 10fps warning happening in auto record when recording starts
    [CameraModel.py]
2024-04-14 Eeprom is now saved (Fuse EESAVE) across Astrid Upgrades, which speeds up time to record after upgrade if Leap Seconds is stored in eeprom Warning now appears when switching off Full Sky Solve to pre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
2024-04-16 Added check for the usb drive being inserted into the USB3 socket
2024-04-21 Msg that was supposed to be on the last checkin: Changed camera tuning settings to uncalibrated, to result in more linear response and less gain changing (handled by PyOTE)
2024-04-21 Fix a bug, where having internet and then not having internet when an IERS update is rerequired can cause astrid to stop
    [CameraModel.py, astcoord.py]
2024-04-21 Removing noise handling to from tuning camera profile to solve warnings about noise
2024-04-21 Fixed a bug that caused astrid to stop when a configuration with a goto mount was being used, but no mount was connected
    [CameraModel.py]
2024-04-21 Player now uses the focal length for plate solving stored in the video if it's available
2024-04-21 Updating Plate Solve error message
2024-04-21 Photo acquisition now maintains contrast when display options are changed Image flipping is now maintained when display options are changed
    [CameraModel.py, DisplayOps.py, FileHandling.py]
2024-04-21 Fix to the last checkin so that display operations are displayed in video mode (not only during recording)
    [CameraModel.py, DisplayOps.py]
2024-04-21 Fix to last checkin to remove print's which slow down acquisition
    [DisplayOps.py]
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2024-04-22 Fixed a bug where version was displayed as None when not connected to the internet Added the software version number to the ravf metadata
    [astrid.py, ravf_encoder.py, settings.py]
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2024-04-24 Fixed bug where a Prepoint (or platesolve when a target is selected), if the telescope is pointing near the North Celestial Pole, caused Astrid to quit as it was unable to paint the target. This is d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
2024-07-27 Fixed issue with qt5 where negative declinations between 0 and -1 degrees were made positive if manually entered (including via cut and pasted occultation elements) instead of events via OWCloud
    [astcoord.py]
2024-08-01 Updating Troubleshooting doc
    [AstridCase1.scad]
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2024-08-11 Adding OTEStamperCarrier
    [oteStamperCarrier.scad]
2024-08-11 Generating stl's
    [AstridCase1Bottom.stl, AstridCase1CameraPosts.stl, AstridCase1FanCover.stl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]
2024-08-11 Moving stl's around
    [AstridCase1Bottom.stl, AstridCase1CameraPosts.stl, AstridCase1FanCover.stl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]
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2024-09-06 Updating for FDM Printing and adding a 2nd case for Prime Focus
    [AstridCase1.3mf, AstridCase1.stl, AstridCase1Bottom.stl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]
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2024-09-06 Fixed frame rate and exposure duration to "Switch to OTE Video" prompt when Auto Recording
2024-09-08 Fixed bug that was reintroduced by change in 1.0.042, where if the occultation target wasn't goto'd, the RA/DEC of the target were not recorded in the .ravf metadata, preventing the target identifica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
    [CameraModel.py]
2024-09-09 Adding Prime Focus Documentation
    [AstridCase2CameraCollars.3mf]
2024-09-11 Added documentation about ethernet connections.
    [AstridCase2.3mf, AstridCase2Camera.3mf]
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2024-09-19 Mount settings for indi module and usb tty are now constrained to a choice list. Mismatch between indi driver name and settings driver name is now detected and prompted to auto fix
    [IndiDevices.py, settings.py]
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2024-09-29 Adding case2 collars and updating case1 for ASA Black
    [AstridCase1.3mf, AstridCase2Collars.3mf]
2024-11-13 Adding Dobsonian Case
    [DobCamera.scad, DobCameraCover.3mf, DobCameraCover.stl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]
2025-01-20 Unifying case1 and case2 into case2 and reorganizing 3D printed files to make it clearer
    [AstridCase1.3mf, AstridCase1.scad, AstridCase1.stl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]
2025-01-22 Updating 3D printed cases
    [AstridCase2.3mf, AstridCase2.scad, AstridCase2.stl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]
2025-01-22 Releasing 1.0.46
    [cameraPrimeFocus.3mf]
2025-02-04 Updated 3DPrinting files
    [cameraIntegrated.3mf, cameraPrimeFocus.3mf]
2025-02-06 Changed plate solver to output to astrid.log and trapped rare error where it's unable to split to investigate further
2025-02-18 Fixed issue introduced in 1.0.047, where Player failed during platesolving due to logging changes
2025-02-18 Updating configuration document and 3d prints
    [cameraIntegrated.3mf, miniDisplayCaseButtons.3mf]
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2025-02-23 Fixed issue with cancel during Prepoint, not cancelling the Plate Solver as per Ted Blank
    [CameraModel.py]
2025-02-23 Reworked prepoint dialog, now has ability to retry failed solves without cancellation
    [CameraModel.py]
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2025-03-16 Fixed bug introduced in version 1.0.050 which caused focus settings not to be created
    [settings.py]
2025-04-04 Fixed issue when a Mount has an integrated Focuser, an external focuser can't be added. Now, the Focuser Device Name is used as a hint to determine the correct device to use.
    [IndiDevices.py]
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2025-10-02 Fixed error handling on connecting to OWCloud when internet is not available, it now produces an appropriate error
    [owcloud.py]
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2026-04-09 Events with / in the name were causing failed recordings, now fixedZ
    [CameraModel.py]

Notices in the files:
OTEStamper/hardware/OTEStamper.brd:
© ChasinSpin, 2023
